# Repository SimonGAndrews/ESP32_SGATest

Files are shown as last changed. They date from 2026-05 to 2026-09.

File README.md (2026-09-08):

# ESP32 Espruino Hardware Test Harnesses

This repository designs, documents, builds, and exercises Espruino and ESP32-family hardware
test harnesses for Espruino port validation.

It is both a hardware-design repo and a test/debug evidence base. The harnesses
are intended to exercise Espruino's user-facing APIs on real Espruino and ESP32-family
targets, especially where those APIs drive the low-level target-port layer and
its `jshardware` implementation.

The test strategy is to break the harness family into reusable physical test
blocks, then use those blocks as controlled hardware contexts for functional
API validation. So the harness wiring is an enabling condition, while the main
goal is to show that the Espruino MCU port behaves correctly when GPIO, timers,
buses, serial ports, and timing-sensitive protocols are used through realistic
hardware feedback paths.

## Purpose

The practical goal is to build repeatable Espruino and ESP32-family Espruino hardware
harnesses, run target-port validation tests against them, and preserve enough
design/debug context that hardware faults, firmware regressions, and test-runner
behaviour are documented.

The design principles are:

- keep the logical test blocks common across all targets
- adapt those blocks to each board through target-specific pin allocation,
  selectors, and wiring fanout
- build shared functional tests around Espruino API behaviour, not just around
  per-target wiring checks
- record the physical mode and firmware/test evidence well enough that future
  runs are comparable

## Project Progression

The work in this repository has progressed through these stages:

1. Developed the first ESP32-C3-DevKitC-02 hardware harness around the common
   Espruino test blocks.
2. Brought up the C3 harness with IDF4-based Espruino builds and validated the
   initial GPIO, analog, bus, and OneWire test paths.
3. Compared C3 IDF4 and IDF5 behaviour and captured IDF5 regression evidence,
   especially around `digitalPulse`.
4. Investigated C3-specific failures using comparison hardware and reference
   targets, separating harness wiring questions from firmware timing issues.
5. Resolved the major ESP32 OneWire instability as a targeted firmware timing
   issue while preserving the evidence and rationale in `docs/investigations/`.
6. Started the classic ESP32 harness generation, using the Olimex
   ESP32-DevKit-LiPo Rev.D / ESP32-WROOM-32E-style pinout as the practical
   DevKitC-compatible target for `ESP32_V1`.
7. Designed the ESP32 DevKitC V4 / `ESP32_V1` harness and PCB construction
   guide, ready for wirewrap build and bring-up.
8. Completed wirewrap builds for both the ESP32-C3 and classic ESP32 harnesses
   and added board photos under `Hardware/`.
9. Completed scripted wiring checks for the current harness blocks, including
   GPIO, analog/PWM, SPI, I2C, OneWire, DS2413, UART crosslink, and external
   connector paths where fitted.
10. Defined the shared REPL functional-test design, with JavaScript-owned
    target presets, Python-owned runner/parsing, and structured machine-readable
    output.
11. Proved the first shared functional block (`gpio_block1`) end to end across
    both current family targets on IDF4 firmware, using the same logical test
    files unchanged.
12. Started the V2 prototype implementation in `KICAD/V2/`, created curated
    target libraries, and adopted removable target daughter boards as the
    target-specific adaptation boundary.

## Current Targets

### ESP32-C3-DevKitC-02

The ESP32-C3 harness is built and has already been used for bring-up, scripted
wiring checks, and firmware debugging.

Important C3-specific features include:

- native USB Serial/JTAG on `D18` / `D19`
- UART0 on `D20` / `D21` reserved by default for board USB-UART REPL/flashing
- selector-heavy GPIO allocation due to the smaller available pin budget
- UART0/UART1 crosslink provisions that use native USB Serial/JTAG as the
  runner path; the DevKitC-02 onboard CP2102N TX must be isolated before its
  `D20` UART0 RX path can be used as the second crosslink direction

KiCad project:

```text
KICAD/V1/ESP32_C3_v1/
```

### Classic ESP32 DevKitC V4 / ESP32_V1

The classic ESP32 DevKitC V4 harness is now built and has completed its first
scripted wiring-check phase. The practical target is the Olimex
ESP32-DevKit-LiPo Rev.D. Olimex describe this board as pin-to-pin comparable
with the Espressif ESP32-CoreBoard
(`ESP32-DevKitC`), while adding LiPo charging and battery-powered operation.
The selected Rev.D hardware uses the classic ESP32 / ESP32-WROOM-32E-class
module family.

The harness uses a KiCad PCB design as a placement/silkscreen construction
guide rather than as a routed copper PCB.

Important ESP32_V1-specific features include:

- UART0 on `D1` / `D3` reserved for board USB-UART REPL/flashing/control
- UART1/UART2 crosslink for serial testing
- mostly fixed wiring because the classic ESP32 has more available GPIO
- selected sharing for `D35`, `D33`, and `D26`
- DS2413 removable OneWire GPIO breakout support

KiCad project:

```text
KICAD/V1/ESP32_V1/
```

## Common Harness Blocks

The harness family reuses the same logical test blocks wherever possible:

- GPIO loopbacks for `digitalWrite`, `digitalRead`, `pinMode`, `setWatch`, and
  `digitalPulse`
- PWM-to-ADC feedback
- SPI validation through MCP3008, with optional shared-bus flash device
- I2C validation through MCP23008, with feedback and interrupt paths
- OneWire validation through two DS18B20 devices
- OneWire GPIO validation through a DS2413 breakout
- UART/Serial crosslink tests
- reset/boot/automation provisions

Tests and documentation use Espruino `Dxx` pin names, matching GPIO numbers.

## Functional REPL Tests

The authoritative shared functional tests live under `tests/repl/`.

These tests are designed to:

- stay directly usable in the Espruino REPL or Web IDE
- keep target-specific pin and mode maps visible inside the JavaScript file
- emit structured output that a Python runner can parse unchanged
- validate Espruino API behaviour within the physical harness block that makes
  that behaviour observable

The current reference design for this test model is:

- `docs/design/repl-test-suite-design.md`

The first proven shared block is `tests/repl/gpio_block1/`, which currently
covers:

- `pinMode`
- `digitalWrite`
- `digitalRead`
- `setWatch`
- `digitalPulse`
- `shiftOut`

## Repository Map

```text
AGENTS.md                  Codex/new-thread operating notes
docs/                      Wiring specs, handoffs, investigation notes
tools/                     Python/REPL test utilities and wiring-test runners
KICAD/                     V1 and V2 schematic/PCB projects and local libraries
Hardware/                  Hardware reference material
tests/repl/                Portable community-facing REPL test scripts
```

Key starting documents:

- `AGENTS.md`
- `docs/handoff/2026-09-04-idf5-classic-validation-status.md` for the
  post-IDF5-merge ESP32 master sanity run and its historical evidence
- `docs/handoff/2026-06-25-esp32-family-tests.md`
- `docs/design/common-harness-design-and-blocks.md`
- `docs/design/repl-test-suite-design.md`
- `docs/design/harness-modes.md`
- `docs/targets/esp32-c3-devkitc-02/wiring.md`
- `docs/targets/esp32-devkitc-v4/wiring.md`

Useful external references:

- Olimex ESP32-DevKit-LiPo open-source hardware page:
  <https://www.olimex.com/Products/IoT/ESP32/ESP32-DevKit-LiPo/open-source-hardware>

## Test And Debug Context

The repo preserves the history and reasoning from real Espruino ESP32 testing,
including:

- REPL bring-up process
- C3 harness block tests
- OneWire investigation and final timing-fix shape
- IDF4 vs IDF5 comparisons
- `digitalPulse` regression evidence
- watch/debounce investigation notes
- scripted REPL test tools

Important conclusions from prior work:

- ESP32 OneWire instability was narrowed to firmware-side timing behaviour, not
  simply bad harness wiring.
- The accepted OneWire fix shape is a localized ESP32 timing guard inside
  `src/jswrap_onewire.c`, not a broad/global interrupt semantic change.
- `digitalPulse` was a separate ESP32-C3 IDF5 regression signal after basic
  `digitalWrite`, `digitalRead`, and `setWatch` paths had been shown to work.
- Selector/jumper state is part of every test precondition and must be recorded
  with test evidence.

## Current Active Work

The current hardware state is that both harness boards are built and their
initial scripted wiring-check coverage is in place.

The shared functional suite now covers GPIO, watches and pulses, analogue and
PWM paths, I2C, SPI, OneWire, UART and paired Wi-Fi/BLE behaviour where the V1
harness and peer hardware support them. It has been used for repeatable classic
ESP32 master-versus-IDF5 comparisons and for targeted ESP32-C3 evidence. The
older IDF4 results remain useful comparators rather than the current endpoint.

The expedited ESP32 IDF5 validation supplied build and V1 regression evidence
that informed Gordon Williams' decision to merge the official `IDF5` branch
into Espruino `master` at `5d79af218`. The same-source post-merge sanity check
of `BOARD=ESP32` and `BOARD=ESP32_IDF5` is complete. Further defects have
returned to normal Espruino-master investigation; the first follow-up was UART
driver-lifecycle pull request `#2742`, merged as `e6a3fe089`. Its family-wide
revision has compile coverage across seven ESP32 board definitions and runtime
coverage on classic ESP32, ESP32-C3 and ESP32-S3 hardware. See
`docs/handoff/2026-09-04-idf5-classic-validation-status.md`.

This work continues block-by-block expansion of the shared functional suite,
with the aim of:

- exercising Espruino APIs more fully across the common harness blocks
- preserving the existing per-target wiring checks as hardware-regression
  references
- retaining useful legacy and IDF4 comparators for anomaly attribution
- applying the same shared functional coverage to both ESP32 board targets in
  current master
- keeping new tests portable to the future V2 target-map layer

V2 architecture and KiCad implementation remain active and can continue in
parallel with normal master regression work. The current V2 return point is
commit `c70e50c`, which established the Rev-A daughter-board foundations. See
`docs/design/V2Harness/README.md` for the V2 entry point.

Routine V1 hardware development and prototyping have stopped. The completed V1
harnesses remain the stable bench platforms for runner development, regression
testing and firmware evidence.

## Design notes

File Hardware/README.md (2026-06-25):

# Hardware Reference Outputs

This directory holds published hardware reference outputs that are useful
outside KiCad itself, such as exported schematic PDFs.

Live KiCad project files remain under `KICAD/`.

## ESP32-C3 Harness

```text
ESP32_C3/schematic-v1-0.pdf
ESP32_C3/schematic-v1-1.pdf
```

`schematic-v1-1.pdf` is the current ESP32-C3 harness schematic reference.

## ESP32_V1 / Classic ESP32 Harness

```text
ESP32_V1/schematic-v1-0.pdf
```

This is the current ESP32 DevKitC V4 / Olimex ESP32-DevKit-LiPo Rev.D harness
schematic reference.

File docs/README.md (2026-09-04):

# Documentation Map

Documentation is grouped by information type.

## `design/`

Generic ESP32-family harness design and operating principles:

- common hardware blocks
- harness modes
- connectivity permutations
- reference links

Historical design-decision notes that are no longer active guidance live under
`design/history/`.

## `targets/`

Target-specific wiring and bring-up notes. These documents describe how the
generic harness blocks are mapped onto a particular board.

Start with `targets/README.md` for the target index.

Current targets:

- `esp32-c3-devkitc-02/`
- `esp32-devkitc-v4/`
- `olimex-esp32-devkit-lipo/`

## `investigations/`

Issue analysis, debugging history, and resolution notes. These are evidence and
reasoning records, not primary wiring specs.

Current investigation areas:

- `IDF5_port_testing/`
- `ble/`
- `onewire/`
- `digitalpulse/`
- `i2c/`
- `wifi/`
- `uart/`
- `watch-debounce/`
- `jsinteractive/`

Investigation-specific raw evidence should live under the relevant
investigation, for example:

```text
investigations/onewire/artifacts/logic-traces/
```

## `handoff/`

Codex/thread continuity notes. These are intended to preserve working context
between sessions and should point to the current design and target docs.

Start with `handoff/README.md`. It distinguishes current workstream handovers
from historical continuity records.

## Current Workstream Entry Points

| Workstream | Entry point |
|---|---|
| ESP32 post-IDF5-merge sanity | `handoff/2026-09-04-idf5-classic-validation-status.md` |
| General V1 bench tests and functional runners | `handoff/2026-06-25-esp32-family-tests.md` |
| Firmware investigations | `handoff/2026-07-05-espruino-repo-structure.md`, `handoff/2026-07-20-esp32-firmware-lineage-and-test-interpretation.md` and the relevant `investigations/` area |
| V2 architecture and Target Interface | `design/V2Harness/README.md` and `handoff/2026-07-17-v2-services-and-routing.md` |
| V2 KiCad implementation | `design/V2Harness/README.md` and `../KICAD/V2/Exploration/Espruino_Harness_V2/TARGET_LIBRARY_PROVENANCE.md` |

Repository-relative paths are canonical because the repository is used on both
Windows and Ubuntu.

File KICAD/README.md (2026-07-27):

# KiCad Projects

All KiCad projects and component-development work live under this directory.
Libraries remain local to the project that uses them and use `${KIPRJMOD}` in
KiCad library tables.

## Directory map

```text
KICAD/
|-- V1/
|   |-- ESP32_C3_v1/       Completed ESP32-C3 V1 harness
|   `-- ESP32_V1/          Completed classic ESP32 V1 harness
`-- V2/
    |-- Exploration/
    |   `-- Espruino_Harness_V2/
    |-- ComponentDevelopment/
    |   `-- EspruinoPicoDirectMount/
    |-- RevA/
    `-- upstream/
```

`V2/Exploration/Espruino_Harness_V2/` preserves the earlier exploratory
schematic hierarchy, PCB placement work and curated target libraries. It is a
reference input to Rev A, not the Rev-A starting project.

`V2/ComponentDevelopment/EspruinoPicoDirectMount/` contains the useful
Espruino Pico direct-solder footprint and board-aperture development work. A
reviewed copy of the required footprint will be placed in the future Pico
daughter-board project's local library.

`V2/RevA/Espruino_Harness_RevA/` is the intended location for the fresh Rev-A
project. Create that project through KiCad rather than by copying the
exploratory schematic or PCB.

`V2/upstream/` contains local upstream source checkouts used for provenance and
comparison. It is ignored by Git and is not a production library.

KiCad local-state files, automatic backups, caches and lock files are ignored
by the repository-level `.gitignore`.

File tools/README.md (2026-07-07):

# Tooling Map

This directory contains automation and diagnostic utilities used to run
Espruino REPL tests, capture evidence, and support investigations.

The long-term direction is to keep reusable test logic separate from
target-specific pin/mode configuration.

## `common/`

Reusable tools that are not tied to one harness target.

Current examples:

- OneWire search/debug diagnostics
- generic OneWire soak testing
- DS18B20 read soak testing
- `archive_firmware.py` for extracting flashable build bundles into
  `firmware/` for repeatable reflashing

## `repl/`

Shared functional REPL runners for tests under `tests/repl/`.

Current direction:

- Python owns metadata capture, parsing, and overall result handling
- transport may be direct serial or an optional EspruinoTools CLI backend
- shared tests remain authoritative in JavaScript under `tests/repl/`

## `wiring_tests/`

Target-specific wiring-test runners. These encode a particular harness pin
allocation, selector state, or bring-up sequence.

Current targets:

- `esp32_c3/` - scripts originally developed for the ESP32-C3-DevKitC-02
  harness
- `esp32_v1/` - first-pass scripts for the classic ESP32 DevKitC V4 harness

Future ESP32-family work should prefer a shared runner plus target maps, rather
than copying whole scripts for each board.

## `experiments/`

One-off or comparison tools used during investigations. These are useful
evidence generators, but they are not necessarily part of the accepted harness
test suite.

Current experiment areas:

- `pico/` - Pico comparison scripts used during watch/debounce and pulse
  investigation work

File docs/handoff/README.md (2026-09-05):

# Handover Index

Handover documents preserve continuity between focused Codex threads. They do
not replace current design specifications, target wiring documents or recorded
test evidence.

## Thread Declaration

Begin substantial work by declaring the thread's workstream and immediate
objective:

```text
Workstream: <one of the four workstreams in AGENTS.md>
Current objective: <concrete outcome for this thread>
```

Examples:

```text
Workstream: V1 bench testing and functional runners
Current objective: add shared SPI functional coverage on both V1 targets

Workstream: Firmware investigations
Current objective: reproduce the ESP32-C3 IDF5 digitalPulse regression

Workstream: V2 architecture and Target Interface contract
Current objective: define the logical resource inventory and safety invariants

Workstream: V2 KiCad implementation
Current objective: implement an accepted Target Interface bank assignment
```

Keep one primary workstream per thread where practical. When work crosses a
boundary, state what is being consumed from or handed to the parallel
workstream. Record accepted cross-workstream decisions in repository
specifications rather than relying on conversation history.

## Current Workstream Handovers

| Workstream | Current handover | Use |
|---|---|---|
| ESP32 post-IDF5-merge sanity | `2026-09-04-idf5-classic-validation-status.md` | Completed same-source legacy/IDF5 sanity comparison and return point for outstanding defects as normal master investigations |
| General V1 bench testing and functional runners | `2026-06-25-esp32-family-tests.md` | Generic family-test model and preserved target constraints; its July 12 overlay points to the root README and `tests/repl/` for newer progress |
| Firmware repository selection | `2026-07-05-espruino-repo-structure.md` | Select the correct local Espruino checkout and workflow |
| ESP32 firmware lineage and evidence interpretation | `2026-07-20-esp32-firmware-lineage-and-test-interpretation.md` | Cross-build confidence, comparison matrix and anomaly-attribution rules for bench and firmware threads |
| V2 architecture and Rev-A implementation | `2026-07-17-v2-services-and-routing.md` | Accepted architecture and Target Interface, first-pass Rev-A hierarchy, verified power baseline and next RC01/RC02 reviews |

V2 KiCad implementation currently uses the V2 entry point and Rev-A design
baseline under `../design/V2Harness/`, together with the relevant architecture
specification for the circuit under review. It does not need a separate
handover while current progress, evidence and open PCB actions are captured in
those documents and Git history. Read
`../../KICAD/V2/Exploration/Espruino_Harness_V2/TARGET_LIBRARY_PROVENANCE.md`
only when modifying target symbols or footprints.

## Focused Historical Handovers

- `2026-06-16-onewire-idf4-idf5.md` is required for OneWire and closely
  related ESP32 timing investigations, not for every thread.
- `2026-06-10.md` is an earlier broad continuity record.
- `2026-07-01-espruino-repo-structure.md` is the detailed predecessor to the
  simplified July 5 repository guide.
- `2026-07-01-esp32-harness-progress-discussion-draft.md` is a discussion
  draft, not current authority.
- `2026-07-12-v2-target-interface-contract.md` records the starting context for
  the V2 architecture thread and is superseded by the July 17 V2 handover.

## Authority and Maintenance

When documents differ:

1. Current specifications and target wiring documents are authoritative.
2. Accepted architecture and interface contracts govern V2.
3. Current handovers describe workstream continuity and open work.
4. Older handovers and investigations preserve historical evidence.

Create a new handover when a focused thread cannot be restarted reliably from
the current specifications and existing workstream handover. A good handover
states scope, settled decisions, open questions, authoritative inputs,
parallel-workstream boundaries and the recommended next task.

Use repository-relative links and paths. This repository is used on both
Windows and Ubuntu.

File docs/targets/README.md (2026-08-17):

# Target Documentation

Target documentation describes how the common ESP32-family harness blocks are
mapped onto specific boards.

The generic design rules live in `../design/`; target directories should focus
on pin allocation, selector state, bring-up notes, and target-specific
constraints.

## Current Targets

The C3 and classic ESP32 directories describe completed V1 harness targets and
their wiring. The Olimex directory is retained as earlier target-specific
reference history.

### `esp32-c3-devkitc-02/`

ESP32-C3-DevKitC-02 harness documentation.

Status:

- first built harness
- used for IDF4/IDF5 bring-up and regression investigation
- selector-heavy design because of the C3 pin budget

Key files:

- `wiring.md`
- `bringup.md`
- `../../Hardware/ESP32_C3/schematic-v1-1.pdf`

### `esp32-devkitc-v4/`

Classic ESP32 DevKitC V4 / `ESP32_V1` harness documentation.

Status:

- completed wirewrap harness; now used as a stable bench platform
- practical target board is the Olimex ESP32-DevKit-LiPo Rev.D, described by
  Olimex as pin-to-pin comparable with Espressif ESP32-CoreBoard /
  `ESP32-DevKitC`
- KiCad project lives in `../../KICAD/V1/ESP32_V1/`

Key files:

- `wiring.md`
- `../../Hardware/ESP32_V1/schematic-v1-0.pdf`

### `olimex-esp32-devkit-lipo/`

Earlier target-specific notes for the Olimex ESP32-DevKit-LiPo Rev.D.

Status:

- retained as target reference/design history
- current classic ESP32 harness work is consolidated under
  `esp32-devkitc-v4/`

Key files:

- `wiring.md`

### `olimex-esp32-s3-devkit-lipo/`

Olimex ESP32-S3-DevKit-LiPo target documentation.

Status:

- owned V2 target is the `-EA` external-antenna ordering variant, hardware
  revision B and N8R8 configuration
- allocated to `DB-ESP32-FAMILY`
- authoritative target CAD exists; the GPIO-to-Target-Interface mapping is
  accepted in `../design/V2Harness/arch/TargetRoutingEnvelope_V2.md`
- retained manufacturer files currently remain in the older mixed Olimex
  resource directory pending the planned target-asset rationalisation

Key file:

- `README.md`

## V2 Target-Library Reference Sets

- `ESP32-S3-DevKitC-1_V1.1/`
- `Raspberry-Pi-Pico-Family/`
- `espruino_pico/`
- `MDBT42Q_breakout/`
- `olimex-esp32-s3-devkit-lipo/`

These directories provide manufacturer drawings, pinouts and, where present,
target-library notes used to validate the curated symbols and footprints in
`../../KICAD/V2/Exploration/Espruino_Harness_V2/V2_Targets.*`.

Target-specific daughter-board mappings will be added after the V2 Target
Interface contract is stable. Curated KiCad assets and upstream revisions are
described in
`../../KICAD/V2/Exploration/Espruino_Harness_V2/TARGET_LIBRARY_PROVENANCE.md`.

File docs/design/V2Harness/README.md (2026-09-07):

# Espruino Test Harness V2

**Status:** Active architecture and prototype implementation

## Purpose

V2 develops a reusable hardware architecture for Espruino target validation.
It builds on the completed ESP32-family V1 harnesses while separating reusable
test circuitry from target-specific physical adaptation.

V1 remains the stable bench platform for shared functional-test and runner
development. V2 architecture and KiCad implementation proceed in parallel and
consume lessons proved on V1.

## Current Direction

The agreed prototype direction is:

- a reusable manufactured harness PCB containing standard test blocks,
  routing, control and fixed Target Interface pin banks
- removable target daughter boards containing the target socket and
  target-specific mapping to that interface
- a common daughter-board USB data path and manual VBUS selector, plus a reusable-harness
  Standalone regulator, so full harness capability never depends on target
  3.3 V output capacity
- two coordinated two-position power selectors, changed only while unpowered;
  no host-VBUS or selector-control conductor crosses the Target Interface
- wirewrapped prototype daughter boards first, with manufactured passive
  adapter PCBs possible after mappings are stable

```text
Target module
     │ target-specific socket and wirewrap
     ▼
Target daughter board
     │ fixed Target Interface contract
     ▼
Reusable V2 harness PCB
     ├── Standard Test Blocks
     ├── Standard Control Services
     └── direct and routed connections
```

The conceptual model, Standard Test Blocks, Target Routing Envelope and
Standard Control Services are accepted. The accepted combined capability
connection matrix turns those requirements into a concrete path inventory,
simultaneous-use model and provisional Target Interface contact count. The
controlled-routing specification is also accepted against that matrix. The
accepted Target Interface uses two 24-pin connectors, each with two rows of
12 pins. Its complete 48-pin Connector A and Connector B pinout is fixed,
including the corrected B01 `TI_TARGET_VBUS` return and low-current-only A01
`TI_TARGET_3V3` reference.
Exact connector parts, plating and KiCad footprints still need to be selected
and mechanically checked before the Rev-A harness is released. The current
KiCad project is a prototype implementation and must not be mistaken for a
frozen production design.

The ESP32-C3-DevKitC-02 now has a specific Block 7 qualification. V1 bench
evidence proves that the daughter-board-style D18/D19 native USB connection
can provide an independent `/dev/ttyACM` runner, but it also proves that this
does not release D20 from the onboard CP2102N TX output. The unmodified target
therefore uses Block 7's endpoint-A external-peer form; the full two-UART
crosslink is enabled only for an explicitly isolated or separately proved
target mapping. Rev-A action `PCB-DB-C3-01` carries this into the
`DB-ESP32-FAMILY` implementation.

## Active V2 Workstreams

### Architecture and Target Interface

Defines:

- logical resource inventory
- direct, routed, optional and reserved signals
- connector-bank semantics and electrical safety
- daughter-board responsibilities
- cross-target compatibility rules
- Standard Test Blocks and Control Services
- combined direct, routed, simultaneous-use and recovery requirements

Start with:

- `arch/TestHarnessArchitecture_V2.md`
- `arch/HarnessConceptualModel_V2.md`
- `arch/HybridHarnessArchitecture_V2.md`
- `arch/DaughterBoardMatrix_V2.md`
- `arch/StandardTestBlocks_V2.md`
- `arch/StandardControlServices_V2.md`
- `arch/TargetRoutingEnvelope_V2.md`
- `arch/CombinedCapabilityConnectionMatrix_V2.md`
- `arch/TargetInterfaceContract_V2.md`
- `arch/ReusableHarnessPrototypeStrategy_V2.md`
- `../../handoff/2026-07-17-v2-services-and-routing.md`

### KiCad implementation

The accepted architecture will be implemented in a fresh Rev-A project under:

- `../../../KICAD/V2/RevA/Espruino_Harness_RevA/`

The earlier exploratory project is preserved under
`../../../KICAD/V2/Exploration/Espruino_Harness_V2/`. It contains:

- an exploratory hierarchical schematic
- project-local `V2_Harness` component libraries
- project-local `V2_Targets` symbol and footprint libraries
- reviewed target assets for the main ESP32, ESP32-S3, Pico and Espruino
  target set

Read `../../../KICAD/V2/Exploration/Espruino_Harness_V2/TARGET_LIBRARY_PROVENANCE.md`
before modifying target assets. Several footprints contain authoritative
interactive edits.

### Rev-A implementation baseline

The draft manufacturing baseline, circuit-block review records and visual
review images live under:

- `implementation/ReusableHarnessRevA_DesignBaseline.md`
- `implementation/ReusableHarnessRevA_ConnectivityChecker.md`
- `implementation/ReusableHarnessRevA_PCBImplementationAndVerification.md`
- `implementation/review-images/`

The design baseline requires the deterministic connectivity check and decides
whether its evidence is accepted for Rev-A release. The connectivity-checker
specification defines the tool that performs that check.

`PC01` Operating mode and 3.3 V rails, `PC02` Target 5 V switch and two-range
monitor, `RC01` Routing Fabric, `RC02` routing controllers and fixed I2C
isolation, and `TB01` digital GPIO loopback are verified at schematic-baseline
level. Their PCB, physical-test and AISLER actions remain in the implementation
register. The next planned baseline-review area is `TB02` analogue/PWM
feedback on `standard_test_blocks.kicad_sch`.

PCB-layout work starts with the **PCB implementation action register** in
Section 6 of the design baseline. It is the single handover list for physical
layout, mechanical, DFM and release actions accumulated by the block reviews.

Generated KiCad evidence and the machine-readable connectivity contract live
under `../../../KICAD/V2/RevA/Espruino_Harness_RevA/verification/`.

## Document Roles

- `arch/TestHarnessArchitecture_V2.md` defines the overall architecture and
  should change only for genuine architectural decisions.
- `arch/HarnessConceptualModel_V2.md` owns the shared capability vocabulary and
  relationships.
- `arch/StandardTestBlocks_V2.md` owns reusable Test Block behaviour and
  electrical requirements.
- `arch/TargetRoutingEnvelope_V2.md` owns the accepted seven-entry Test Block
  routing minimum, legal common route functions, direct-path alternatives and
  cross-target routing constraints.
- `arch/StandardControlServices_V2.md` owns reusable power, target-control,
  routing, reset and boot, Supervisor, event-handshake and rack-service
  behaviour.
- `arch/WiFi_V1SupervisorPeerEvidence.md` assesses the completed V1 Wi-Fi
  Supervisor Peer evidence and open gaps; it is an evidence input, not a
  second Control Service specification.
- `arch/CombinedCapabilityConnectionMatrix_V2.md` is the accepted integration
  of Test Block and Control Service requirements for routing and Target
  Interface design without duplicating their behavioural specifications.
- `arch/I2CControlledRouting_V2.md` is the accepted controlled-routing
  specification.
- `arch/TargetInterfaceContract_V2.md` owns the physical Target Interface
  electrical and connector contract. Its complete two-connector 48-pin pinout
  is accepted; exact connector parts, plating, footprints and mechanical
  verification remain in progress.
- `arch/HybridHarnessArchitecture_V2.md` defines the prototype boundary and
  records the removable daughter-board decision in Appendix A.
- `arch/DaughterBoardMatrix_V2.md` owns the three-board target allocation,
  exact-variant matrix, mounting and shared-footprint compatibility decisions,
  and the complex-board-first implementation gates.
- `arch/ReusableHarnessPrototypeStrategy_V2.md` defines the Rev-A manufactured
  harness, wire-wrap daughter-board and pre-manufacture validation approach.
- `implementation/ReusableHarnessRevA_DesignBaseline.md` records the selected
  Rev-A implementation and the evidence required before manufacturing release.
- `implementation/ReusableHarnessRevA_ConnectivityChecker.md` specifies the
  deterministic checker used by that baseline to verify the complete root
  KiCad netlist against the independently reviewed connectivity contracts.
- `implementation/ReusableHarnessRevA_PCBImplementationAndVerification.md`
  will guide and record board placement, routing and PCB verification without
  duplicating the authoritative KiCad PCB database or the baseline action
  register.
- `targets/esp32-c3-devkitc-02/gpio-allocation-and-routing-design.md` is a
  provisional target study, not an implemented wiring specification.
- `../../handoff/2026-07-17-v2-services-and-routing.md` transfers the accepted
  architecture and Control Services into the routing-design thread.

## Relationship to V1

Routine V1 hardware construction and prototyping have stopped. The completed
ESP32-C3 and classic ESP32 harnesses are used for:

- shared REPL functional-test development
- runner and result-format development
- regression testing and firmware comparison
- bench evidence for assumptions that may inform V2

V2 does not replace this active bench role. It generalises the proven ideas
into a reusable future harness.

## Guiding Principles

- Evolution rather than replacement.
- Simplicity before unnecessary automation.
- Stable logical interfaces and explicit physical boundaries.
- Separation of reusable harness functions from target-specific adaptation.
- Hardware proof before firmware conclusions.
- Prototype and measure before committing to manufactured adapters.
- Preserve replaceability, inspectability and independent fault diagnosis.

## Repository Layout

```text
docs/design/V2Harness/
├── README.md
├── arch/             Current architecture specifications
└── targets/          Provisional target allocation studies

KICAD/
├── V1/               Completed V1 harness projects
└── V2/
    ├── Exploration/  Preserved exploratory V2 work
    ├── ComponentDevelopment/
    │   └── EspruinoPicoDirectMount/
    ├── RevA/         Fresh Rev-A implementation
    └── upstream/     Ignored upstream reference checkouts
```

Repository-relative paths are canonical on both Windows and Ubuntu.

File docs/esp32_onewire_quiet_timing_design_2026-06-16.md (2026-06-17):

# ESP32 OneWire Quiet Timing Design Note

Date: 2026-06-16

This note records the design reasoning behind the ESP32-family OneWire timing
fix used during the ESP32-C3 harness investigation.

The immediate practical problem was:

- `OneWire.search()` on ESP32-C3 was intermittent
- the same DS18B20 daughterboard and sensors were stable on an Espruino Pico
- the failure pattern suggested timing corruption during the ROM-search
  transaction

The selected fix was to add a short-duration ESP32-specific critical section
for OneWire timing windows, rather than globally changing Espruino interrupt
semantics on ESP32.

Update 2026-06-17:

- the first working proof used ESP32 target helpers
  `jshQuietTimingEnter()` / `jshQuietTimingExit()`
- after review, that was refactored into a smaller final form that keeps the
  ESP32 override local to `src/jswrap_onewire.c`
- the final implementation uses a local `portMUX_TYPE` and
  `portENTER_CRITICAL()` / `portEXIT_CRITICAL()`
- that refactored form now builds in both the IDF4 and IDF5 Espruino trees
- on the bench ESP32-C3, the IDF4 build passed:
  - `OneWire.searchDebug()` soak `20/20`
  - `OneWire.searchDebug()` soak `50/50`
  - DS18B20 conversion/read soak `20/20`
- on the bench ESP32-C3, the IDF5 build passed:
  - `OneWire.searchDebug()` soak `20/20`
  - `OneWire.searchDebug()` soak `50/50`
  - DS18B20 conversion/read soak `20/20`
- the original harness-mounted OneWire path was then restored and also passed
  on IDF5 using `SEL_D0 -> ONEWIRE_DQ`
- the latest rerun on that original harness path again found both harness ROMs
  on every pass:
  - `2808c68700aa7672`
  - `28b3e08700b65ea9`

## Problem Summary

On the ESP32 target, existing `OneWire` code relied on:

- `jshInterruptOff()`
- `jshInterruptOn()`

to protect timing-sensitive windows such as:

- reset / presence detect
- read slots
- write slots

However, on ESP32 those functions were effectively stubbed, so the code still
looked like it was protecting timing but in practice was not.

That mismatch matters because OneWire bit-banging is sensitive to short timing
disturbances and to delayed sampling.

## Why Not Re-enable Global Interrupt Off/On?

We explicitly did not choose to "just implement" `jshInterruptOff()` /
`jshInterruptOn()` globally for ESP32.

Reasons:

1. Historical evidence in Espruino indicated that raw interrupt off/on on
   ESP32 had previously caused crashes.
2. `jshInterruptOff()` / `jshInterruptOn()` have multiple call sites outside
   OneWire, so changing them globally would widen the risk far beyond this
   specific timing problem.
3. On ESP32-family targets, especially SMP-capable ones such as ESP32 and
   ESP32-S3, a naïve single-core mental model of interrupt disabling is not a
   good match for the platform's concurrency model.

So the design target was:

- preserve existing stubbed global behavior
- introduce a new narrowly-scoped primitive for short timing-critical sections
- use it only where OneWire genuinely needs it

## Chosen Approach

The final implemented approach is:

1. In `src/jswrap_onewire.c`, under `#ifdef ESP32`, define a local
   `portMUX_TYPE` spinlock.
2. In that same file, locally override:
   - `jshInterruptOff()` to `portENTER_CRITICAL(&JSQuietTimingMux)`
   - `jshInterruptOn()` to `portEXIT_CRITICAL(&JSQuietTimingMux)`
3. Apply those timing guards around:
   - `OneWireReset()`
   - OneWire read slots
   - OneWire write slots
4. Leave all non-ESP32 targets unchanged.
5. Keep the ESP32-specific behavior local to the OneWire implementation rather
   than introducing new cross-target `jshardware` API surface.

This keeps the blast radius small while aligning with the upstream preference
to avoid adding new target hooks unless they are broadly justified.

## Why This Matches ESP-IDF Guidance

ESP-IDF's own FreeRTOS documentation describes ESP critical sections in terms
of:

- a `portMUX_TYPE` spinlock
- `taskENTER_CRITICAL(&spinlock)`
- `taskEXIT_CRITICAL(&spinlock)`

Reference:

- https://docs.espressif.com/projects/esp-idf/en/stable/esp32/api-reference/system/freertos_idf.html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

Important points from the ESP-IDF guidance:

- the core disables interrupts or interrupt nesting up to the syscall priority
- the core then acquires the spinlock atomically
- the protected region then runs under that critical section

That model is a better fit for ESP32-family targets than pretending a generic
global interrupt-off primitive is sufficient everywhere.

In plain terms:

- ESP-IDF expects short protected regions to be expressed as critical sections
  using a mux/spinlock
- the final local `jswrap_onewire.c` override follows that pattern directly

The first proof version used `taskENTER_CRITICAL()` / `taskEXIT_CRITICAL()`.
The final refactor uses `portENTER_CRITICAL()` / `portEXIT_CRITICAL()` instead,
because that compiled cleanly across both the IDF4 and IDF5 trees used here.

## Why This Matches MicroPython's ESP32 Approach

MicroPython's ESP32 port uses its own target-specific atomic section mechanism
instead of relying on a generic platform-agnostic global interrupt-disable
assumption.

Relevant references:

- https://github.com/micropython/micropython/blob/master/ports/esp32/mphalport.h
- https://github.com/micropython/micropython/blob/master/ports/esp32/mphalport.c

Key observations from the MicroPython ESP32 port:

- it defines a `portMUX_TYPE` atomic mux
- `mp_begin_atomic_section()` uses `portENTER_CRITICAL(&mp_atomic_mux)`
- `mp_end_atomic_section()` uses `portEXIT_CRITICAL(&mp_atomic_mux)`
- the comments note this protects against concurrent access on SMP systems as
  well as disabling interrupts on the calling CPU
- MicroPython also maps its quiet-timing/atomic helpers onto that mechanism

This is not identical code to Espruino, but it is architecturally the same
kind of solution:

- an ESP32-specific short critical section
- not a blind restoration of raw global interrupt-off behavior

## Why Only OneWire Was Changed

This design note is intentionally narrow.

It does not claim:

- every ESP32 timing-sensitive subsystem in Espruino should immediately use the
  same primitive
- every call site of `jshInterruptOff()` must be rewritten now

It only claims:

- OneWire needed protection for specific very short timing windows
- a narrow ESP32-specific critical-section override is a defensible and
  low-risk way to provide it on ESP32

That narrower scope made it easier to:

- prove the fix with bench evidence
- avoid broad regressions
- preserve future freedom to redesign wider ESP32 interrupt/timing policy if
  needed

## Residual Risk And Expected Side Effects

The fix is intentionally narrow, but it is not free.

What changes on ESP32 is not the whole system interrupt model. What changes is
that `OneWire` now introduces short critical sections during its timing
windows in `src/jswrap_onewire.c`.

Important boundaries:

- the override is file-local to `src/jswrap_onewire.c`
- it does not change other `jshInterruptOff()` / `jshInterruptOn()` call sites
- it does not globally alter ESP32 interrupt handling when `OneWire` is idle

The real residual risk is therefore not "everything on ESP32 now runs with
interrupts changed". The real residual risk is:

- interrupt latency increases in short bursts while `OneWire` activity is in
  progress
- repeated `OneWire.search()` or DS18B20 conversions/reads can create many
  such bursts in succession
- other interrupt-driven subsystems may therefore see added jitter or delayed
  service during active `OneWire` traffic

The most likely areas to watch are:

- Wi-Fi background work during repeated `OneWire` transactions
- Bluetooth/BLE controller or host timing during repeated `OneWire`
  transactions
- UART RX at higher baud rates while `OneWire` traffic is active
- software timing features such as `setWatch`, timers, or pulse generation
- any application that relies on tight interrupt response while `OneWire` is
  running

The key engineering judgement is that this residual risk is much smaller than
the risk of globally re-enabling `jshInterruptOff()` / `jshInterruptOn()` on
ESP32.

## Coexistence Tests Still Required

Acceptance of the fix should include coexistence testing, not just isolated
OneWire success.

The future ESP32-family test plan should include cases where `OneWire` runs in
parallel with other interrupt-driven features so that the critical-section
tradeoff is exercised directly.

Recommended minimum coexistence cases:

1. OneWire plus Wi-Fi activity
   - keep Wi-Fi associated
   - generate steady network traffic while repeated `OneWire.search()` and
     DS18B20 reads are running
   - watch for disconnects, stalls, missed reads, or console instability
2. OneWire plus Bluetooth/BLE activity
   - keep BLE advertising, scanning, or a simple active connection running
   - in parallel, run repeated `OneWire.search()` and DS18B20 reads
   - watch for dropped BLE activity, timing instability, or OneWire failures
3. OneWire plus UART RX stress
   - stream data into the board over the active UART path while repeated
     `OneWire` reads/searches run
   - check for framing loss, dropped characters, or REPL corruption
4. OneWire plus GPIO/watch/timer activity
   - keep a watch-based edge counter or timer-based activity running while
     repeated `OneWire` operations execute
   - watch for lost edges, stretched timing, or unexpected callback latency
5. OneWire plus other bus activity
   - run SPI or I2C polling in parallel with repeated `OneWire` operations
   - watch for transaction failures or clear timing degradation

These should be treated as suite-level coexistence/regression tests for:

- ESP32-C3
- original ESP32
- later, ESP32-S3 if it becomes an active target

For the original ESP32 specifically, this matters even more because Wi-Fi and
Bluetooth are both in scope on that family target.

## Evidence That The Design Worked

Using the clean external daughterboard with:

- two DS18B20 sensors
- one `4.7k` pull-up

the observed progression on the ESP32-C3 was:

1. Before the fix:
   - mixed two-device, one-device, and zero-device search results
   - variable abort bit positions in `searchDebug()`
2. After protecting read/write slots:
   - a dramatic improvement
   - one remaining rare `resetOk=false` failure in a 50-run soak
3. After also protecting the reset/presence window:
   - `50/50` successful runs
   - both sensors found every time

So the design is supported by bench evidence, not just by architectural taste.

That evidence now exists in both of the firmware trees used in this project,
not only in the original IDF4 proof tree.

It also now exists on both physical OneWire setups used during the
investigation:

- the clean external daughterboard used to isolate firmware behavior
- the original harness-mounted OneWire path used in the earlier unreliable
  tests

## Intended Portability Across ESP32 Family

The design is intended to scale across ESP32-family targets, including:

- original ESP32
- ESP32-C3
- ESP32-S3

Why this should port cleanly:

- the implementation is small and ESP32-guarded
- the primitive is based on ESP-IDF / FreeRTOS critical sections rather than
  C3-specific register tricks
- the same final shape now builds and passes bench soaks in both the IDF4 and
  IDF5 Espruino trees used here

That does not prove every ESP32-family target will behave identically, but it
does mean the chosen mechanism is family-appropriate rather than board-specific.

## Files Associated With This Design

The final refactored design is embodied in:

- `src/jswrap_onewire.c`
- `src/jswrap_onewire.h`

plus the local board console adjustments needed on the bench target:

- `boards/ESP32C3_IDF4.py`
- `boards/ESP32C3_IDF5.py`

The initial proof version also touched `src/jshardware.h` and
`targets/esp32/jshardware.c`, but those changes were later removed during the
refactor to the final local OneWire override.

## Practical Guidance For Future Review

If this change is later reviewed or upstreamed, the strongest technical framing
is:

- this is not a generic "re-enable interrupts off/on on ESP32" patch
- this is a targeted ESP32 critical-section override for a timing-critical
  bit-banged protocol
- the implementation follows ESP-IDF's critical-section model
- the approach is consistent with the kind of ESP32 atomic-section handling
  used by MicroPython
- the fix is justified by measured before/after bench evidence

## Related Notes

- [codex_handoff_2026-06-16_onewire_idf4_idf5.md](./codex_handoff_2026-06-16_onewire_idf4_idf5.md)
- [onewire_cross_target_comparison_2026-06-15.md](./onewire_cross_target_comparison_2026-06-15.md)
- [onewire_logic_trace_comparison_2026-06-15.md](./onewire_logic_trace_comparison_2026-06-15.md)

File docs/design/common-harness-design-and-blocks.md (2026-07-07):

# Common Harness Design And Blocks

This document defines the common reusable wiring blocks and design rules for the
ESP32 hardware test harness family.

Board-specific documents map target `Dxx` pins onto these named harness nodes.
The physical harness boards should keep these blocks in the same relative
layout where practical, even when the DUT socket and fanout differ.

These are logical harness nodes. A board-specific schematic may use more
specific net names, for example `I2C_A_SDA` for the primary `I2C_SDA` block, or
selector-side nets for loopback nodes.

Target harnesses may also include additional devices or target-specific wiring
extensions beyond these baseline common blocks. Those additional items should be
documented in the relevant target wiring notes, not here.

## Design Intent

The harness family should prove the same Espruino hardware interfaces wherever
practical, even when different target boards need different GPIO choices and
different fanout wiring.

In other words:

- keep the logical test blocks consistent across targets
- keep the test tasks consistent across targets
- let each target harness translate its own GPIOs onto the common harness nodes
- avoid redesigning the tests every time the DUT changes

The board-specific work is choosing safe GPIOs and documenting the selector or
link state for that target. The family-level work is keeping the logical block
names, block purpose, and overall harness structure consistent.

## Blocks, Modes, And Tests

This repo uses three related but distinct concepts:

- a `block` is a logical hardware capability grouping such as GPIO, analog,
  I2C, SPI, OneWire, or UART
- a `mode` is a harness configuration or operator precondition that enables one
  or more blocks on a specific target
- a `test` is a functional validation task that may exercise one block or
  multiple blocks, depending on what behaviour it is trying to prove

These concepts should not be treated as interchangeable.

A mode does not need to map one-to-one onto a block. For example, a
target-specific combined bus mode may deliberately enable both an I2C block and
a SPI block at the same time.

A test also does not need to map one-to-one onto a block. Many tests should
prefer the smallest useful block set for clear fault isolation, but some valid
tests will deliberately exercise multiple blocks together, especially when
checking coexistence, shared-node behaviour, or multi-peripheral bus activity.

## Pin Naming

Tests should use Espruino `Dxx` names matching raw GPIO numbers.

Examples:

- `GPIO21` is addressed as `D21`
- `GPIO0` is addressed as `D0`

Board aliases such as `LED1` may exist, but harness wiring and target mapping
should be specified in raw GPIO / `Dxx` terms.

## Pin Selection Rules

Prefer pins that are:

- exposed on the development board headers
- normal bidirectional GPIO
- available at boot without changing strapping state
- not connected to module SPI flash or PSRAM
- not required by the normal REPL/flashing path
- ADC-capable where an ADC test input is needed
- usable with Espruino's target pin naming and peripheral mapping

Avoid or treat as conditional:

- flash/PSRAM pins
- boot strapping pins that may change startup mode
- UART0 pins when UART0 is the REPL/flashing console
- native USB pins when native USB is the REPL/flashing path
- input-only pins for output, loopback-drive, SPI, I2C, or PWM roles
- board-specific pins tied to LEDs, buttons, battery sensing, or power sensing
  unless the test explicitly covers that board feature

## Electrical Baseline

| Item | Requirement |
|---|---|
| Logic voltage | 3.3 V |
| Ground | common ground across DUT, harness ICs, USB/serial peers, and test devices |
| IC mounting | socketed ICs for MCP3008 and MCP23008 |
| Construction | wirewrap on fixed-grid plated-through proto board |
| Labels | label harness nodes by function, not only by target GPIO |

Use one common 3.3 V rail for the target-facing peripherals unless a later
test explicitly requires separate supply control.

## Harness Node Names

| Harness node | Description |
|---|---|
| `GPIO_LOOP_A_OUT` | GPIO output for loopback pair A |
| `GPIO_LOOP_A_IN` | GPIO input/watch input for loopback pair A |
| `GPIO_LOOP_B_OUT` | GPIO output for loopback pair B |
| `GPIO_LOOP_B_IN` | GPIO input/watch input for loopback pair B |
| `PWM_OUT` | PWM or digital level source for analog feedback |
| `ANALOG_FB` | filtered feedback node driven by `PWM_OUT` |
| `ADC_IN` | target ADC input selected to `ANALOG_FB` |
| `I2C_SDA` | MCP23008 SDA |
| `I2C_SCL` | MCP23008 SCL |
| `I2C_INT` | MCP23008 interrupt output to target |
| `I2C_FB` | MCP23008 GPIO output feedback to target |
| `SPI_MISO` | SPI data from peripherals to target |
| `SPI_MOSI` | SPI data from target to peripherals |
| `SPI_SCK` | SPI clock |
| `SPI_CS_ADC` | MCP3008 chip select |
| `SPI_CS_FLASH` | optional W25xxx chip select |
| `ONEWIRE_DQ` | shared DS18B20 OneWire data bus |
| `UART_TX` | target TX for non-console serial validation |
| `UART_RX` | target RX for non-console serial validation |

## Shared Layout Intent

Keep the same logical block order and relative placement across harnesses where
practical, even when the DUT socket and selector details differ.

Suggested physical regions:

| Region | Suggested content |
|---|---|
| DUT socket edge | target board headers/socket and labelled fanout rows |
| Digital loopback block | two resistor-protected removable loopbacks |
| Analog block | `PWM_OUT -> resistor -> ANALOG_FB`, filter capacitor, ADC feed |
| I2C block | MCP23008 socket, pull-ups, INT and feedback links |
| SPI block | MCP3008 socket, optional W25xxx socket, chip-select links |
| OneWire block | two DS18B20 devices on one bus and one pull-up |
| Serial block | loopback or peer jumper area |
| Expansion strip | spare labelled pads for later tests or target-specific additions |

Use named harness nodes on the board silkscreen or labels rather than only raw
GPIO numbers. Raw GPIO numbers differ by target; the harness functions should
not.

## Digital Loopback Block (`gpio_block`)

Provide two resistor-protected loopback pairs.

| Connection | Series resistor | Notes |
|---|---:|---|
| `GPIO_LOOP_A_OUT` -> `GPIO_LOOP_A_IN` | 470R | removable link or mode jumper preferred |
| `GPIO_LOOP_B_OUT` -> `GPIO_LOOP_B_IN` | 470R | removable link or mode jumper preferred |

Test coverage:

- `pinMode`
- `digitalWrite`
- `digitalRead`
- `digitalPulse`
- `shiftOut`
- `setWatch`

## Analog Feedback Block (`analog_block`)

Create one filtered node named `ANALOG_FB`.

| Connection | Value | Notes |
|---|---:|---|
| `PWM_OUT` -> `ANALOG_FB` | 10k | series resistor |
| `ANALOG_FB` -> GND | 0.1uF | filter capacitor |
| `ANALOG_FB` -> `ADC_IN` | direct, short-protected, or selector-routed path | target ADC input |
| `ANALOG_FB` -> MCP3008 CH0 | direct | external SPI ADC cross-check |

On pin-limited targets, `ADC_IN` may be selected away from `ANALOG_FB` for
another mode. In that case the selector must isolate the RC filter capacitor
and MCP3008 CH0 from the alternate bus.

Test coverage:

- digital low/high read through `analogRead`
- PWM / `analogWrite` feedback through `analogRead`
- MCP3008 CH0 comparison against target ADC

## I2C MCP23008 Block (`i2c_block`)

Use one MCP23008 as the standard I2C test device.

### MCP23008 Power And Address

| MCP23008 pin/function | Connection |
|---|---|
| VDD | 3.3 V |
| VSS | GND |
| RESET | 3.3 V |
| A0 | GND |
| A1 | GND |
| A2 | GND |
| Address | `0x20` |

### MCP23008 Bus

| MCP23008 signal | Harness node |
|---|---|
| SDA | `I2C_SDA` |
| SCL | `I2C_SCL` |

If a harness uses a bare MCP23008 without module-side pull-ups, add removable
or DNP 4.7k pull-ups:

| Signal | Pull-up |
|---|---:|
| SDA -> 3.3 V | 4.7k |
| SCL -> 3.3 V | 4.7k |

### MCP23008 Feedback And Interrupt

| MCP23008 signal | Connection | Notes |
|---|---|---|
| INT | `I2C_INT` | interrupt output to target |
| GP0 | 470R -> `I2C_FB` | target feedback input |
| GP1 | 470R -> GP2 | expander internal feedback/interrupt stimulus |

Test coverage:

- I2C setup
- register read/write
- MCP23008 output feedback into target GPIO
- MCP23008 interrupt polling
- target `setWatch` on expander interrupt or feedback input

## SPI MCP3008 Block (`spi_block`)

Use one MCP3008 as the standard SPI ADC.

| MCP3008 pin/function | Harness node / connection |
|---|---|
| VDD | 3.3 V |
| VREF | 3.3 V |
| AGND | GND |
| DGND | GND |
| CLK | `SPI_SCK` |
| DOUT | `SPI_MISO` |
| DIN | `SPI_MOSI` |
| CS/SHDN | `SPI_CS_ADC` |
| CH0 | `ANALOG_FB` |
| CH1-CH7 | unconnected for first revision, or optional analog test header |

MCP3008 PDIP pin detail:

| Pin | Function | Harness node / connection |
|---:|---|---|
| 1 | CH0 | `ANALOG_FB` |
| 2-8 | CH1-CH7 | unconnected for first revision, or optional analog test header |
| 9 | DGND | GND |
| 10 | CS/SHDN | `SPI_CS_ADC` |
| 11 | DIN | `SPI_MOSI` |
| 12 | DOUT | `SPI_MISO` |
| 13 | CLK | `SPI_SCK` |
| 14 | AGND | GND |
| 15 | VREF | 3.3 V |
| 16 | VDD | 3.3 V |

Test coverage:

- SPI setup
- SPI transfer
- chip-select behavior
- analog feedback comparison through external ADC

## Optional SPI Flash Block (`spi_block`)

Reserve footprint/socket/header space for a W25xxx-compatible SPI flash device
or module.

| W25xxx signal | Harness node / connection |
|---|---|
| VCC | 3.3 V |
| GND | GND |
| CLK | `SPI_SCK` |
| DO | `SPI_MISO` |
| DI | `SPI_MOSI` |
| CS | `SPI_CS_FLASH` |
| WP | 3.3 V, if using a bare flash IC |
| HOLD | 3.3 V, if using a bare flash IC |

Test coverage:

- JEDEC ID
- status-register read
- shared-bus operation with MCP3008

This block is optional for first bring-up but should be planned into the layout.
If the harness uses a small SPI flash module rather than a bare IC, `WP` and
`HOLD` may already be handled on the module and need not appear on the harness
connector.

## OneWire DS18B20 Block (`onewire_block`)

Use two DS18B20 devices on the same OneWire bus.

| DS18B20 signal | Connection |
|---|---|
| DQ, device A | `ONEWIRE_DQ` |
| DQ, device B | `ONEWIRE_DQ` |
| VDD, both devices | 3.3 V |
| GND, both devices | GND |
| `ONEWIRE_DQ` pull-up | 4.7k to 3.3 V |

Use powered mode, not parasite power.

Test coverage:

- bus presence
- device search returns two ROMs
- family-code validation for both devices
- addressed temperature conversion/readback
- scratchpad read for each selected ROM

## Serial Peer Block (`uart_block`)

Provide a serial-peer area for non-console UART tests.

| Harness node | External peer connection |
|---|---|
| `UART_TX` | peer RX |
| `UART_RX` | peer TX |
| GND | peer GND |

Provide either:

- a local resistor-protected TX/RX loopback, or
- a header for an external USB-UART adapter

Where GPIO budget and board space allow:

- include both options and select with jumpers
- use 470R series protection on local loopback links

Test coverage:

- `Serial.setup`
- `Serial.read`
- `Serial.on("data")`
- `Serial.unsetup` / re-setup
- optional parity/error behavior where supported

## Reset And Boot Automation Header

Provide a small header for repeatable reset and boot/download control.

Minimum first-harness header:

| Header signal | Purpose |
|---|---|
| GND | common reference |
| RESET / EN | target reset control |
| BOOT | target boot/download selection |

5 V power switching is not required for the first harness design.

The runner will initially prompt for manual harness mode confirmation. This
header is intended to make later reset/boot automation straightforward without
changing the test block wiring.

## Mode Labelling

Every removable link or jumper group should have:

- a short mode label
- default position
- conflict warning if it shares pins with another block
- corresponding wiring document reference

Default state should always be:

- safe to boot
- safe to flash
- safe for connectivity tests
- no unsafe fixed pull on strapping pins

## Appendix: Block Numbering Reference

This appendix summarises the current block model and how it is
expressed in the repo.

| Block | Block name | Purpose | Repo expression |
|---:|---|---|---|
| 1 | `gpio_block` | GPIO loopback tasks such as `digitalWrite`, `digitalRead`, `setWatch`, `digitalPulse`, and `shiftOut` | shared tests in `gpio_block1`; target wiring scripts such as `gpio_block1.py` |
| 2 | `analog_block` | PWM/digital feedback into target ADC and analog validation tasks | shared tests in `analog_block2`; target wiring scripts such as `analog_block2.py` |
| 3 | `i2c_block` | MCP23008 bus access, read/write, feedback, and interrupt tasks | shared tests in `i2c_block3`; combined target cross-checks may still appear in `i2c_spi_block34.py` |
| 4 | `spi_block` | MCP3008 SPI transfer/read tasks and SPI-specific cross-checks | shared tests in `spi_block4`; SPI extension checks also remain within block 4, including `spi_extension_block4.py` |
| 5 | `onewire_block` | DS18B20 OneWire discovery and temperature-read tasks | shared tests in `onewire_block5`; target wiring scripts such as `onewire_block5.py` |
| 6 | `onewire_gpio_block` | DS2413 OneWire GPIO output/feedback tasks | shared tests reserved under `onewire_gpio_block6`; target wiring scripts such as `onewire_gpio_block6.py` |
| 7 | `uart_block` | non-console UART crosslink or peer serial tests | shared tests in `uart_block7`; target wiring scripts such as `uart_block7.py` |
| 8 | `grove_i2c_block` | external Grove I2C extension and secondary-device tasks | shared tests in `grove_i2c_block8`; target wiring scripts such as `grove_i2c_block8.py` |

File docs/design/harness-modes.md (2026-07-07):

# ESP32 Harness Modes

This document defines the family-level harness mode model.

It does not define exact selector positions, jumper states, or per-pin routing
for a specific target harness. Those details belong in the target wiring notes.

Related documents:

- [docs/design/target-reference-links.md](target-reference-links.md)
- [docs/design/connectivity-permutations.md](connectivity-permutations.md)
- [docs/design/common-harness-design-and-blocks.md](common-harness-design-and-blocks.md)
- [docs/targets/esp32-c3-devkitc-02/wiring.md](../targets/esp32-c3-devkitc-02/wiring.md)
- [docs/targets/esp32-devkitc-v4/wiring.md](../targets/esp32-devkitc-v4/wiring.md)

## Purpose

A harness mode is a named test precondition.

It tells the operator and the runner:

- which console or control path is in use
- which harness blocks are expected to be active
- which shared pins or links are deliberately borrowed for that test phase
- which conflicting blocks must be left disconnected

The exact physical implementation is target-specific. The mode meaning should
remain stable across targets even when the selector names or pin choices differ.

## Relationship To Blocks And Tests

Modes are not the same thing as blocks or tests.

- a block is a logical hardware capability grouping
- a mode is a harness configuration that enables one or more blocks
- a test is a validation task that may use one block or multiple blocks

This means a mode does not need a one-to-one relationship with a block.

For example, a target may have:

- a mode that enables only an I2C block
- a mode that enables only a OneWire block
- a combined mode that enables both SPI and I2C blocks concurrently

The same principle applies to tests. Many tests should prefer the smallest
useful block set for better fault isolation, but a valid test may still use
multiple blocks where that is the right context for the behaviour under test.

## Mode Rules

- mode state is manual and operator-confirmed unless a later harness revision
  adds reliable sensing
- the runner should prompt for the required mode and selector or link checklist
  before the test starts
- the mode used must be recorded in test evidence
- the default harness state should always be safe to boot, safe to flash, and
  safe to reach the normal REPL path
- connectivity pins stay reserved unless a deliberate mode says otherwise
- reset and boot automation is a harness capability used by other modes, not a
  separate peripheral block

## Mode Categories

The ESP32-family harnesses use a small set of recurring mode types.

### Connectivity Modes

These prove the console, flashing, and reconnect path itself.

Typical coverage:

- REPL attach
- reset and reconnect
- flashing with the harness attached
- alternate control path behaviour where supported

Examples:

- `ESP32_CONNECTIVITY`
- `C3_CONNECTIVITY_UART0`
- `C3_CONNECTIVITY_USB_SERIAL_JTAG`

### Baseline Hardware Modes

These prove the normal hardware test blocks without intentionally borrowing
connectivity resources.

Typical coverage:

- GPIO loopbacks
- `digitalPulse`
- `setWatch`
- analog/PWM feedback
- I2C
- SPI
- OneWire
- storage or external flash where fitted

Examples:

- `ESP32_BASELINE_HARDWARE`
- `C3_BASELINE_GPIO`
- `C3_BUS_SPI_I2C`

`C3_BUS_SPI_I2C` is a useful example of why modes and blocks must stay
distinct. It is a single mode name, but it can enable both the I2C and SPI
blocks together on the ESP32-C3 harness.

### Alternate Shared-Pin Modes

These exist where one target must reuse the same GPIO for more than one logical
block. They prove a deliberate alternate configuration, not the default state.
In practice these modes are selected using target-specific selector headers or
links with shunts to choose the required role. Those selector definitions belong
in the target wiring notes.

The ESP32-C3 is the main current example because its limited comfortable GPIO
budget requires significant selector use.

Typical coverage:

- analog vs OneWire selection
- I2C interrupt vs flash chip-select selection
- optional shared-bus extensions

Examples:

- `C3_ANALOG_PWM`
- `C3_I2C`
- `C3_ONEWIRE`
- `C3_SPI_FLASH_EXTENDED`

### Serial Modes

These prove non-console serial behaviour either with an external peer or with a
deliberate local crosslink.

Typical coverage:

- `Serial.setup`
- TX/RX transfer
- `Serial.read`
- `Serial.on("data")`
- reconfiguration

Examples:

- `ESP32_SERIAL_PEER`
- `ESP32_SERIAL_UART1_UART2_CROSSLINK`
- `C3_SERIAL_UART0_UART1_CROSSLINK`

### Reset And Power Modes

These prove behaviour across destructive or state-changing events that are not
part of ordinary peripheral testing.

Typical coverage:

- reset reconnect
- bootloader entry
- watchdog reset
- controlled power-cycle recovery where available

Examples:

- `ESP32_POWER_RESET`
- `C3_POWER_RESET`

## Family Position By Target Class

### Classic ESP32 Harnesses

Classic ESP32 targets usually have enough spare GPIO that most baseline test
blocks can remain wired at the same time.

So the normal pattern is:

- one connectivity mode for UART0 REPL/flashing
- one baseline hardware mode
- one serial mode for non-console UART behaviour
- one reset or power mode

The current classic harness implementation is documented in
[docs/targets/esp32-devkitc-v4/wiring.md](../targets/esp32-devkitc-v4/wiring.md).

### ESP32-C3 Harnesses

The ESP32-C3 requires more explicit modes because native USB, UART0, boot
constraints, and a smaller comfortable GPIO budget force more sharing.

So the normal pattern is:

- separate UART0 and native USB connectivity modes
- a baseline GPIO mode
- deliberate alternate modes for analog, OneWire, and combined bus testing
- a deliberate serial crosslink mode
- a reset or power mode

The current C3 implementation is documented in
[docs/targets/esp32-c3-devkitc-02/wiring.md](../targets/esp32-c3-devkitc-02/wiring.md).

## Target-Wiring Ownership

The target wiring documents own:

- exact selector names
- exact jumper or shunt positions
- default fitted and default-open states
- target-specific conflicts
- exact pin routing
- mode-specific link tables

This document owns only the family-level meaning of each mode.

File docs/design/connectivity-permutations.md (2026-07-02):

# ESP32 Connectivity And REPL Test Permutations

This note exists only to capture the small amount of design intent that is
specific to connectivity testing.

Detailed harness modes now live in
[docs/design/harness-modes.md](harness-modes.md).
REPL and Python/Codex test structure now lives in
[docs/design/repl-test-suite-design.md](repl-test-suite-design.md).

## Purpose

Connectivity testing is separate from normal GPIO and peripheral testing.

The point is to prove the console and control path itself, not just the
peripheral blocks attached to the harness.

That includes:

- REPL attach and command execution
- reset and reconnect behaviour
- flashing with the harness attached
- any alternate console path supported by the target

## Why This Matters On ESP32 Targets

On these harnesses, the active console path affects which DUT pins are reserved
and which other tests can run at the same time.

Examples:

- classic ESP32 uses UART0 on `D1` / `D3` for normal REPL and flashing
- ESP32-C3 normally uses board USB-UART on `D20` / `D21`
- ESP32-C3 native USB Serial/JTAG uses `D18` / `D19` and is a separate feature
  to prove

So connectivity is not just host plumbing. It is part of the target behaviour
under test and part of the harness mode definition.

## Current Working Position

- harness connectivity modes and reserved-pin rules are defined in
  [docs/design/harness-modes.md](harness-modes.md)
- target-specific wiring and selector details are defined in the target wiring
  notes
- REPL-shareable test content and Python runner behaviour are defined in
  [docs/design/repl-test-suite-design.md](repl-test-suite-design.md)
- manual selector and link changes are expected between some test phases and
  should be treated as explicit test preconditions

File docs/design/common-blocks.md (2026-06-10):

# Common Harness Wiring Blocks

This document defines the common reusable wiring blocks for the ESP32 hardware
test harness family.

Board-specific documents map target `Dxx` pins onto these named harness nodes.
The physical harness boards should keep these blocks in the same relative
layout where practical, even when the DUT socket and fanout differ.

These are logical harness nodes. A board-specific schematic may use more
specific net names, for example `I2C_A_SDA` for the primary `I2C_SDA` block, or
selector-side nets for loopback nodes.

## Electrical Baseline

| Item | Requirement |
|---|---|
| Logic voltage | 3.3 V |
| Ground | common ground across DUT, harness ICs, USB/serial peers, and test devices |
| IC mounting | socketed ICs for MCP3008 and MCP23008 |
| Construction | wirewrap on fixed-grid plated-through proto board |
| Labels | label harness nodes by function, not only by target GPIO |

Use one common 3.3 V rail for the target-facing peripherals unless a later
test explicitly requires separate supply control.

## Harness Node Names

| Harness node | Description |
|---|---|
| `GPIO_LOOP_A_OUT` | GPIO output for loopback pair A |
| `GPIO_LOOP_A_IN` | GPIO input/watch input for loopback pair A |
| `GPIO_LOOP_B_OUT` | GPIO output for loopback pair B |
| `GPIO_LOOP_B_IN` | GPIO input/watch input for loopback pair B |
| `PWM_OUT` | PWM or digital level source for analog feedback |
| `ANALOG_FB` | filtered feedback node driven by `PWM_OUT` |
| `ADC_IN` | target ADC input selected to `ANALOG_FB` |
| `I2C_SDA` | MCP23008 SDA |
| `I2C_SCL` | MCP23008 SCL |
| `I2C_INT` | MCP23008 interrupt output to target |
| `I2C_FB` | MCP23008 GPIO output feedback to target |
| `SPI_MISO` | SPI data from peripherals to target |
| `SPI_MOSI` | SPI data from target to peripherals |
| `SPI_SCK` | SPI clock |
| `SPI_CS_ADC` | MCP3008 chip select |
| `SPI_CS_FLASH` | optional W25xxx chip select |
| `ONEWIRE_DQ` | shared DS18B20 OneWire data bus |
| `UART_TX` | target TX for non-console serial validation |
| `UART_RX` | target RX for non-console serial validation |

## Digital Loopback Block

Provide two resistor-protected loopback pairs.

| Connection | Series resistor | Notes |
|---|---:|---|
| `GPIO_LOOP_A_OUT` -> `GPIO_LOOP_A_IN` | 470R | removable link or mode jumper preferred |
| `GPIO_LOOP_B_OUT` -> `GPIO_LOOP_B_IN` | 470R | removable link or mode jumper preferred |

Test coverage:

- `pinMode`
- `digitalWrite`
- `digitalRead`
- `digitalPulse`
- `shiftOut`
- `setWatch`

## Analog Feedback Block

Create one filtered node named `ANALOG_FB`.

| Connection | Value | Notes |
|---|---:|---|
| `PWM_OUT` -> `ANALOG_FB` | 10k | series resistor |
| `ANALOG_FB` -> GND | 0.1uF | filter capacitor |
| `ANALOG_FB` -> `ADC_IN` | direct, short-protected, or selector-routed path | target ADC input |
| `ANALOG_FB` -> MCP3008 CH0 | direct | external SPI ADC cross-check |

On pin-limited targets, `ADC_IN` may be selected away from `ANALOG_FB` for
another mode. In that case the selector must isolate the RC filter capacitor
and MCP3008 CH0 from the alternate bus.

Test coverage:

- digital low/high read through `analogRead`
- PWM / `analogWrite` feedback through `analogRead`
- MCP3008 CH0 comparison against target ADC

## I2C MCP23008 Block

Use one MCP23008 as the standard I2C test device.

### MCP23008 Power And Address

| MCP23008 pin/function | Connection |
|---|---|
| VDD | 3.3 V |
| VSS | GND |
| RESET | 3.3 V |
| A0 | GND |
| A1 | GND |
| A2 | GND |
| Address | `0x20` |

### MCP23008 Bus

| MCP23008 signal | Harness node |
|---|---|
| SDA | `I2C_SDA` |
| SCL | `I2C_SCL` |

For the first ESP32-C3 harness schematic revision, assume the attached I2C
module side provides SDA/SCL pull-ups. If a future build uses a bare MCP23008
without module pull-ups, add removable or DNP 4.7k pull-ups:

| Signal | Pull-up |
|---|---:|
| SDA -> 3.3 V | 4.7k |
| SCL -> 3.3 V | 4.7k |

### MCP23008 Feedback And Interrupt

| MCP23008 signal | Connection | Notes |
|---|---|---|
| INT | `I2C_INT` | interrupt output to target |
| GP0 | 470R -> `I2C_FB` | target feedback input |
| GP1 | 470R -> GP2 | expander internal feedback/interrupt stimulus |

Test coverage:

- I2C setup
- register read/write
- MCP23008 output feedback into target GPIO
- MCP23008 interrupt polling
- target `setWatch` on expander interrupt or feedback input

## SPI MCP3008 Block

Use one MCP3008 as the standard SPI ADC.

| MCP3008 pin/function | Harness node / connection |
|---|---|
| VDD | 3.3 V |
| VREF | 3.3 V |
| AGND | GND |
| DGND | GND |
| CLK | `SPI_SCK` |
| DOUT | `SPI_MISO` |
| DIN | `SPI_MOSI` |
| CS/SHDN | `SPI_CS_ADC` |
| CH0 | `ANALOG_FB` |
| CH1-CH7 | unconnected for first revision, or optional analog test header |

MCP3008 PDIP pin detail:

| Pin | Function | Harness node / connection |
|---:|---|---|
| 1 | CH0 | `ANALOG_FB` |
| 2-8 | CH1-CH7 | unconnected for first revision, or optional analog test header |
| 9 | DGND | GND |
| 10 | CS/SHDN | `SPI_CS_ADC` |
| 11 | DIN | `SPI_MOSI` |
| 12 | DOUT | `SPI_MISO` |
| 13 | CLK | `SPI_SCK` |
| 14 | AGND | GND |
| 15 | VREF | 3.3 V |
| 16 | VDD | 3.3 V |

Test coverage:

- SPI setup
- SPI transfer
- chip-select behavior
- analog feedback comparison through external ADC

## Optional SPI Flash Block

Reserve footprint/socket/header space for a W25xxx-compatible SPI flash device
or module.

| W25xxx signal | Harness node / connection |
|---|---|
| VCC | 3.3 V |
| GND | GND |
| CLK | `SPI_SCK` |
| DO | `SPI_MISO` |
| DI | `SPI_MOSI` |
| CS | `SPI_CS_FLASH` |
| WP | 3.3 V, if using a bare flash IC |
| HOLD | 3.3 V, if using a bare flash IC |

Test coverage:

- JEDEC ID
- status-register read
- shared-bus operation with MCP3008

This block is optional for first bring-up but should be planned into the layout.
If the harness uses a small SPI flash module rather than a bare IC, `WP` and
`HOLD` may already be handled on the module and need not appear on the harness
connector.

## OneWire DS18B20 Block

Use two DS18B20 devices on the same OneWire bus.

| DS18B20 signal | Connection |
|---|---|
| DQ, device A | `ONEWIRE_DQ` |
| DQ, device B | `ONEWIRE_DQ` |
| VDD, both devices | 3.3 V |
| GND, both devices | GND |
| `ONEWIRE_DQ` pull-up | 4.7k to 3.3 V |

Use powered mode, not parasite power.

Test coverage:

- bus presence
- device search returns two ROMs
- family-code validation for both devices
- addressed temperature conversion/readback
- scratchpad read for each selected ROM

## Serial Peer Block

Provide a serial-peer area for non-console UART tests.

| Harness node | External peer connection |
|---|---|
| `UART_TX` | peer RX |
| `UART_RX` | peer TX |
| GND | peer GND |

Provide either:

- a local resistor-protected TX/RX loopback, or
- a header for an external USB-UART adapter

Where GPIO budget and board space allow:

- include both options and select with jumpers
- use 470R series protection on local loopback links

ESP32-C3 v1.1 uses a board-specific variant of this block. Instead of a simple
external peer terminal, it provides `J10` / `SEL_UART0_UART1` as a 2x3 UART
connector/selector. Two columns allow UART1 on `D3` / `D4` to be crossed to
UART0 on `D20` / `D21` while native USB Serial/JTAG provides the runner/control
connection. The third column carries GND so the same connector can also support
external UART access with the signal shunts left open. The crossed links are
resistor-protected and default open.

Test coverage:

- `Serial.setup`
- `Serial.read`
- `Serial.on("data")`
- `Serial.unsetup` / re-setup
- optional parity/error behavior where supported

## Reset And Boot Automation Header

Provide a small header for repeatable reset and boot/download control.

Minimum first-harness header:

| Header signal | Purpose |
|---|---|
| GND | common reference |
| RESET / EN | target reset control |
| BOOT | target boot/download selection |

5 V power switching is not required for the first harness design.

The runner will initially prompt for manual harness mode confirmation. This
header is intended to make later reset/boot automation straightforward without
changing the test block wiring.

## Mode Labelling

Every removable link or jumper group should have:

- a short mode label
- default position
- conflict warning if it shares pins with another block
- corresponding wiring document reference

Default state should always be:

- safe to boot
- safe to flash
- safe for connectivity tests
- no unsafe fixed pull on strapping pins

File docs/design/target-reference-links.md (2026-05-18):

# ESP32 Target Reference Links

This document collects primary reference links for the initial ESP32 Espruino
hardware test targets.

Checked: 2026-05-18

## Initial Targets

| Test target | Board | Module | Manufacturer | Notes |
|---|---|---|---|---|
| `ESP32_C3` | ESP32-C3-DevKitC-02 | ESP32-C3-WROOM-02 | Espressif | RISC-V ESP32-C3 target with Wi-Fi and Bluetooth LE. |
| `ESP32` / original tESP32 baseline | ESP32-DevKit-LiPo Rev.D | ESP32-WROOM-32E, marking `MGN4` | Olimex | Classic dual-core Xtensa ESP32 board with LiPo power support. |

## ESP32-C3-DevKitC-02

Primary board references:

- Espressif product page: https://www.espressif.com/en/dev-board/esp32-c3-devkitc-02-en
- Espressif user guide: https://docs.espressif.com/projects/esp-dev-kits/en/latest/esp32c3/esp32-c3-devkitc-02/user_guide.html
- Board schematic: https://dl.espressif.com/dl/schematics/SCH_ESP32-C3-DEVKITC-02_V1_1_20210126A.pdf

Module and SoC references:

- ESP32-C3-WROOM-02 / WROOM-02U datasheet: https://www.espressif.com/sites/default/files/documentation/esp32-c3-wroom-02_datasheet_en.pdf
- ESP32-C3-WROOM-02 module page: https://www.espressif.com/en/module/esp32-c3-wroom-02-en
- ESP32-C3 technical reference manual: https://www.espressif.com/sites/default/files/documentation/esp32-c3_technical_reference_manual_en.pdf
- ESP32-C3 datasheet: https://www.espressif.com/sites/default/files/documentation/esp32-c3_datasheet_en.pdf
- ESP-IDF USB Serial/JTAG console guide for ESP32-C3: https://docs.espressif.com/projects/esp-idf/en/latest/esp32c3/api-guides/usb-serial-jtag-console.html

Testing relevance:

- Header pins expose GPIO, ADC, UART0, native USB D-/D+, and the board RGB LED.
- Some GPIOs are boot strapping or shared with board features, so harness pin
  allocation must be checked against the board schematic and module boot rules.
- Native USB Serial/JTAG on the C3 may affect how REPL, flashing, and reset
  automation differ from classic ESP32 USB-UART boards.
- On the ESP32-C3-DevKitC-02 board, the normal Micro-USB connector is the
  USB-to-UART bridge path; native USB Serial/JTAG is exposed through the
  chip's USB D-/D+ pins on `GPIO18` / `GPIO19`.

## Olimex ESP32-DevKit-LiPo Rev.D

Primary board references:

- Olimex product/open-source hardware page: https://www.olimex.com/Products/IoT/ESP32/ESP32-DevKit-LiPo/open-source-hardware
- Olimex hardware repository: https://github.com/OLIMEX/ESP32-DevKit-LiPo
- Olimex Rev.D hardware files: https://github.com/OLIMEX/ESP32-DevKit-LiPo/tree/master/HARDWARE/ESP32-DevKit-LiPo-Rev.D
- Olimex ESP32 product family page: https://www.olimex.com/Products/IoT/ESP32/

Module and SoC references:

- ESP32-WROOM-32E / ESP32-WROOM-32UE datasheet: https://documentation.espressif.com/esp32-wroom-32e_esp32-wroom-32ue_datasheet_en.html
- ESP32 technical reference manual: https://www.espressif.com/sites/default/files/documentation/esp32_technical_reference_manual_en.pdf
- ESP32 datasheet: https://www.espressif.com/sites/default/files/documentation/esp32_datasheet_en.pdf
- ESP32 hardware design guidelines: https://www.espressif.com/sites/default/files/documentation/esp32_hardware_design_guidelines_en.pdf
- ESP-IDF serial connection guide for ESP32: https://docs.espressif.com/projects/esp-idf/en/latest/esp32/get-started/establish-serial-connection.html

Testing relevance:

- The Rev.D board is intended to be pin-compatible with Espressif ESP32-DevKitC while
  adding LiPo charging, battery operation, battery measurement, and external
  power sense circuitry.
- The module family on this board is classic ESP32, so tests should distinguish
  classic ESP32 behavior from ESP32-C3 behavior where UART, ADC, Bluetooth,
  USB/serial, strapping pins, and low-power behavior differ.
- The board under test has an ESP32-WROOM-32E module marked `MGN4`.
- Battery and external-power sense pins may be useful later, but should be
  treated as board-specific rather than part of the core `jshardware` contract.

## Cross-Target References

- Espressif documentation portal: https://docs.espressif.com/
- ESP-IDF programming guide: https://docs.espressif.com/projects/esp-idf/en/latest/esp32/
- Espruino repository: https://github.com/espruino/Espruino
- Espruino ESP32 board files: https://github.com/espruino/Espruino/tree/master/boards
- Espruino ESP32 target implementation: https://github.com/espruino/Espruino/tree/master/targets/esp32

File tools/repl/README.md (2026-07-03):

# Shared REPL Runner

This directory contains Python runners for the shared functional REPL tests in
`tests/repl/`.

Current scope:

- single-test execution
- Python-owned metadata capture and result parsing
- direct serial transport
- optional EspruinoTools CLI transport

Primary entry point:

- `run_test.py`

Typical direct-serial usage:

```bash
python tools/repl/run_test.py tests/repl/gpio_block1/gpio_readwrite_basic.js \
  --port /dev/ttyUSB0
```

Typical EspruinoTools transport usage:

```bash
python tools/repl/run_test.py tests/repl/gpio_block1/gpio_readwrite_basic.js \
  --port /dev/ttyUSB0 \
  --transport cli \
  --cli-path /path/to/EspruinoTools/bin/espruino-cli.js
```

Notes:

- Python remains the runner architecture. Transport is an implementation detail.
- The CLI path must be explicit, either with `--cli-path` or
  `ESPRUINO_CLI_PATH`.
- The runner filters output down to the agreed structured lines plus runner
  metadata.

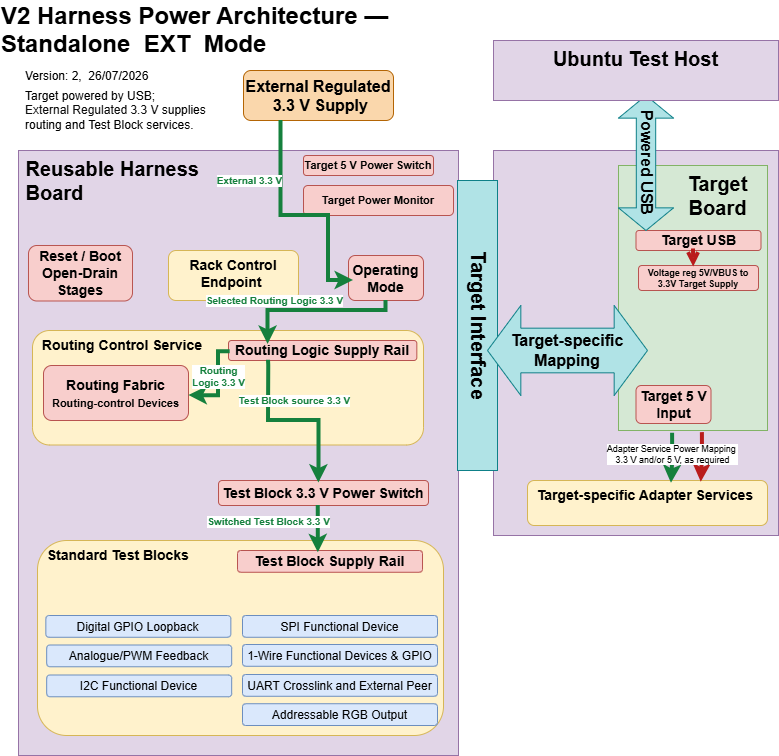
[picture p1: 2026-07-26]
docs/design/V2Harness/arch/diagrams/Rack-Architecture-Power-Standalone-EXT_V2.png

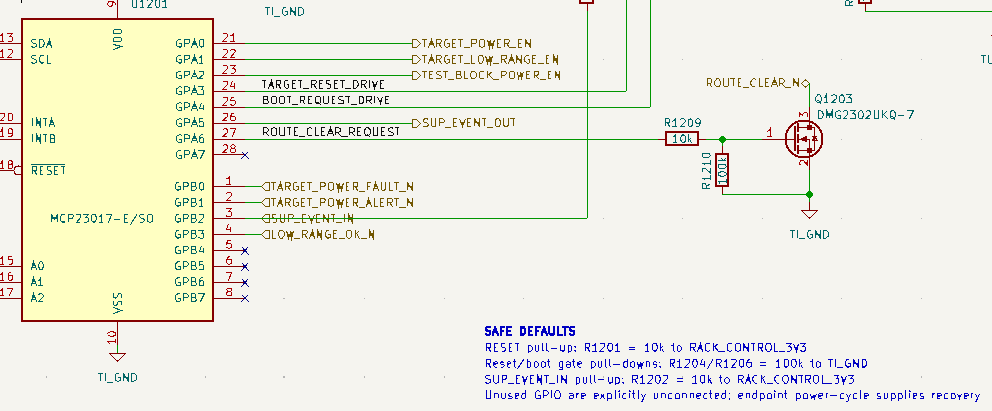
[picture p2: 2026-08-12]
docs/design/V2Harness/implementation/review-images/RC02-hardware-clear-request.png

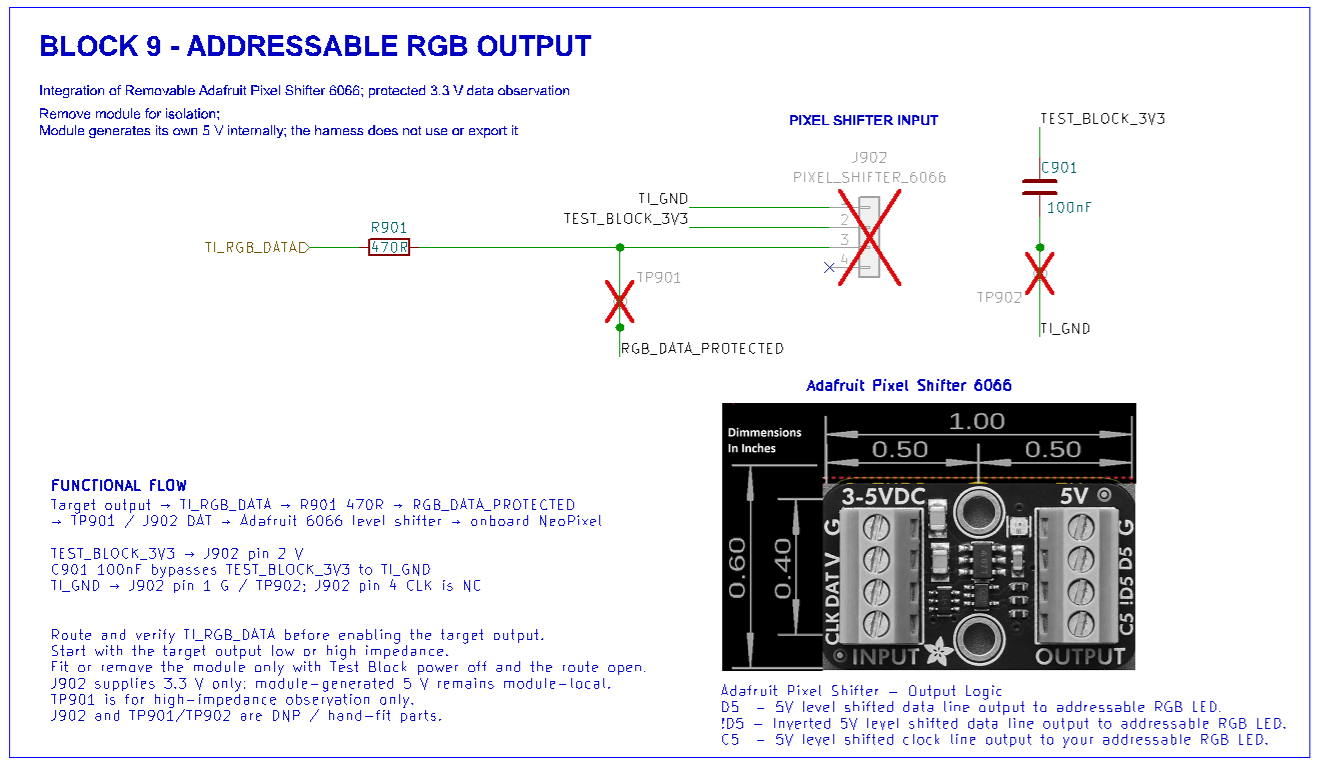
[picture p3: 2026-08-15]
docs/design/V2Harness/implementation/review-images/TB09-addressable-rgb-output.png

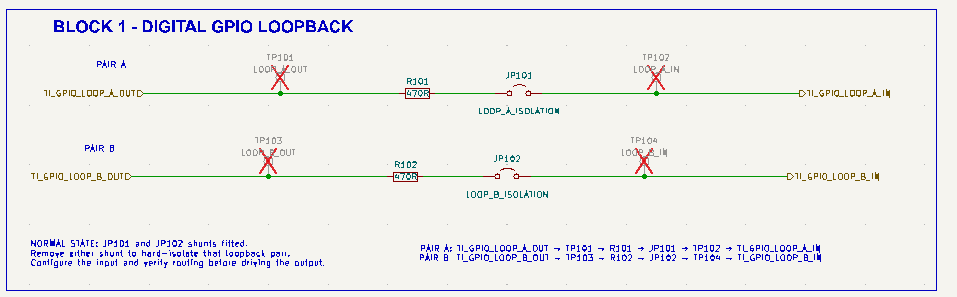
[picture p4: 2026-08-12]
docs/design/V2Harness/implementation/review-images/TB01-digital-gpio-loopback.png

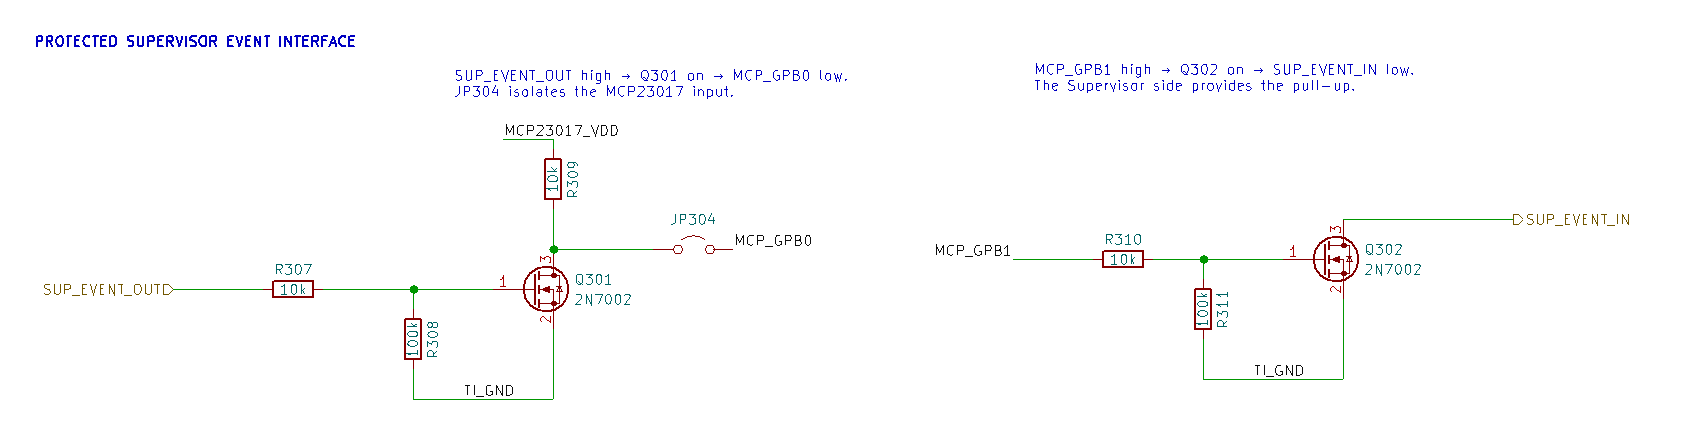
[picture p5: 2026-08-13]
docs/design/V2Harness/implementation/review-images/TB03-supervisor-event-handshake.png

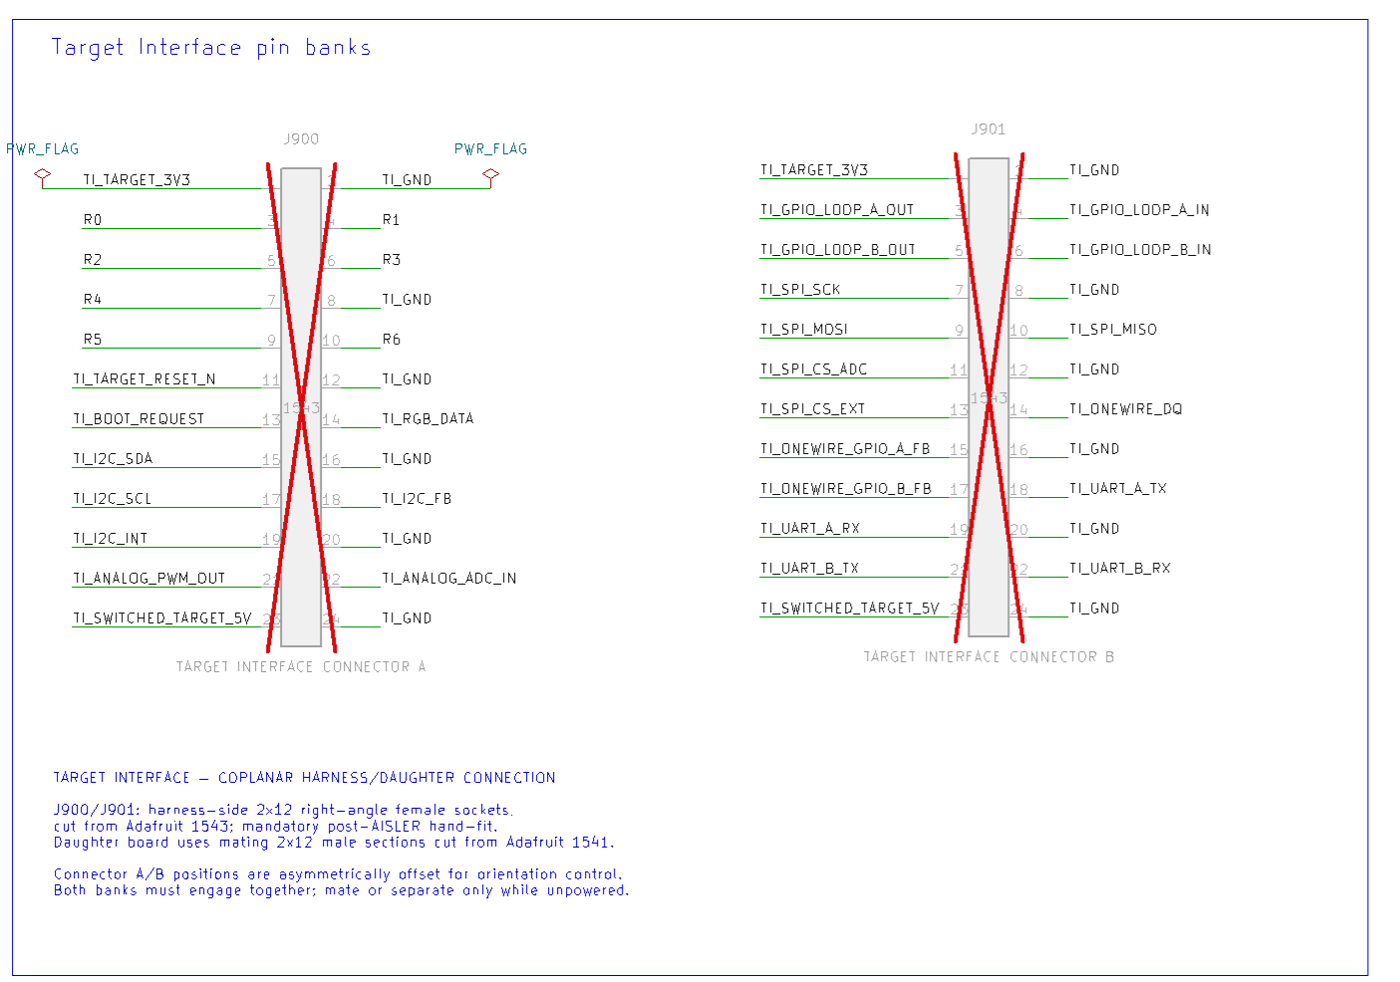
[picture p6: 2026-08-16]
docs/design/V2Harness/implementation/review-images/TI01-target-interface-connector-banks.png

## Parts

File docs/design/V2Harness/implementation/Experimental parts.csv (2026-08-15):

Experiment Group | Part Description | Full MPN | Qty | Package | Mouser | DigiKey | Farnell UK | RS UK | Notes | Reference
Combined Passives | 1 ohm 1% 3 W current-sense shunt | CHP2512-FX-1R00ELF | 1 | 2512 SMD | 1
Combined Passives | 50 milliohm 1% 2 W current-sense shunt | PE2512FKF7W0R05L | 1 | 2512 SMD | 1 | 1
Combined Passives | 100 nF ceramic capacitor |  | 11 | Through-hole ceramic
Combined Passives | 4.7 nF C0G/NP0 ceramic capacitor |  | 2 | Through-hole ceramic
Combined Passives | 1 uF multilayer ceramic capacitor |  | 5 | Through-hole ceramic
Combined Passives | 2.2 nF C0G/NP0 ceramic capacitor |  | 1 | Through-hole ceramic
Combined Passives | Switchable 22–50 uF test-load capacitor arrangement |  | 1 | Through-hole assembly
Combined Passives | 470 ohm 1% resistor |  | 4 | Through-hole axial
Combined Passives | 4.7 kohm 1% resistor |  | 6 | Through-hole axial
Combined Passives | 10 kohm 1% resistor |  | 7 | Through-hole axial
Combined Passives | 100 kohm 1% resistor |  | 13 | Through-hole axial
Combined Passives | Local fuse for Experiment C |  | 1 | Fuse and holder; rating TBD
Experiment A | N-channel MOSFET | DMG2302UKQ-7 | 1 | SOT-23-3 | 1 | 2 | 1
Experiment A | I2C GPIO expander | MCP23017-E/SP | 1 | SPDIP-28 (SP) | 1 | 1
Experiment A | Four-channel analogue switch | TMUX1511PWR | 2 | TSSOP-14 (PW) | 1 | 1
Experiment A | 3.0 V supervisor with programmable delay | TPS3808G30DBVR | 2 | SOT-23-6 (DBV) | 1 | 1
Experiment A | TSSOP-14 to 2.54 mm adapter |  | 2 | TSSOP-14 adapter
Experiment A | SOT-23-6 to 2.54 mm adapter |  | 2 | SOT-23-6 adapter
Experiment A | SOT-23-3 to 2.54 mm adapter |  | 1 | SOT-23-3 adapter
Experiment B | Dual common-cathode Schottky diode | BAT54C-E3-08 | 5 | SOT-23-3 | 1 | 1
Experiment B | N-channel MOSFET | DMN2024UQ-7 | 1 | SOT-23-3 | 1 | 1
Experiment B | Power multiplexer | TPS2116DRLR | 1 | SOT-5X3-8 (DRL) | 1 | 1
Experiment B | Load switch experiment carrier option | TPS22917DBVT | 1 | SOT-23-6 (DBV) | 1 | 2 | 3 |  | Production remains TPS22917DBVR | https://www.mouser.co.uk/en/c/?q=TPS22917DBVT
Experiment B | Operating-mode header |  | 1 | 2x4 2.54 mm through-hole header
Experiment B | Operating-mode shunts |  | 4 | 2.54 mm jumper shunt
Experiment B | SOT-5X3-8 to 2.54 mm adapter |  | 1 | SOT-5X3-8 / DRL adapter
Experiment B | SOT-23-6 to 2.54 mm adapter |  | 1 | SOT-23-6 adapter
Experiment B | SOT-23-3 adapters or combined carrier |  | 6 | SOT-23-3 adapter
Experiment C | P-channel MOSFET | AO3401A | 1 | SOT-23-3 |  | 2 | 3
Experiment C | Current and power monitor | INA226AIDGSR | 1 | VSSOP-10 (DGS) | 2 | 1 | 1
Experiment C | INA228 current and power monitor carrier module | ADA5832 | 1 | Adafruit assembled breakout module |  |  |  |  | Retain original 15 milliohm shunt; adapt exact Rev-A 1 ohm shunt | https://thepihut.com/products/adafruit-ina228-i2c-85v-20-bit-high-or-low-side-power-monitor-stemma-qt-qwiic
Experiment C | Dual two-input AND gate | SN74LVC2G08DCUR | 1 | VSSOP-8 (DCU) | 1 | 1
Availability Watch | NOT IN CURRENT EXPERIMENT - adjustable current-limited power switch | TPS2559QWDRCRQ1 | 0 | VSON-10 3x3 mm exposed pad (DRC) | 2 | 1 |  |  | Deferred; exact live stock and carrier not confirmed
Experiment C | Single-bit voltage-level translator experiment package | TXU0101DCKR | 1 | SC70-6 (DCK) | 1 | 2 | 0 |  | Production remains TXU0101DBVR
Availability Watch | NOT IN CURRENT EXPERIMENT - exposed-pad carrier for TPS2559 |  | 0 | VSON-10 3x3 mm DRC carrier |  |  |  |  | Deferred with TPS2559
Experiment C | VSSOP-10 to 2.54 mm adapter |  | 1 | VSSOP-10 adapter
Experiment C | VSSOP-8 to 2.54 mm adapter |  | 1 | VSSOP-8 adapter
Experiment C | SC70-6 to 2.54 mm adapter |  | 1 | SC70-6 adapter
Experiment C | SOT-23-3 to 2.54 mm adapter |  | 1 | SOT-23-3 adapter
Experiment C | Shunt carriers with separate force and Kelvin connections |  | 2 | 2512 adapter/carrier

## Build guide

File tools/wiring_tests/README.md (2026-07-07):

# Wiring Tests

This directory contains harness wiring-test runners.

The purpose of these tests is to prove that a specific hardware test block is
wired correctly on a specific harness target before wider firmware conclusions
are made.

These tests are target-orientated in directory structure:

- `esp32_c3/`
- `esp32_v1/`

Each target directory contains runners for the wiring and signal paths that are
actually present on that harness.

Typical examples are:

- `gpio_block1.py`
  proves the basic GPIO loopback wiring used for `digitalWrite`,
  `digitalRead`, watches, and pulse observation
- `uart_block7.py`
  proves the non-console UART crosslink wiring on the classic ESP32 harness
- `i2c_spi_block34.py`
  proves a deliberate combined I2C plus SPI wiring cross-check where one
  target wiring script still exercises blocks 3 and 4 together
- `grove_i2c_block8.py`
  proves that the external Grove I2C connector can reach an external device on
  the same bus as the onboard harness I2C block

These runners are intentionally wiring-focused.

They are not intended to be the final portable REPL test suite. Their role is
to support harness bring-up, bench validation, and investigation work with
clear target-specific pin maps and selector expectations.

Underlying schematics and hardware reference material can be found under
[Hardware](/home/simon/MaBecker/ESP32_SGATest/Hardware).

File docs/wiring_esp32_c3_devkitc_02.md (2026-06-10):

# ESP32-C3-DevKitC-02 Harness Wiring Spec

This document maps the common harness blocks onto the Espressif
ESP32-C3-DevKitC-02.

Related documents:

- [wiring_common_blocks.md](wiring_common_blocks.md)
- [harness_modes.md](harness_modes.md)
- [gpio_rationalisation.md](gpio_rationalisation.md)
- [connectivity_permutations.md](connectivity_permutations.md)

## Board Under Test

| Item | Value |
|---|---|
| Board | ESP32-C3-DevKitC-02 |
| Module | ESP32-C3-WROOM-02 |
| Pin naming in tests | `Dxx`, matching GPIO number |
| Normal board USB | USB-UART bridge to UART0 |
| Native USB Serial/JTAG | `D18` / `D19`, via harness USB D-/D+ connection |

## Reserved Connectivity Pins

These pins are not general harness GPIO in the default design.

| Pin | Function | Harness rule |
|---:|---|---|
| `D18` | native USB D- | connect to native USB D- block |
| `D19` | native USB D+ | connect to native USB D+ block |
| `D20` | UART0 RX | reserve for board USB-UART REPL/flashing; selector-used only in UART0/UART1 crosslink mode |
| `D21` | UART0 TX | reserve for board USB-UART REPL/flashing; selector-used only in UART0/UART1 crosslink mode |
| `D9` | boot/download button path | reserve for boot/download control only |
| `D8` | onboard RGB LED / strapping | used only as `PWM_OUT` through 10k series resistance; no fixed pull |

## Default Connectivity Wiring

The ESP32-C3-DevKitC-02 already has a USB connector on the board. That board
USB path goes through the onboard USB-UART bridge to UART0, and it is expected
to be the normal REPL/flashing/control connection for most automated tests.

The harness additionally provides a separate native USB Serial/JTAG connector.
This is not the normal board USB-UART path. It wires directly to the ESP32-C3
native USB pins so phase-one testing can prove the direct USB Serial/JTAG
function independently.

| Board pin / signal | Harness connection | Notes |
|---|---|---|
| Board Micro-USB | host USB | UART0 REPL/flashing path |
| `D18` | fixed wire to native USB/JTAG connector D- | native USB Serial/JTAG |
| `D19` | fixed wire to native USB/JTAG connector D+ | native USB Serial/JTAG |
| GND | native USB/JTAG connector GND and harness GND | common ground |
| VBUS | native USB/JTAG connector VBUS through inline shunt | optional host 5 V feed; default shunt state to be marked |
| EN / reset | automation header `RESET` | also keep manual reset accessible |
| Boot/download path | automation header `BOOT` | expected to control board boot/download path |

In this harness revision, `D18` and `D19` are used only by the additional
harness native USB Serial/JTAG connector. They are not part of the board
USB-UART path, and they are not shared with peripheral test blocks:
`D18` / GPIO18 is fixed-wired to the harness connector USB D-, and
`D19` / GPIO19 is fixed-wired to the harness connector USB D+.

Use a four-position screw connector for the harness USB Serial/JTAG cable:

| Connector pin | Signal | Harness connection |
|---|---|---|
| 1 | USB GND | harness GND |
| 2 | USB VBUS | inline shunt to harness/board 5 V rail |
| 3 | USB D- | fixed wire to `D18` |
| 4 | USB D+ | fixed wire to `D19` |

The VBUS connection must be shunt-selectable so the harness can be tested with
the native USB/JTAG connector providing signalling only, or with VBUS connected
when that is explicitly desired. This is not a switched 5 V power subsystem;
it is an inline VBUS link for the native USB/JTAG connector.

## Selector-Based GPIO Allocation

The ESP32-C3 has limited spare GPIO once UART0, native USB Serial/JTAG, boot
control, and strapping safety are respected. This harness therefore does not
wire every test function to a dedicated pin. Instead, several C3 GPIOs are
routed through labelled selector blocks.

A selector block lets one GPIO serve one of several test roles. Only one shunt
should be fitted per selector at a time. The mode tables later in this document
state which selector positions are required for each test mode.

## Schematic Selector Bank

The schematic is the master wiring definition for the C3 harness. Multi-use
GPIOs use dual-row selector headers with the MCU GPIO repeated on row A and
the selectable function nets on row B. Fit one vertical shunt only per selector.

| Selector | Header | Row A common | Row B options | Notes |
|---|---:|---|---|---|
| `SEL_D0` | 2x02 | `GPIO0` on `a1`, `a2` | `b1` = `ONEWIRE_DQ`; `b2` = `ADC_IN` via `ANALOG_FB` | `ADC_IN` is the user-facing role; it connects D0 to the `ANALOG_FB` net |
| `SEL_D1` | 2x02 | `GPIO1` on `a1`, `a2` | `b1` = `I2C_A_SDA`; `b2` = loop A output via `R5` | `b2` loops to `SEL_D2 b2` through 470R |
| `SEL_D2` | 2x02 | `GPIO2` on `a1`, `a2` | `b1` = `I2C_A_FB`; `b2` = loop A input via `R5` | `I2C_A_FB` is MCP23008 GP0 feedback through `R2` |
| `SEL_D3` | 2x03 | `GPIO3` on `a1`, `a2`, `a3` | `b1` = `SPI_MISO`; `b2` = loop B output via `R7`; `b3` = `D3_UART1_TX` | UART1 TX route for crosslink mode |
| `SEL_D4` | 2x03 | `GPIO4` on `a1`, `a2`, `a3` | `b1` = `I2C_A_SCL`; `b2` = loop B input via `R7`; `b3` = `D4_UART1_RX` | UART1 RX route for crosslink mode |
| `SEL_D10` | 2x02 | `GPIO10` on `a1`, `a2` | `b1` = `I2C_INT`; `b2` = `SPI_CS_FLASH` | selects MCP23008 interrupt or optional flash CS |
| `J10` / `SEL_UART0_UART1` | 2x03 | `a1` = `D20_UART0_RX` via `R6`; `a2` = `D21_UART0_TX` via `R8`; `a3` = GND | `b1` = `D3_UART1_TX`; `b2` = `D4_UART1_RX`; `b3` = GND | fit both signal shunts only for UART0/UART1 crosslink testing; GND pins support external UART access |
| `SEL_D08` | 1x02 | `GPIO8` / `PWM_OUT` | `R3` 10k to `ANALOG_FB` | single safety jumper; default open for safest boot |

Schematic net names use the `I2C_A_` prefix for the primary I2C block. In test
descriptions, `I2C_SDA`, `I2C_SCL`, and `I2C_FB` refer to `I2C_A_SDA`,
`I2C_A_SCL`, and `I2C_A_FB` respectively.

## C3 GPIO Test Role Allocation

The table below lists the approved C3 test roles for each GPIO. For
selector-controlled pins, the roles are alternatives selected by the named
selector; they are not
simultaneously connected.

| C3 pin | Harness roles | Selector / wiring | Notes |
|---:|---|---|---|
| `D0` / GPIO0 | `ADC_IN`, `ONEWIRE_DQ` | `SEL_D0` | ADC position connects to `ANALOG_FB`; OneWire position isolates `ANALOG_FB` from the OneWire bus |
| `D1` / GPIO1 | `I2C_SDA`, `GPIO_LOOP_A_OUT` | `SEL_D1` | `I2C_A_SDA` or loop A output through `R5` |
| `D2` / GPIO2 | `I2C_FB`, `GPIO_LOOP_A_IN` | `SEL_D2` | strapping pin; no fixed pull; loop/I2C feedback through resistors |
| `D3` / GPIO3 | `SPI_MISO`, `GPIO_LOOP_B_OUT`, `UART1_TX` | `SEL_D3` | SPI MISO, loop B output through `R7`, or UART1 TX for crosslink mode |
| `D4` / GPIO4 | `I2C_SCL`, `GPIO_LOOP_B_IN`, `UART1_RX` | `SEL_D4` | I2C clock, loop B input through `R7`, or UART1 RX for crosslink mode |
| `D5` / GPIO5 | `SPI_MOSI` | fixed wire | fixed SPI bus wiring |
| `D6` / GPIO6 | `SPI_SCK` | fixed wire | fixed SPI bus wiring |
| `D7` / GPIO7 | `SPI_CS_ADC` | fixed wire | MCP3008 chip select |
| `D8` / GPIO8 | `PWM_OUT` | `SEL_D08` safety jumper | strapping/RGB LED pin; only through 10k to `ANALOG_FB`; default open |
| `D9` / GPIO9 | BOOT automation | fixed automation header wiring | boot/download control only |
| `D10` / GPIO10 | `I2C_INT`, `SPI_CS_FLASH` | `SEL_D10` | MCP23008 interrupt or optional flash chip select |
| `D18` / GPIO18 | native USB D- | fixed wire to `J1` | reserved for native USB Serial/JTAG |
| `D19` / GPIO19 | native USB D+ | fixed wire to `J1` | reserved for native USB Serial/JTAG |
| `D20` / GPIO20 | UART0 RX | `J10` / `SEL_UART0_UART1` via `R6` only | reserved by default; used only for UART0/UART1 crosslink or deliberate external UART access |
| `D21` / GPIO21 | UART0 TX | `J10` / `SEL_UART0_UART1` via `R8` only | reserved by default; used only for UART0/UART1 crosslink or deliberate external UART access |

## Permanent Wiring

These connections are either permanent or built as the fixed/default selector
paths because they do not create unmanaged mode conflicts.

| Connection | Notes |
|---|---|
| `D18` -> native USB D- | default phase-one requirement |
| `D19` -> native USB D+ | default phase-one requirement |
| `D20` / `D21` reserved by default | selector-connected only through `J10` / `SEL_UART0_UART1` for deliberate UART0/UART1 crosslink or external UART access |
| `D5` -> `SPI_MOSI` | fixed SPI bus wiring |
| `D6` -> `SPI_SCK` | fixed SPI bus wiring |
| `D7` -> `SPI_CS_ADC` | fixed MCP3008 chip-select wiring |
| `D8` -> `SEL_D08` -> 10k -> `ANALOG_FB` | single safety jumper; no fixed pull on strapping pin |
| 3.3 V and GND rails | common harness rails |
| reset and boot lines to automation header | manual/automation access |

`D8` is a strapping pin and also drives the onboard RGB LED. The harness must
not add a fixed pull-up or pull-down. The only normal external load is the 10k
series path into `ANALOG_FB`, which may be opened with a jumper if bring-up
shows any boot sensitivity.

`D0` is the common row of `SEL_D0`. One shunt position selects `ADC_IN` by
connecting `D0` to `ANALOG_FB` for ADC/PWM/SPI analog tests. The other shunt
position connects `D0` to `ONEWIRE_DQ` for DS18B20 tests. Do not fit both shunts:
`ANALOG_FB` has the RC smoothing capacitor and MCP3008 CH0 load, which should
be isolated from the OneWire bus.

## Harness Test Modes

The following sections define the manual harness modes used by the test
runner. Each mode lists the required selector positions and any conflicting
selector positions that must not be fitted.

### Baseline GPIO Mode

Mode name:

- `C3_BASELINE_GPIO`

Required selector positions / wiring:

| Selector or wiring | Position |
|---|---|
| `SEL_D1` | shunt `GPIO1` to loop A output, `a2-b2` |
| `SEL_D2` | shunt `GPIO2` to loop A input, `a2-b2` |
| loop A resistor | `SEL_D1 b2` -> `R5` 470R -> `SEL_D2 b2` |
| `SEL_D3` | shunt `GPIO3` to loop B output, `a2-b2` |
| `SEL_D4` | shunt `GPIO4` to loop B input, `a2-b2` |
| loop B resistor | `SEL_D3 b2` -> `R7` 470R -> `SEL_D4 b2` |

Open/conflicting selector positions:

| Selector group | Required state |
|---|---|
| `SEL_D1` / `SEL_D2` I2C positions | not fitted |
| `SEL_D3` SPI or UART position | not fitted |
| `SEL_D4` I2C or UART position | not fitted |
| `SEL_D08` analog/PWM path | open unless analog/PWM testing is active |
| `SEL_D0` OneWire position | not fitted |

Notes:

- `D2` is accepted as a strapping pin only because it has no fixed pull and is
  used through resistor-protected/manual-mode wiring.
- Physical loopback wiring should be `D1 -> 470R -> D2` and
  `D3 -> 470R -> D4`.

### Analog/PWM Mode

Mode name:

- `C3_ANALOG_PWM`

Required selector positions / wiring:

| Selector or wiring | Position |
|---|---|
| `SEL_D08` | closed after safe boot if PWM feedback is being run |
| `PWM_OUT` -> 10k -> `ANALOG_FB` | permanent |
| `ANALOG_FB` -> 0.1uF -> GND | permanent |
| `SEL_D0` | select `ADC_IN`: shunt `GPIO0` to `ANALOG_FB`, `a2-b2` |
| `ANALOG_FB` -> MCP3008 CH0 | closed/permanent if MCP3008 fitted |

Boot-safety requirement:

- no direct `D8` pull-up or pull-down
- no low-value LED/test load from `D8` to either rail
- if fitted, a `D8` -> `PWM_OUT` jumper should default open until the board has
  booted cleanly with the harness attached

Test note:

- `D0` analog feedback behavior must be confirmed during bring-up.
- PWM-generated `ANALOG_FB` can be read by both target ADC on `D0` and MCP3008
  CH0 over SPI in `C3_BUS_SPI_I2C`.
- OneWire tests require the `D0` selector to move away from `ANALOG_FB`.

### I2C Mode

Mode name:

- `C3_I2C`

Required selector positions / wiring:

| Selector or wiring | Position |
|---|---|
| `SEL_D1` | shunt `GPIO1` to `I2C_A_SDA`, `a1-b1` |
| `SEL_D4` | shunt `GPIO4` to `I2C_A_SCL`, `a1-b1` |
| `SEL_D10` | shunt `GPIO10` to `I2C_INT`, `a1-b1` |
| `SEL_D2` | shunt `GPIO2` to `I2C_A_FB`, `a1-b1`, if feedback tests are run |
| I2C SDA/SCL pull-ups | provided by attached I2C module(s) for this revision |

Open/conflicting selector positions:

| Selector group | Required state |
|---|---|
| `SEL_D1` / `SEL_D2` loopback positions | not fitted |
| `SEL_D3` / `SEL_D4` UART crosslink positions | not fitted |
| `SEL_D4` loopback position | not fitted |

Enabled coverage:

- MCP23008 register read/write
- GP0 feedback through `D2`
- INT through `D10`
- `setWatch` on expander feedback/interrupt where supported

### Combined SPI/I2C Bus Mode

Mode name:

- `C3_BUS_SPI_I2C`

Purpose:

- verify Espruino SPI pin mapping and transfer behavior using the MCP3008
- verify Espruino I2C pin mapping and MCP23008 operation in the same physical harness mode
- exercise both bus APIs without moving jumpers between SPI and I2C tests

Required selector positions / wiring:

| Selector or wiring | Position |
|---|---|
| `SEL_D1` | shunt `GPIO1` to `I2C_A_SDA`, `a1-b1` |
| `SEL_D4` | shunt `GPIO4` to `I2C_A_SCL`, `a1-b1` |
| `SEL_D10` | shunt `GPIO10` to `I2C_INT`, `a1-b1` |
| `SEL_D2` | shunt `GPIO2` to `I2C_A_FB`, `a1-b1`, if feedback tests are run |
| `SEL_D08` | closed after boot if PWM-to-ADC/SPI comparison is being run |
| `SEL_D0` | select `ADC_IN`: shunt `GPIO0` to `ANALOG_FB`, `a2-b2`, if target ADC comparison is run |
| `SEL_D3` | shunt `GPIO3` to `SPI_MISO`, `a1-b1` |
| `D5` -> `SPI_MOSI` | closed |
| `D6` -> `SPI_SCK` | closed |
| `D7` -> `SPI_CS_ADC` | closed |
| MCP3008 CH0 -> `ANALOG_FB` | closed |
| I2C SDA/SCL pull-ups | provided by attached I2C module(s) for this revision |

ESP32-C3 harness wiring:

| ESP32-C3 pin | Harness node | Peripheral connection |
|---|---|---|
| `D1` / GPIO1 | `I2C_SDA` | MCP23008 `SDA`; Grove `SDA` |
| `D4` / GPIO4 | `I2C_SCL` | MCP23008 `SCL`; Grove `SCL` |
| `D10` / GPIO10 | `I2C_INT` | MCP23008 `INT` |
| `D2` / GPIO2 | `I2C_FB` | MCP23008 `GP0` via 470R |
| `D8` / GPIO8 | `PWM_OUT` | 10k to `ANALOG_FB`; no fixed pull |
| `D0` / GPIO0 | `ADC_IN` selector common | select to `ANALOG_FB` for target ADC comparison |
| `D3` / GPIO3 | `SPI_MISO` | MCP3008 `DOUT`; optional W25xxx `DO` |
| `D5` / GPIO5 | `SPI_MOSI` | MCP3008 `DIN`; optional W25xxx `DI` |
| `D6` / GPIO6 | `SPI_SCK` | MCP3008 `CLK`; optional W25xxx `CLK` |
| `D7` / GPIO7 | `SPI_CS_ADC` | MCP3008 `CS/SHDN` |

MCP3008 wiring detail:

| MCP3008 PDIP pin | Function | Connection |
|---:|---|---|
| 16 | `VDD` | `3V3` |
| 15 | `VREF` | `3V3` |
| 14 | `AGND` | GND |
| 9 | `DGND` | GND |
| 13 | `CLK` | `SPI_SCK` |
| 12 | `DOUT` | `SPI_MISO` |
| 11 | `DIN` | `SPI_MOSI` |
| 10 | `CS/SHDN` | `SPI_CS_ADC` |
| 1 | `CH0` | `ANALOG_FB` |
| 2-8 | `CH1`-`CH7` | no connection for first revision, or optional analog test header |

Open/conflicting selector positions:

| Selector group | Required state |
|---|---|
| loopback selector positions on `SEL_D1`, `SEL_D2`, `SEL_D3`, `SEL_D4` | not fitted |
| `SEL_D08` analog/PWM drive | close only after confirming boot safety |
| `SEL_D0` OneWire position | not fitted |
| UART crosslink positions on `SEL_D3` / `SEL_D4` | not fitted |
| `SEL_D10` flash-CS position | not fitted while `GPIO10` is used for `I2C_INT` |

Enabled coverage:

- MCP3008 transfer/read
- MCP23008 register read/write
- MCP23008 feedback and interrupt behavior
- SPI and I2C operation in one manual harness mode

### SPI Flash Extended Mode

Mode name:

- `C3_SPI_FLASH_EXTENDED`

This optional mode reuses the SPI bus above but moves `D10` from `I2C_INT` to
`SPI_CS_FLASH`. It is not part of the first combined SPI/I2C bus mode.

Required selector change from `C3_BUS_SPI_I2C`:

| Selector or wiring | Position |
|---|---|
| `SEL_D10` | move shunt from `I2C_INT` `a1-b1` to `SPI_CS_FLASH` `a2-b2` |

Enabled coverage:

- optional W25xxx JEDEC/status
- shared-bus chip-select behavior with MCP3008

### OneWire Mode

Mode name:

- `C3_ONEWIRE`

Required selector positions / wiring:

| Selector or wiring | Position |
|---|---|
| `SEL_D0` | shunt `GPIO0` to `ONEWIRE_DQ`, `a1-b1` |
| `ONEWIRE_DQ` -> 4.7k -> 3.3 V | fitted |
| DS18B20 A DQ -> `ONEWIRE_DQ` | closed/permanent within OneWire block |
| DS18B20 B DQ -> `ONEWIRE_DQ` | closed/permanent within OneWire block |

Open/conflicting selector positions:

| Selector group | Required state |
|---|---|
| `SEL_D0` analog feedback position | not fitted |
| analog filtered node / MCP3008 CH0 load | isolated from `D0` by selector |

Compatible selector positions:

| Selector group | Allowed state |
|---|---|
| I2C links on `D1`, `D4`, `D10`, and `D2` | may remain closed for combined I2C + OneWire tests |

Enabled coverage:

- two-device search
- addressed DS18B20 selection
- scratchpad read
- temperature conversion
- optional I2C display/logging of temperature readings while OneWire is active

### UART0/UART1 Crosslink Mode

Mode name:

- `C3_SERIAL_UART0_UART1_CROSSLINK`

Purpose:

- prove non-console `Serial` API behavior on a second UART mapping
- deliberately exercise UART0 ownership while the runner controls/monitors the
  DUT through native USB Serial/JTAG
- avoid needing an external USB-UART peer for the C3 serial test

Required selector positions / wiring:

| Selector or wiring | Position |
|---|---|
| Runner/control path | native USB Serial/JTAG on `D18` / `D19` |
| `SEL_D3` | shunt `GPIO3` to `D3_UART1_TX`, `a3-b3` |
| `SEL_D4` | shunt `GPIO4` to `D4_UART1_RX`, `a3-b3` |
| `J10` / `SEL_UART0_UART1` column 1 | fit shunt: `D3_UART1_TX` -> `D20_UART0_RX` through `R6` |
| `J10` / `SEL_UART0_UART1` column 2 | fit shunt: `D21_UART0_TX` -> `D4_UART1_RX` through `R8` |
| `J10` / `SEL_UART0_UART1` column 3 | GND/GND; available as common ground for external UART access |

Open/conflicting selector positions:

| Selector group | Required state |
|---|---|
| loopback positions on `SEL_D3` / `SEL_D4` | not fitted |
| `SEL_D3` SPI MISO position | not fitted |
| `SEL_D4` I2C SCL position | not fitted |
| `SEL_D0` OneWire position | not fitted unless combining intentionally |
| board USB-UART control path | do not use as the runner/control path while UART0 is under test |

External UART access:

- with the two signal shunts open, `J10` can also be used as an external UART
  access connector for either side of the UART test block.
- the two GND pins on column 3 provide a local common reference for an external
  USB-UART adapter or test instrument.

Enabled coverage:

- `Serial.setup` on UART0 and UART1-capable mappings
- TX/RX transfer across the crossed UART pair
- `Serial.read`
- `Serial.on("data")`
- `Serial.unsetup` / re-setup
- detection of console/ownership conflicts between UART0 and the selected REPL
  path

### Native USB Serial/JTAG Mode

Mode name:

- `C3_CONNECTIVITY_USB_SERIAL_JTAG`

Required selector positions / wiring:

| Selector or wiring | Position |
|---|---|
| `D18` -> native USB/JTAG connector D- | fixed wire |
| `D19` -> native USB/JTAG connector D+ | fixed wire |
| native USB/JTAG connector GND -> harness GND | fixed wire |
| native USB/JTAG connector VBUS -> 5 V rail | inline shunt, fit only when VBUS feed is wanted |

Open/conflicting selector positions:

| Selector group | Required state |
|---|---|
| any peripheral use of `D18` / `D19` | not allowed in phase-one default design |

Enabled coverage:

- native USB Serial/JTAG enumeration
- native USB serial REPL if firmware exposes it
- reset/reconnect behavior
- flashing/debug path if supported by selected tooling

## Automation Header

The automation header is a provision for later repeatable reset and
boot/download control. It does not automate the harness by itself: a future
runner controller or external interface will be required to pull these lines to
the required states under software control.

Minimum C3 automation header:

| Header pin | C3/board signal | Purpose |
|---|---|---|
| GND | GND | common reference |
| RESET | EN / reset | reset control |
| BOOT | boot/download path | download-mode selection |

5 V power switching is not required for this first harness. Native USB/JTAG
VBUS is provided through a simple inline shunt, not through a power switch.

## Default Jumper State

Default state means the safe starting configuration after assembly, before a
specific test mode has been selected. It should allow the DUT to boot normally,
preserve the board USB-UART path for the usual REPL/flashing connection, keep the
harness USB Serial/JTAG connector wired but not force it to power the board, and
support the baseline GPIO loopback tests.

Permanent wiring, no shunt required:

| Wiring | Default state |
|---|---|
| Board USB-UART path | left untouched; use the ESP32-C3-DevKitC-02 USB connector for normal REPL/flashing |
| Harness USB Serial/JTAG data | `D18` / GPIO18 wired to harness USB `D-`; `D19` / GPIO19 wired to harness USB `D+` |
| SPI fixed lines | `D5` / GPIO5 to `SPI_MOSI`, `D6` / GPIO6 to `SPI_SCK`, `D7` / GPIO7 to `SPI_CS_ADC` |
| Automation header | available, but inactive unless an external runner/controller is connected |

Default fitted shunts:

| Selector | Default position | Purpose |
|---|---|---|
| `SEL_D1` | `a2-b2` | `D1` / GPIO1 to loopback A output |
| `SEL_D2` | `a2-b2` | `D2` / GPIO2 to loopback A input |
| `SEL_D3` | `a2-b2` | `D3` / GPIO3 to loopback B output |
| `SEL_D4` | `a2-b2` | `D4` / GPIO4 to loopback B input |

Default open / not fitted:

| Selector or shunt | Default state | Reason |
|---|---|---|
| `SEL_D0` | no shunt fitted | choose `ONEWIRE_DQ` or `ADC_IN` only for the relevant test mode |
| `SEL_D08` | open | keeps the `D8` / GPIO8 PWM drive path disconnected until analog feedback tests |
| `SEL_D10` | no shunt fitted | choose `I2C_INT` or `SPI_FLASH_CS` only for the relevant test mode |
| `SEL_D3` / `SEL_D4` UART positions | not fitted | UART crosslink testing is a deliberate mode, not the baseline |
| `J10` / `SEL_UART0_UART1` | no signal shunts fitted | keeps UART0 pins reserved for board USB-UART unless crosslink or external UART access is active |
| `JP1` harness USB VBUS shunt | open unless intentionally using harness USB VBUS | avoids an unintended 5 V feed into the board/harness rail |
| `JP12` external 5 V shunt | open unless intentionally using external 5 V input | avoids an unintended 5 V feed into the board/harness rail |

Do not fit `JP1` and `JP12` together unless the power-source arrangement has
been deliberately reviewed. Test-runner prompts should name the required selector
positions before each non-default mode is run.

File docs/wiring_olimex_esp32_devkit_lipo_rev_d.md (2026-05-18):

# Olimex ESP32-DevKit-LiPo Rev.D Harness Wiring Spec

This document maps the common harness blocks onto the Olimex
ESP32-DevKit-LiPo Rev.D.

Related documents:

- [wiring_common_blocks.md](wiring_common_blocks.md)
- [harness_modes.md](harness_modes.md)
- [gpio_rationalisation.md](gpio_rationalisation.md)
- [outstanding_items_review.md](outstanding_items_review.md)

## Board Under Test

| Item | Value |
|---|---|
| Board | Olimex ESP32-DevKit-LiPo Rev.D |
| Module | ESP32-WROOM-32E, marking `MGN4` |
| Pin naming in tests | `Dxx`, matching GPIO number |
| Normal board USB | USB-UART bridge to UART0 |

## Reserved Connectivity Pins

| Pin | Function | Harness rule |
|---:|---|---|
| `D1` | UART0 TX | reserve for board USB-UART REPL/flashing |
| `D3` | UART0 RX | reserve for board USB-UART REPL/flashing |
| `D0` | boot strapping/download | reserve for boot/download control only |
| `D2` | strapping-related | no fixed harness load |
| `D5` | strapping-related on many ESP32 designs | avoid fixed harness use |
| `D12` | strapping-related | avoid fixed harness use |
| `D15` | strapping-related | avoid fixed harness use |
| `D6`-`D11` | module flash pins | do not use |

## Olimex Board-Specific Notes

Keep these solder jumpers open for the core harness:

| Jumper | Board function | Reason |
|---|---|---|
| `BAT_SENS_E1` | battery sense to `GPI35` | keeps `D35` available for `I2C_INT` |
| `PWR_SENS_E1` | external power sense to `GPI39` | keeps `D39` available for `I2C_FB` |

Board-specific battery/power sensing can be tested later as an Olimex-specific
extension, but it is outside the core `jshardware` harness wiring.

## Approved Fixed Harness Allocation

The classic ESP32 harness is intended to be mostly fixed wiring.

| Harness node | ESP32 pin | Notes |
|---|---:|---|
| `GPIO_LOOP_A_OUT` | `D32` | safe bidirectional GPIO |
| `GPIO_LOOP_A_IN` | `D33` | safe bidirectional GPIO |
| `GPIO_LOOP_B_OUT` | `D25` | safe bidirectional GPIO |
| `GPIO_LOOP_B_IN` | `D26` | safe bidirectional GPIO |
| `PWM_OUT` | `D27` | PWM-capable output |
| `ADC_IN` | `D34` | input-only ADC feedback input |
| `I2C_SDA` | `D21` | conventional ESP32 I2C SDA |
| `I2C_SCL` | `D22` | conventional ESP32 I2C SCL |
| `I2C_INT` | `D35` | input-only interrupt input |
| `I2C_FB` | `D39` | input-only feedback input |
| `SPI_MISO` | `D19` | conventional VSPI MISO |
| `SPI_MOSI` | `D23` | conventional VSPI MOSI |
| `SPI_SCK` | `D18` | conventional VSPI SCK |
| `SPI_CS_ADC` | `D16` | avoids strapping pins |
| `SPI_CS_FLASH` | `D17` | second safe chip select |
| `ONEWIRE_DQ` | `D13` | two-device DS18B20 bus |
| `UART_TX` | `D14` | non-console UART TX |
| `UART_RX` | `D36` | input-only UART RX |

## Digital Loopback Wiring

| Connection | Series resistor | Link |
|---|---:|---|
| `D32` / `GPIO_LOOP_A_OUT` -> `GPIO_LOOP_A_IN` / `D33` | 470R | fixed or removable |
| `D25` / `GPIO_LOOP_B_OUT` -> `GPIO_LOOP_B_IN` / `D26` | 470R | fixed or removable |

Removable links are still useful for fault isolation, but no mode conflict is
expected in the normal fixed harness.

## Analog/PWM Wiring

| Connection | Value / notes |
|---|---|
| `D27` -> `PWM_OUT` | fixed |
| `PWM_OUT` -> `ANALOG_FB` | 10k series resistor |
| `ANALOG_FB` -> GND | 0.1uF capacitor |
| `ANALOG_FB` -> `D34` / `ADC_IN` | fixed |
| `ANALOG_FB` -> MCP3008 CH0 | fixed |

## I2C MCP23008 Wiring

| Harness node | ESP32 pin |
|---|---:|
| `I2C_SDA` | `D21` |
| `I2C_SCL` | `D22` |
| `I2C_INT` | `D35` |
| `I2C_FB` | `D39` |

MCP23008 wiring:

| MCP23008 signal | Connection |
|---|---|
| SDA | `D21` |
| SCL | `D22` |
| INT | `D35` |
| GP0 | 470R -> `D39` |
| GP1 | 470R -> GP2 |
| A0/A1/A2 | GND |
| RESET | 3.3 V |
| VDD/VSS | 3.3 V / GND |

Fit 4.7k pull-ups on SDA/SCL if not provided elsewhere.

## SPI Wiring

| Harness node | ESP32 pin |
|---|---:|
| `SPI_MISO` | `D19` |
| `SPI_MOSI` | `D23` |
| `SPI_SCK` | `D18` |
| `SPI_CS_ADC` | `D16` |
| `SPI_CS_FLASH` | `D17` |

MCP3008 wiring:

| MCP3008 signal | Connection |
|---|---|
| DOUT | `D19` |
| DIN | `D23` |
| CLK | `D18` |
| CS/SHDN | `D16` |
| CH0 | `ANALOG_FB` |
| VDD/VREF | 3.3 V |
| AGND/DGND | GND |

Optional W25xxx wiring:

| W25xxx signal | Connection |
|---|---|
| DO | `D19` |
| DI | `D23` |
| CLK | `D18` |
| CS | `D17` |
| VCC/GND | 3.3 V / GND |

## OneWire Wiring

| Connection | Notes |
|---|---|
| `D13` -> `ONEWIRE_DQ` | fixed |
| `ONEWIRE_DQ` -> 4.7k -> 3.3 V | one bus pull-up |
| DS18B20 A DQ -> `ONEWIRE_DQ` | powered mode |
| DS18B20 B DQ -> `ONEWIRE_DQ` | powered mode |
| DS18B20 A/B VDD | 3.3 V |
| DS18B20 A/B GND | GND |

## Serial Peer Wiring

| Harness node | ESP32 pin | External peer |
|---|---:|---|
| `UART_TX` | `D14` | peer RX |
| `UART_RX` | `D36` | peer TX |
| GND | GND | peer GND |

Optional local loopback:

| Connection | Series resistor |
|---|---:|
| `D14` / `UART_TX` -> `UART_RX` / `D36` | 470R |

Use a removable jumper to select local loopback vs external peer.

## Reset And Boot Automation Header

Minimum automation header:

| Header pin | Board signal | Purpose |
|---|---|---|
| GND | GND | common reference |
| RESET | EN / reset | reset control |
| BOOT | `D0` boot/download path | download-mode selection |

5 V power switching is not required for this first harness.

## Expected Default State

Default state should allow:

- normal board USB-UART REPL/flashing
- all fixed hardware test blocks connected
- reset and boot/download access
- no battery/power-sense solder jumper connected to `D35` / `D39`
- no fixed load on reserved strapping pins

Default open:

- local serial loopback if using external peer
- any board-specific battery/power sensing jumpers

Default closed:

- GPIO loopback links
- analog feedback path
- I2C block
- SPI MCP3008 block
- OneWire two-device bus
- reset/boot automation header access

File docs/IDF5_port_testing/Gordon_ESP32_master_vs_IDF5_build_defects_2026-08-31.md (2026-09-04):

# Classic ESP32: Current Master versus Corrected IDF5

- Date: 31 August 2026
For: Gordon Williams

> **Subsequent status, 4 September 2026:** This report records the pre-merge
> comparison supplied to Gordon as input to the IDF5 merge decision. The
> official IDF5 branch, including submitted corrections #2733 through #2738,
> was merged into Espruino master at `5d79af218`. The held OneWire proposal was
> not submitted. A same-source post-merge sanity run remains outstanding; the
> results below have not been rewritten.

## Objective

Compare the user-visible Espruino peripheral behaviour of the current classic
ESP32 master build with the corrected ESP-IDF 5 build, and identify defects
that would affect confidence in moving the classic ESP32 port to IDF5.

## What We Compared

Both firmware builds were compiled as the classic ESP32 port and exercised on
the same ESP32 DevKitC V4 board. The board was plugged into a fixed test fixture
which connects selected pins to each other and to known I2C, SPI and OneWire
devices. This lets an Espruino script drive one API and independently observe
the result through another API or external device.

| | Current ESP32 master | Corrected IDF5 |
|---|---|---|
| Espruino board | `ESP32` | `ESP32_IDF5` |
| Reported version | `2v29.277` | `2v29.75` |
| Source commit | `c5ff787b199148c31ef2776fb6f70673cba01a25` | `354fa95fb` |
| IDF line | legacy ESP-IDF 3.3.6 | ESP-IDF 5.5.3 |
| Build command | `make BOARD=ESP32 RELEASE=1` | `make BOARD=ESP32_IDF5 RELEASE=1` |

The corrected IDF5 source is based on the official `IDF5` branch at
`25f81a8e1`. That base already contains the merged Wi-Fi debug-build and I2C
configuration fixes. The validation branch adds the separately reviewable ADC,
PWM/DAC, GPIO routing, DAC release, OneWire timing and pin-cleanup corrections.

The same corrected source was also built and tested with `BOARD=ESP32`. This
compatibility build passed the main GPIO, ADC, PWM, DAC, I2C, SPI and flash
checks. It therefore provides evidence that the IDF5 source corrections do not
break the existing classic build configuration. Two legacy-source concerns
remain: OneWire retains the current master-style instability, and repeated UART
setup reached an old FreeRTOS queue assertion on iteration 9 of 10.

## Issues on the Current Master Build

1. **OneWire discovery and addressed reads are unreliable.** In 100 calls to
   `OneWire.search()`, all three fitted devices were returned only 50 times;
   29 searches returned no device. Repeated addressed DS18B20 reads also
   produced CRC failures. DS2413 commands worked once its address had been
   obtained, so the device and command path are usable but discovery is not
   dependable.

2. **`analogWrite(D25, 1)` does not produce DAC full scale.** The conversion to
   an 8-bit DAC value multiplies by 256, so the inclusive Espruino value `1`
   wraps to zero. The zero endpoint passed and the full-scale endpoint failed.

3. **The `digitalPulse()` output is correct, but completion can be reported
   late.** The connected input observed the requested `[1,0,1,0]` edge sequence
   and the output ended low. A later JavaScript result callback sometimes did
   not run within the original test window. This is a scheduler/event-delivery
   observation, not evidence that the physical pulse was wrong.

4. **A 200-byte UART receive is not completely delivered to JavaScript within
   the original short observation window.** The first 120 bytes were visible
   at 350 ms. Longer observation showed further data callbacks, so this should
   not be described as proven permanent loss of 80 bytes.

5. **UART cleanup reports an internal pin-state diagnostic.** Calling
   `Serial.unsetup()` prints `jshPinSetState: Unexpected state: 0`, although the
   completed data checks are not corrupted.

6. **Several Wi-Fi API anomalies predate IDF5.** `Wifi.setAPIP()` applies the
   requested AP address but reports `"Failure"`; `Wifi.setIP()` reports success
   but leaves the DHCP address unchanged; and a C3 station cannot ping the
   classic ESP32 AP even though bidirectional UDP succeeds.

7. **The plain BLE advertising/service-data test is not clean.** When master
   scans the C3 advertisement it finds the named peer but reports the service
   data under the wrong UUID/payload. In the reverse role the C3 does not find
   the plain master advertisement. Complete GATT transactions nevertheless
   pass in both directions.

## Issues on the Corrected IDF5 Build

1. **Addressed DS18B20 reads still suffer intermittent CRC corruption.** On the
   final `2v29.75` image, `OneWire.search()` reliably found both DS18B20s and the
   DS2413, and all DS2413 commands passed. However, the focused mixed-device run
   failed one of two DS18B20 CRC checks. In a 20-cycle read soak, 13 of 19
   captured cycles contained at least one bad scratchpad CRC; one additional
   cycle was missed by the host capture. The proposed OneWire critical-section
   change improves discovery but does not fully correct addressed reads on the
   classic ESP32, so that change is not ready for submission as a complete fix.

2. **Wi-Fi station scanning and AP authentication are regressed.** IDF5
   `Wifi.scan()` returned zero networks in three controlled runs while the C3
   AP was active. Direct `Wifi.connect()` can associate when the scan is
   skipped, which narrows this to the scan path. In the reverse role, the C3
   found the IDF5 WPA2 AP at strong signal but every association attempt ended
   in `4WAY_HANDSHAKE_TIMEOUT`. Current master passed association and UDP in
   both roles on the same bench.

3. **`Wifi.setIP()` changes the displayed address but leaves it unusable.**
   IDF5 obtained DHCP, changed from `192.168.4.2` to the requested
   `192.168.4.77`, and reported `"Failure"` through the callback. Neither ping
   nor the run-bound UDP exchange then worked. Master has a different existing
   defect: it reports success but leaves the DHCP address in use, with traffic
   still functional.

4. **UART event delivery can still be delayed in source based on the official
   IDF5 branch.** That branch predates current-master commit `a3f085979`, which
   fixes loss when more than 64 bytes arrive in one packet. In the compatibility
   build, all 200 bytes eventually arrived as four callbacks, but short tests
   could see only the early callbacks. The official IDF5 branch should be
   brought forward or reconciled with that master change before final UART
   acceptance.

No IDF5-only failure was found in the tested `pinMode()`, digital I/O, watch,
`shiftOut()`, ADC, PWM, DAC, I2C, SPI, external flash, ordinary UART or BLE
GATT paths after applying the corrective changes.

## Issues with IDF5 Not Present in Master

The confirmed IDF5-only functional regressions are empty `Wifi.scan()` results
and WPA2 AP authentication failure. Current master passes the corresponding
station and AP exchanges. IDF5 also differs in `Wifi.setIP()` behaviour: the
requested address is displayed but cannot carry the test traffic.

The official IDF5 source also lags the newer master UART receive change. The
observed OneWire CRC fault is not IDF5-only: current master is also unreliable
and is worse at device discovery. The exact failure distribution differs, so
the IDF5 OneWire result is still an open defect rather than a pass. BLE GATT
passes equivalently on both lines, and the plain advertising failures reproduce
on both lines.

The corrected IDF5 build also contains tested improvements over current
master:

- `analogWrite(D25, 1)` reaches the DAC high endpoint;
- a DAC pin can be returned to ordinary `digitalWrite()`/`digitalPulse()` use;
- `Serial.unsetup()` no longer emits the undefined pin-state diagnostic;
- `OneWire.search()` found the complete three-device bus on every repeated
  search, compared with 50/100 complete searches on master;
- the original short-window 200-byte UART test completed on IDF5, although
  longer tests show the master result should be described as delayed delivery
  rather than confirmed truncation.

## Conclusion

The corrected IDF5 build is comparable with current master in the wired
classic-ESP32 API scope. It passes the digital, analogue, I2C, SPI, flash and
UART functional checks and fixes several defects seen on master. BLE GATT also
passes fully in both central/peripheral directions. Building the same corrected
source as `BOARD=ESP32` provides useful compatibility confidence.

The overall IDF5 build is not yet ready to replace current master. The release
blockers found by this work are intermittent CRC corruption during addressed
DS18B20 reads and the two fundamental Wi-Fi failures: empty station scans and
WPA2 AP authentication timeouts. The OneWire timing patch should remain on
hold, and the Wi-Fi regressions require source investigation. The official
IDF5 branch should also be reconciled with the newer master UART receive fix
before final acceptance.

## Appendix One — Summary of Tests Executed

### Digital APIs

| Espruino APIs | Behaviour checked | Master | Corrected IDF5 |
|---|---|---:|---:|
| `pinMode()`, `digitalWrite()`, `digitalRead()` | Drive and read two connected output/input pairs low and high | Pass 4/4 | Pass 4/4 |
| `digitalPulse()`, `setWatch()` | Generate timed pulses and verify the connected input edge sequence and final level | Physical pulse passes; completion callback can be late | Pass |
| `setWatch()`, `clearWatch()` | Rising, falling and both-edge callbacks, then removal | Pass 4/4 | Pass 4/4 |
| `shiftOut()` | Send `0xa5` and observe its eight data/clock transitions | Pass 3/3 | Pass 3/3 |

### Analogue APIs

| Espruino APIs | Behaviour checked | Master | Corrected IDF5 |
|---|---|---:|---:|
| `analogRead()` | Read known low and high levels on `D34` | Pass 4/4 | Pass 4/4 |
| `analogWrite()`, `analogRead()` | Request 0.25, 0.5 and 0.75 PWM and confirm ordered analogue feedback | Pass 5/5 | Pass 5/5 |
| `analogWrite(D25, value)` | Check the classic ESP32 DAC at zero and full scale | Fail 1/2 | Pass 2/2 |
| `digitalWrite()`, `digitalPulse()` after DAC use | Return the DAC pin to normal GPIO operation | Not isolated | Pass |

### I2C APIs

| Espruino APIs | Behaviour checked | Master | Corrected IDF5 |
|---|---|---:|---:|
| `I2C1.setup()`, `writeTo()`, `readFrom()` | Read and write MCP23008 registers | Pass 6/6 | Pass 6/6 |
| I2C access plus `setWatch()`/`digitalRead()` | Assert, identify and clear an MCP23008 interrupt | Pass 5/5 | Pass 5/5 |
| `writeTo()`/`readFrom()` with two addresses | Communicate independently with devices at `0x20` and `0x21` | Pass 8/8 | Pass 8/8 |

### SPI APIs

| Espruino APIs | Behaviour checked | Master | Corrected IDF5 |
|---|---|---:|---:|
| `SPI1.setup()`, `SPI1.send()` | Read an MCP3008 external ADC at low, midpoint and high inputs | Pass 11/11 | Pass 11/11 |
| `SPI1.send()` with a separate chip select | Read a W25xxx flash identity and status on the shared SPI bus | Pass 9/9 | Pass 9/9; JEDEC `EF 40 17` |

### OneWire APIs

| Espruino APIs | Behaviour checked | Master | Corrected IDF5 |
|---|---|---:|---:|
| `new OneWire(D13)`, `reset()`, `search()` | Repeatedly discover two DS18B20s and one DS2413 | Complete set 50/100 | Complete set 100/100; final image 6/6 in formal run |
| `skip()`, `select()`, `write()`, `read()` | Start conversion and read both DS18B20 scratchpads with CRC validation | Unstable; 12/20 soak cycles failed | Unstable; 13/19 captured cycles had a CRC failure |
| DS2413 `select()`, `write()`, `read()` | Command release and both-low states and verify returned status | Pass when addressed | Pass 6/6 |

### Serial APIs

| Espruino APIs | Behaviour checked | Master | Corrected IDF5 |
|---|---|---:|---:|
| `Serial2.setup()`, `Serial3.setup()`, `write()`, `on("data")`, `read()`, `available()` | Transfer 32, 64, 65, 96, 128 and 200-byte patterns in both directions | Pass through 128; 200-byte callbacks delayed | Pass through 200 in the formal window |
| `write()`, `print()`, `println()` | Strings, arrays, typed arrays, numbers and line endings | Pass | Pass |
| `flush()` and event-listener methods | Complete queued output; attach, remove and reattach listeners | Pass | Pass |
| `inject()`, `pipe()` | Inject synthetic receive data and pipe a physical serial stream | Pass | Pass |
| repeated `setup()`/`unsetup()` | Alternate speed, frame shape and direction | Pass in master run | Data-path pass; lineage/compatibility concern noted above |
| simultaneous send/receive | Exchange independent 96- and 128-byte patterns and verify hashes | Pass with longer observation | Pass with longer observation |
| `isConnected()` | Before setup, after setup and after `unsetup()` | Legacy result differs | Correctly `false`, `true`, `false` |

### Wi-Fi and BLE APIs

| Espruino APIs | Behaviour checked | Master | Corrected IDF5 |
|---|---|---:|---:|
| `Wifi.scan()`, `connect()`, `getIP()`, `ping()` | Discover and join a controlled WPA2 peer, obtain DHCP, ping and exchange UDP | Pass 12/12 | Fail; scan returned zero networks in repeated runs |
| `Wifi.startAP()`, AP details/IP and peer events | Host a WPA2 AP and exchange run-bound UDP with the C3 station | Association and UDP pass; known directional ping failure | Fail; AP visible but WPA2 four-way handshake times out |
| wrong password and unavailable SSID | Reject incorrect credentials and bound an absent-network attempt | Pass | Wrong-password precondition fails because scan is empty |
| `Wifi.setAPIP()` | Apply a custom AP subnet and report callback result separately | Address works; callback incorrectly reports `"Failure"` | Address is reported, but clients cannot authenticate |
| `Wifi.setIP()` | Apply `192.168.4.77` after DHCP and prove traffic independently | Reports success but retains DHCP `.2`; traffic works | Reports `"Failure"`, shows `.77`, but ping/UDP fail |
| `NRF.setAdvertising()`, `NRF.findDevices()` | Advertise and discover a generated name plus service data in both directions | Shared plain-advertising failures | Same failures; no IDF5 regression established |
| `NRF.setServices()`, `requestDevice()` and GATT APIs | Connect in both directions, discover service/characteristics, read once and write twice | Pass both roles, 9/9 each | Pass both roles, 9/9 each |
| Wi-Fi/BLE cleanup | Remove active address/AP, disconnect BLE and stop advertising | Pass | Pass |

### Build Checks

| Build | Result |
|---|---|
| Current source, `BOARD=ESP32 RELEASE=1` | Built and full master comparison executed |
| Corrected source, `BOARD=ESP32 RELEASE=1` | Built; main wired compatibility checks pass |
| Corrected source, `BOARD=ESP32_IDF5 RELEASE=1` | Built; 28% application partition free; final image tested |

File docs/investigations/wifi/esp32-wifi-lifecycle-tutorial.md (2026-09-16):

# Understanding ESP32 Wi-Fi Lifecycles In Espruino

Date: 2026-09-15

Validation updated: 2026-09-16

## Purpose And Main Point

Espruino provides a JavaScript `Wifi` API, while the ESP32 port translates
those calls into asynchronous ESP-IDF driver operations and events. The most
important point when reading or changing this code is that these are separate
states:

1. a Wi-Fi operating mode has been selected;
2. the ESP-IDF station or access-point interface has started;
3. a station has associated with an access point; and
4. the station has obtained an IP address and is ready for network traffic.

Selecting or starting station mode does not mean that a connection was
requested. `Wifi.scan()` needs a started station interface to listen for access
points, but it must not connect to one. Confusing those two operations caused
the `Wifi.scan()` empty-result defect investigated in September 2026.

This document explains the ESP32 implementation on upstream base `1c96229d0`
and the scan/connect correction at `dc274713a`, submitted as
[Espruino PR #2752](https://github.com/espruino/Espruino/pull/2752). It is a
tutorial and investigation aid, not a replacement for the public
[Espruino `Wifi` API reference](https://www.espruino.com/Reference#Wifi).

## The Two Software Layers

The public API declarations and documentation are in the Espruino source file:

```text
libs/network/jswrap_wifi.c
```

The ESP32 implementation is in:

```text
libs/network/esp32/jswrap_esp32_network.c
```

The implementation follows this general sequence:

```text
JavaScript Wifi call
        |
        v
ESP32 Espruino wrapper selects a mode and calls ESP-IDF
        |
        v
ESP-IDF performs the operation asynchronously
        |
        v
ESP-IDF posts Wi-Fi or IP events
        |
        v
Espruino's ESP32 event handler updates native state and queues
JavaScript callbacks or Wifi events for the interpreter
```

This means that returning from `Wifi.connect()`, `Wifi.scan()` or
`Wifi.startAP()` does not by itself prove that the requested operation has
finished. Completion is reported later through callbacks and events.

## The Four ESP32 Operating Modes

ESP-IDF exposes four operating modes. Espruino reports corresponding values
through `Wifi.getStatus().mode`, although exact strings and the amount of state
reported can vary between ports and versions.

| Native mode | Meaning | Typical Espruino operation |
|---|---|---|
| `WIFI_MODE_NULL` | Neither station nor access point is selected | Initial or fully inactive state |
| `WIFI_MODE_STA` | The ESP32 can act as a station | `Wifi.scan()` or `Wifi.connect()` |
| `WIFI_MODE_AP` | The ESP32 provides an access point | `Wifi.startAP()` |
| `WIFI_MODE_APSTA` | Access point and station roles coexist | Classic ESP32 AP followed by `Wifi.connect()` |

Mode is configuration, not proof of association or IP connectivity. A station
can be selected and started while scanning, while attempting a connection, or
while disconnected.

ESP-IDF supports simultaneous AP and station operation on ESP32-C3, but the
current Espruino wrapper deliberately replaces one role with the other during
ordinary `Wifi.connect()` and `Wifi.startAP()` transitions. This is a retained
IDF4-era Espruino workaround, not a documented ESP32-C3 capability limit. The
classic ESP32 path uses `WIFI_MODE_APSTA`. Removing the C3 workaround requires
separate lifecycle validation and is deliberately outside the local
scan/connect candidate.

## Native State Used By The ESP32 Wrapper

Here, **native state** means values stored internally by the ESP32 C code to
remember what has happened and what it should do next. They are not properties
that JavaScript applications read from the `Wifi` object. The local
scan/connect candidate adds two of these values, `g_isStaStarted` and
`g_connectAfterStaStart`; the other values already exist in the wrapper:

| State | Purpose | Added by candidate? |
|---|---|---|
| `g_isStaStarted` | Records receipt of station `START` and `STOP` events | Yes |
| `g_isStaConnected` | Records the wrapper's connected state; it is set on association and cleared after bounded retries are exhausted | No; already present |
| `g_connectAfterStaStart` | One-shot instruction saying an explicit `Wifi.connect()` request is waiting for station startup | Yes |
| `g_retryCounter` | Bounds retries following failed or lost station association | No; already present |
| `g_isAPStarted` | Records access-point `START` and `STOP` events | No; already present |
| `g_jsScanCallback` | Records that a scan is in progress and owns its completion callback | No; already present |
| `g_jsGotIpCallback` | Holds a connection callback until IP acquisition or terminal failure | No; already present |

The distinction between the first three station fields is essential:

- `g_isStaStarted` answers **can the driver accept a connect request now?**
- `g_isStaConnected` answers **is the wrapper treating the station as
  connected or still inside its retry sequence?**
- `g_connectAfterStaStart` answers **did JavaScript explicitly request a
  connection that is waiting for startup?**

The retry counter is not a suitable replacement for the one-shot request flag.
It describes retry policy, not why the station interface was started.

## Espruino Functions That Control The Lifecycle

### `require("Wifi")`

```javascript
var wifi = require("Wifi");
```

This obtains the Espruino Wi-Fi library object. The ESP32 networking subsystem
and event handlers are initialized by the port when Wi-Fi hardware support is
enabled; obtaining the object is not itself a request to associate or scan.

The ESP32-specific `ESP32.enableWifi(bool)` function controls whether Wi-Fi
hardware support is enabled persistently. Changing it updates ESP32 nonvolatile
state and reboots the board. It is a port-level enable/disable control, not a
replacement for the ordinary runtime `Wifi.connect()`, `Wifi.disconnect()`,
`Wifi.startAP()` and `Wifi.stopAP()` calls.

### `Wifi.scan(callback)`

```javascript
wifi.scan(function (accessPoints) {
  print(accessPoints);
});
```

Purpose: discover visible access points.

On the ESP32 the wrapper:

1. selects station mode, or AP+station mode if an AP is already active;
2. starts the Wi-Fi driver if necessary;
3. calls the non-blocking ESP-IDF scan function; and
4. receives a later scan-complete event, builds the JavaScript access-point
   array and queues the callback.

Scanning needs the station interface, but it does not request association.
After a station-only scan completes, the current ESP32 wrapper may stop the
idle driver while retaining the configured station mode. A later
`Wifi.connect()` must therefore work whether the driver remained started or
received a station-stop event.

Only one scan is allowed at a time. The public API says that scanning enables
station mode and recommends `Wifi.disconnect()` when the application wants it
disabled again.

The generic API documentation describes a `callback(err, accessPoints)`
signature. The current ESP32 implementation queues the access-point array as
the callback's only argument, which is why the focused ESP32 tests use the
single-argument form shown above. This port/API difference is separate from
the empty-array defect.

### `Wifi.connect(ssid, options, callback)`

```javascript
wifi.connect("network", { password:"secret" }, function (error) {
  if (error) print("Connection failed: " + error);
  else print("Network ready: " + JSON.stringify(wifi.getIP()));
});
```

Purpose: act as a station, associate with the named access point and become
ready for IP traffic.

The candidate implementation handles three starting conditions separately:

| Starting condition | Required action |
|---|---|
| Already associated | Disconnect so that the new configuration can be applied, then reconnect through the retry path |
| Station started but not associated | Call `esp_wifi_connect()` immediately |
| Station stopped | Set `g_connectAfterStaStart`, call `esp_wifi_start()`, then consume the flag when the station-start event arrives |

The successful DHCP sequence is:

```text
Wifi.connect()
  -> station starts if required
  -> explicit esp_wifi_connect()
  -> station-associated event
  -> IP-address-acquired event
  -> Wifi.connect() callback receives null
  -> Wifi "connected" event is queued
```

Association and network readiness are deliberately separate:

- `Wifi.on("associated", ...)` reports that the radio joined the AP;
- `Wifi.on("connected", ...)` reports that an IP address is available for
  traffic; and
- the `Wifi.connect()` callback normally completes at the IP-ready stage when
  DHCP is used.

Applications should provide their own timeout for connection attempts. The
public API notes that temporary conditions such as an unavailable AP can cause
retries instead of an immediate final callback.

### `Wifi.disconnect(callback)`

```javascript
wifi.disconnect(function () {
  print("Station disconnected");
});
```

Purpose: end station association and suppress further connection retries.

The candidate clears both the pending one-shot connection request and the
retry counter before asking ESP-IDF to disconnect. For a station-only idle
interface, the event handler subsequently stops the Wi-Fi driver. If AP mode
is also active, the AP must remain available; that combined transition deserves
its own regression coverage because the native mode is still AP+station.

The `Wifi.on("disconnected", ...)` event reports loss of station association.
It may be caused by an explicit disconnect, loss of the AP, authentication
failure or another ESP-IDF reason. It is not the same event as stopping the
station driver.

### `Wifi.startAP(ssid, options, callback)`

```javascript
wifi.startAP("device-network", {
  authMode:"wpa2",
  password:"password",
  channel:6
}, function (error) {
  print(error || wifi.getAPIP());
});
```

Purpose: make the ESP32 advertise an access point to which other stations can
associate.

On classic ESP32, starting an AP while station mode is present selects AP+
station mode. The callback is completed by the later AP-start event. While the
AP is active:

- `Wifi.on("sta_joined", ...)` reports another device associating;
- `Wifi.on("sta_left", ...)` reports it leaving;
- `Wifi.getAPDetails()` reports AP configuration; and
- `Wifi.getAPIP()` reports the AP-side address, normally `192.168.4.1` unless
  changed.

### `Wifi.stopAP(callback)`

```javascript
wifi.stopAP(function () {
  print("Access point stopped");
});
```

Purpose: stop the access-point role without unnecessarily stopping a station
connection.

The classic ESP32 mode transitions are:

| Before | After `Wifi.stopAP()` |
|---|---|
| AP | inactive/null mode |
| AP+station | station mode, preserving the station connection |
| station only | unchanged |

The AP+station lifecycle test confirmed that a classic ESP32 remained
associated, retained its DHCP address and exchanged UDP after its local AP was
stopped.

### `Wifi.save()` And `Wifi.restore()`

```javascript
wifi.connect("network", { password:"secret" }, function (error) {
  if (!error) wifi.save();
});

// Remove the saved Wi-Fi configuration:
wifi.save("clear");
```

Purpose: persist the current station/AP configuration so it can be reapplied
at boot. `Wifi.restore()` applies the saved configuration explicitly and is
normally invoked by ESP32 startup when saved Wi-Fi state is enabled.

The ESP32 restore path:

1. reads the saved `.wificfg` object from Espruino Storage;
2. restores the saved mode and station/AP configuration;
3. starts the Wi-Fi driver; and
4. explicitly calls `esp_wifi_connect()` when the saved mode includes a
   station.

Restore does not rely on the candidate `g_connectAfterStaStart` flag. It was
nevertheless regression-tested because changing the station-start handler
could otherwise introduce a duplicate connection or prevent automatic boot
reconnection. A real hardware-reboot test confirmed restored association,
DHCP and UDP traffic.

### Observation Functions

These functions observe different parts of the lifecycle:

| Function | What it tells the application |
|---|---|
| `Wifi.getStatus()` | Overall reported mode, station status and power-save state |
| `Wifi.getDetails()` | Station configuration and connection details |
| `Wifi.getIP()` | Station IP address, netmask, gateway and MAC address |
| `Wifi.getAPDetails()` | AP configuration and, where supported, associated stations |
| `Wifi.getAPIP()` | AP-side IP address, netmask, gateway and MAC address |

No single observation proves the complete lifecycle. In particular:

- a mode value does not prove association;
- association does not prove DHCP completed;
- an IP snapshot does not prove the peer is reachable; and
- a callback can itself contain a port defect.

The bench tests therefore combine callback results, local status/IP, events
observed by the other board and run-specific UDP traffic.

### `Wifi.setIP()` And `Wifi.setAPIP()`

These configure static addresses for the station and AP interfaces. They do
not start association themselves, but they alter address and DHCP state inside
an active lifecycle.

They are relevant because earlier tests found two shared-port problems:

- the callback result expression was inverted, so native success was reported
  as `"Failure"` and native failure as `null`; and
- the legacy/IDF4 station implementation used the AP DHCP-server stop function
  instead of stopping the station DHCP client, so a post-association static
  address was not applied.

The current IDF5 station path uses the newer ESP-NETIF DHCP-client operation,
but the callback result and complete target-family behavior must be evaluated
separately. Callback success must not be accepted without checking the actual
address and traffic source observed by the peer.

### Other Configuration And Network-Service Functions

`Wifi.setConfig()` changes settings such as Wi-Fi power saving. Functions such
as `Wifi.setHostname()`, `Wifi.getHostByName()` and `Wifi.setSNTP()` configure
or use services around an established station connection. They are relevant to
complete application testing, but they do not replace the station/AP lifecycle
operations described above.

### `Wifi.ping(host, callback)`

`Wifi.ping()` sends ICMP echo requests after network connectivity exists. It
does not control station/AP mode, but it has its own asynchronous native
session lifecycle and therefore depends on a working connection and sufficient
native heap.

The IDF5 merge guarded out the removed legacy `ping_init()` call without
initially providing the modern ESP-IDF ping-session implementation. That is a
separate defect from the scan/connect sequencing issue. The later candidate
uses the socket-based ping API and was evaluated alongside the proposed native
heap increase.

UDP or another application protocol should remain an independent reachability
check. A successful ping does not prove the application service, while a ping
failure accompanied by successful bidirectional UDP points toward an ICMP- or
ping-specific problem.

## Complete Lifecycle Summary

| Espruino request | Normal native lifecycle | Expected completion evidence |
|---|---|---|
| Scan while inactive | select STA; start; scan; scan-done; optionally stop idle driver | non-empty callback when known AP is visible; no peer association |
| Connect while stopped | select/configure STA; mark pending; start; connect from STA_START | associated event, IP-ready callback/event, `getIP()`, peer traffic |
| Connect after scan | station may be started or stopped; connect immediately or start then connect | same evidence as direct connection |
| Connect while AP active | classic: AP to APSTA, then station connect; C3 wrapper may replace AP mode | AP state plus station association/IP as supported by target |
| Connect while already associated | disconnect and reconnect with configured credentials | renewed association/IP and traffic |
| Explicit disconnect | cancel pending/retries; disassociate; stop station-only idle driver | disconnected state and peer departure |
| Stop AP while also a station | APSTA to STA | station IP and traffic preserved; AP no longer advertised |
| AP disappears | bounded native retries; eventually disconnected/idle | disconnected event; no stale traffic claim |
| AP restored after retries | application issues a new `Wifi.connect()` | new association/IP and peer-confirmed traffic |
| Saved station boot | restore configuration; start; explicit native connect | post-reboot association, IP and traffic |

## The Scan/Connect Defect And Its Correction

### Original behavior

The shared station-start event handler used to call `esp_wifi_connect()` every
time it received a station-start event:

```text
STA_START -> esp_wifi_connect()
```

That assumption was incorrect because `Wifi.scan()` also starts the station.
The resulting sequence was:

```text
Wifi.scan()
  -> station starts
  -> STA_START unconditionally starts a connection
  -> scan and connection overlap
  -> ESP-IDF aborts/conflicts with the scan
  -> Espruino reports an empty access-point array
```

The unconditional connection code predates the IDF5 merge. Historical legacy
builds did not show the same bench failure, so the IDF5 driver/timing behavior
exposed a latent sequencing error rather than introducing the unconditional
call itself.

### Why the first guard was insufficient

A first candidate guarded the station-start connection with state set by
`Wifi.connect()`. That prevented scanning from connecting. It still failed
when `Wifi.connect()` was called while the station had already been started by
AP+station operation: calling `esp_wifi_start()` again did not produce another
station-start event, so the pending request was never consumed.

### Final candidate behavior

The candidate now records station start/stop state and handles both cases:

```c
if (g_isStaConnected) {
  esp_wifi_disconnect();       // reconnect through the existing retry path
} else if (g_isStaStarted) {
  esp_wifi_connect();          // driver is ready; do not wait for STA_START
} else {
  g_connectAfterStaStart = true;
  esp_wifi_start();            // STA_START will consume the one-shot request
}
```

The station-start handler becomes conditional:

```c
g_isStaStarted = true;
if (g_connectAfterStaStart) {
  g_connectAfterStaStart = false;
  esp_wifi_connect();
}
```

The station-stop event clears `g_isStaStarted`. An explicit disconnect or
failed driver start clears the one-shot request so it cannot affect a later
scan or connection.

## Lifecycles Covered By The Candidate Validation

The minimum classic `ESP32_IDF5` validation covered:

| Lifecycle | Result |
|---|---|
| Direct connection from idle | Association, DHCP and UDP passed |
| Scan while connected | Known AP found; existing IP and UDP preserved |
| Reconnect while connected | Callback, renewed association and UDP passed |
| Explicit disconnect | IP removed and peer departure observed |
| Scan while disconnected | Known AP found without an unintended connection |
| Connect after scan | Association, DHCP and UDP passed |
| Start AP then connect as station | Classic AP+station mode and peer association passed |
| Stop AP while connected as station | Station IP and UDP preserved |
| Cancel then repeat | Final disconnected state followed by five successful connect/UDP/disconnect cycles |
| Save and hardware reboot | Saved station association, DHCP and UDP restored |
| Controlled AP loss and restoration | Loss observed; explicit reconnect and UDP passed after restoration |

These results establish the intended behavior on the tested classic IDF5
candidate. The final rebased correction then received the following
cross-family coverage:

| Target | Validation scope | Result |
|---|---|---|
| Classic `ESP32_IDF5` | Controlled clean-master versus rebased-candidate scan comparison, plus the complete lifecycle table above | Clean master returned 0 APs twice; the candidate returned 15 and 13 APs, found the controlled AP once in each run and did not connect during either scan |
| Classic legacy `ESP32` | Direct connection, connected scan, reconnect, disconnect and idle shutdown, disconnected scan, and connection after scan | 15 checks passed with four independently observed UDP exchanges |
| `ESP32C3_IDF4` | The same station-transition lifecycle | 15 checks passed with four independently observed UDP exchanges |
| `ESP32S3_IDF5` | Focused connect, completed disconnect/idle shutdown, then scan from the stopped station | Exact base returned 0 APs; the candidate returned 10 APs, found the expected AP once and did not connect during the scan |
| Classic/C3/S3 IDF4 and IDF5 plus classic legacy | Clean release compilation | All seven ESP32 board configurations built successfully |

The valid S3 comparison used the board's selected external antenna connection
with its antenna fitted. The broader S3 lifecycle is not counted as a complete
pass: reconnecting while already associated stalled on both exact clean base
and candidate firmware. That makes it a separate, pre-existing S3 lifecycle
observation rather than evidence against this correction. One candidate run
did complete the entire S3 lifecycle, but the inconsistent base-and-candidate
behavior requires its own investigation.

Runtime coverage therefore exercises the shared correction on classic legacy,
classic IDF5, C3 IDF4 and the focused S3 IDF5 failure path. Classic IDF4, C3
IDF5 and S3 IDF4 remain compile-qualified for this change. The deliberately
retained C3 AP/station role-replacement workaround also remains outside this
correction and should be evaluated separately across C3 IDF4 and IDF5.

## Other Identified Wi-Fi Issues And Their Lifecycle Position

| Issue | Lifecycle involved | Relationship to this correction |
|---|---|---|
| Empty IDF5 scan result | Station startup and scan | Directly addressed by separating start from connect request |
| Connect after scan or from an active AP | Already-started station | Directly addressed by `g_isStaStarted` and immediate connect |
| `setIP()` does not apply the requested address on tested legacy/IDF4 builds | DHCP-to-static address transition | Separate worker/API defect |
| `setIP()` / `setAPIP()` callback result inversion | Address-configuration completion | Separate callback defect |
| Directional C3-to-classic `Wifi.ping()` failure | ICMP after IP-ready state | Separate open endpoint-attribution issue; UDP still works |
| Missing IDF5 ping mechanism | ICMP session creation | Separate modernization defect and native-heap consideration |
| Classic resets after some post-`setIP()` sequences | Address change followed by ping/UDP | Open; minimal trigger not yet isolated |
| S3 reconnect can stall after a connected scan | Reconnect while already associated | Separate pre-existing S3 behavior; reproduced on exact clean base and candidate |
| C3 ordinary AP/station transitions replace the other role | AP and station mode transition | Retained target-specific workaround; deferred for separate IDF4/IDF5 validation |
| Scan-start/status errors are not fully surfaced | Native scan completion | Separate robustness question; immediate scan-start return and completion status need review |

The detailed evidence is retained in:

- [`esp32-idf5-scan-empty-2026-09-14.md`](esp32-idf5-scan-empty-2026-09-14.md)
- [`ip-configuration-api-2026-07-20.md`](ip-configuration-api-2026-07-20.md)
- [`directional-ping-asymmetry-2026-07-20.md`](directional-ping-asymmetry-2026-07-20.md)
- [`classic-post-setip-reset-2026-07-20.md`](classic-post-setip-reset-2026-07-20.md)

## Practical Rules For Espruino Applications And Tests

1. Treat `Wifi.connect()` as asynchronous and continue network work only after
   its successful callback or the `connected` event.
2. Do not treat station mode or a completed scan as proof of association.
3. Use `associated` for radio-link evidence and `connected`/`getIP()` for
   IP-readiness evidence.
4. Use peer-observed application traffic as the final end-to-end check.
5. After a connection attempt has exhausted its retries, issue a new
   `Wifi.connect()` when the AP becomes available again.
6. Use `Wifi.disconnect()` to cancel pending station activity and clear retry
   intent; use `Wifi.stopAP()` separately to end the AP role.
7. Verify both callback result and actual interface state when testing
   `setIP()` or `setAPIP()`.
8. Keep ping results separate from general reachability results.
9. Test AP+station behavior per target; do not infer classic ESP32 behavior for
   the ESP32-C3.
10. When changing the native event handler, test every operation capable of
    starting or stopping the station, not just the originally failing API.

## References

- [Espruino `Wifi` API reference](https://www.espruino.com/Reference#Wifi)
- [ESP-IDF 5.5.2 Wi-Fi driver API](https://docs.espressif.com/projects/esp-idf/en/v5.5.2/esp32/api-reference/network/esp_wifi.html)
- [ESP-IDF scan example](https://github.com/espressif/esp-idf/tree/v5.5.2/examples/wifi/scan)
- [MicroPython ESP32 WLAN implementation](https://github.com/micropython/micropython/blob/master/ports/esp32/network_wlan.c)

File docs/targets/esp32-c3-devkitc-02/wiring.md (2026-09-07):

# ESP32-C3-DevKitC-02 Harness Wiring Spec

This document maps the common harness blocks onto the Espressif
ESP32-C3-DevKitC-02.

The current schematic PDFs are in:

```text
Hardware/ESP32_C3/
```

Related documents:

- [docs/design/common-harness-design-and-blocks.md](../../design/common-harness-design-and-blocks.md)
- [docs/design/harness-modes.md](../../design/harness-modes.md)
- [docs/design/connectivity-permutations.md](../../design/connectivity-permutations.md)

## Block Mapping

This target wiring document follows the family distinction between:

- `block`: a logical hardware capability grouping
- `mode`: a target-specific harness configuration that enables one or more
  blocks
- `test`: a validation task that may use one block or multiple blocks

For the ESP32-C3 harness, the block mapping is:

| Block | Block name | Practical target meaning |
|---:|---|---|
| 1 | `gpio_block` | loopbacks on `D1/D2` and `D3/D4` in baseline GPIO mode |
| 2 | `analog_block` | `D8 -> ANALOG_FB -> D0` |
| 3 | `i2c_block` | MCP23008 on `D1/D4` with feedback on `D2` and interrupt on `D10` |
| 4 | `spi_block` | MCP3008 on `D3/D5/D6/D7` |
| 5 | `onewire_block` | DS18B20 bus on `D0` selected away from `ANALOG_FB` |
| 6 | `onewire_gpio_block` | not fitted on the current C3 harness revision |
| 7 | `uart_block` | UART0/UART1 crosslink using `D3/D4` and `D20/D21` through `J10` |
| 8 | `grove_i2c_block` | external Grove I2C device on the same `D1/D4` bus |

The important consequence is that modes do not need a one-to-one relationship
with blocks. For example, `C3_I2C` is a primarily I2C-focused mode, while
`C3_BUS_SPI_I2C` is a combined mode that enables blocks 3 and 4 at
the same time.

Block 6 remains part of the family numbering even though the current
ESP32-C3 harness does not implement a DS2413-style OneWire GPIO extension.

## Board Under Test

| Item | Value |
|---|---|
| Board | ESP32-C3-DevKitC-02 |
| Module | ESP32-C3-WROOM-02 |
| Pin naming in tests | `Dxx`, matching GPIO number |
| Normal board USB | USB-UART bridge to UART0 |
| Native USB Serial/JTAG | `D18` / `D19`, via harness USB D-/D+ connection |

## Reserved Connectivity Pins

These pins are not general harness GPIO in the default design.

| Pin | Function | Harness rule |
|---:|---|---|
| `D18` | native USB D- | connect to native USB D- block |
| `D19` | native USB D+ | connect to native USB D+ block |
| `D20` | UART0 RX | reserve for board USB-UART REPL/flashing; selector-used only in UART0/UART1 crosslink mode |
| `D21` | UART0 TX | reserve for board USB-UART REPL/flashing; selector-used only in UART0/UART1 crosslink mode |
| `D9` | boot/download button path | reserve for boot/download control only |
| `D8` | onboard RGB LED / strapping | used only as `PWM_OUT` through 10k series resistance; no fixed pull |

## Default Connectivity Wiring

The ESP32-C3-DevKitC-02 already has a USB connector on the board. That board
USB path goes through the onboard USB-UART bridge to UART0, and it is expected
to be the normal REPL/flashing/control connection for most automated tests.

The harness additionally provides a separate native USB Serial/JTAG connector.
This is not the normal board USB-UART path. It wires directly to the ESP32-C3
native USB pins so phase-one testing can prove the direct USB Serial/JTAG
function independently.

| Board pin / signal | Harness connection | Notes |
|---|---|---|
| Board Micro-USB | host USB | UART0 REPL/flashing path |
| `D18` | fixed wire to native USB/JTAG connector D- | native USB Serial/JTAG |
| `D19` | fixed wire to native USB/JTAG connector D+ | native USB Serial/JTAG |
| GND | native USB/JTAG connector GND and harness GND | common ground |
| VBUS | native USB/JTAG connector VBUS through inline shunt | optional host 5 V feed; default shunt state to be marked |
| EN / reset | automation header `RESET` | also keep manual reset accessible |
| Boot/download path | automation header `BOOT` | expected to control board boot/download path |

In this harness revision, `D18` and `D19` are used only by the additional
harness native USB Serial/JTAG connector. They are not part of the board
USB-UART path, and they are not shared with peripheral test blocks:
`D18` / GPIO18 is fixed-wired to the harness connector USB D-, and
`D19` / GPIO19 is fixed-wired to the harness connector USB D+.

Use a four-position screw connector for the harness USB Serial/JTAG cable:

| Connector pin | Signal | Harness connection |
|---|---|---|
| 1 | USB GND | harness GND |
| 2 | USB VBUS | inline shunt to harness/board 5 V rail |
| 3 | USB D- | fixed wire to `D18` |
| 4 | USB D+ | fixed wire to `D19` |

The VBUS connection must be shunt-selectable so the harness can be tested with
the native USB/JTAG connector providing signalling only, or with VBUS connected
when that is explicitly desired. This is not a switched 5 V power subsystem;
it is an inline VBUS link for the native USB/JTAG connector.

## Selector-Based GPIO Allocation

The ESP32-C3 has limited spare GPIO once UART0, native USB Serial/JTAG, boot
control, and strapping safety are respected. This harness therefore does not
wire every test function to a dedicated pin. Instead, several C3 GPIOs are
routed through labelled selector blocks.

A selector block lets one GPIO serve one of several test roles. Only one shunt
should be fitted per selector at a time. The mode tables later in this document
state which selector positions are required for each test mode.

## Schematic Selector Bank

The schematic is the master wiring definition for the C3 harness. Multi-use
GPIOs use dual-row selector headers with the MCU GPIO repeated on row A and
the selectable function nets on row B. Fit one vertical shunt only per selector.

| Selector | Header | Row A common | Row B options | Notes |
|---|---:|---|---|---|
| `SEL_D0` | 2x02 | `GPIO0` on `a1`, `a2` | `b1` = `ONEWIRE_DQ`; `b2` = `ADC_IN` via `ANALOG_FB` | `ADC_IN` is the user-facing role; it connects D0 to the `ANALOG_FB` net |
| `SEL_D1` | 2x02 | `GPIO1` on `a1`, `a2` | `b1` = `I2C_A_SDA`; `b2` = loop A output via `R5` | `b2` loops to `SEL_D2 b2` through 470R |
| `SEL_D2` | 2x02 | `GPIO2` on `a1`, `a2` | `b1` = `I2C_A_FB`; `b2` = loop A input via `R5` | `I2C_A_FB` is MCP23008 GP0 feedback through `R2` |
| `SEL_D3` | 2x03 | `GPIO3` on `a1`, `a2`, `a3` | `b1` = `SPI_MISO`; `b2` = loop B output via `R7`; `b3` = `D3_UART1_TX` | UART1 TX route for crosslink mode |
| `SEL_D4` | 2x03 | `GPIO4` on `a1`, `a2`, `a3` | `b1` = `I2C_A_SCL`; `b2` = loop B input via `R7`; `b3` = `D4_UART1_RX` | UART1 RX route for crosslink mode |
| `SEL_D10` | 2x02 | `GPIO10` on `a1`, `a2` | `b1` = `I2C_INT`; `b2` = `SPI_CS_FLASH` | selects MCP23008 interrupt or optional flash CS |
| `J10` / `SEL_UART0_UART1` | 2x03 | `a1` = `D20_UART0_RX` via `R6`; `a2` = `D21_UART0_TX` via `R8`; `a3` = GND | `b1` = `D3_UART1_TX`; `b2` = `D4_UART1_RX`; `b3` = GND | fit both signal shunts only for UART0/UART1 crosslink testing; GND pins support external UART access |
| `SEL_D08` | 1x02 | `GPIO8` / `PWM_OUT` | `R3` 10k to `ANALOG_FB` | single safety jumper; default open for safest boot |

Schematic net names use the `I2C_A_` prefix for the primary I2C block. In test
descriptions, `I2C_SDA`, `I2C_SCL`, and `I2C_FB` refer to `I2C_A_SDA`,
`I2C_A_SCL`, and `I2C_A_FB` respectively.

## C3 GPIO Test Role Allocation

The table below lists the approved C3 test roles for each GPIO. For
selector-controlled pins, the roles are alternatives selected by the named
selector; they are not
simultaneously connected.

| C3 pin | Harness roles | Selector / wiring | Notes |
|---:|---|---|---|
| `D0` / GPIO0 | `ADC_IN`, `ONEWIRE_DQ` | `SEL_D0` | ADC position connects to `ANALOG_FB`; OneWire position isolates `ANALOG_FB` from the OneWire bus |
| `D1` / GPIO1 | `I2C_SDA`, `GPIO_LOOP_A_OUT` | `SEL_D1` | `I2C_A_SDA` or loop A output through `R5` |
| `D2` / GPIO2 | `I2C_FB`, `GPIO_LOOP_A_IN` | `SEL_D2` | strapping pin; no fixed pull; loop/I2C feedback through resistors |
| `D3` / GPIO3 | `SPI_MISO`, `GPIO_LOOP_B_OUT`, `UART1_TX` | `SEL_D3` | SPI MISO, loop B output through `R7`, or UART1 TX for crosslink mode |
| `D4` / GPIO4 | `I2C_SCL`, `GPIO_LOOP_B_IN`, `UART1_RX` | `SEL_D4` | I2C clock, loop B input through `R7`, or UART1 RX for crosslink mode |
| `D5` / GPIO5 | `SPI_MOSI` | fixed wire | fixed SPI bus wiring |
| `D6` / GPIO6 | `SPI_SCK` | fixed wire | fixed SPI bus wiring |
| `D7` / GPIO7 | `SPI_CS_ADC` | fixed wire | MCP3008 chip select |
| `D8` / GPIO8 | `PWM_OUT` | `SEL_D08` safety jumper | strapping/RGB LED pin; only through 10k to `ANALOG_FB`; default open |
| `D9` / GPIO9 | BOOT automation | fixed automation header wiring | boot/download control only |
| `D10` / GPIO10 | `I2C_INT`, `SPI_CS_FLASH` | `SEL_D10` | MCP23008 interrupt or optional flash chip select |
| `D18` / GPIO18 | native USB D- | fixed wire to `J1` | reserved for native USB Serial/JTAG |
| `D19` / GPIO19 | native USB D+ | fixed wire to `J1` | reserved for native USB Serial/JTAG |
| `D20` / GPIO20 | UART0 RX | `J10` / `SEL_UART0_UART1` via `R6` only | reserved by default; used only for UART0/UART1 crosslink or deliberate external UART access |
| `D21` / GPIO21 | UART0 TX | `J10` / `SEL_UART0_UART1` via `R8` only | reserved by default; used only for UART0/UART1 crosslink or deliberate external UART access |

## Permanent Wiring

These connections are either permanent or built as the fixed/default selector
paths because they do not create unmanaged mode conflicts.

| Connection | Notes |
|---|---|
| `D18` -> native USB D- | default phase-one requirement |
| `D19` -> native USB D+ | default phase-one requirement |
| `D20` / `D21` reserved by default | selector-connected only through `J10` / `SEL_UART0_UART1` for deliberate UART0/UART1 crosslink or external UART access |
| `D5` -> `SPI_MOSI` | fixed SPI bus wiring |
| `D6` -> `SPI_SCK` | fixed SPI bus wiring |
| `D7` -> `SPI_CS_ADC` | fixed MCP3008 chip-select wiring |
| `D8` -> `SEL_D08` -> 10k -> `ANALOG_FB` | single safety jumper; no fixed pull on strapping pin |
| 3.3 V and GND rails | common harness rails |
| reset and boot lines to automation header | manual/automation access |

`D8` is a strapping pin and also drives the onboard RGB LED. The harness must
not add a fixed pull-up or pull-down. The only normal external load is the 10k
series path into `ANALOG_FB`, which may be opened with a jumper if bring-up
shows any boot sensitivity.

`D0` is the common row of `SEL_D0`. One shunt position selects `ADC_IN` by
connecting `D0` to `ANALOG_FB` for ADC/PWM/SPI analog tests. The other shunt
position connects `D0` to `ONEWIRE_DQ` for DS18B20 tests. Do not fit both shunts:
`ANALOG_FB` has the RC smoothing capacitor and MCP3008 CH0 load, which should
be isolated from the OneWire bus.

## Harness Test Modes

The following sections define the manual harness modes used by the test
runner. Each mode lists the required selector positions and any conflicting
selector positions that must not be fitted.

### Connectivity UART0 Mode

Mode name:

- `C3_CONNECTIVITY_UART0`

Purpose:

- prove the normal board USB-UART path through UART0
- provide the default flashing and control path for repeated test runs

Runner/control path:

- board USB-UART through the board Micro-USB connector on `D20` / `D21`

Required selector positions / wiring:

| Selector or wiring | Position |
|---|---|
| board USB-UART path | left untouched |
| `J10` / `SEL_UART0_UART1` | no signal shunts fitted |
| `SEL_D3` / `SEL_D4` UART positions | not fitted |
| BOOT and RESET access | available for flashing and reset tests |

Compatible selector positions:

| Selector group | Allowed state |
|---|---|
| baseline loopback positions on `SEL_D1`, `SEL_D2`, `SEL_D3`, and `SEL_D4` | may remain fitted |
| native USB Serial/JTAG wiring on `D18` / `D19` | may remain physically wired, but is not the runner/control path in this mode |

Enabled coverage:

- REPL attach over the normal board USB-UART path
- reset and reconnect
- flashing with the harness attached

### Baseline GPIO Mode

Mode name:

- `C3_BASELINE_GPIO`

Purpose:

- enable block 1 GPIO loopback testing
- preserve a safe default state for the shared analog, I2C, SPI, and UART
  selector paths

Required selector positions / wiring:

| Selector or wiring | Position |
|---|---|
| `SEL_D1` | shunt `GPIO1` to loop A output, `a2-b2` |
| `SEL_D2` | shunt `GPIO2` to loop A input, `a2-b2` |
| loop A resistor | `SEL_D1 b2` -> `R5` 470R -> `SEL_D2 b2` |
| `SEL_D3` | shunt `GPIO3` to loop B output, `a2-b2` |
| `SEL_D4` | shunt `GPIO4` to loop B input, `a2-b2` |
| loop B resistor | `SEL_D3 b2` -> `R7` 470R -> `SEL_D4 b2` |

Open/conflicting selector positions:

| Selector group | Required state |
|---|---|
| `SEL_D1` / `SEL_D2` I2C positions | not fitted |
| `SEL_D3` SPI or UART position | not fitted |
| `SEL_D4` I2C or UART position | not fitted |
| `SEL_D08` analog/PWM path | open unless analog/PWM testing is active |
| `SEL_D0` OneWire position | not fitted |

Notes:

- `D2` is accepted as a strapping pin only because it has no fixed pull and is
  used through resistor-protected/manual-mode wiring.
- Physical loopback wiring should be `D1 -> 470R -> D2` and
  `D3 -> 470R -> D4`.

Enabled coverage:

- block 1 GPIO loopback behavior
- `pinMode`, `digitalWrite`, `digitalRead`, `digitalPulse`, and `setWatch`
  coverage on the baseline loopback pairs

### Analog/PWM Mode

Mode name:

- `C3_ANALOG_PWM`

Purpose:

- enable block 2 analog and PWM feedback testing
- connect `D0` to the filtered `ANALOG_FB` node while keeping OneWire isolated

Required selector positions / wiring:

| Selector or wiring | Position |
|---|---|
| `SEL_D08` | closed after safe boot if PWM feedback is being run |
| `PWM_OUT` -> 10k -> `ANALOG_FB` | permanent |
| `ANALOG_FB` -> 0.1uF -> GND | permanent |
| `SEL_D0` | select `ADC_IN`: shunt `GPIO0` to `ANALOG_FB`, `a2-b2` |
| `ANALOG_FB` -> MCP3008 CH0 | closed/permanent if MCP3008 fitted |

Boot-safety requirement:

- no direct `D8` pull-up or pull-down
- no low-value LED/test load from `D8` to either rail
- if fitted, a `D8` -> `PWM_OUT` jumper should default open until the board has
  booted cleanly with the harness attached

Test note:

- `D0` analog feedback behavior must be confirmed during bring-up.
- PWM-generated `ANALOG_FB` can be read by both target ADC on `D0` and MCP3008
  CH0 over SPI in `C3_BUS_SPI_I2C`.
- OneWire tests require the `D0` selector to move away from `ANALOG_FB`.

Enabled coverage:

- block 2 `analogRead` low/high level checks
- block 2 PWM or `analogWrite` feedback into the target ADC
- target-side ADC preparation for optional MCP3008 comparison in combined
  block 3 plus block 4 mode

### I2C Mode

Mode name:

- `C3_I2C`

Purpose:

- enable block 3 I2C testing on the primary MCP23008 path
- optionally keep the Grove I2C extension available on the same bus

Required selector positions / wiring:

| Selector or wiring | Position |
|---|---|
| `SEL_D1` | shunt `GPIO1` to `I2C_A_SDA`, `a1-b1` |
| `SEL_D4` | shunt `GPIO4` to `I2C_A_SCL`, `a1-b1` |
| `SEL_D10` | shunt `GPIO10` to `I2C_INT`, `a1-b1` |
| `SEL_D2` | shunt `GPIO2` to `I2C_A_FB`, `a1-b1`, if feedback tests are run |
| I2C SDA/SCL pull-ups | provided by attached I2C module(s) for this revision |

Open/conflicting selector positions:

| Selector group | Required state |
|---|---|
| `SEL_D1` / `SEL_D2` loopback positions | not fitted |
| `SEL_D3` / `SEL_D4` UART crosslink positions | not fitted |
| `SEL_D4` loopback position | not fitted |

Enabled coverage:

- block 3 MCP23008 register read/write
- block 3 GP0 feedback through `D2`
- block 3 INT through `D10`
- block 8 external Grove I2C devices on the same bus where fitted
- `setWatch` on expander feedback/interrupt where supported

### Combined SPI/I2C Bus Mode

Mode name:

- `C3_BUS_SPI_I2C`

Purpose:

- provide one practical harness mode that enables block 3 I2C and
  block 4 SPI concurrently
- verify Espruino SPI pin mapping and transfer behavior using the MCP3008
- verify Espruino I2C pin mapping and MCP23008 operation in the same physical
  harness mode
- exercise both bus APIs without moving jumpers between separate I2C and SPI
  selector states

Required selector positions / wiring:

| Selector or wiring | Position |
|---|---|
| `SEL_D1` | shunt `GPIO1` to `I2C_A_SDA`, `a1-b1` |
| `SEL_D4` | shunt `GPIO4` to `I2C_A_SCL`, `a1-b1` |
| `SEL_D10` | shunt `GPIO10` to `I2C_INT`, `a1-b1` |
| `SEL_D2` | shunt `GPIO2` to `I2C_A_FB`, `a1-b1`, if feedback tests are run |
| `SEL_D08` | closed after boot if PWM-to-ADC/SPI comparison is being run |
| `SEL_D0` | select `ADC_IN`: shunt `GPIO0` to `ANALOG_FB`, `a2-b2`, if target ADC comparison is run |
| `SEL_D3` | shunt `GPIO3` to `SPI_MISO`, `a1-b1` |
| `D5` -> `SPI_MOSI` | closed |
| `D6` -> `SPI_SCK` | closed |
| `D7` -> `SPI_CS_ADC` | closed |
| MCP3008 CH0 -> `ANALOG_FB` | closed |
| I2C SDA/SCL pull-ups | provided by attached I2C module(s) for this revision |

ESP32-C3 harness wiring:

| ESP32-C3 pin | Harness node | Peripheral connection |
|---|---|---|
| `D1` / GPIO1 | `I2C_SDA` | MCP23008 `SDA`; Grove `SDA` |
| `D4` / GPIO4 | `I2C_SCL` | MCP23008 `SCL`; Grove `SCL` |
| `D10` / GPIO10 | `I2C_INT` | MCP23008 `INT` |
| `D2` / GPIO2 | `I2C_FB` | MCP23008 `GP0` via 470R |
| `D8` / GPIO8 | `PWM_OUT` | 10k to `ANALOG_FB`; no fixed pull |
| `D0` / GPIO0 | `ADC_IN` selector common | select to `ANALOG_FB` for target ADC comparison |
| `D3` / GPIO3 | `SPI_MISO` | MCP3008 `DOUT`; optional W25xxx `DO` |
| `D5` / GPIO5 | `SPI_MOSI` | MCP3008 `DIN`; optional W25xxx `DI` |
| `D6` / GPIO6 | `SPI_SCK` | MCP3008 `CLK`; optional W25xxx `CLK` |
| `D7` / GPIO7 | `SPI_CS_ADC` | MCP3008 `CS/SHDN` |

MCP3008 wiring detail:

| MCP3008 PDIP pin | Function | Connection |
|---:|---|---|
| 16 | `VDD` | `3V3` |
| 15 | `VREF` | `3V3` |
| 14 | `AGND` | GND |
| 9 | `DGND` | GND |
| 13 | `CLK` | `SPI_SCK` |
| 12 | `DOUT` | `SPI_MISO` |
| 11 | `DIN` | `SPI_MOSI` |
| 10 | `CS/SHDN` | `SPI_CS_ADC` |
| 1 | `CH0` | `ANALOG_FB` |
| 2-8 | `CH1`-`CH7` | no connection for first revision, or optional analog test header |

Open/conflicting selector positions:

| Selector group | Required state |
|---|---|
| loopback selector positions on `SEL_D1`, `SEL_D2`, `SEL_D3`, `SEL_D4` | not fitted |
| `SEL_D08` analog/PWM drive | close only after confirming boot safety |
| `SEL_D0` OneWire position | not fitted |
| UART crosslink positions on `SEL_D3` / `SEL_D4` | not fitted |
| `SEL_D10` flash-CS position | not fitted while `GPIO10` is used for `I2C_INT` |

Enabled coverage:

- block 4 MCP3008 transfer/read
- block 3 MCP23008 register read/write
- block 3 MCP23008 feedback and interrupt behavior
- block 8 external Grove I2C devices on the same bus where fitted
- concurrent SPI and I2C operation in one manual harness mode

### SPI Flash Extended Mode

Mode name:

- `C3_SPI_FLASH_EXTENDED`

This optional mode reuses the SPI bus above but moves `D10` from `I2C_INT` to
`SPI_CS_FLASH`. It is not part of the first combined SPI/I2C bus mode.

Required selector change from `C3_BUS_SPI_I2C`:

| Selector or wiring | Position |
|---|---|
| `SEL_D10` | move shunt from `I2C_INT` `a1-b1` to `SPI_CS_FLASH` `a2-b2` |

Enabled coverage:

- optional W25xxx JEDEC/status
- shared-bus chip-select behavior with MCP3008

### OneWire Mode

Mode name:

- `C3_ONEWIRE`

Purpose:

- enable block 5 OneWire testing on `D0`
- isolate `D0` from the analog feedback node while the OneWire bus is active

Required selector positions / wiring:

| Selector or wiring | Position |
|---|---|
| `SEL_D0` | shunt `GPIO0` to `ONEWIRE_DQ`, `a1-b1` |
| `ONEWIRE_DQ` -> 4.7k -> 3.3 V | fitted |
| DS18B20 A DQ -> `ONEWIRE_DQ` | closed/permanent within OneWire block |
| DS18B20 B DQ -> `ONEWIRE_DQ` | closed/permanent within OneWire block |

Open/conflicting selector positions:

| Selector group | Required state |
|---|---|
| `SEL_D0` analog feedback position | not fitted |
| analog filtered node / MCP3008 CH0 load | isolated from `D0` by selector |

Compatible selector positions:

| Selector group | Allowed state |
|---|---|
| I2C links on `D1`, `D4`, `D10`, and `D2` | may remain closed for combined I2C + OneWire tests |

Enabled coverage:

- two-device search
- addressed DS18B20 selection
- scratchpad read
- temperature conversion
- optional I2C display/logging of temperature readings while OneWire is active

These are block 5 behaviours. The current C3 harness does not add a
block 6 DS2413-style OneWire GPIO extension.

### UART0/UART1 Crosslink Mode

Mode name:

- `C3_SERIAL_UART0_UART1_CROSSLINK`

Purpose:

- prove non-console `Serial` API behavior on a second UART mapping
- deliberately exercise UART0 ownership while the runner controls/monitors the
  DUT through native USB Serial/JTAG
- avoid needing an external USB-UART peer for the C3 serial test

Required selector positions / wiring:

| Selector or wiring | Position |
|---|---|
| Runner/control path | native USB Serial/JTAG on `D18` / `D19` |
| `SEL_D3` | shunt `GPIO3` to `D3_UART1_TX`, `a3-b3` |
| `SEL_D4` | shunt `GPIO4` to `D4_UART1_RX`, `a3-b3` |
| `J10` / `SEL_UART0_UART1` column 1 | fit only after isolating the DevKitC-02 CP2102N TX path: `D3_UART1_TX` -> `D20_UART0_RX` through `R6` |
| `J10` / `SEL_UART0_UART1` column 2 | fit shunt: `D21_UART0_TX` -> `D4_UART1_RX` through `R8` |
| `J10` / `SEL_UART0_UART1` column 3 | GND/GND; available as common ground for external UART access |

Open/conflicting selector positions:

| Selector group | Required state |
|---|---|
| loopback positions on `SEL_D3` / `SEL_D4` | not fitted |
| `SEL_D3` SPI MISO position | not fitted |
| `SEL_D4` I2C SCL position | not fitted |
| `SEL_D0` OneWire position | not fitted unless combining intentionally |
| board USB-UART control path | do not use as the runner/control path while UART0 is under test |

External UART access:

- with the two signal shunts open, `J10` can also be used as an external UART
  access connector for either side of the UART test block.
- the two GND pins on column 3 provide a local common reference for an external
  USB-UART adapter or test instrument.

DevKitC-02 onboard USB-UART limitation:

- the fitted DevKitC-02 schematic powers its CP2102N from `VCC_3V3` and joins
  CP2102N TXD to `U0RXD` through zero-ohm resistor `R21`;
- neither disconnecting the board USB-UART cable while using external 5 V nor
  powering the board through its onboard USB connection releases `D20`;
  bench testing in both arrangements found `D20` held high even against the
  ESP32-C3 internal pull-down;
- do not fit `J10` column 1 and drive `D3_UART1_TX` against that active output;
  a full two-way UART0/UART1 crosslink requires deliberate isolation of the
  CP2102N TX path;
- for non-destructive native-USB validation of UART setup/unsetup, use the
  loop-B path instead: open both `J10` signal columns, set `SEL_D3=a2-b2` and
  `SEL_D4=a2-b2`, then configure one UART with TX `D3` and RX `D4`.

Enabled coverage:

- `Serial.setup` on UART0 and UART1-capable mappings
- TX/RX transfer across the crossed UART pair
- `Serial.read`
- `Serial.on("data")`
- `Serial.unsetup` / re-setup
- detection of console/ownership conflicts between UART0 and the selected REPL
  path

### Native USB Serial/JTAG Mode

Mode name:

- `C3_CONNECTIVITY_USB_SERIAL_JTAG`

Required selector positions / wiring:

| Selector or wiring | Position |
|---|---|
| `D18` -> native USB/JTAG connector D- | fixed wire |
| `D19` -> native USB/JTAG connector D+ | fixed wire |
| native USB/JTAG connector GND -> harness GND | fixed wire |
| native USB/JTAG connector VBUS -> 5 V rail | inline shunt, fit only when VBUS feed is wanted |

Open/conflicting selector positions:

| Selector group | Required state |
|---|---|
| any peripheral use of `D18` / `D19` | not allowed in phase-one default design |

Enabled coverage:

- native USB Serial/JTAG enumeration
- native USB serial REPL if firmware exposes it
- reset/reconnect behavior
- flashing/debug path if supported by selected tooling

### Power Reset Mode

Mode name:

- `C3_POWER_RESET`

Purpose:

- prove reset, bootloader entry, watchdog reset, and later controlled power
  behaviour using the harness control provisions

Runner/control path:

- board USB-UART on `D20` / `D21` or native USB Serial/JTAG on `D18` / `D19`,
  depending on which recovery path is under test

Required selector positions / wiring:

| Selector or wiring | Position |
|---|---|
| automation header | connected or manually accessible for RESET and BOOT control |
| board USB-UART path | available for normal reconnect and flashing checks |
| native USB Serial/JTAG wiring | available for native reconnect and flashing checks |
| `J10` / `SEL_UART0_UART1` | no signal shunts fitted unless a deliberate serial-crosslink combination is under test |

Open/conflicting selector positions:

| Selector group | Required state |
|---|---|
| UART0/UART1 crosslink wiring | leave open unless deliberately combining reset testing with the serial-crosslink mode |

Enabled coverage:

- reset reconnect on the normal UART0 path
- reset reconnect on the native USB Serial/JTAG path
- bootloader entry and flashing
- watchdog reset recovery

## Automation Header

The automation header is a provision for later repeatable reset and
boot/download control. It does not automate the harness by itself: a future
runner controller or external interface will be required to pull these lines to
the required states under software control.

Minimum C3 automation header:

| Header pin | C3/board signal | Purpose |
|---|---|---|
| GND | GND | common reference |
| RESET | EN / reset | reset control |
| BOOT | boot/download path | download-mode selection |

5 V power switching is not required for this first harness. Native USB/JTAG
VBUS is provided through a simple inline shunt, not through a power switch.

## Default Jumper State

Default state means the safe starting configuration after assembly, before a
specific test mode has been selected. It should allow the DUT to boot normally,
preserve the board USB-UART path for the usual REPL/flashing connection, keep the
harness USB Serial/JTAG connector wired but not force it to power the board, and
support the baseline GPIO loopback tests.

Permanent wiring, no shunt required:

| Wiring | Default state |
|---|---|
| Board USB-UART path | left untouched; use the ESP32-C3-DevKitC-02 USB connector for normal REPL/flashing |
| Harness USB Serial/JTAG data | `D18` / GPIO18 wired to harness USB `D-`; `D19` / GPIO19 wired to harness USB `D+` |
| SPI fixed lines | `D5` / GPIO5 to `SPI_MOSI`, `D6` / GPIO6 to `SPI_SCK`, `D7` / GPIO7 to `SPI_CS_ADC` |
| Automation header | available, but inactive unless an external runner/controller is connected |

Default fitted shunts:

| Selector | Default position | Purpose |
|---|---|---|
| `SEL_D1` | `a2-b2` | `D1` / GPIO1 to loopback A output |
| `SEL_D2` | `a2-b2` | `D2` / GPIO2 to loopback A input |
| `SEL_D3` | `a2-b2` | `D3` / GPIO3 to loopback B output |
| `SEL_D4` | `a2-b2` | `D4` / GPIO4 to loopback B input |

Default open / not fitted:

| Selector or shunt | Default state | Reason |
|---|---|---|
| `SEL_D0` | no shunt fitted | choose `ONEWIRE_DQ` or `ADC_IN` only for the relevant test mode |
| `SEL_D08` | open | keeps the `D8` / GPIO8 PWM drive path disconnected until analog feedback tests |
| `SEL_D10` | no shunt fitted | choose `I2C_INT` or `SPI_FLASH_CS` only for the relevant test mode |
| `SEL_D3` / `SEL_D4` UART positions | not fitted | UART crosslink testing is a deliberate mode, not the baseline |
| `J10` / `SEL_UART0_UART1` | no signal shunts fitted | keeps UART0 pins reserved for board USB-UART unless crosslink or external UART access is active |
| `JP1` harness USB VBUS shunt | open unless intentionally using harness USB VBUS | avoids an unintended 5 V feed into the board/harness rail |
| `JP12` external 5 V shunt | open unless intentionally using external 5 V input | avoids an unintended 5 V feed into the board/harness rail |

Do not fit `JP1` and `JP12` together unless the power-source arrangement has
been deliberately reviewed. Test-runner prompts should name the required selector
positions before each non-default mode is run.

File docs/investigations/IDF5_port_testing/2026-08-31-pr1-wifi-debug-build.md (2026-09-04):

# PR 1: Fix the ESP32 IDF5 Wi-Fi Debug Build

## Upstream Outcome

Merged as Espruino PR `#2733` by commit `6ad8b4c71` and included in master
merge `5d79af218`.

## Submission Details

- Upstream repository: `espruino/Espruino`
- Base branch: `IDF5`
- Fork: `SimonGAndrews/Espruino`
- Head branch: `fix/esp32-idf5-wifi-debug-build`
- Commit: `75210faca79c2a18e6cb93dee3f06fd43c8ee9dd`
- PR title: `ESP32 IDF5: fix WiFi debug build`

## Copy-ready PR Description

### Issue

The ESP32 IDF5 Wi-Fi event callback receives the event number in the
`event_id` argument. Its unhandled-event debug message instead referenced
`event->event_id`, which belongs to the callback used with older ESP-IDF
versions.

Normal release builds did not expose the problem because `jsDebug()` and its
arguments are removed when debug output is disabled. A debug-enabled
`ESP32_IDF5` build compiled the expression and failed because `event` is not
defined in the IDF5 callback.

### Fix

Select the event expression appropriate to the ESP-IDF callback:

- IDF5 and later use `event_id`;
- earlier IDF versions retain `event->event_id`.

This changes only the unhandled-event diagnostic. It does not change Wi-Fi
event handling in a normal release build.

### Validation

Using ESP-IDF 5.5.3 and `BOARD=ESP32_IDF5`:

- clean debug-enabled release build with `DEBUG=1 RELEASE=1`: pass;
- clean standard release build with `RELEASE=1`: pass;
- release firmware flashed to the classic ESP32 V1 bench: pass;
- boot and USB-UART REPL connection: pass;
- reported commit: `75210faca`;
- basic Espruino `digitalWrite()`/`digitalRead()` loopback test: 4/4 pass.

## Manual Submission

Run from a new terminal:

```bash
cd /home/simon/MaBecker/Espruino_IDF5_PR
git status --short --branch
git log --oneline official/IDF5..fix/esp32-idf5-wifi-debug-build
git diff --check official/IDF5...fix/esp32-idf5-wifi-debug-build
git remote add simon https://github.com/SimonGAndrews/Espruino.git
git push -u simon fix/esp32-idf5-wifi-debug-build
```

Then open GitHub and create the pull request with:

- base repository: `espruino/Espruino`;
- base branch: `IDF5`;
- head repository: `SimonGAndrews/Espruino`;
- compare branch: `fix/esp32-idf5-wifi-debug-build`.

Use the title and description above, review the **Files changed** tab to
confirm that only `libs/network/esp32/jswrap_esp32_network.c` is present, and
select **Create pull request**.

Do not select the combined `fix/esp32-idf5-wired-regressions` branch for this
PR; it also contains the five corrections still undergoing bench validation.

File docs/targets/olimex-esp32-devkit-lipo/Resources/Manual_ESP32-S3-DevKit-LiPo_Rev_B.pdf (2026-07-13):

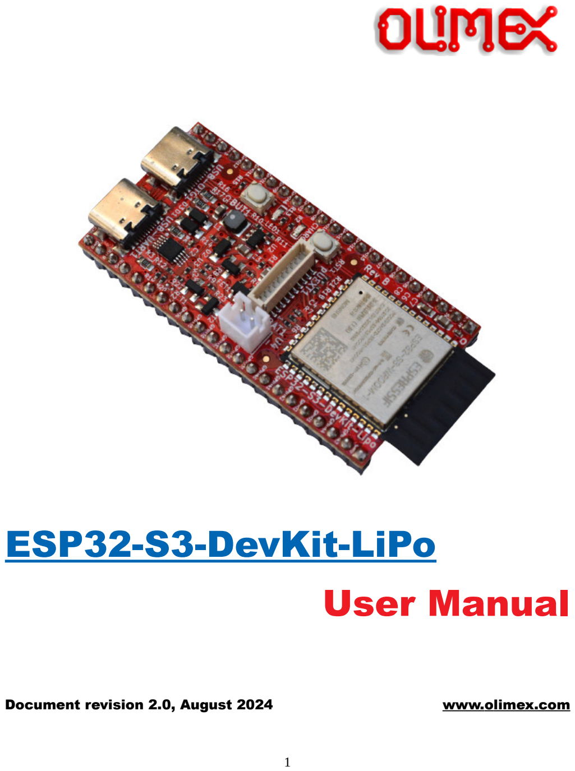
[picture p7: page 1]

# ESP32-S3-DevKit-LiPo User Manual

Document revision 2.0, August 2024 | www. (http://www.olimex.com/) o (http://www.olimex.com/) limex.com (http://www.olimex.com/)

## Table of Contents

## Introduction to ESP32-S3-DevKit-LiPo

ESP32-S3 is a dual-core XTensa LX7 MCU, capable of running at 240 MHz. Apart from its 512 KB of internal SRAM, it also comes with integrated 2.4 GHz, 802.11 b/g/n Wi-Fi and Bluetooth 5 (LE) connectivity that provides long-range support. It has 45 programmable GPIOs and supports a rich set of peripherals. ESP32-S3 supports larger, high-speed octal SPI flash, and PSRAM with configurable data and instruction cache.

The board has two variants: ESP32-S3-DevKit-Lipo comes with module with PCB antenna as seen in the picture on the first page, while ESP32-S3-DevKit-Lipo-EA comes with U.FL connector for external antenna.

ESP32-S3-DevKit-LiPo (https://www.olimex.com/Products/IoT/ESP32-S3/ESP32-S3-DevKit-Lipo/open-source-hardware) board is a development board with Espressif ESP32-S3 module and these features:

- ESP32-S3-WROOM-1-N8R8 8MB RAM 8MB flash
- Green status LED
- Yellow battery charge LED
- pUEXT 1.0 mm step connector
- USB-C for power supply and USB-serial programmer
- USB-C for OTG JTAG/serial connector
- LiPo battery charger
- LiPo battery connector
- External power sense
- Battery measurement
- Automatic power supply switch between USB and LiPo
- RESET button
- USER button
- Dimensions: (1.1×2.2)" ~ (27.94×55.88)mm

## Order codes for ESP32-S3-DevKit-Lipo and accessories:

ESP32-S3-DevKit-LiPo (https://www.olimex.com/Products/IoT/ESP32-S3/ESP32-S3-DevKit-Lipo/open-source-hardware) ESP32-S3 development board with USB JTAG/debugger and LiPo charger

USB-CABLE-A-TO-C-1M (https://www.olimex.com/Products/Components/Cables/CABLE-USB-A-C-1M/) USB-C power and programming cable
LiPo (https://www.olimex.com/Products/Power/Lipo-battery/) | A number of compatible batteries
UEXT (https://www.olimex.com/Products/Modules/) | Extension modules and sensors

## HARDWARE

## ESP32-S3-DevKit-LiPo layout:

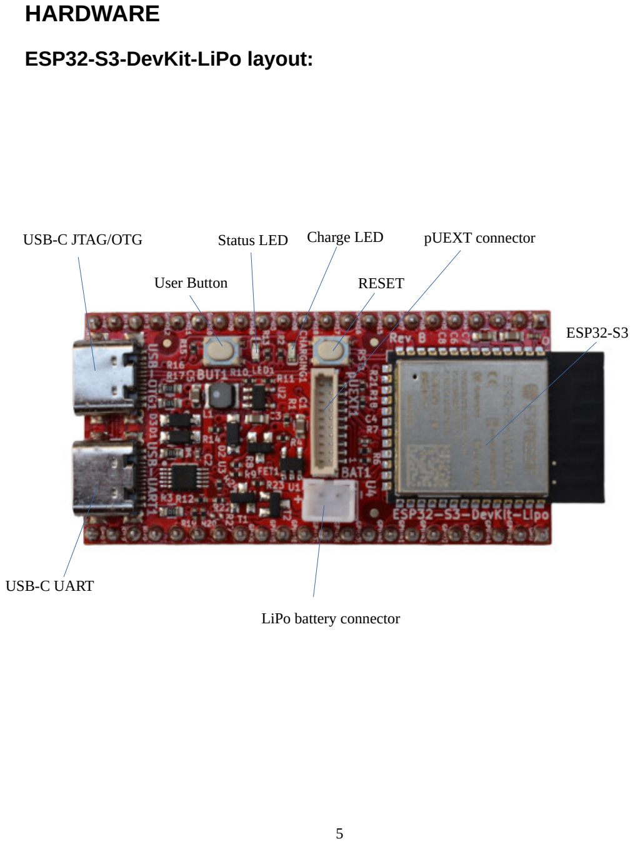
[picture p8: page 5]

USB-C JTAG/OTG

User Button

Status LED Charge LED

RESET

ESP32-S3

pUEXT connector

LiPo battery connector

USB-C UART

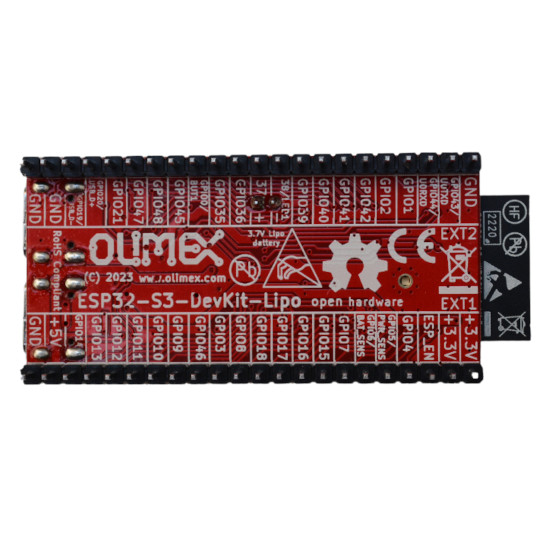
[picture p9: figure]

## ESP32-S3-DevKit-LiPo GPIOs:

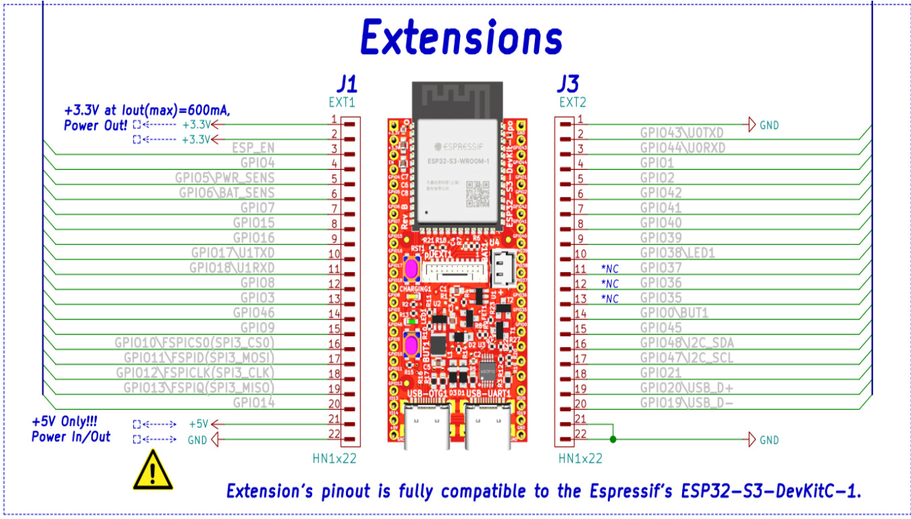
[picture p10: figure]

POWER SUPPLY:

This board can be powered by:

+5V | EXT1.pin 21 can be input or output
USB-UART | USB-C connector
USB-OTG1 | USB-C connector
LiPo battery

## ESP32-S3-DevKit-Lipo schematics:

ESP32-S3-DevKit-LiPo (https://www.olimex.com/Products/IoT/ESP32-S3/ESP32-S3-DevKit-Lipo/open-source-hardware) latest schematic is on GitHub (https://github.com/OLIMEX/RP2040-PICO30)

## UEXT connector:

UEXT connector stands for Universal EXTension connector and contain +3.3V, GND, I2C, SPI, UART signals.
UEXT connector can be in different shapes.
The original UEXT connector is 0.1” 2.54mm step boxed plastic connector. All signals are with 3.3V levels.

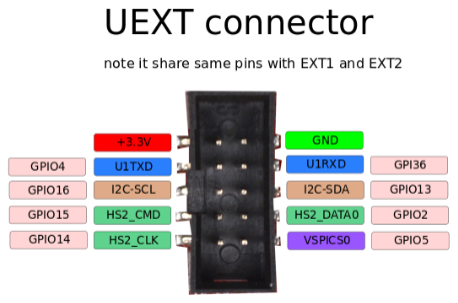
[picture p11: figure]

As the boards become smaller and smaller some smaller packages were introduced too beside the original UEXT connector
- mUEXT is 1.27 mm step boxed header connector which is with same layout as UEXT
- pUEXT is 1.0 mm single row connector (this is the connector used in RP2040-PICO30)
Olimex has developed number of MODULES (https://www.olimex.com/Products/Modules/) with this connector. There are temperature, humidity, pressure, magnetic field, light sensors. Modules with LCDs, LED matrix, Relays, Bluetooth, Zigbee, WiFi, GSM, GPS, RFID, RTC, EKG, sensors and etc.

## pUEXT signals:

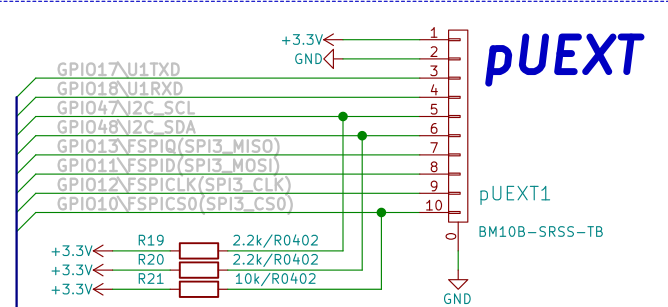
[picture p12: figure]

## SOFTWARE:

Olimex ESP32-S3-DevKit-LiPo has support in the ESP32 package for Arduino IDE. From the board selector there is entry “OLIMEX ESP32-S3-DevKit-Lipo”.

The module is also supported in ESP-IDF.

Additionally we’ve seen some customer project for booting Linux off the board:

- ESP32-S3-DevKit-Lipo Linux image (https://github.com/ESP32DE/Boot-Linux-ESP32S3-Playground/blob/main/bins/S3/olimexS3WROOM_N8qdR8ot.bin)
- ESP32-S3-DevKit-LiPo Linux build instructions (https://github.com/jcmvbkbc/linux-xtensa) from jcmvbkbc and here (https://gist.github.com/jcmvbkbc/316e6da728021c8ff670a24e674a35e6)
- ESP32-S3-DevKit-Lipo Linux build instructions (https://github.com/ESP32DE/Boot-Linux-ESP32S3-Playground) form ESP32DE

## Revision History

Revision 1.0 July 2023
Revision 2.0 August 2024

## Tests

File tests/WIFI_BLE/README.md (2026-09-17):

# Wi-Fi And BLE V1 Bench Development

This directory holds V1 bench tests, notes and configurations used to prove
the proposed V2 Wi-Fi and BLE test approach.

## Current Bench Boundary

Both harnesses operate in `STANDALONE` mode. Each target is powered through a
fully connected USB cable with VBUS present. There is no external target
power, USB No-VBUS cable, Harness Supervisor or controlled target-power
service.

The current experiment proves the host USB identity and configuration
principle from Section 5.5 of `StandardControlServices_V2.md`. It does not
claim to prove the V2 rack power or Supervisor sequence.

## Configuration Verification

Run from the repository root with no other REPL tool attached to either port:

```bash
python3 tools/repl/verify_bench_config.py \
  tests/WIFI_BLE/standalone_bench_config.json
```

The verifier:

1. resolves each configured `/dev/serial/by-path/` connection
2. rejects duplicate configured devices
3. opens each control connection sequentially
4. verifies the expected board, version and Git commit
5. verifies the required Wi-Fi and BLE APIs
6. reports `DONE=PASS` or `DONE=CONFIGURATION_FAILURE`

## Physical-Port Swap Test

1. Run the verifier in the recorded physical arrangement and require
   `DONE=PASS`.
2. Close any REPL, Web IDE or serial monitor using either target.
3. Swap the two target USB connectors between their current host or hub ports.
4. Wait for both `/dev/serial/by-path/` entries to reappear.
5. Run the verifier without changing the configuration. Both physical paths
   should report target identity mismatches and the command should exit with
   status 1 and `DONE=CONFIGURATION_FAILURE`.
6. Restore the connectors to their assigned physical ports and rerun the
   verifier. It should return to `DONE=PASS`.

The mismatched run is successful negative-test evidence. Do not edit the
configuration to make the swapped arrangement pass: the point is to prove
that the fixed physical USB position and expected target profile remain
coupled.

Results belong under `tests/Results/WIFI_BLE_Results/`.

## Current C3 Peer Status

The bench C3 is currently flashed from official Espruino `master` commit
`d8322cec9` as `ESP32C3_IDF4` `2v29.392`. It is qualified for the established
GATT-central role in the concurrent BLE-plus-HTTPS test, and for controlled
Wi-Fi AP/UDP use. It is not yet a fully interchangeable radio peer:

- repeated C3-peripheral `NRF.setServices()` runs exposed an intermittent
  asynchronous service-array lifetime fault;
- C3-station `Wifi.ping()` did not call back despite working DHCP, UDP and
  inbound ICMP echo replies;
- filtered `NRF.findDevices()` scans returned no devices during the same
  qualification, while connection-oriented `NRF.requestDevice()` worked.

Use the exact expected identity in
`esp32_idf5_ping_70k_bench_config.json`. See
`../Results/WIFI_BLE_Results/2026-09-10-esp32c3-current-master-peer-qualification.md`
before assigning the C3 a peripheral or filtered-scanner role.

## Concurrent BLE And HTTPS Test

The memory-coexistence test keeps a GATT connection open between the classic
ESP32 target and the C3 peer while the classic target joins an independently
routed 2.4 GHz Wi-Fi network and downloads an HTTPS response. The classic is
the GATT peripheral and HTTPS client; the C3 is the GATT central. The C3 reads
and writes the controlled GATT service before HTTPS, holds the connection, and
writes again only after the host has observed HTTPS completion. This proves
that BLE remained usable during the TLS transaction.

Copy `local_wifi_credentials.example.json` to
`local_wifi_credentials.json`, enter the local 2.4 GHz Wi-Fi credentials and
restrict the file to the current user. The local file is ignored by Git. Its
contents are injected with REPL echo disabled and are not printed in the
structured result:

```bash
cp tests/WIFI_BLE/local_wifi_credentials.example.json \
  tests/WIFI_BLE/local_wifi_credentials.json
chmod 600 tests/WIFI_BLE/local_wifi_credentials.json
```

Connect the bench PC to the isolated router and supply the PC's IPv4 address on
that LAN. Run the test with the C3 as the controlled GATT central and the
classic ESP32 as the GATT peripheral, Wi-Fi station and HTTPS client. The
runner creates a temporary self-signed certificate, starts a TLS-1.2 server
with a run-specific URL and response, and checks independently that the target
fetched it:

```bash
python3 tools/repl/run_ble_https_test.py \
  --local-server-address 192.168.50.2
```

The server binds to an automatically selected port by default. An externally
managed endpoint may instead be selected with `--https-url`; its expected
status and minimum response size are configurable with `--expected-status`
and `--minimum-bytes`.

The runner reboots both boards with one shared startup wait, reports elapsed
time at each major phase and streams its output line-by-line. The JavaScript
roles retain paced serial upload because eliminating that pacing risks REPL
input loss for only a small reduction in a successful run's duration.

Merely connecting the C3 peer to an upstream Wi-Fi network does not route the
classic target's access-point traffic. That topology would additionally need
IP forwarding and NAT on the C3. The coexistence test avoids that extra,
unproven component by connecting the classic target directly to the routed
network.

## Initial BLE Supervisor Peer Tests

The BLE tests use a generated name and run token so the host can correlate the
two serial transcripts with the peer observed over the air. No event-handshake
wiring or bench modification is required.

Run advertising and filtered discovery with the C3 as the Supervisor Peer:

```bash
python3 tools/repl/run_ble_peer_test.py
```

Reverse the radio roles:

```bash
python3 tools/repl/run_ble_peer_test.py --direction esp32-peer
```

The initial baseline evidence passed in both directions. The current-master C3
qualification returned an empty filtered-scan result in both directions, so a
new current-master pass must not be inferred from the historical result. The
scanner requires exactly one matching name, a real over-air device address,
numeric RSSI and the exact run payload under service UUID `0xFFF0`.

The GATT test adds connection, custom-service and characteristic discovery, a
run-bound read, two writes and disconnection:

```bash
python3 tools/repl/run_ble_gatt_test.py
python3 tools/repl/run_ble_gatt_test.py --direction esp32-peer
```

To validate service replacement rather than only initial service setup, the
same runner can replace the peripheral service repeatedly before advertising
the final run-specific value:

```bash
python3 tools/repl/run_ble_gatt_test.py \
  --service-replacements 50 \
  --service-replacement-delay-ms 500
```

The central must discover the final service, read its exact run challenge,
write both correlated responses and disconnect. A JavaScript loop completing
on the peripheral is therefore not sufficient for this result.

In `c3-peer`, the C3 is the GATT peripheral and the classic ESP32 is the
central. In `esp32-peer`, those radio roles reverse. The current-master C3
passes as the central; its peripheral role is intermittent and is not a
qualified pass. Each role first forces its existing
`Serial1` console with `E.setConsole(..., {force:true})`; otherwise the shared
ESP32 BLE connection handler automatically moves the REPL to Bluetooth while
the default BLE UART service is enabled. The role restores automatic console
selection after the test.

Scripts and runners:

- `ble/ble_capability_survey.js`
- `ble/ble_supervisor_advertiser.js`
- `ble/ble_target_filtered_scan.js`
- `ble/ble_supervisor_gatt_peer.js`
- `ble/ble_target_gatt_client.js`
- `tools/repl/run_ble_peer_test.py`
- `tools/repl/run_ble_gatt_test.py`

Results and interpretation are in
`tests/Results/WIFI_BLE_Results/2026-07-20-ble-supervisor-peer-initial.md`.
Firmware anomalies are registered under `docs/investigations/ble/`.

## Initial Wi-Fi Supervisor Peer Test

The first two-board Wi-Fi proof assigns the roles as follows:

- `esp32_c3_v1`: Supervisor Peer, WPA2 access point and UDP responder
- `esp32_v1`: target station under test
- host: orchestration, identity verification, timeouts and evidence collation

Run from the repository root with no other tool attached to either serial
port:

```bash
python3 tools/repl/run_wifi_peer_test.py
```

The runner performs a true ESP32 chip reboot at the beginning of the run so
the Wi-Fi driver starts from known volatile state. It does not flash firmware,
call `Wifi.save()` or alter persistent Wi-Fi configuration. It then:

1. verifies both configured board and firmware identities
2. starts a unique WPA2 AP and UDP responder on the Supervisor Peer
3. scans, associates and obtains an address on the target
4. checks the target gateway and pings the peer
5. exchanges a run-bound UDP challenge and acknowledgement
6. checks target-side Wi-Fi events and peer-side join/leave events
7. stops both roles and verifies that neither board retains an active IP or AP

The scripts are:

- `wifi/wifi_supervisor_peer.js`
- `wifi/wifi_station_peer_exchange.js`

The initial result is recorded in
`tests/Results/WIFI_BLE_Results/2026-07-20-wifi-supervisor-peer-initial.md`.

## ESP32 Wi-Fi Station Lifecycle Regression Tests

These tests exercise the station transitions affected by the ESP32 wrapper's
station-start handling. The candidate bench configuration identifies the
classic ESP32 IDF5 target and ESP32-C3 IDF4 controlled peer built from commit
`dc274713a`; it also fixes their physical USB positions. Verify or update those
facts before reusing it with different firmware or bench wiring.

Run the main lifecycle test to cover connection from an idle station, scanning
and reconnecting while connected, explicit disconnect, scanning while
disconnected, and connection after that scan:

```bash
python3 tools/repl/run_wifi_peer_test.py \
  --config tests/WIFI_BLE/esp32_wifi_lifecycle_dc274_bench_config.json \
  --target-script tests/WIFI_BLE/wifi/wifi_station_transition_lifecycle.js \
  --direction c3-peer \
  --target-timeout 90 \
  --overall-timeout-ms 60000
```

The additional lifecycle cases use the same controlled peer:

```bash
# Cancel an in-progress request, then complete five connect/disconnect cycles.
python3 tools/repl/run_wifi_peer_test.py \
  --config tests/WIFI_BLE/esp32_wifi_lifecycle_dc274_bench_config.json \
  --target-script tests/WIFI_BLE/wifi/wifi_connect_cancel_lifecycle.js \
  --direction c3-peer \
  --target-timeout 90 \
  --overall-timeout-ms 60000

# Remove and restore the peer AP, then reconnect explicitly.
python3 tools/repl/run_wifi_peer_test.py \
  --config tests/WIFI_BLE/esp32_wifi_lifecycle_dc274_bench_config.json \
  --peer-script tests/WIFI_BLE/wifi/wifi_recovery_peer.js \
  --target-script tests/WIFI_BLE/wifi/wifi_station_recovery_lifecycle.js \
  --direction c3-peer \
  --target-timeout 60 \
  --overall-timeout-ms 40000

# Exercise AP-only, AP+station and station-only transitions on classic ESP32.
python3 tools/repl/run_wifi_peer_test.py \
  --config tests/WIFI_BLE/esp32_wifi_lifecycle_dc274_bench_config.json \
  --target-script tests/WIFI_BLE/wifi/wifi_apsta_transition_lifecycle.js \
  --direction c3-peer \
  --target-timeout 60 \
  --overall-timeout-ms 45000
```

The AP+station case is intentionally limited to the classic ESP32. Espruino's
current C3 wrapper uses a single-role workaround and does not expose the same
simultaneous AP+station transition.

The saved-configuration test proves restoration after a hardware reboot:

```bash
python3 tools/repl/run_wifi_restore_test.py \
  --config tests/WIFI_BLE/esp32_wifi_lifecycle_dc274_bench_config.json
```

This test deliberately writes `.wificfg`, reboots the target, verifies the
restored connection and UDP traffic, then clears the saved configuration. Its
runner also attempts persistent and runtime cleanup if an intermediate phase
fails. A cleanup warning makes an otherwise successful run fail and requires
manual inspection before the target is reused.

The S3 was checked separately with the focused scan reproduction. Its broader
reconnect lifecycle is not qualified here because both the base and candidate
firmware showed the same pre-existing reconnect stall. The clean-master scan
configuration is retained as
`esp32_wifi_scan_master_26fff_bench_config.json`; it is evidence-specific and
is not a default for current lifecycle runs.

## Focused Ping Lifecycle Test

The focused test uses the C3 as a controlled WPA2 access point and ICMP/UDP
peer. It verifies invalid-address and overlapping-session rejection, successful
replies, an unreachable-address timeout, immediate session restart, repeated
ping sessions, BLE-advertising continuity, UDP operation after ping and native
heap stability. Run it against the qualified 70 KB classic image with:

```bash
python3 tools/repl/run_wifi_peer_test.py \
  --config tests/WIFI_BLE/esp32_idf5_ping_70k_bench_config.json \
  --target-script tests/WIFI_BLE/wifi/wifi_ping_lifecycle.js \
  --direction c3-peer \
  --skip-scan \
  --ping-rounds 25 \
  --target-timeout 180 \
  --overall-timeout-ms 170000
```

The 40 KB comparison configuration records the otherwise identical image used
for the controlled memory-allocation comparison; update and verify the expected
firmware identity whenever that comparison image is rebuilt.

## Negative Wi-Fi Station Cases

The negative scenario keeps the C3 Supervisor Peer AP active while the classic
ESP32 target runs two isolated subcases. The runner performs a true chip reboot
and cleanup between them:

1. a visible controlled WPA2 AP with deliberately incorrect credentials
2. a generated SSID first proved absent from scan results

Run:

```bash
python3 tools/repl/run_wifi_peer_test.py --scenario negative
```

The test requires both target-side negative state and independent peer-side
absence of a completed station join or application traffic. Connection
attempts for an unavailable AP are bounded by the test runner rather than
waiting indefinitely for a `Wifi.connect()` callback.

The target role is `wifi/wifi_station_negative_cases.js`. Results are recorded
in
`tests/Results/WIFI_BLE_Results/2026-07-20-wifi-supervisor-peer-negative-cases.md`.

The positive scenario remains the default and may also be selected explicitly:

```bash
python3 tools/repl/run_wifi_peer_test.py --scenario positive
```

## Reversed Supervisor Peer Roles

Logical roles can be reversed without changing the configured physical USB
positions:

```bash
python3 tools/repl/run_wifi_peer_test.py \
  --scenario positive \
  --direction esp32-peer
```

This assigns the classic ESP32 as the WPA2 AP/UDP Supervisor Peer and the C3
as the station target. The reversed test proved scan, association, DHCP,
bidirectional UDP, peer join/leave events and cleanup. It retained an overall
failure because C3 `Wifi.ping()` received no reply from the classic ESP32 AP,
even though the classic peer successfully pinged the C3 station. The evidence
is recorded in
`tests/Results/WIFI_BLE_Results/2026-07-20-wifi-supervisor-peer-reversed-roles.md`.

## Target-Hosted AP And Custom Subnet

This test reverses the service relationship: the selected target creates the
WPA2 AP and UDP service, while the other harness board acts as the Supervisor
station. It exercises a target-controlled AP address of `192.168.47.1/24`
rather than relying on the ESP32 port's default AP subnet.

Run the C3 as the target AP and classic ESP32 as the Supervisor station:

```bash
python3 tools/repl/run_wifi_target_ap_test.py
```

Run the classic ESP32 as the target AP and C3 as the Supervisor station:

```bash
python3 tools/repl/run_wifi_target_ap_test.py --target-board esp32
```

To isolate target-hosted WPA2 authentication from station scanning, ping and
custom IP configuration, use the focused authentication mode. It connects
directly by SSID/password on the reset-default AP subnet, obtains a DHCP
address and completes the UDP challenge. It requires the AP-side join event,
the station-side disconnect event and inactive cleanup, but does not make the
separate AP-side `sta_left` event part of the authentication verdict. The
station peer's BLE advertising is disabled for this focused run so that any
peer-side Bluetooth activity cannot contaminate the WPA2 result:

```bash
python3 tools/repl/run_wifi_target_ap_test.py \
  --config tests/WIFI_BLE/standalone_bench_config.json \
  --target-board esp32 \
  --focus-auth
```

For a bench configuration that names a different station peer, replace the
`--target-board` mapping with explicit configured position IDs:

```bash
python3 tools/repl/run_wifi_target_ap_test.py \
  --config path/to/bench_config.json \
  --target-position esp32_v1 \
  --station-position esp32_station_peer \
  --focus-auth
```

Both builds applied the custom address, served DHCP and completed the
run-bound UDP exchange. Both also returned the string `"Failure"` to the
documented `Wifi.setAPIP()` callback despite applying the requested address.
The runner deliberately reports this API-contract mismatch as a failure while
retaining the successful functional observations. With the classic target AP,
the previously recorded C3-to-classic-AP `Wifi.ping()` timeout also repeated;
UDP continued to pass.

The target role is `wifi/wifi_target_ap_service.js`; the station role reuses
`wifi/wifi_station_peer_exchange.js`. Full results and interpretation are in
`tests/Results/WIFI_BLE_Results/2026-07-20-wifi-target-ap-custom-ip.md`.

## Static Supervisor-Station Address

The focused static-address scenario starts the selected target AP on its reset
default `192.168.4.1/24` subnet. The other board associates by DHCP, calls
`Wifi.setIP()` requesting `192.168.4.77`, and then checks the callback and
actual address separately. The target AP independently records the source
address of the run-bound UDP challenge.

Run with the classic ESP32 as the Supervisor station:

```bash
python3 tools/repl/run_wifi_target_ap_test.py --station-address static
```

Reverse the roles so the C3 is the Supervisor station:

```bash
python3 tools/repl/run_wifi_target_ap_test.py \
  --target-board esp32 \
  --station-address static
```

On both builds, the callback returned documented success (`null`) but the
station retained its DHCP address `192.168.4.2`. The AP likewise observed UDP
from `.2`, not the requested `.77`. The C3 completed the remaining lifecycle
and cleanup checks; classic confirmation runs showed additional post-call
abort/watchdog resets that remain a separate firmware-investigation result.

The focused station role is `wifi/wifi_station_static_ip.js`. Full results are
in
`tests/Results/WIFI_BLE_Results/2026-07-20-wifi-station-static-ip.md`.

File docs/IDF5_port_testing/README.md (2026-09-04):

# ESP32 IDF5 Port Testing

This directory contains the concise reports from the completed expedited IDF5
validation. The V1 regression evidence was supplied to Gordon Williams and
informed the decision to merge the official IDF5 branch into Espruino master
at `5d79af218`.

The reports remain dated pre-merge evidence. The current closure and required
same-source sanity run are defined in
`docs/handoff/2026-09-04-idf5-classic-validation-status.md`. Detailed source
investigations live under `docs/investigations/IDF5_port_testing/`; functional
results live under `tests/Results/`.

Merge-decision report:

- `Gordon_ESP32_master_vs_IDF5_build_defects_2026-08-31.md`

Historical context:

- `Initial_source_audit.md`
- `Investigation_tracker.md`
- `Gordon_IDF5_regression_status_2026-08-19.md`

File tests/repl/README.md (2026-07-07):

# Portable REPL Tests

This directory is reserved for community-shareable Espruino JavaScript tests.

The intended split is:

- `tests/repl/`: plain Espruino JS that can be pasted into a REPL or uploaded
  with the Espruino Web IDE
- block-specific subdirectories under `tests/repl/` group tests by physical
  harness block
- `tools/`: Python automation and diagnostics that send those tests to a board,
  run them unchanged through the REPL, and parse `PASS` / `FAIL` output

Target-specific pin choices should live in target maps or a small `CFG` block,
not deep inside the test logic. That keeps the same logical tests usable on the
ESP32-C3 harness, the classic ESP32 DevKitC V4 harness, and future ESP32-family
targets.

Recommended structure:

- block 1: `gpio_block`
- block 2: `analog_block`
- block 3: `i2c_block`
- block 4: `spi_block`
- block 5: `onewire_block`
- block 6: `onewire_gpio_block`
- block 7: `uart_block`
- block 8: `grove_i2c_block`

Current shared repo directories:

- `tests/repl/gpio_block1/`
- `tests/repl/analog_block2/`
- `tests/repl/i2c_block3/`
- `tests/repl/spi_block4/`
- `tests/repl/onewire_block5/`
- `tests/repl/onewire_gpio_block6/`
- `tests/repl/grove_i2c_block8/`
- `tests/repl/uart_block7/`

Within each block directory, use one file per logical API-scope task. For
example:

- `tests/repl/gpio_block1/gpio_readwrite_basic.js`
- `tests/repl/gpio_block1/gpio_watch_edges.js`
- `tests/repl/gpio_block1/gpio_pulse.js`
- `tests/repl/i2c_block3/i2c_mcp23008_registers.js`
- `tests/repl/i2c_block3/i2c_mcp23008_interrupt.js`
- `tests/repl/spi_block4/spi_mcp3008_basic.js`
- `tests/repl/grove_i2c_block8/i2c_grove_mcp23008_secondary.js`
- `tests/repl/uart_block7/uart_rx_burst_s2_to_s3.js`

So the directory name identifies the physical harness block, while the filename
identifies the specific Espruino API behaviour under test.

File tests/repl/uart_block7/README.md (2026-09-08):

# `uart_block7` Functional Tests

This directory groups shared functional REPL tests that use the non-console
UART crosslink hardware context of harness block 7.

The current UART RX burst pack targets the `ESP32_V1` harness, using the
existing UART1/UART2 crosslink while UART0 remains the runner/control path.
Four scripts also contain an `ESP32_C3_V1` UART0/UART1 map. That map requires
native USB Serial/JTAG for control and deliberate isolation of the
ESP32-C3-DevKitC-02 onboard CP2102N TX connection to `D20`. The bridge holds
`D20` high both when the board is externally powered with its USB-UART cable
disconnected and when the board is powered through that onboard USB
connection. Without CP2102N TX isolation, use the `D3` to `D4` loop-B path for
a single-UART C3 lifecycle check rather than interpreting the blocked `D3` to
`D20` direction as a firmware failure.

The pack is split by direction and burst-size scope so each file stays focused
and bench failures remain easy to interpret:

- `uart_read_available_polling.js`
- `uart_write_print_shapes.js`
- `uart_reconfigure_options.js`
- `uart_full_duplex_crosslink.js`
- `uart_flush_tx_completion.js`
- `uart_is_connected.js`
- `uart_listener_lifecycle.js`
- `uart_listener_variants.js`
- `uart_inject_buffering.js`
- `uart_pipe_to_sink.js`
- `uart_mismatch_negative.js`
- `uart_repeated_setup_soak.js`
- `uart_rx_burst_s2_to_s3.js`
- `uart_rx_burst_s3_to_s2.js`
- `uart_rx_burst_128_s2_to_s3.js`
- `uart_rx_burst_128_s3_to_s2.js`
- `uart_rx_burst_200_s2_to_s3.js`
- `uart_rx_burst_200_s3_to_s2.js`

Focused firmware-investigation tests outside the V1 harness pack are under
`docs/investigations/uart/repros/`:

- `esp32_uart_driver_lifecycle_family.js` repeats the no-wiring driver
  setup/unsetup reproduction with safe pins selected for classic ESP32, C3
  and S3 board definitions;
- `esp32s3_uart_crosslink_lifecycle.js` exercises both S3 hardware UARTs over
  temporary `D4 -> D16` and `D15 -> D7` crosslinks on the expansion headers.
  These pins avoid the Olimex ESP32-S3-DevKit-LiPo battery/power sensing,
  native USB, USB-UART, user button and status LED connections.

Current intent:

- polling coverage for `Serial.available()` and partial `Serial.read(n)`
- write-shape coverage for `Serial.write`, `Serial.print`, and
  `Serial.println`
- setup/reconfiguration coverage for baud rate, frame options and unsupported
  ESP32 `errors:true`
- simultaneous bidirectional traffic over the UART1/UART2 crosslink
- short-payload `Serial.flush()` transmit completion in both directions
- `Serial.isConnected()` behaviour around setup/unsetup on hardware serial
- data listener attach, remove and reattach lifecycle
- listener alias and ordering coverage for `addListener`, `prependListener`,
  `removeListener` and late buffered delivery
- synthetic RX coverage for `Serial.inject()`
- open-stream `Serial.pipe()` coverage from physical UART RX into a JS sink
- mismatched baud negative case plus same-session recovery
- repeated setup/write/read/unsetup lifecycle soak across both directions
- boundary coverage around the original `64`-byte failure point in the
  direction-pair files
- clean-start single-case coverage for `128` and `200` byte bursts
- structured output that works in direct REPL use and through the shared
  runner

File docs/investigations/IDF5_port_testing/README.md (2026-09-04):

# ESP32 IDF5 Port Investigations

This directory contains the detailed source, build and firmware-attribution
records supporting the concise reports in `docs/IDF5_port_testing/`.

The expedited investigation is closed except for the official-master
post-merge sanity run defined in
`docs/handoff/2026-09-04-idf5-classic-validation-status.md`. Subsequent defects
should be recorded in the normal API-specific investigation area.

The dated Markdown files record the initial functional comparisons, the
candidate corrections and their pull-request preparation. The build-log
subdirectories retain raw terminal evidence from the corresponding build
investigations:

- `ESP32_build/` — classic `BOARD=ESP32` build output;
- `IDF4_build/` — ESP32 IDF4 and ESP32-C3 IDF4 build failures;
- `IDF5_build/` — classic `BOARD=ESP32_IDF5` build failure.

The raw logs include checkout-specific paths because those paths are part of
the recorded build environment. They are evidence, not portable commands.

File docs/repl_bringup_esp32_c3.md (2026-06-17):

# ESP32-C3 REPL Bring-Up Checks

This document is a manual, REPL-driven bring-up sequence for the
ESP32-C3-DevKitC-02 harness.

It assumes:

- board under test is the ESP32-C3-DevKitC-02
- Espruino firmware on the board is known-good
- initial control path is the board USB-UART REPL
- tests use Espruino `Dxx` names

Run one hardware block at a time. Change selectors only for the active mode.

## Block 1: Baseline GPIO Loopbacks

Mode:

- `C3_BASELINE_GPIO`

Required selector state:

| Selector or wiring | Position |
|---|---|
| `SEL_D1` | `a2-b2` |
| `SEL_D2` | `a2-b2` |
| `SEL_D3` | `a2-b2` |
| `SEL_D4` | `a2-b2` |

Required wiring:

- loop A: `D1 -> R5 470R -> D2`
- loop B: `D3 -> R7 470R -> D4`

Must be open / not selected:

- `SEL_D0`
- `SEL_D08`
- `SEL_D10`
- `SEL_D3` UART and SPI positions
- `SEL_D4` UART and I2C positions
- `J10` signal shunts

### REPL Sanity Check

Enter:

```js
process.env.BOARD
process.version
```

Expected:

- board identifies as the expected ESP32-C3 Espruino target
- version reports the flashed build, for example `2v29`

### Helper Functions

Paste once:

```js
function report(name, ok, extra) {
  console.log((ok ? "PASS " : "FAIL ") + name + (extra ? " " + extra : ""));
}

function expectEq(name, actual, expected) {
  report(name, actual === expected, "got=" + actual + " expected=" + expected);
}

function clearWatchSafe(id) {
  if (id !== undefined) clearWatch(id);
}
```

### Loop A Static Readback

Paste:

```js
pinMode(D1, "output");
pinMode(D2, "input");

digitalWrite(D1, 0);
expectEq("LoopA low", digitalRead(D2), 0);

digitalWrite(D1, 1);
expectEq("LoopA high", digitalRead(D2), 1);
```

Expected:

- both checks pass

If `LoopA low` fails, suspect wrong selector position, missing loop A wire, bad
`R5` path, or D2 not actually on the loop input position.

If `LoopA high` fails, suspect open circuit, swapped selector, or D1 not
driving the intended node.

### Loop B Static Readback

Paste:

```js
pinMode(D3, "output");
pinMode(D4, "input");

digitalWrite(D3, 0);
expectEq("LoopB low", digitalRead(D4), 0);

digitalWrite(D3, 1);
expectEq("LoopB high", digitalRead(D4), 1);
```

Expected:

- both checks pass

### Loop A Edge Detection

Paste:

```js
var wa;
var edgesA = [];
pinMode(D1, "output");
pinMode(D2, "input");
digitalWrite(D1, 0);

wa = setWatch(function(e) {
  edgesA.push({state:digitalRead(D2), time:e.time, last:e.lastTime});
}, D2, {repeat:true, edge:"both", debounce:1});

digitalWrite(D1, 1);
digitalWrite(D1, 0);
digitalWrite(D1, 1);

setTimeout(function() {
  clearWatchSafe(wa);
  console.log(edgesA);
  report("LoopA edge count", edgesA.length >= 2, "count=" + edgesA.length);
}, 50);
```

Expected:

- edge array prints transitions
- edge count passes

The exact count can vary slightly if the REPL re-runs code or previous state
was left high, but you should clearly see both high and low transitions.

### Loop B Pulse Test

Paste:

```js
var wb;
var seenB = 0;
pinMode(D3, "output");
pinMode(D4, "input");
digitalWrite(D3, 0);

wb = setWatch(function() {
  seenB++;
}, D4, {repeat:true, edge:"rising", debounce:1});

digitalPulse(D3, 1, [20, 20, 20]);

setTimeout(function() {
  clearWatchSafe(wb);
  report("LoopB pulse/watch", seenB >= 2, "count=" + seenB);
}, 150);
```

Expected:

- at least two rising edges seen

## Pass Criteria For Block 1

Treat the baseline digital loopback block as good if:

- REPL is stable on board USB-UART
- `D1 -> D2` reads back low and high correctly
- `D3 -> D4` reads back low and high correctly
- watches on `D2` and `D4` see real transitions from local drive
- no unexpected reset or boot instability appears while using these pins after boot

## Suggested Next Block

After this block passes, move to:

- `C3_ANALOG_PWM`

That validates:

- `D8` PWM path through the 10k link
- `ANALOG_FB`
- `D0` ADC input selection

## Block 2: Analog Feedback

Mode:

- `C3_ANALOG_PWM`

Required selector state:

| Selector or wiring | Position |
|---|---|
| `SEL_D0` | `ADC_IN` |
| `SEL_D08` | fitted / closed |

Allowed to remain in place:

- `SEL_D1`, `SEL_D2`, `SEL_D3`, `SEL_D4` in default baseline positions

Must be open / not selected:

- `SEL_D0` must not be on `ONEWIRE_DQ`
- `J10` signal shunts

Purpose:

- prove `PWM_OUT` on `D8` reaches `ANALOG_FB`
- prove `ADC_IN` on `D0` sees that analog node
- prove PWM duty changes produce monotonic ADC changes

Host-side script:

```bash
python3 tools/esp32_c3_analog_block2.py --port /dev/ttyUSB0
```

Pass criteria:

- forcing `D8` low gives a low `analogRead(D0)` result
- forcing `D8` high gives a high `analogRead(D0)` result
- PWM sweep values rise monotonically from low duty to high duty
- no reset or REPL instability occurs during the block

## Block 3: Combined SPI And I2C

Mode:

- `C3_BUS_SPI_I2C`

Required selector state:

| Selector or wiring | Position |
|---|---|
| `SEL_D0` | `ADC_IN` |
| `SEL_D1` | `I2C_A_SDA` |
| `SEL_D2` | `I2C_A_FB` |
| `SEL_D3` | `SPI_MISO` |
| `SEL_D4` | `I2C_A_SCL` |
| `SEL_D08` | fitted / closed |
| `SEL_D10` | `I2C_INT` |

Must be open / not selected:

- `SEL_D0` must not be on `ONEWIRE_DQ`
- `SEL_D10` must not be on `SPI_CS_FLASH`
- `J10` signal shunts

Purpose:

- prove Espruino I2C access to the MCP23008 at `0x20`
- prove MCP23008 output feedback from `GP0` into `I2C_A_FB`
- prove MCP23008 interrupt assertion and clear on `I2C_INT`
- prove Espruino SPI access to MCP3008 `CH0`
- compare MCP3008 `CH0` against target `ADC_IN` on the shared `ANALOG_FB` node

Host-side script:

```bash
python3 tools/esp32_c3_bus_spi_i2c_block3.py --port /dev/ttyUSB0
```

Pass criteria:

- MCP23008 register write/read succeeds at `0x20`
- driving expander `GP0` low/high drives `I2C_A_FB` low/high
- interrupt line on `I2C_INT` asserts low when expected and returns high after clear
- MCP3008 `CH0` reads the analog feedback node correctly
- target `ADC_IN` and MCP3008 `CH0` track the same low/mid/high analog levels

## Block 4: OneWire

Mode:

- `C3_ONEWIRE`

Required selector state:

| Selector or wiring | Position |
|---|---|
| `SEL_D0` | `ONEWIRE_DQ` |
| `SEL_D08` | open |

Allowed to remain in place:

- `SEL_D1`, `SEL_D2`, `SEL_D3`, `SEL_D4`, and `SEL_D10`

Must be open / not selected:

- `SEL_D0` must not be on `ADC_IN`
- `J10` signal shunts

Purpose:

- prove OneWire bus presence on `D0`
- prove two-device DS18B20 discovery on the shared `ONEWIRE_DQ` bus
- prove addressed scratchpad reads for both sensors
- prove both devices return distinct ROMs and plausible temperatures

Host-side script:

```bash
python3 tools/esp32_c3_onewire_block4.py --port /dev/ttyUSB0
```

Pass criteria:

- `OneWire.reset()` succeeds
- search returns exactly two ROMs
- both ROMs start with family code `28`
- both scratchpads read valid non-`FF` data with valid CRC
- both decoded temperatures are plausible and the two ROMs are distinct

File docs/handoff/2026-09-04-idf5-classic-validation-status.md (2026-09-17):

# ESP32 IDF5 Validation Closure and Post-Merge Sanity

Date: 2026-09-04

## Conclusion

The expedited ESP32 IDF5 validation has completed its purpose. V1
harness regression evidence was supplied to Gordon Williams and informed the
decision to merge the official `IDF5` branch into Espruino `master`. The merge
is commit `5d79af2185f33020a02e315c6318dab81e27dfde`, with previous master
`c5ff787b199148c31ef2776fb6f70673cba01a25` and IDF5 tip
`955305fd29e1c3e38380ff72b23106cf4b3c441b` as its parents.

The same-source sanity comparison is now complete. `BOARD=ESP32` and
`BOARD=ESP32_IDF5` were built from official-master commit `e5341719a` and run
through the established classic ESP32 V1 suite. Both builds pass the wired
GPIO, ADC, PWM, DAC, I2C, SPI and external-flash coverage, including Gordon's
metadata-based DAC pin selection. IDF5 is materially better in the UART and
addressed-OneWire samples, but retains Wi-Fi regressions as an AP and in
station scan/ping behaviour. Continuing Wi-Fi, OneWire, UART or BLE defects
are now ordinary Espruino-master investigations rather than continuation of
the expedited port-validation project.

The authoritative post-merge result is:

- `tests/Results/2026-09-05-esp32-post-idf5-merge-same-source-sanity.md`

Follow-up on 17 September established that the historical IDF5 WPA2
access-point timeout is not present on current official master or on the
closeout integration branch containing PRs `#2749` and `#2752`. Current master
and the integration image each completed three focused authentication, DHCP
and UDP cycles with the C3 station. A retained 40 KB image and the 70 KB
integration image then each completed three cycles with a stable classic
station, including AP join/leave events. The 70 KB reserve is therefore not a
requirement for this small AP workload, and the exact historical cause remains
unproven. See:

- `tests/Results/WIFI_BLE_Results/2026-09-17-esp32-idf5-wpa2-ap-follow-up.md`

A subsequent focused UART investigation produced pull request `#2742`, merged
into Espruino `master` as `e6a3fe089`. Revision `363ba92c9` coordinates driver
reconfiguration across the ESP32 family and deliberately excludes the separate
setup-time byte caused by enabling a receiver before its TX source has reached
the idle-high state. It compiles for all seven current ESP32-family board
definitions and completed runtime lifecycle validation on classic ESP32,
ESP32-C3 and ESP32-S3 hardware. See:

- `tests/Results/2026-09-08-esp32-uart-family-driver-lifecycle-validation.md`

## Contribution to Upstream

The following submitted corrections are now present in master through the IDF5
merge:

| Upstream PR | Correction | IDF5 integration |
|---|---|---|
| `#2733` | Wi-Fi debug-build correction | merge `6ad8b4c71` |
| `#2734` | complete I2C configuration initialisation | merge `25f81a8e1` |
| `#2735` | ADC restoration | merge `149ccda22` |
| `#2736` | GPIO-matrix restoration | merge `4ba8157c9` |
| `#2737` | PWM/DAC restoration and DAC pin release | patch-equivalent commits `919ac70f1`, `176614e08`, `b0fa32b4b` |
| `#2738` | undefined pin-state cleanup | merge `c1c95ae69` |

Gordon followed PR `#2737` with commit `43fb9e08d`, replacing hard-coded DAC
GPIO numbers with `pinInfo` function metadata and explicit DAC pin-state
tracking. The post-merge sanity run validated this portability improvement on
the merged source: both D25 and D26 passed low/full-scale DAC feedback and
subsequent ordinary GPIO use.

The proposed OneWire timing change was deliberately held, was not submitted,
and is not included in the upstream merge. It improved device discovery but
did not resolve frequent addressed DS18B20 CRC failures.

## Pre-Merge Evidence

The completed comparison used:

| Role | Board | Version | Source commit |
|---|---|---|---|
| classic comparator | `ESP32` | `2v29.277` | `c5ff787b199148c31ef2776fb6f70673cba01a25` |
| corrected local IDF5 candidate | `ESP32_IDF5` | `2v29.75` | `354fa95fb` |
| radio peer | `ESP32C3_IDF4` | `2v29.274` | `b905c8099` |

That evidence established wired API comparability, several IDF5 improvements,
remaining addressed OneWire CRC failures, IDF5-only Wi-Fi failures and BLE
GATT parity. It was valid input to the merge decision, but it is not a test of
the final merge tree or Gordon's subsequent DAC metadata change.

Authoritative records:

- `docs/IDF5_port_testing/Gordon_ESP32_master_vs_IDF5_build_defects_2026-08-31.md`
- `tests/Results/2026-08-31-esp32-master-vs-idf5-regression.md`
- `tests/Results/WIFI_BLE_Results/2026-09-01-esp32-master-vs-idf5-peer-regression.md`
- `tests/Results/2026-08-31-esp32-idf5-corrective-candidate.md`
- `docs/investigations/IDF5_port_testing/2026-08-31-remaining-classic-esp32-idf5-priorities.md`

## Completed Post-Merge Sanity Run

The clean Espruino checkout used validation branch
`validation/post-idf5-merge-sanity` at `e5341719a`. Both board configurations
were built sequentially with board-specific provisioning. The completed suite
covered:

1. DAC low/full-scale output and ordinary GPIO use after DAC release;
2. ADC, PWM and GPIO-matrix behaviour;
3. I2C, SPI and external flash;
4. UART, including transfers beyond the former 120-byte limit;
5. OneWire search and addressed DS18B20 CRC soak;
6. Wi-Fi station scan, WPA2 access-point authentication and static IP;
7. BLE GATT in both roles and advertising/service-data behaviour.

Both D25 and D26 were exercised as DAC outputs, with low/full-scale analogue
feedback and later GPIO use. The dated result preserves build-specific,
shared and test-runner findings without rewriting the pre-merge evidence.

## Workstream Return Point

Firmware changes belong in focused branches of the Espruino repository.
Shared runners, bench configurations and evidence belong here. Once the
post-merge sanity record is complete, use the general V1 functional-runner
handover and the relevant normal investigation area for further work. V2
architecture and implementation can continue independently.

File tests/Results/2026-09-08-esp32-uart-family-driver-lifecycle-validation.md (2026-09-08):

# ESP32-Family UART Driver Lifecycle Validation

Date: 8 September 2026

## Conclusion

The revised UART driver-lifecycle change was accepted upstream and merged into
Espruino `master` through pull request `#2742`. It prevents the ESP32 UART
polling task from using a driver while `Serial.setup()` or `Serial.unsetup()`
deletes or reinstalls that driver. The change compiles for all seven current
ESP32-family board definitions and completed repeated runtime lifecycle tests
on classic ESP32, ESP32-C3 and ESP32-S3 hardware without an assertion, abort
or reboot.

The merged change addresses only the driver deletion/reconfiguration race. It
longer contains the classic-target guard or an RX flush, and it makes no claim
to correct unsolicited bytes seen during UART setup on the legacy classic
build.

## Upstream Outcome

Gordon Williams merged the two PR commits on 8 September 2026 as:

```text
e6a3fe0892e0e7d48811c53fa4f1e2fbda500e1d
Merge pull request #2742 from SimonGAndrews/fix/esp32-uart-driver-reconfiguration
```

Issue `#2741` was closed by the merge. Gordon also confirmed that configuring
the transmitter before the receiver, or otherwise holding a potentially
floating UART RX line high, is the expected hardware treatment for the
setup-time byte. No RX flush was required.
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

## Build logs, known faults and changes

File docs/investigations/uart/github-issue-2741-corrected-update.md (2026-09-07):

# Corrected investigation update

Further testing has shown that some of the failures originally reported in
this issue were caused by timing assumptions in our test scripts, rather than
by faults in the ESP32 UART implementation.

Please disregard the earlier claims concerning:

- incomplete transfers at 64-byte or 120-byte boundaries;
- incomplete 128-byte and 200-byte transfers;
- incomplete simultaneous full-duplex transfers;
- a need to restore the former transmit path, 256-byte receive buffer or
  polling interval;
- a need to reduce UART transmit chunks to 32 bytes.

The affected tests were calculating data hashes inside JavaScript `data`
callbacks and then judging completion against a short fixed deadline. After
changing the tests to collect the data first, finish when the expected length
has arrived and calculate the hash afterwards, current master transfers the
complete payload in both directions.

However, two separate UART driver-lifecycle defects remain reproducible on the
classic ESP32 target. Arguably these are edge cases found during stress
testing.

## 1. UART driver lifecycle assertion

Repeatedly using the normal `Serial.setup()` and `Serial.unsetup()` APIs can
delete an ESP-IDF UART driver while Espruino's UART polling task is inside
`uart_read_bytes()`.

This minimal reproduction requires no external UART wiring. UART0 remains the
REPL connection.

This test repeatedly starts and stops Serial2 using the normal Espruino Serial.setup() and Serial.unsetup() APIs.
It checks whether rapid reconfiguration can cause the background UART handling to fail, assert or reboot the ESP32.

```js
echo(false);
print("TEST=esp32_uart_driver_lifecycle");

var iteration = 0;
var finished = false;
var deadline = setTimeout(function() {
  if (finished) return;
  finished = true;
  Serial2.unsetup();
  print("FAIL timeout iteration=" + iteration);
  print("DONE=esp32_uart_driver_lifecycle");
}, 30000);

function next() {
  if (finished) return;
  if (iteration >= 100) {
    finished = true;
    clearTimeout(deadline);
    Serial2.unsetup();
    print("PASS iterations=" + iteration);
    print("DONE=esp32_uart_driver_lifecycle");
    return;
  }
  Serial2.setup(115200, {tx:D4, rx:D35});
  setTimeout(function() {
    Serial2.unsetup();
    iteration++;
    if (!(iteration % 10)) print("INFO iteration=" + iteration);
    setTimeout(next, 5);
  }, 5);
}

next();
```

On untouched current master `ed46a3a0b`, built as `BOARD=ESP32`, this
repeatedly produced:

```text
uart: uart_read_bytes(1227): uart driver error
xQueueGenericReceive ... assert failed
```

The decoded call chain was:

```text
xQueueGenericReceive
  -> uart_read_bytes
  -> pollSerialDevices
  -> uartTask
```

The board then rebooted.

## 2. Unsolicited NUL after UART reconfiguration

Rapidly recreating both non-console UARTs while alternating baud rate,
direction and traffic can place an unsolicited NUL before an otherwise
complete payload.

For this reproduction, cross-connect `D4` to `D36` and `D14` to `D35`. UART0
remains the REPL connection.

This test sends short messages between Serial2 and Serial3 while changing the baud rate and transfer direction.
It checks whether UART reconfiguration inserts an unexpected NUL (\u0000) byte before an otherwise correct message.

```js
echo(false);
print("TEST=esp32_uart_stale_nul");

var cases = [
  {baud:115200, reverse:false, text:"UART_0"},
  {baud: 57600, reverse:true,  text:"UART_1"},
  {baud:115200, reverse:false, text:"UART_2"}
];

var index = 0;

function finish(result) {
  echo(true);
  print(result);
  print("DONE=esp32_uart_stale_nul");
}

function runCase() {
  if (index >= cases.length) {
    finish("NOT REPRODUCED");
    return;
  }

  if (index) {
    Serial2.unsetup();
    Serial3.unsetup();
  }

  setTimeout(function() {
    var c = cases[index];
    var sender = c.reverse ? Serial3 : Serial2;
    var receiver = c.reverse ? Serial2 : Serial3;

    Serial2.setup(c.baud, {tx:D4, rx:D35});
    Serial3.setup(c.baud, {tx:D14, rx:D36});

    receiver.read();
    sender.write(c.text);

    setTimeout(function() {
      var got = receiver.read() || "";
      print("CASE=" + index +
            " BAUD=" + c.baud +
            " RECEIVED=" + JSON.stringify(got));

      if (got.indexOf("\0") >= 0) {
        finish("REPRODUCED unsolicited NUL");
        return;
      }

      index++;
      setTimeout(runCase, 80);
    }, 180);
  }, 80);
}

runCase();
```

On untouched current master, built as `BOARD=ESP32`, this produced:

```text
TEST=esp32_uart_stale_nul
CASE=0 BAUD=115200 RECEIVED="UART_0"
CASE=1 BAUD=57600 RECEIVED="UART_1"
CASE=2 BAUD=115200 RECEIVED="\u0000UART_2"
REPRODUCED unsolicited NUL
DONE=esp32_uart_stale_nul
```

A setup-only test with no UART traffic did not reproduce the NUL. The current
evidence therefore points to stale or transitional receive state during rapid
UART traffic and driver reconfiguration, rather than `Serial.setup()` alone.

## Source attribution

The unsafe driver-replacement pattern predates the IDF5 merge: the classic
ESP32 implementation already deleted and reinstalled a UART driver during
`Serial.setup()` without coordinating with the polling task.

In our pre-IDF5 BOARD=ESP32 comparison, an  earlier ten-cycle UART reconfiguration test completed without an assertion or unsolicited NUL. A focused 100-cycle lifecycle and stale-NUL reproductions were developed only after the merge, so the earlier result does not prove that the defects were absent.

The IDF5 UART lifecycle work made `Serial.unsetup()` delete the installed
driver as well, increasing the number of normal API paths that can expose the
existing race. The most accurate description is therefore a long-standing
latent driver-replacement race that was widened or exposed by the IDF5 UART
lifecycle changes, not a wholly new UART failure created by IDF5.

## Proposed correction

The proposed correction is deliberately narrow and changes only
`targets/esp32/jshardwareUart.c` for the classic ESP32 target:

1. Pause the UART polling task cooperatively before deleting or reinstalling a
   UART driver, and wait until the task acknowledges the pause.
2. Resume the polling task after driver configuration is complete.
3. Flush the newly installed `Serial2` or `Serial3` receive path before it is
   exposed to JavaScript.

It does not alter UART transmission, receive-buffer size, polling frequency,
receive timeout or UART0 behaviour. The code is guarded by
`CONFIG_IDF_TARGET_ESP32`, rather than by a USB-related feature definition.

## Validation

Source base: current master `ed46a3a0b`.

Using the ESP32 test harness and the Codex generated test suite:

| Build | Validation result |
|---|---|
| `BOARD=ESP32` | All 18 UART functional scripts completed with no failed checks. The two focused defect reproductions also passed. |
| `BOARD=ESP32_IDF5` | All 18 UART functional scripts completed with no failed checks. The two focused defect reproductions also passed. |
| `BOARD=ESP32C3_IDF5` | Firmware compiled successfully and all 102 checks in the focused C3 UART runtime test completed without failure. |

The two classic target builds each completed 100 repeated
`Serial2.setup()`/`Serial2.unsetup()` cycles without an assertion or reboot.
They also completed the alternating UART reconfiguration test without an
extra byte or malformed payload.

The C3 build completed polling and event-driven UART reception checks plus 100
alternating 115200/57600-baud setup, write, read and unsetup cycles. No
unexpected bytes, failed checks, assertions or resets were observed.

Runtime coverage included:

- setup, reconfiguration and unsetup;
- listener lifecycle and buffered reads;
- write, print, println and flush;
- mismatched-baud recovery;
- simultaneous full-duplex traffic;
- repeated setup/write/read/unsetup cycles;
- 32, 64, 65, 96, 128 and 200-byte transfers in both directions.

The C3 runtime test used firmware version `2v29.384` built from the exact
candidate commit `cc6dd86d2`. Together with the build guard check, this
confirms both that the classic-only correction is excluded from the C3 binary
and that ordinary C3 hardware UART operation remains functional.

The narrowly scoped source change has now been submitted as a proposed PR and
is awaiting upstream review.

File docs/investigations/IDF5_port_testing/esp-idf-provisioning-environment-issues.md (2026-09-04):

# ESP-IDF Provisioning Environment Issues

## Conclusion

The current Espruino `scripts/provision.sh` flow is adequate for creating a
new ESP-IDF checkout, but it does not establish that an existing shared
Espressif tool environment is complete, compatible or uncontaminated.

This caused two repeatable failures during the August 2026 ESP32-family
validation:

1. the shared IDF4 Python environment imported an incompatible IDF5 Kconfig
   package, so IDF4 configuration generation failed;
2. the shared IDF5.5 Python environment retained a prerelease `esptool` that
   no longer satisfied the refreshed IDF5.5 constraints, so provisioning
   could not activate the environment.

The immediate operating rule is:

> Open a new VS Code terminal before provisioning, and use that terminal for
> one Espruino checkout and one ESP-IDF family only. Continue the build in the
> same terminal after provisioning.

Longer term, `scripts/provision.sh` should validate and, when explicitly
requested, repair an existing ESP-IDF installation rather than treating the
presence of an `esp-idf-*` directory as proof that the environment is healthy.

## Scope

This note covers the shared Espressif tools and Python environments used by
Espruino provisioning on Ubuntu. It records the failures, their causes, the
safe short-term procedure and proposed provisioning-script improvements.

A separate build-state issue was also found: changing board targets in one
checkout without running `make clean` allowed stale C3 generated headers to be
used in a classic ESP32 build. That issue is summarised here because it affects
the working procedure, but it is not caused by ESP-IDF provisioning.

## How Espressif State Is Shared

The ESP-IDF source checkout is stored inside each Espruino repository, for
example:

```text
Espruino_master/esp-idf-4/esp-idf
Espruino_IDF5_Gordon_validation/esp-idf-5/esp-idf
```

Compiler tools and Python environments are stored separately under the user
profile and are shared by all compatible checkouts:

```text
All IDF 4.4 checkouts
    -> ~/.espressif/python_env/idf4.4_py3.12_env

All IDF 5.5 checkouts
    -> ~/.espressif/python_env/idf5.5_py3.12_env

Compiler and debugger versions
    -> ~/.espressif/tools/
```

Consequences:

- deleting one repository's `esp-idf-4` or `esp-idf-5` directory does not
  delete or reconstruct its shared Python environment;
- provisioning or package changes made from one checkout can affect other
  checkouts using the same IDF version;
- changing Espruino branch does not isolate the ESP-IDF Python environment;
- an optional Espressif tool cleanup performed for IDF5 can remove versions
  still required for later IDF4 builds.

## Current Provisioning Logic

For IDF4 and IDF5, the relevant current logic is effectively:

```text
Select the requested board family.

If the corresponding esp-idf directory does not exist:
    create its parent directory;
    clone the selected Espressif IDF tag recursively;
    run esp-idf/install.sh.

Source esp-idf/export.sh into the current shell.
```

The significant condition is that `install.sh` is only called when the local
IDF source directory is first created. If the directory already exists, the
script proceeds directly to `export.sh`.

The script therefore does not currently establish that:

- every required compiler tool is still installed;
- Python requirements still satisfy the current constraint file;
- the shared Python environment contains no conflicting packages;
- the active shell was previously provisioned for a different IDF family;
- the selected compiler, Python environment and IDF commit are the intended
  ones.

## Observed Issue 1: IDF4 Kconfig Namespace Collision

### Symptom

An `ESP32C3_IDF4` build failed while generating the IDF configuration:

```text
AttributeError: module 'kconfiglib' has no attribute 'BOOL'
```

The same failure occurred on current and earlier Espruino branches.

### Verified cause

The shared environment contained both:

```text
kconfiglib==13.7.1
esp-idf-kconfig==2.5.4
```

IDF 4.4.8 requires the standalone module:

```text
site-packages/kconfiglib.py
```

The later Espressif package installed a directory with the same import name:

```text
site-packages/kconfiglib/__init__.py
```

Python selected the package directory first. That implementation did not
provide the IDF4 API constants `BOOL` and `TRISTATE` expected by
`confgen.py`.

The unwanted `esp-idf-kconfig` package version matched the IDF5.5 environment.
The exact command that installed it into the IDF4 environment was not retained,
but the evidence is consistent with an IDF5 package operation being performed
while the IDF4 environment was active. This is an inference, not a proven shell
history.

### Why reprovisioning did not fix it

The IDF4 source directory was deleted and cloned again, but the shared
environment remained at:

```text
~/.espressif/python_env/idf4.4_py3.12_env
```

Running the installer adds or updates required packages; it does not generally
remove unexpected packages. The conflicting package therefore remained.

### Applied repair

Only the incompatible package was removed from the IDF4 environment:

```bash
/home/simon/.espressif/python_env/idf4.4_py3.12_env/bin/python \
  -m pip uninstall esp-idf-kconfig
```

Verification then showed:

```text
module=.../site-packages/kconfiglib.py
BOOL=3
TRISTATE=48
```

The C3 IDF4 build subsequently progressed past configuration generation.

## Observed Issue 2: Stale IDF5 `esptool`

### Symptom

IDF5 provisioning failed during environment activation:

```text
Requirement 'esptool~=4.12' was not met. Installed version: 4.12.dev3
```

### Verified cause

The shared IDF5.5 environment contained:

```text
esptool==4.12.dev3
```

That package had been installed on 5 July 2026. The global IDF5.5 constraint
file was refreshed on 18 August 2026 and required:

```text
esptool~=4.12
```

The prerelease `4.12.dev3` does not satisfy the stable-version requirement.
Stable `4.12.0` was available, but provisioning reused the existing Python
environment rather than updating it before activation.

### Applied repair

The exact stable version was installed into the IDF5.5 environment:

```bash
/home/simon/.espressif/python_env/idf5.5_py3.12_env/bin/python \
  -m pip install --upgrade "esptool==4.12.0"
```

After this change, provisioning reported:

```text
Checking python dependencies ... OK
Establishing a new ESP-IDF environment ... OK
```

## Related Issue: Optional Tool Cleanup Removed IDF4 Tools

After successful IDF5 activation, Espressif printed an informational message
offering to remove tool versions not used by the active IDF5.5 installation.
Running:

```bash
python path/to/idf_tools.py uninstall --remove-archives
```

removed older compiler, debugger and support-tool versions. The command then
failed while processing archives with:

```text
UnboundLocalError: cannot access local variable 'archive_version'
```

Post-command checks established:

- the active IDF5.5 tool set was complete;
- the IDF4.4 tool check failed because its older compiler versions had been
  removed;
- repositories and already-flashed boards were unaffected.

The IDF4 tools can be restored later with:

```bash
cd /home/simon/MaBecker/Espruino_master
./esp-idf-4/esp-idf/install.sh
```

This cleanup command should not be used during mixed IDF4/IDF5 validation.
"Not used by the active IDF version" does not mean "not used by any local
workstream."

## Immediate Best-Practice Procedure

### One terminal, one checkout, one IDF family

Open a new VS Code terminal before every provisioning session. In that
terminal:

1. change to the intended Espruino checkout;
2. select the intended Git branch;
3. source the provisioning script for one board family;
4. build only that IDF family in that terminal;
5. close the terminal before provisioning another IDF family or repository.

Example:

```bash
cd /home/simon/MaBecker/Espruino_IDF5_Gordon_validation
git switch candidate/gordon-2026-08-18-25dc06c1
source ./scripts/provision.sh ESP32_IDF5

echo "$ESP_IDF_VERSION"
echo "$IDF_PYTHON_ENV_PATH"
which python

make BOARD=ESP32_IDF5 clean
make BOARD=ESP32_IDF5 RELEASE=1
```

Do not open a new terminal between `source provision.sh` and `make`; the
exported environment belongs to the current shell and would be lost.

### Avoid ambiguous Python package commands

After provisioning, an unqualified command such as:

```bash
pip install ...
```

may operate on whichever Python environment is first in `PATH`. For diagnosis
or repair, use the complete expected interpreter path:

```bash
~/.espressif/python_env/idf5.5_py3.12_env/bin/python -m pip ...
```

Do not modify the Ubuntu system `pip` or system `esptool` to repair an
ESP-IDF virtual environment.

### Do not perform optional Espressif cleanup during mixed-version work

Older tools are expected when both IDF4 and IDF5 builds are in scope. Leave
them installed until the workstream no longer requires either family.

### Clean whenever the board target changes

This is separate from provisioning but is required for reliable builds:

```bash
make BOARD=<new-board> clean
make BOARD=<new-board> RELEASE=1
```

Before flashing, verify the generated board identity:

```bash
rg 'for board|PC_BOARD_ID|JSH_PIN_COUNT' \
  gen/platform_config.h gen/jspininfo.h
```

For classic `ESP32_IDF5`, the generated inputs must identify `ESP32_IDF5` and
must report `JSH_PIN_COUNT 40`.

## Proposed Long-Term Provisioning Changes

### 1. Detect a conflicting active environment

Before installing or exporting, inspect at least:

```text
IDF_PATH
IDF_PYTHON_ENV_PATH
ESP_IDF_VERSION
PATH
```

If another IDF family is active, stop with a concise message telling the user
to open a fresh terminal. Re-running provisioning for the same expected
environment may remain allowed.

### 2. Separate checkout creation from environment validation

The existence of `esp-idf-4` or `esp-idf-5` should only answer whether a clone
is needed. It must not skip environment validation.

Suggested structure:

```text
ensure_idf_checkout
ensure_required_tools
ensure_python_environment
activate_environment
verify_environment
report_provenance
```

### 3. Install missing tools even when the IDF checkout exists

Run the appropriate Espressif installer unconditionally, or first run
`idf_tools.py check` and invoke `install.sh` when required tools are missing.
Espressif installers are intended to reuse valid downloads and install missing
versions.

This would have restored the tools removed by the IDF5 cleanup without forcing
the IDF source checkout to be deleted and cloned again.

### 4. Validate Python dependencies on every provision

Activation should fail early if current constraints are not satisfied. The
script should report:

- expected environment path;
- Python executable actually used;
- unmet requirement and installed version;
- a safe repair command scoped to that environment.

This would have identified and repaired stale `esptool` before a build was
attempted.

### 5. Add IDF-family compatibility smoke checks

Generic version checks are insufficient when two packages use the same import
name. For IDF4, add a small compatibility test such as:

```python
import kconfiglib
assert hasattr(kconfiglib, "BOOL")
assert hasattr(kconfiglib, "TRISTATE")
```

If it fails, report the imported module path and installed distributions. Do
not silently uninstall packages from a shared environment.

### 6. Add an explicit repair mode

Normal provisioning should validate and stop safely. A separately requested
repair mode could reconstruct only the selected Python environment using the
Espressif-supported command:

```text
idf_tools.py install-python-env --reinstall
```

Both the locally selected IDF 4.4 and IDF 5.5 tools support `--reinstall`.
Because this discards and recreates a shared virtual environment, the script
should state the exact target and require explicit intent, for example:

```bash
source scripts/provision.sh ESP32_IDF5 --repair-python-env
```

It must not remove compiler versions for other IDF families.

### 7. Print a concise provenance summary

Successful provisioning should end with machine-readable or consistently
formatted values for:

```text
BOARD
Espruino checkout and HEAD
IDF_PATH
IDF tag and commit
ESP_IDF_VERSION
IDF_PYTHON_ENV_PATH
Python executable and version
compiler executable and version
```

This would make build records and later diagnosis substantially clearer.

### 8. Return non-zero without leaving a partially selected environment

If validation fails, the script should return a failure code and explain what
was and was not changed. It should avoid leaving a shell that appears
provisioned but points partly at another IDF environment.

## Suggested Validation Cases for a Script Change

Any provisioning change should be tested against:

1. no IDF checkout and no Python environment;
2. existing healthy checkout and environment;
3. existing checkout with a required compiler removed;
4. existing IDF5 environment with an outdated constrained package;
5. existing IDF4 environment with the conflicting `esp-idf-kconfig` package;
6. an IDF4 shell attempting to provision IDF5;
7. an IDF5 shell attempting to provision IDF4;
8. repeated provisioning of the same board in the same shell;
9. two repositories using the same IDF version;
10. network unavailable with a previously complete local installation.

## Recommended Return Point

Finish the current IDF5 firmware validation before changing provisioning.
Then create a dedicated Espruino branch for the script work, implement the
validation-first flow, and test it against both the current IDF4 and IDF5
checkouts. Firmware-source changes belong in the selected Espruino repository;
this harness repository should retain the investigation, proposed behaviour
and validation evidence.

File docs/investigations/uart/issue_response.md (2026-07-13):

# Historical Draft Issue Response

Status: historical draft, superseded by upstream fix application and local
close-out evidence.

The investigation close-out is now recorded in:

- `docs/investigations/uart/esp32-legacy-rx-burst-regression-2026-07-05.md`

Parked follow-up items are recorded in:

- `docs/investigations/uart/esp32-v1-block7-followups-2026-07-14.md`

Hi Gordon,

We were able to reproduce the UART RX burst problem on the `ESP32_V1` harness
using the UART1/UART2 crosslink, with UART0 left as the REPL/control path.

We built a small shared REPL test pack in my
[`ESP32_SGATest`](https://github.com/SimonGAndrews/ESP32_SGATest) repo under
`tests/repl/uart_block7/` and used it to check:

- boundary cases around the original failure point: `32`, `64`, `65`, `96`
- clean-start larger bursts: `128` and `200`
- both directions:
  - `Serial2 -> Serial3`
  - `Serial3 -> Serial2`

Pre-fix conclusion from the investigation:

- legacy `ESP32` and `ESP32_IDF4` both failed at the `65`-byte transition with
  the same `jsvStringIteratorAppend` assertion/reboot
- `ESP32_IDF5` did not assert, but practically truncated at `64` bytes in the
  same test scenario
- so the issue looked like one underlying serial-event assembly problem in
  Espruino Core, with different symptoms across the three ESP32 lines

Why this fix:

- the failure sits in `jsiHandleIOEventForSerial()`
- the first RX event chunk was being created with `jsvNewStringOfLength(...)`
- later RX chunks were appended with `jsvAppendStringBuf(...)`
- that means the first chunk could be created one way, while later chunks were
  appended through a different path
- the failure is consistent with that mismatch showing up at the first
  multi-chunk boundary
- the candidate fix is to build the serial event string incrementally from
  `jsvNewFromEmptyString()` and append the first chunk explicitly, so later
  chunks stay on the same append path
- the whole received UART payload is then built through one consistent
  appendable string path from the start
- in short: it removes the "first chunk created one way, later chunks appended
  a different incompatible way" mismatch

Bench result with that change:

- legacy `ESP32`: passes the split burst pack through `200` bytes
- `ESP32_IDF4`: passes the same pack through `200` bytes
- `ESP32_IDF5`: passes the same pack through `200` bytes

Candidate fix scope:

- one narrow change in `src/jsinteractive.c`
- no target-specific UART-driver change was needed

Screenshot to attach:

- `src/jsinteractive.c` diff for `jsiHandleIOEventForSerial()`
- suggested caption:
  "Narrow candidate fix: build serial RX event data from an empty string and append chunks incrementally"
- screenshot saved as:
  [canidate_fix_01.png](/home/simon/MaBecker/ESP32_SGATest/docs/investigations/uart/canidate_fix_01.png)

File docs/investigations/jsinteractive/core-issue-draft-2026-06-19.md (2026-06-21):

# Draft: Espruino Core Issue For `jsinteractive.c`

## Suggested Title

`setWatch(..., {debounce:...}) can merge pending edges if a debounce timeout is already overdue`

## Draft Body

While debugging an ESP32 IDF5 `digitalPulse` regression, I ended up with one
remaining issue that appears to sit in Espruino Core rather than in the ESP32
target.

This looks to be in the debounced watch handling in `src/jsinteractive.c`, not
in the IDF5 timer code itself.

The simplest way I can describe it is:

- one pin drives another through a resistor
- `setWatch(..., {repeat:true, edge:"both", debounce:20})` watches the input
- `digitalPulse(..., [20,20,20])` creates a short four-edge pulse train
- in a normal run, JavaScript sees all four transitions: `[1,0,1,0]`
- in a stressed run, using the same pulse train but forcing JavaScript to stay
  busy during part of it, JavaScript only sees: `[1,0]`

I now have a direct REPL/Web IDE version of this Pico repro, so it does not
need to be understood through the Python helper first.

I reproduced this on an Espruino Pico using:

- `B3` as output
- `B4` as watched input
- `B3 -> 470R -> B4`

The logic-analyser captures for the control and stressed runs both show the
physical pulse train on the watched input pin, so the interesting difference is
not that the input stopped changing. The difference is that JavaScript only
reports part of the edge sequence in the stressed case.

The direct Pico REPL results are:

- control: `SEEN=[1,0,1,0]`
- stressed: `SEEN=[1,0]`

The behaviour appears to be:

- a watch has `debounce` enabled
- one edge has already created a pending debounce timeout
- that timeout becomes overdue before Espruino Core processes it
- a second edge then arrives
- instead of first flushing the overdue edge and then handling the new one, the
  pending state can be updated in place

This seems to happen in `src/jsinteractive.c` in the debounced watch handling
inside `jsiIdle()`, where an existing `timeout` is updated when a new edge
arrives.

This only seems to show up in a fairly specific timing window, which may
explain why it has not been obvious before. It was exposed during the IDF5
`digitalPulse` work because once the target-side timer path was repaired, the
resulting edges were arriving in a way that exercised this path.

I have a candidate fix locally in `src/jsinteractive.c` which changes the
debounce flow so that if a pending timeout is already overdue, that edge is
flushed first, and the current edge is then re-added as a fresh timeout if
needed.

Before turning that into a separate Core PR, I wanted to sanity-check the
diagnosis and approach.

Related background only:

- the user-visible regression that led to this was ESP32 IDF5 `digitalPulse`
- this does not seem to be the same issue as discussion #5114, which was about
  very short pulse generation limits
- discussion #4004 looks adjacent in that it also touches watch timing /
  delayed edge observation, but not this exact overdue-timeout case

If useful, I can follow up with a minimal repro and the candidate patch.

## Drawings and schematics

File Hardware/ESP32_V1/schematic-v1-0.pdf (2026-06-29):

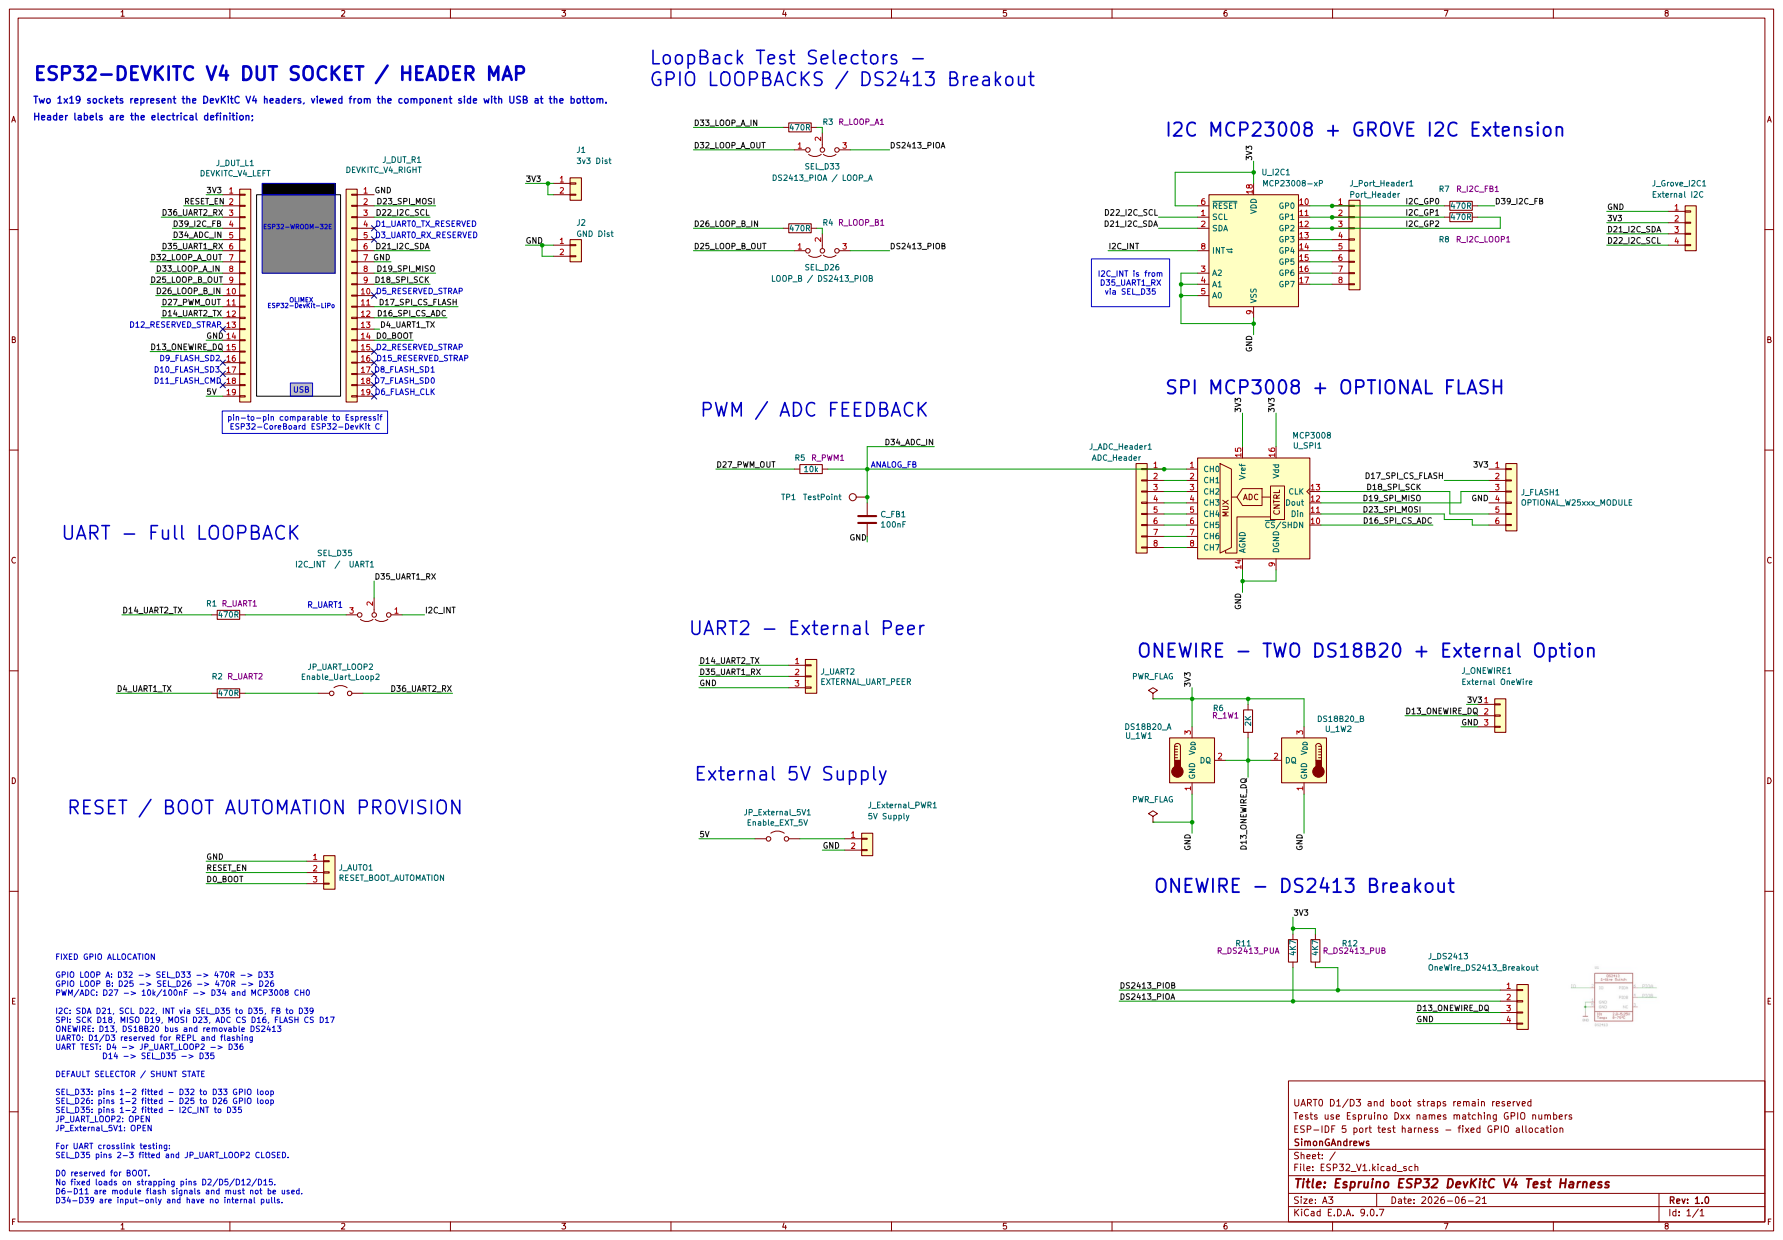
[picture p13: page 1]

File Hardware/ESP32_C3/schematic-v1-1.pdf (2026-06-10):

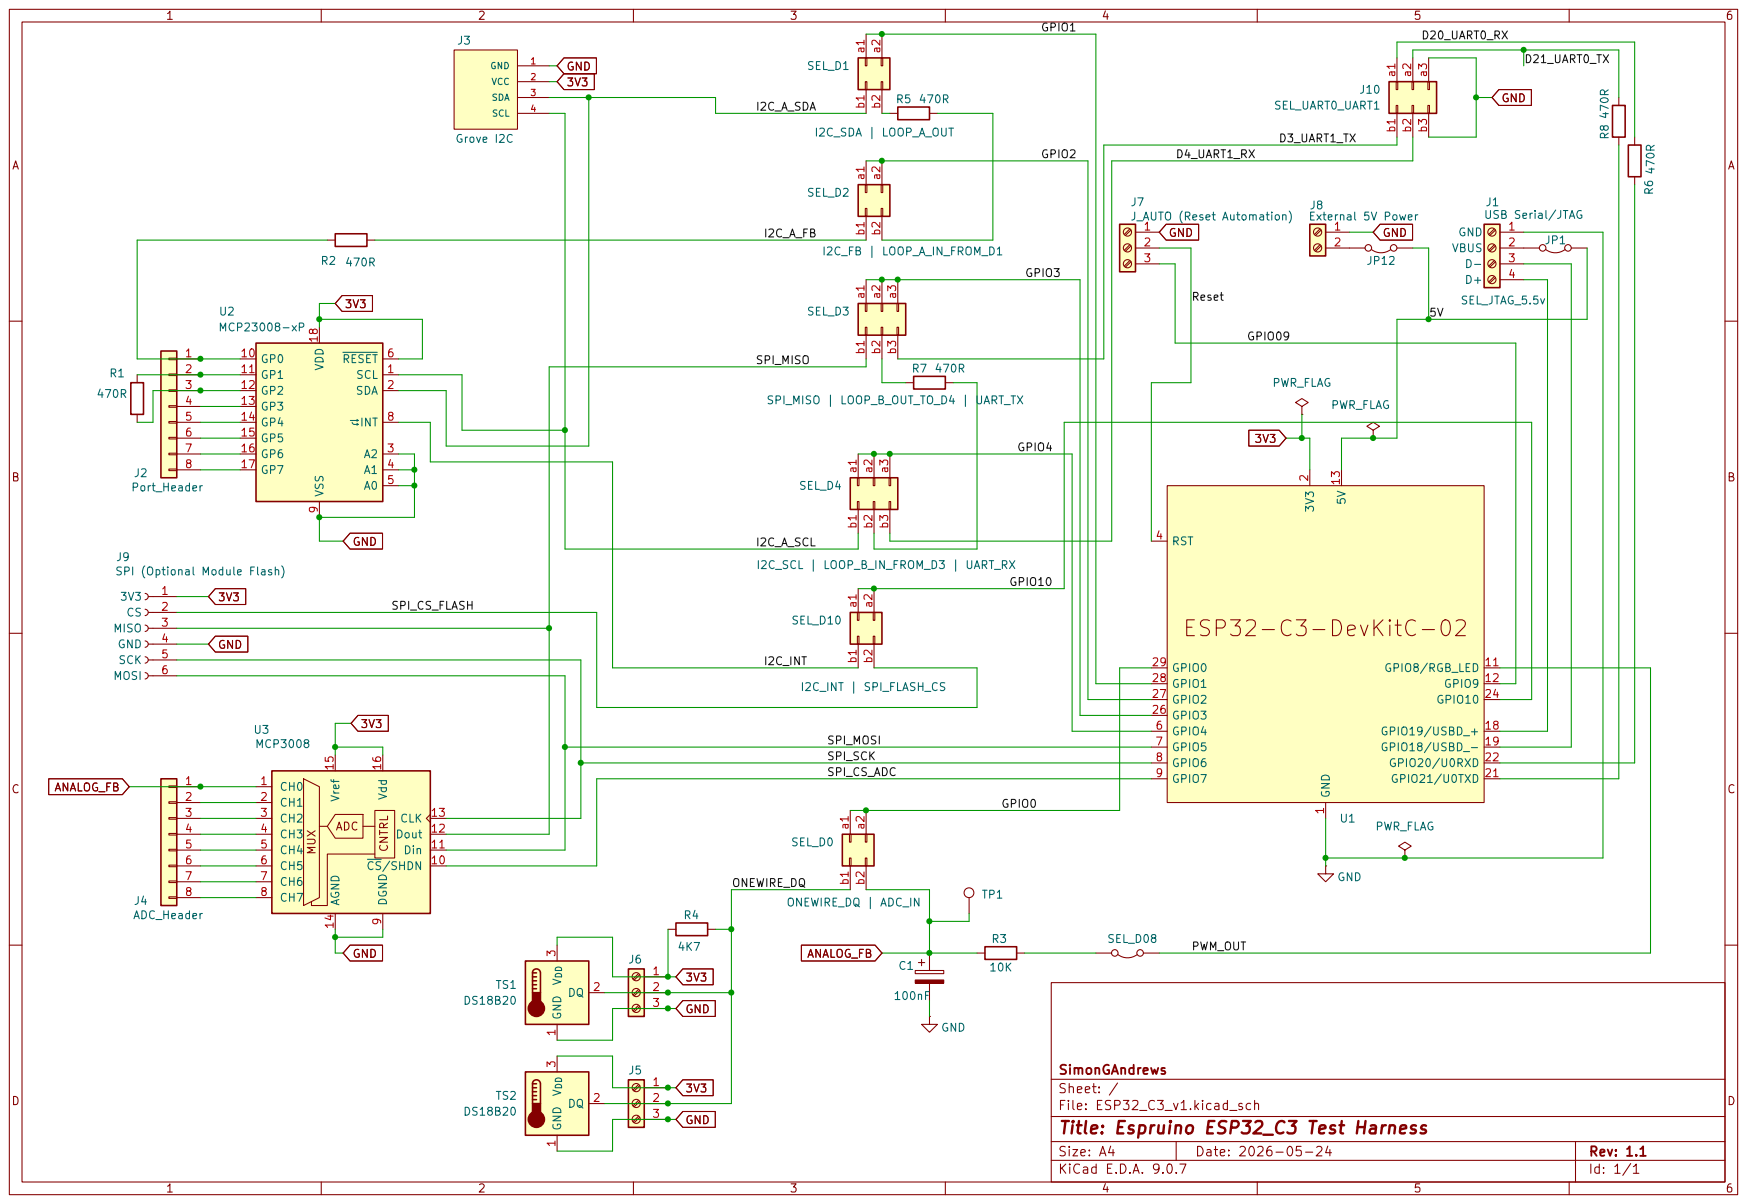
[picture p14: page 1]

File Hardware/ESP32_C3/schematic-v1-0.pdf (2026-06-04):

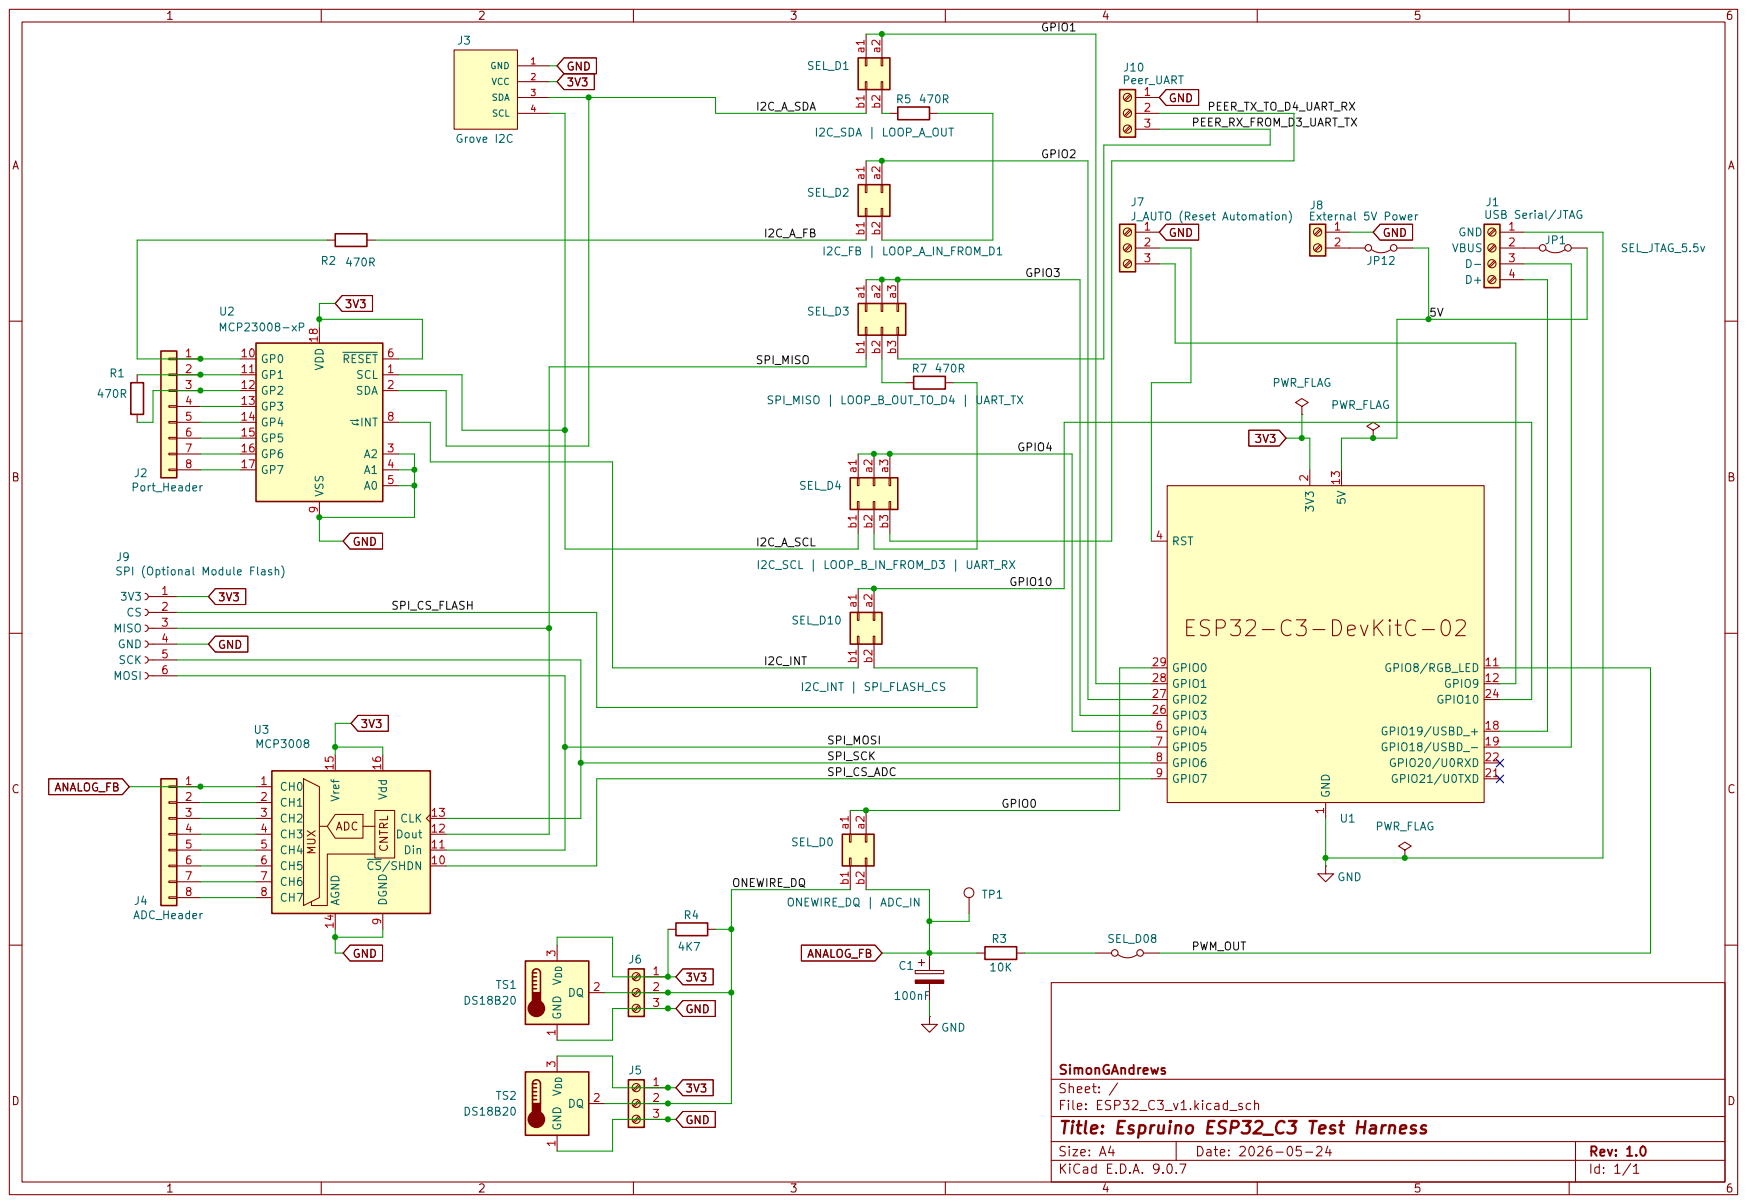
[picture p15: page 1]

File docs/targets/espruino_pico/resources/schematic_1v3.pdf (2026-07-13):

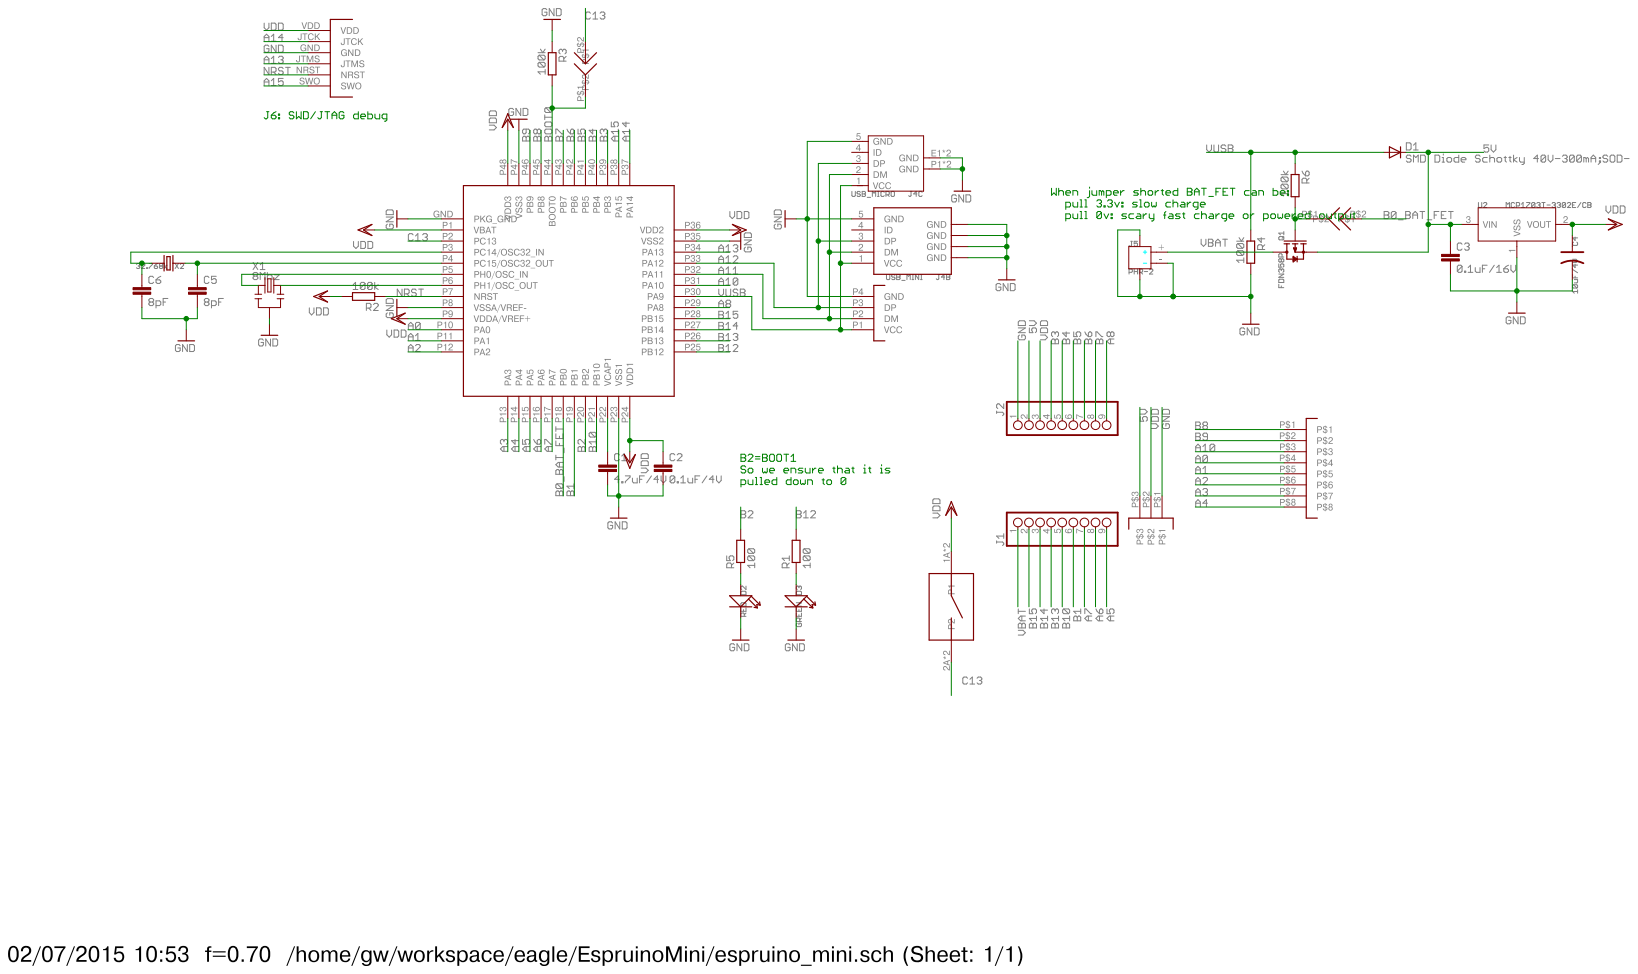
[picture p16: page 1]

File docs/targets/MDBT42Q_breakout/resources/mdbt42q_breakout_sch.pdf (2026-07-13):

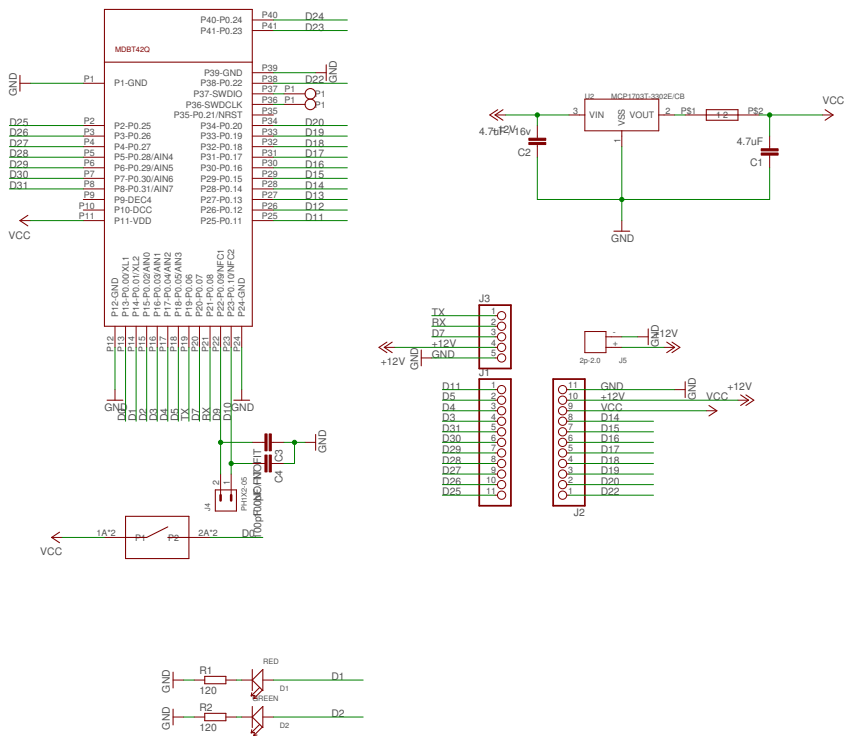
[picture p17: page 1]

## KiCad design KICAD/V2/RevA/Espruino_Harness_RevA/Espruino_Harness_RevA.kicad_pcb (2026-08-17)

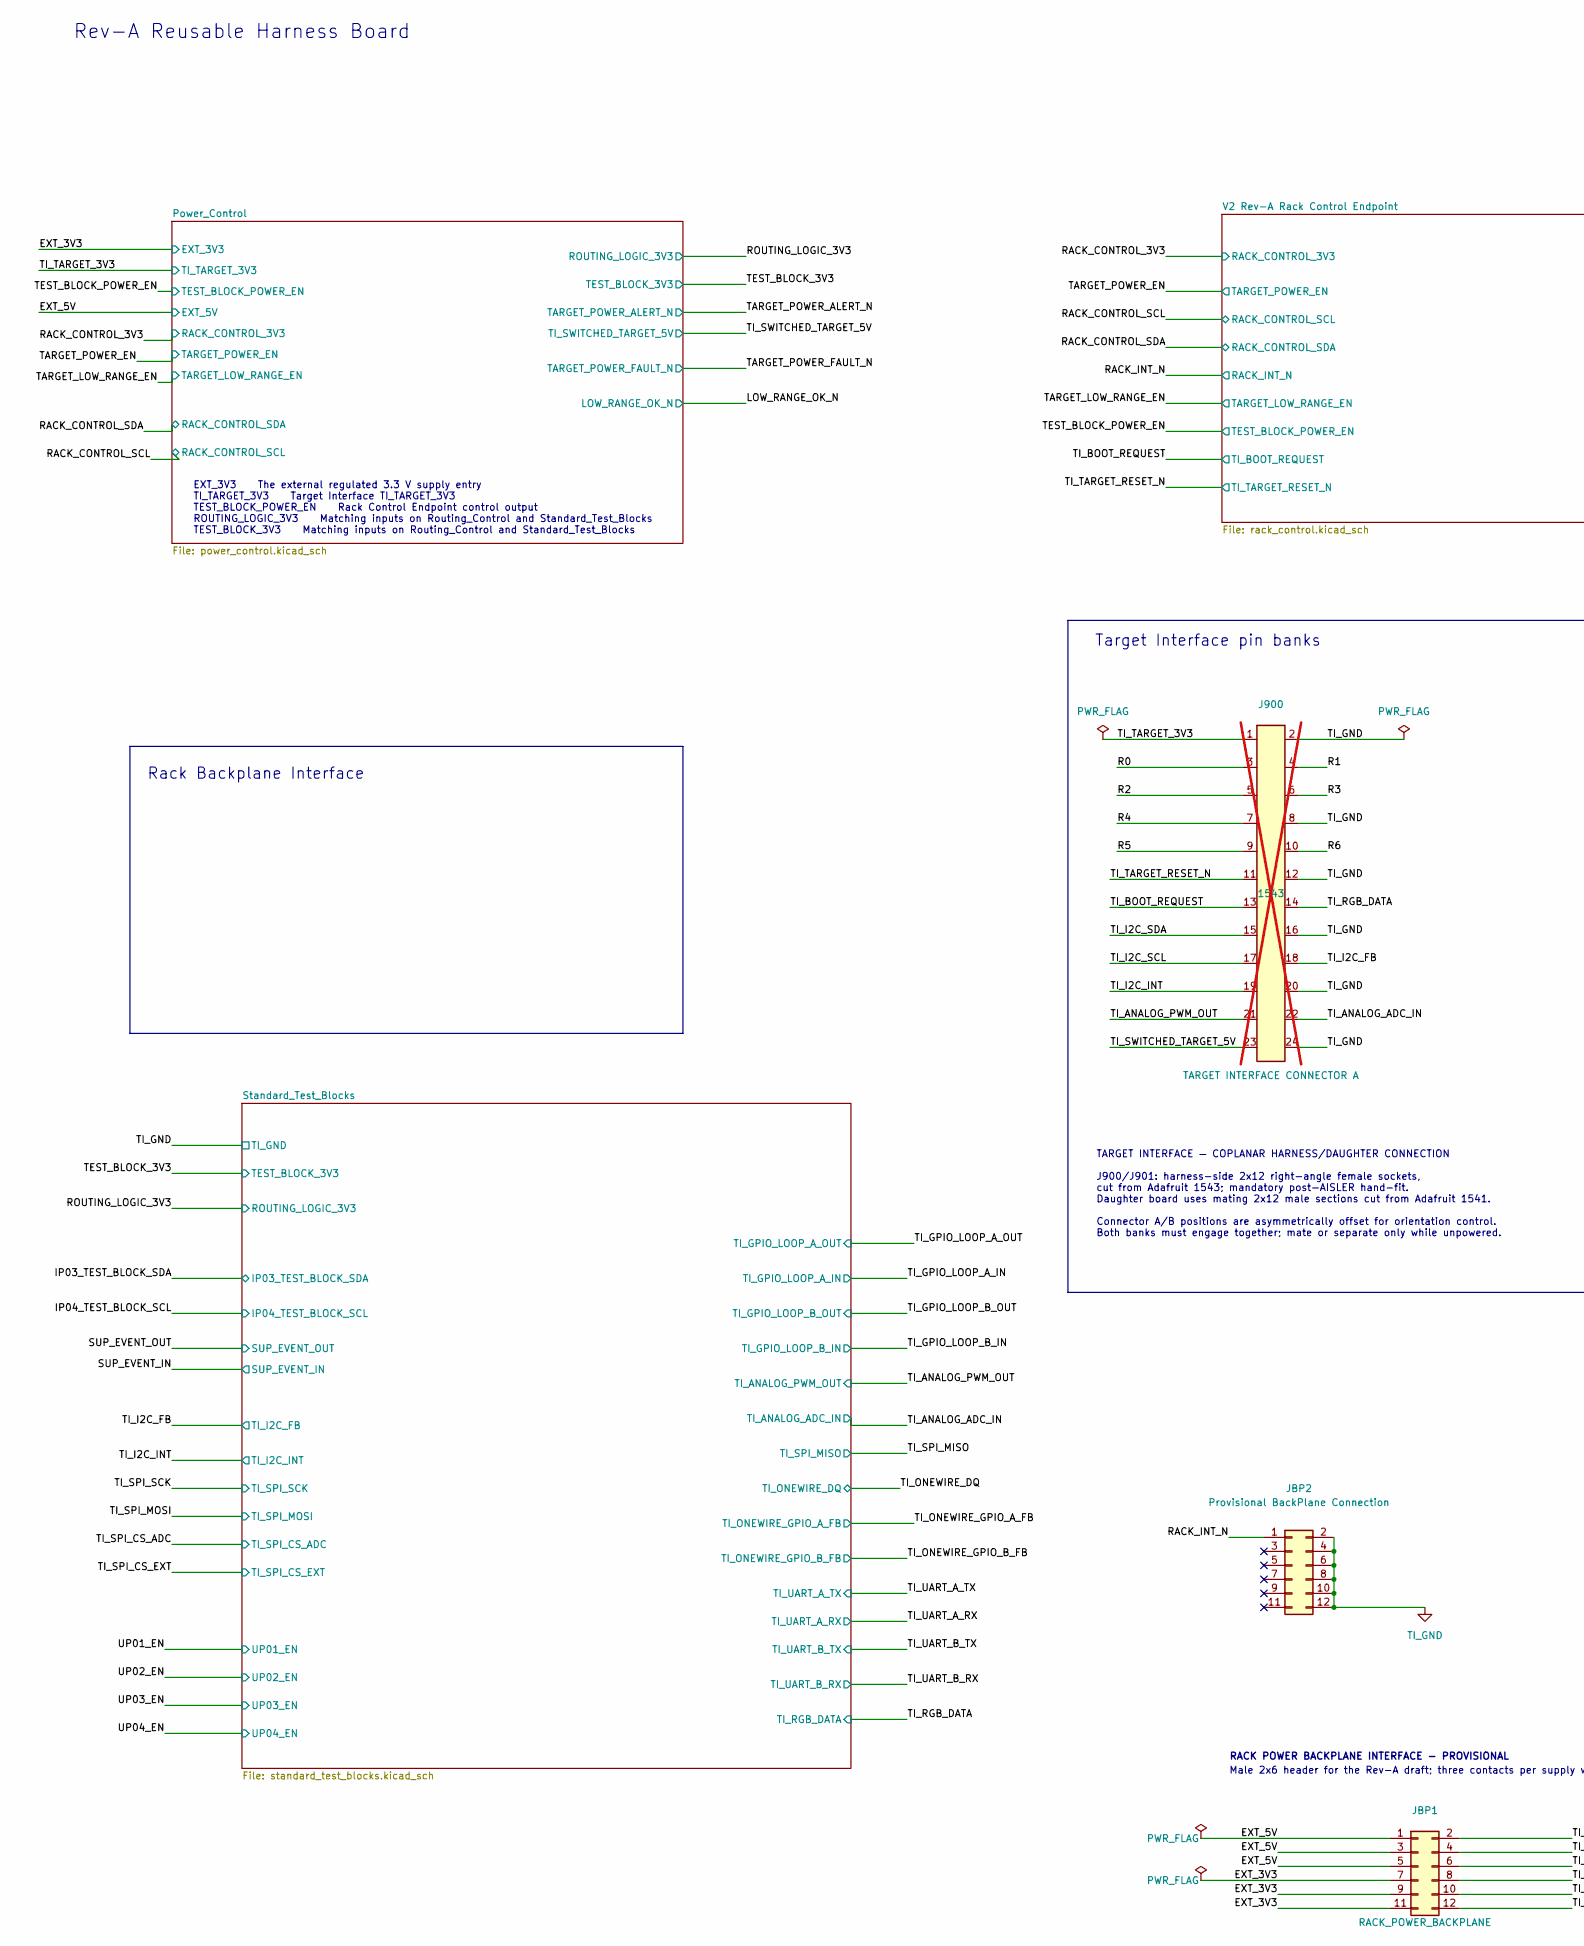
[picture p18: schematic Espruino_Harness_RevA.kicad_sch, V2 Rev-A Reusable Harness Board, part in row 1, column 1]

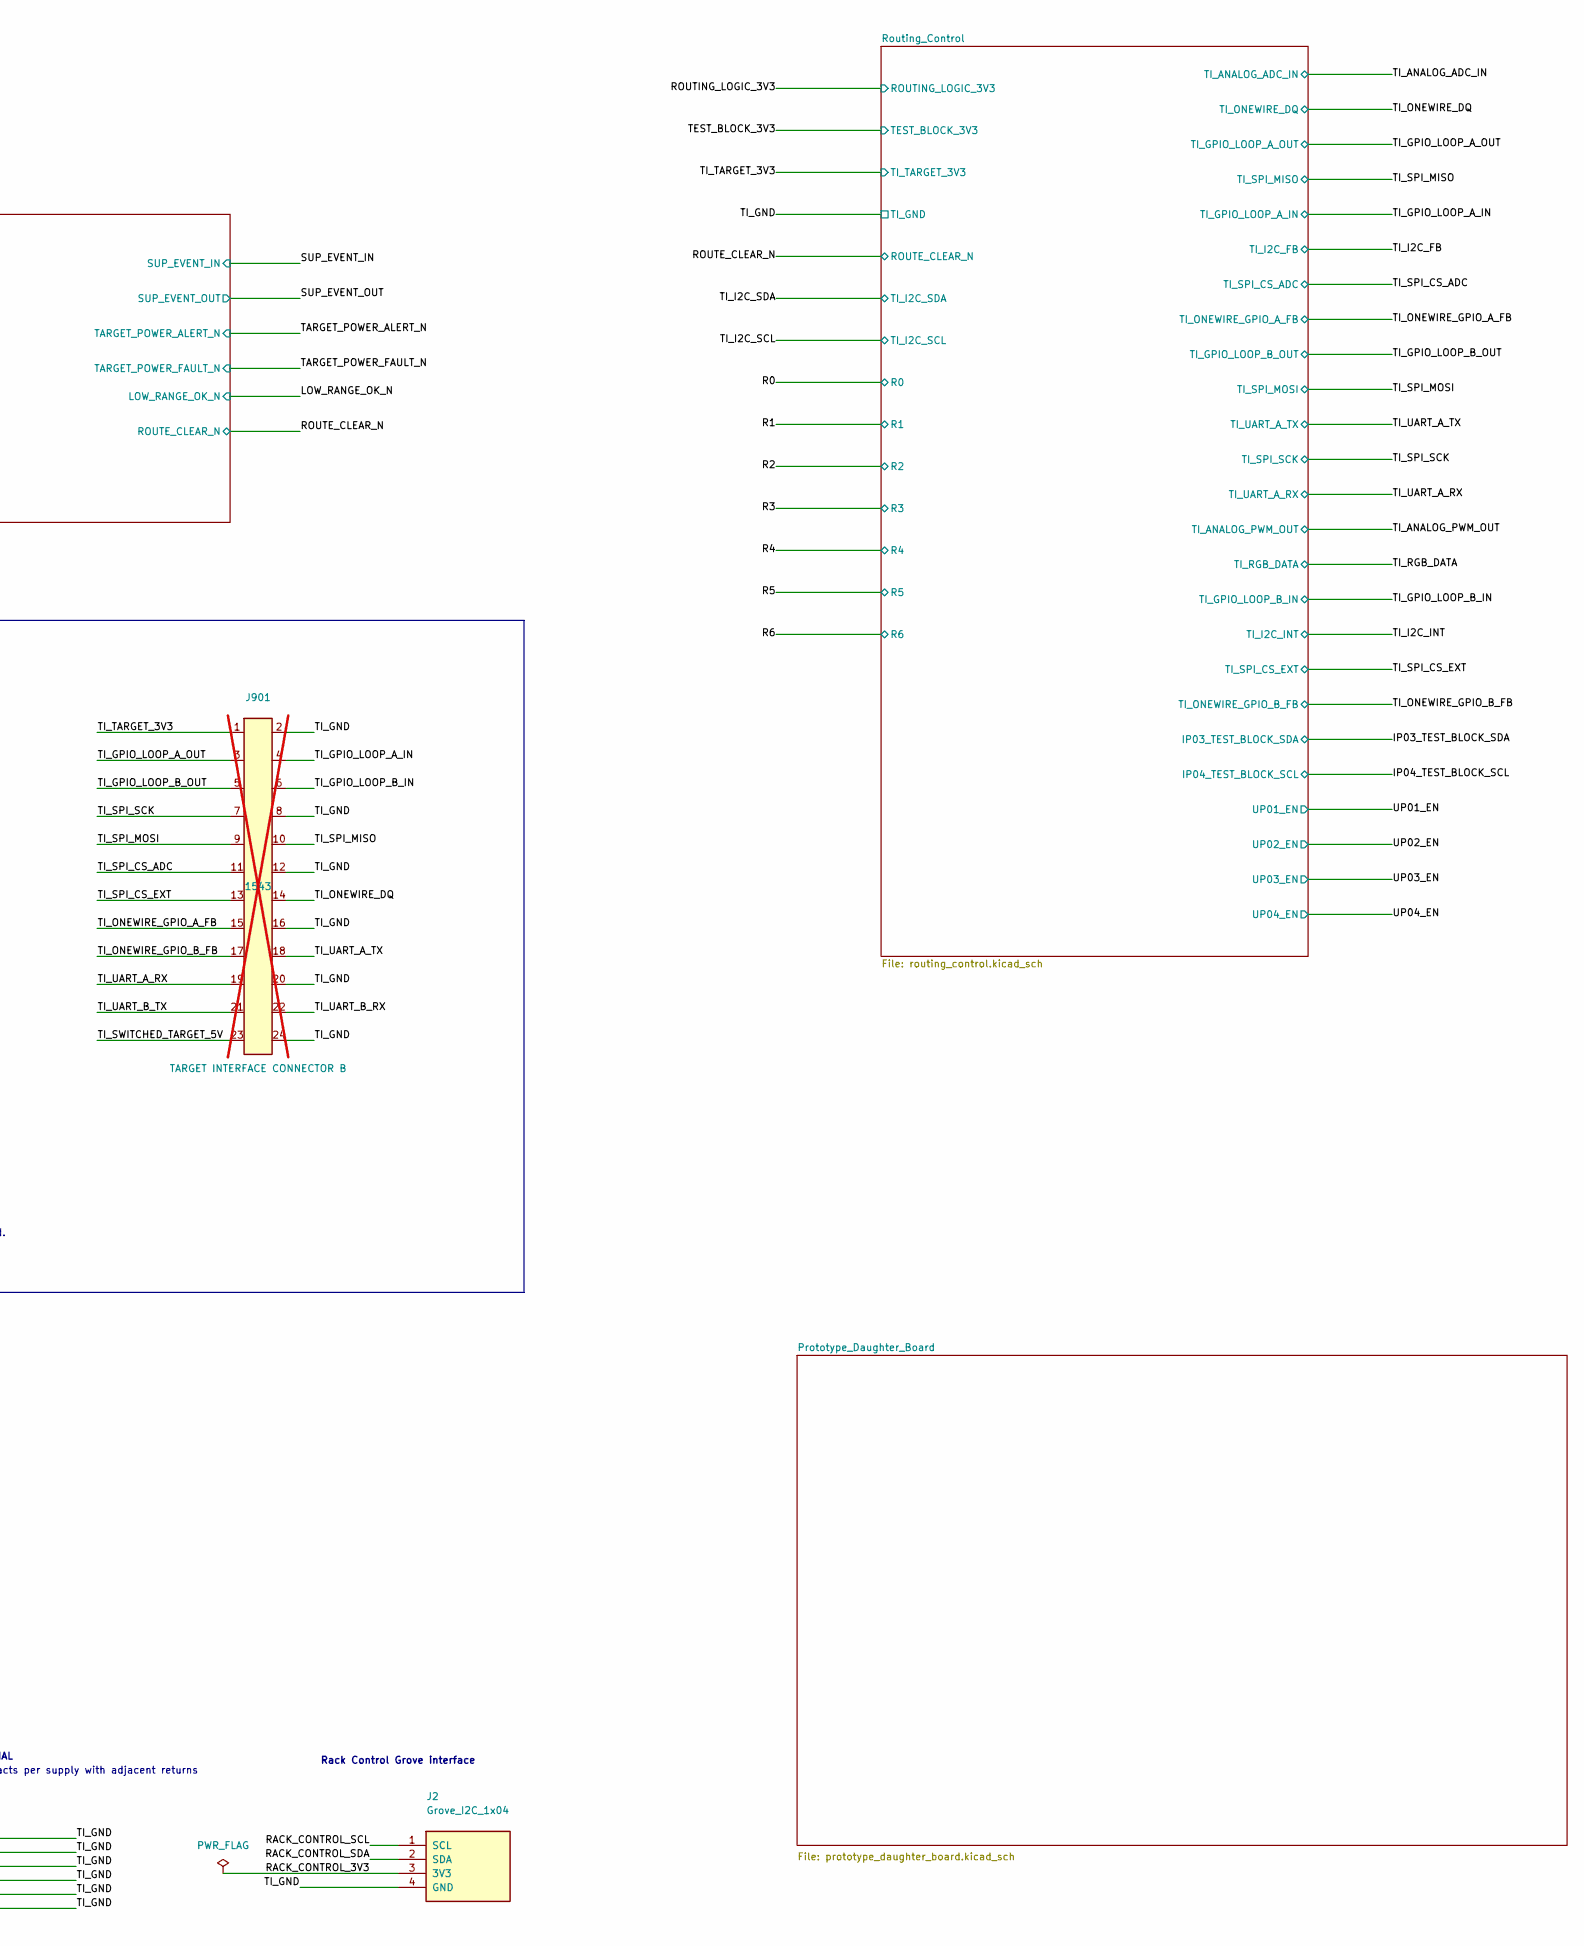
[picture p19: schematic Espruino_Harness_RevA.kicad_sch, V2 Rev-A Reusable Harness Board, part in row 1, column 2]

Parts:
J2: Grove_I2C_1x04
J900: TARGET INTERFACE CONNECTOR A; TargetInterface_2x12_P2.54mm_RA_Female_Adafruit1543_Harness; MPN 1543; not fitted
J901: TARGET INTERFACE CONNECTOR B; TargetInterface_2x12_P2.54mm_RA_Female_Adafruit1543_Harness; MPN 1543; not fitted
JBP1: RACK_POWER_BACKPLANE; PinHeader_2x06_P2.54mm_Vertical
JBP2: Provisional BackPlane Connection

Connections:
/EXT_3V3: JBP1.7, JBP1.9, JBP1.11; also elsewhere on the board
/EXT_5V: JBP1.1, JBP1.3, JBP1.5; also elsewhere on the board
/R0: J900.3 (Contact_03); also elsewhere on the board
/R1: J900.4 (Contact_04); also elsewhere on the board
/R2: J900.5 (Contact_05); also elsewhere on the board
/R3: J900.6 (Contact_06); also elsewhere on the board
/R4: J900.7 (Contact_07); also elsewhere on the board
/R5: J900.9 (Contact_09); also elsewhere on the board
/R6: J900.10 (Contact_10); also elsewhere on the board
/TI_ANALOG_ADC_IN: J900.22 (Contact_22); also elsewhere on the board
/TI_ANALOG_PWM_OUT: J900.21 (Contact_21); also elsewhere on the board
/TI_BOOT_REQUEST: J900.13 (Contact_13); also elsewhere on the board
/TI_GPIO_LOOP_A_IN: J901.4 (Contact_04); also elsewhere on the board
/TI_GPIO_LOOP_A_OUT: J901.3 (Contact_03); also elsewhere on the board
/TI_GPIO_LOOP_B_IN: J901.6 (Contact_06); also elsewhere on the board
/TI_GPIO_LOOP_B_OUT: J901.5 (Contact_05); also elsewhere on the board
/TI_I2C_FB: J900.18 (Contact_18); also elsewhere on the board
/TI_I2C_INT: J900.19 (Contact_19); also elsewhere on the board
/TI_I2C_SCL: J900.17 (Contact_17); also elsewhere on the board
/TI_I2C_SDA: J900.15 (Contact_15); also elsewhere on the board
/TI_ONEWIRE_DQ: J901.14 (Contact_14); also elsewhere on the board
/TI_ONEWIRE_GPIO_A_FB: J901.15 (Contact_15); also elsewhere on the board
/TI_ONEWIRE_GPIO_B_FB: J901.17 (Contact_17); also elsewhere on the board
/TI_RGB_DATA: J900.14 (Contact_14); also elsewhere on the board
/TI_SPI_CS_ADC: J901.11 (Contact_11); also elsewhere on the board
/TI_SPI_CS_EXT: J901.13 (Contact_13); also elsewhere on the board
/TI_SPI_MISO: J901.10 (Contact_10); also elsewhere on the board
/TI_SPI_MOSI: J901.9 (Contact_09); also elsewhere on the board
/TI_SPI_SCK: J901.7 (Contact_07); also elsewhere on the board
/TI_SWITCHED_TARGET_5V: J900.23 (Contact_23), J901.23 (Contact_23); also elsewhere on the board
/TI_TARGET_3V3: J900.1 (Contact_01), J901.1 (Contact_01); also elsewhere on the board
/TI_TARGET_RESET_N: J900.11 (Contact_11); also elsewhere on the board
/TI_UART_A_RX: J901.19 (Contact_19); also elsewhere on the board
/TI_UART_A_TX: J901.18 (Contact_18); also elsewhere on the board
/TI_UART_B_RX: J901.22 (Contact_22); also elsewhere on the board
/TI_UART_B_TX: J901.21 (Contact_21); also elsewhere on the board
unnamed: JBP2.2, JBP2.4, JBP2.6, JBP2.8, JBP2.10, JBP2.12
TI_GND: J2.4 (GND), J900.2 (Contact_02), J900.8 (Contact_08), J900.12 (Contact_12), J900.16 (Contact_16), J900.20 (Contact_20), J900.24 (Contact_24), J901.2 (Contact_02), J901.8 (Contact_08), J901.12 (Contact_12), J901.16 (Contact_16), J901.20 (Contact_20), J901.24 (Contact_24), JBP1.2, JBP1.4, JBP1.6, JBP1.8, JBP1.10, JBP1.12; also elsewhere on the board

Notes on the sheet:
Male 2x6 header for the Rev-A draft; three contacts per supply with adjacent returns
Rack Control Grove interface
TARGET INTERFACE — COPLANAR HARNESS/DAUGHTER CONNECTION J900/J901: harness-side 2x12 right-angle female sockets, cut from Adafruit 1543; mandatory post-AISLER hand-fit. Daughter board uses mating 2x12 male sections cut from Adafruit 1541. Connector A/B positions are asymmetrically offset for orient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
RACK POWER BACKPLANE INTERFACE - PROVISIONAL
Target Interface pin banks
Rev-A Reusable Harness Board
EXT_3V3 The external regulated 3.3 V supply entry TI_TARGET_3V3 Target Interface TI_TARGET_3V3 TEST_BLOCK_POWER_EN Rack Control Endpoint control output ROUTING_LOGIC_3V3 Matching inputs on Routing_Control and Standard_Test_Blocks TEST_BLOCK_3V3 Matching inputs on Routing_Control and Standard_Test_B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
Rack Backplane Interface

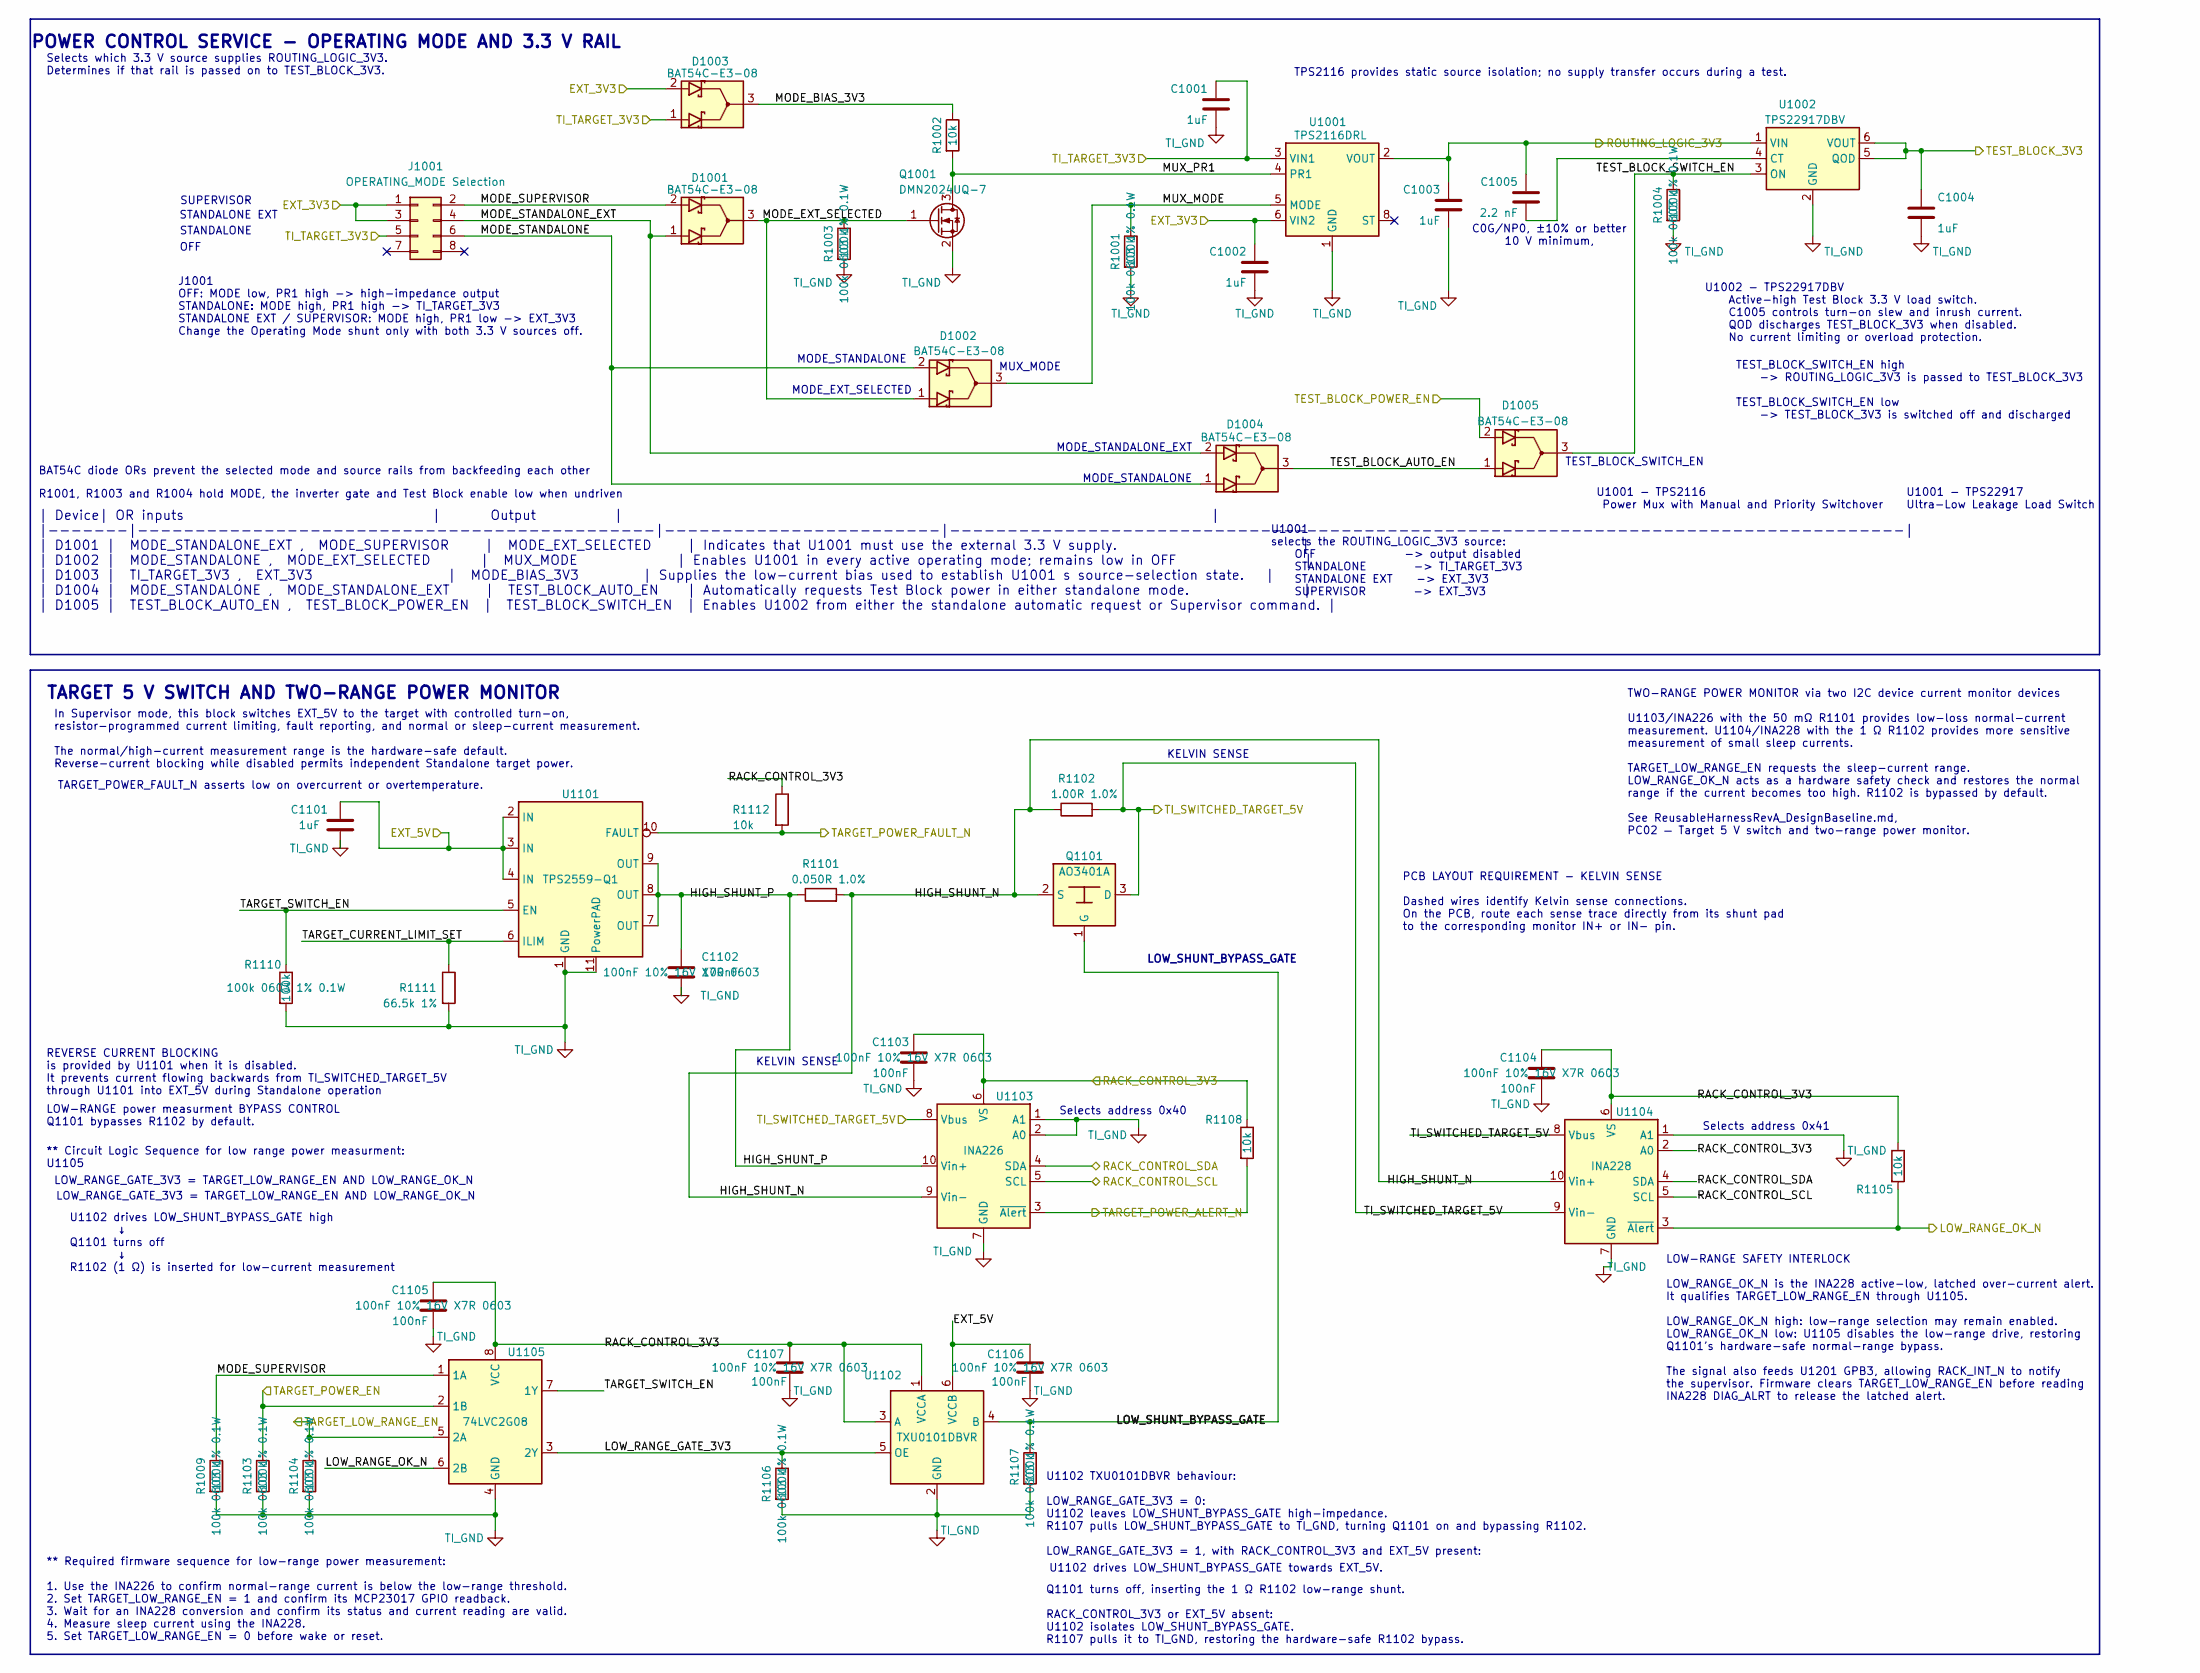
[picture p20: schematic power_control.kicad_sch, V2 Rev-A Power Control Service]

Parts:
C1001, C1002, C1003, C1004, C1101: 1uF; C_0603_1608Metric
C1005: 2.2 nF; C_0603_1608Metric
C1102, C1103, C1104, C1105, C1106, C1107: 100nF; C_0603_1608Metric
D1001, D1002, D1003, D1004, D1005: BAT54C-E3-08; SOT-23
J1001: OPERATING_MODE Selection; PinHeader_2x04_P2.54mm_Vertical
Q1001: DMN2024UQ-7; SOT-23
Q1101: AO3401A; SOT-23
R1001, R1003, R1004, R1009, R1103, R1104, R1106, R1107, R1110: 100k; R_0603_1608Metric
R1002, R1105, R1108, R1112: 10k; R_0603_1608Metric
R1101: 0.050R 1.0%; R_0603_1608Metric
R1102: 1.00R 1.0%; R_0603_1608Metric
R1111: 66.5k 1%; R_0603_1608Metric
U1001: TPS2116DRL; SOT-583-8
U1002: TPS22917DBV; SOT-23-6
U1101: TPS2559-Q1; TPS2559Q1_DRC0010K_VSON10_EP
U1102: TXU0101DBVR; SOT-23-6
U1103: INA226; VSSOP-10_3x3mm_P0.5mm
U1104: INA228; VSSOP-10_3x3mm_P0.5mm
U1105: 74LVC2G08; VSSOP-8_2.3x2mm_P0.5mm

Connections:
/EXT_3V3: C1002.2, D1003.2 (A2), J1001.1, J1001.3, U1001.6 (VIN2); also elsewhere on the board
/EXT_5V: C1101.1, C1106.1, U1101.2 (IN), U1101.3 (IN), U1101.4 (IN), U1102.6 (VCCB); also elsewhere on the board
/LOW_RANGE_OK_N: R1105.2, U1104.3 (~Alert), U1105.6 (2B); also elsewhere on the board
/Power_Control/HIGH_SHUNT_N: Q1101.2 (S), R1101.2, R1102.1, U1103.9 (Vin-), U1104.10 (Vin+)
/Power_Control/HIGH_SHUNT_P: C1102.1, R1101.1, U1101.7 (OUT), U1101.8 (OUT), U1101.9 (OUT), U1103.10 (Vin+)
/Power_Control/LOW_RANGE_GATE_3V3: R1106.1, U1102.5 (OE), U1105.3 (2Y)
/Power_Control/LOW_SHUNT_BYPASS_GATE: Q1101.1 (G), R1107.1, U1102.4 (B)
/Power_Control/MODE_BIAS_3V3: D1003.3 (K), R1002.1
/Power_Control/MODE_EXT_SELECTED: D1001.3 (K), D1002.1 (A1), Q1001.1 (G), R1003.1
/Power_Control/MODE_STANDALONE: D1002.2 (A2), D1004.1 (A1), J1001.6
/Power_Control/MODE_STANDALONE_EXT: D1001.1 (A1), D1004.2 (A2), J1001.4
/Power_Control/MODE_SUPERVISOR: D1001.2 (A2), J1001.2, R1009.1, U1105.1 (1A)
/Power_Control/MUX_MODE: D1002.3 (K), R1001.1, U1001.5 (MODE)
/Power_Control/MUX_PR1: Q1001.3 (D), R1002.2, U1001.4 (PR1)
/Power_Control/TARGET_CURRENT_LIMIT_SET: R1111.1, U1101.6 (ILIM)
/Power_Control/TARGET_SWITCH_EN: R1110.1, U1101.5 (EN), U1105.7 (1Y)
/Power_Control/TEST_BLOCK_AUTO_EN: D1004.3 (K), D1005.1 (A1)
/Power_Control/TEST_BLOCK_SWITCH_EN: D1005.3 (K), R1004.1, U1002.3 (ON)
/RACK_CONTROL_3V3: C1103.1, C1104.1, C1105.1, C1107.1, R1105.1, R1108.1, R1112.1, U1102.1 (VCCA), U1102.3 (A), U1103.6 (VS), U1104.2 (A0), U1104.6 (VS), U1105.8 (VCC); also elsewhere on the board
/RACK_CONTROL_SCL: U1103.5 (SCL), U1104.5 (SCL); also elsewhere on the board
/RACK_CONTROL_SDA: U1103.4 (SDA), U1104.4 (SDA); also elsewhere on the board
/ROUTING_LOGIC_3V3: C1003.2, C1005.2, U1001.2 (VOUT), U1001.7 (VOUT), U1002.1 (VIN); also elsewhere on the board
/TARGET_LOW_RANGE_EN: R1104.1, U1105.5 (2A); also elsewhere on the board
/TARGET_POWER_ALERT_N: R1108.2, U1103.3 (~Alert); also elsewhere on the board
/TARGET_POWER_EN: R1103.1, U1105.2 (1B); also elsewhere on the board
/TARGET_POWER_FAULT_N: R1112.2, U1101.10 (FAULT); also elsewhere on the board
/TEST_BLOCK_3V3: C1004.1, U1002.5 (QOD), U1002.6 (VOUT); also elsewhere on the board
/TEST_BLOCK_POWER_EN: D1005.2 (A2); also elsewhere on the board
/TI_SWITCHED_TARGET_5V: Q1101.3 (D), R1102.2, U1103.8 (Vbus), U1104.8 (Vbus), U1104.9 (Vin-); also elsewhere on the board
/TI_TARGET_3V3: C1001.2, D1003.1 (A1), J1001.5, U1001.3 (VIN1); also elsewhere on the board
unnamed: C1005.1, U1002.4 (CT)
TI_GND: C1001.1, C1002.1, C1003.1, C1004.2, C1101.2, C1102.2, C1103.2, C1104.2, C1105.2, C1106.2, C1107.2, Q1001.2 (S), R1001.2, R1003.2, R1004.2, R1009.2, R1103.2, R1104.2, R1106.2, R1107.2, R1110.2, R1111.2, U1001.1 (GND), U1002.2 (GND), U1101.1 (GND), U1101.11 (PowerPAD), U1102.2 (GND), U1103.1 (A1), U1103.2 (A0), U1103.7 (GND), U1104.1 (A1), U1104.7 (GND), U1105.4 (GND); also elsewhere on the board

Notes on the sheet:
U1102 TXU0101DBVR behaviour: LOW_RANGE_GATE_3V3 = 0: U1102 leaves LOW_SHUNT_BYPASS_GATE high-impedance. R1107 pulls LOW_SHUNT_BYPASS_GATE to TI_GND, turning Q1101 on and bypassing R1102. LOW_RANGE_GATE_3V3 = 1, with RACK_CONTROL_3V3 and EXT_5V present:
STANDALONE EXT
U1001 - TPS2116 Power Mux with Manual and Priority Switchover
KELVIN SENSE
STANDALONE
Selects address 0x41
LOW-RANGE power measurment BYPASS CONTROL Q1101 bypasses R1102 by default.
MUX_MODE
LOW_RANGE_GATE_3V3 = TARGET_LOW_RANGE_EN AND LOW_RANGE_OK_N
POWER CONTROL SERVICE - OPERATING MODE AND 3.3 V RAIL
** Circuit Logic Sequence for low range power measurment: U1105
MODE_STANDALONE_EXT
Selects which 3.3 V source supplies ROUTING_LOGIC_3V3. Determines if that rail is passed on to TEST_BLOCK_3V3.
TWO-RANGE POWER MONITOR via two I2C device current monitor devices U1103/INA226 with the 50 mΩ R1101 provides low-loss normal-current measurement. U1104/INA228 with the 1 Ω R1102 provides more sensitive measurement of small sleep currents. TARGET_LOW_RANGE_EN requests the sleep-current range. LOW_R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
U1102 drives LOW_SHUNT_BYPASS_GATE towards EXT_5V.
BAT54C diode ORs prevent the selected mode and source rails from backfeeding each other
TARGET_POWER_FAULT_N asserts low on overcurrent or overtemperature.
MODE_STANDALONE
U1002 - TPS22917DBV Active-high Test Block 3.3 V load switch. C1005 controls turn-on slew and inrush current. QOD discharges TEST_BLOCK_3V3 when disabled. No current limiting or overload protection.
OFF
Q1101 turns off, inserting the 1 Ω R1102 low-range shunt. RACK_CONTROL_3V3 or EXT_5V absent: U1102 isolates LOW_SHUNT_BYPASS_GATE. R1107 pulls it to TI_GND, restoring the hardware-safe R1102 bypass.
LOW_RANGE_GATE_3V3 = TARGET_LOW_RANGE_EN AND LOW_RANGE_OK_N
REVERSE CURRENT BLOCKING is provided by U1101 when it is disabled. It prevents current flowing backwards from TI_SWITCHED_TARGET_5V through U1101 into EXT_5V during Standalone operation
PCB LAYOUT REQUIREMENT - KELVIN SENSE Dashed wires identify Kelvin sense connections. On the PCB, route each sense trace directly from its shunt pad to the corresponding monitor IN+ or IN− pin.
TPS2116 provides static source isolation; no supply transfer occurs during a test.
J1001 OFF: MODE low, PR1 high -> high-impedance output STANDALONE: MODE high, PR1 high -> TI_TARGET_3V3 STANDALONE EXT / SUPERVISOR: MODE high, PR1 low -> EXT_3V3 Change the Operating Mode shunt only with both 3.3 V sources off.
SUPERVISOR
TARGET 5 V SWITCH AND TWO-RANGE POWER MONITOR
LOW_SHUNT_BYPASS_GATE
LOW-RANGE SAFETY INTERLOCK LOW_RANGE_OK_N is the INA228 active-low, latched over-current alert. It qualifies TARGET_LOW_RANGE_EN through U1105. LOW_RANGE_OK_N high: low-range selection may remain enabled. LOW_RANGE_OK_N low: U1105 disables the low-range drive, restoring Q1101’s hardware-safe normal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
TEST_BLOCK_SWITCH_EN high -> ROUTING_LOGIC_3V3 is passed to TEST_BLOCK_3V3 TEST_BLOCK_SWITCH_EN low -> TEST_BLOCK_3V3 is switched off and discharged
U1001 - TPS22917 Ultra-Low Leakage Load Switch
C0G/NP0, ±10% or better 10 V minimum,
TEST_BLOCK_SWITCH_EN
R1001, R1003 and R1004 hold MODE, the inverter gate and Test Block enable low when undriven
Selects address 0x40
MODE_EXT_SELECTED
| Device| OR inputs | Output | | |-------|---------------------------------------------|------------------------|-----------------------------------------------------------------------------------| | D1001 | MODE_STANDALONE_EXT , MODE_SUPERVISOR | MODE_EXT_SELECTED | Indicates that U1001 must use t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
** Required firmware sequence for low-range power measurement: 1. Use the INA226 to confirm normal-range current is below the low-range threshold. 2. Set TARGET_LOW_RANGE_EN = 1 and confirm its MCP23017 GPIO readback. 3. Wait for an INA228 conversion and confirm its status and current reading are v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
In Supervisor mode, this block switches EXT_5V to the target with controlled turn-on, resistor-programmed current limiting, fault reporting, and normal or sleep-current measurement. The normal/high-current measurement range is the hardware-safe default. Reverse-current blocking while disabled permi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

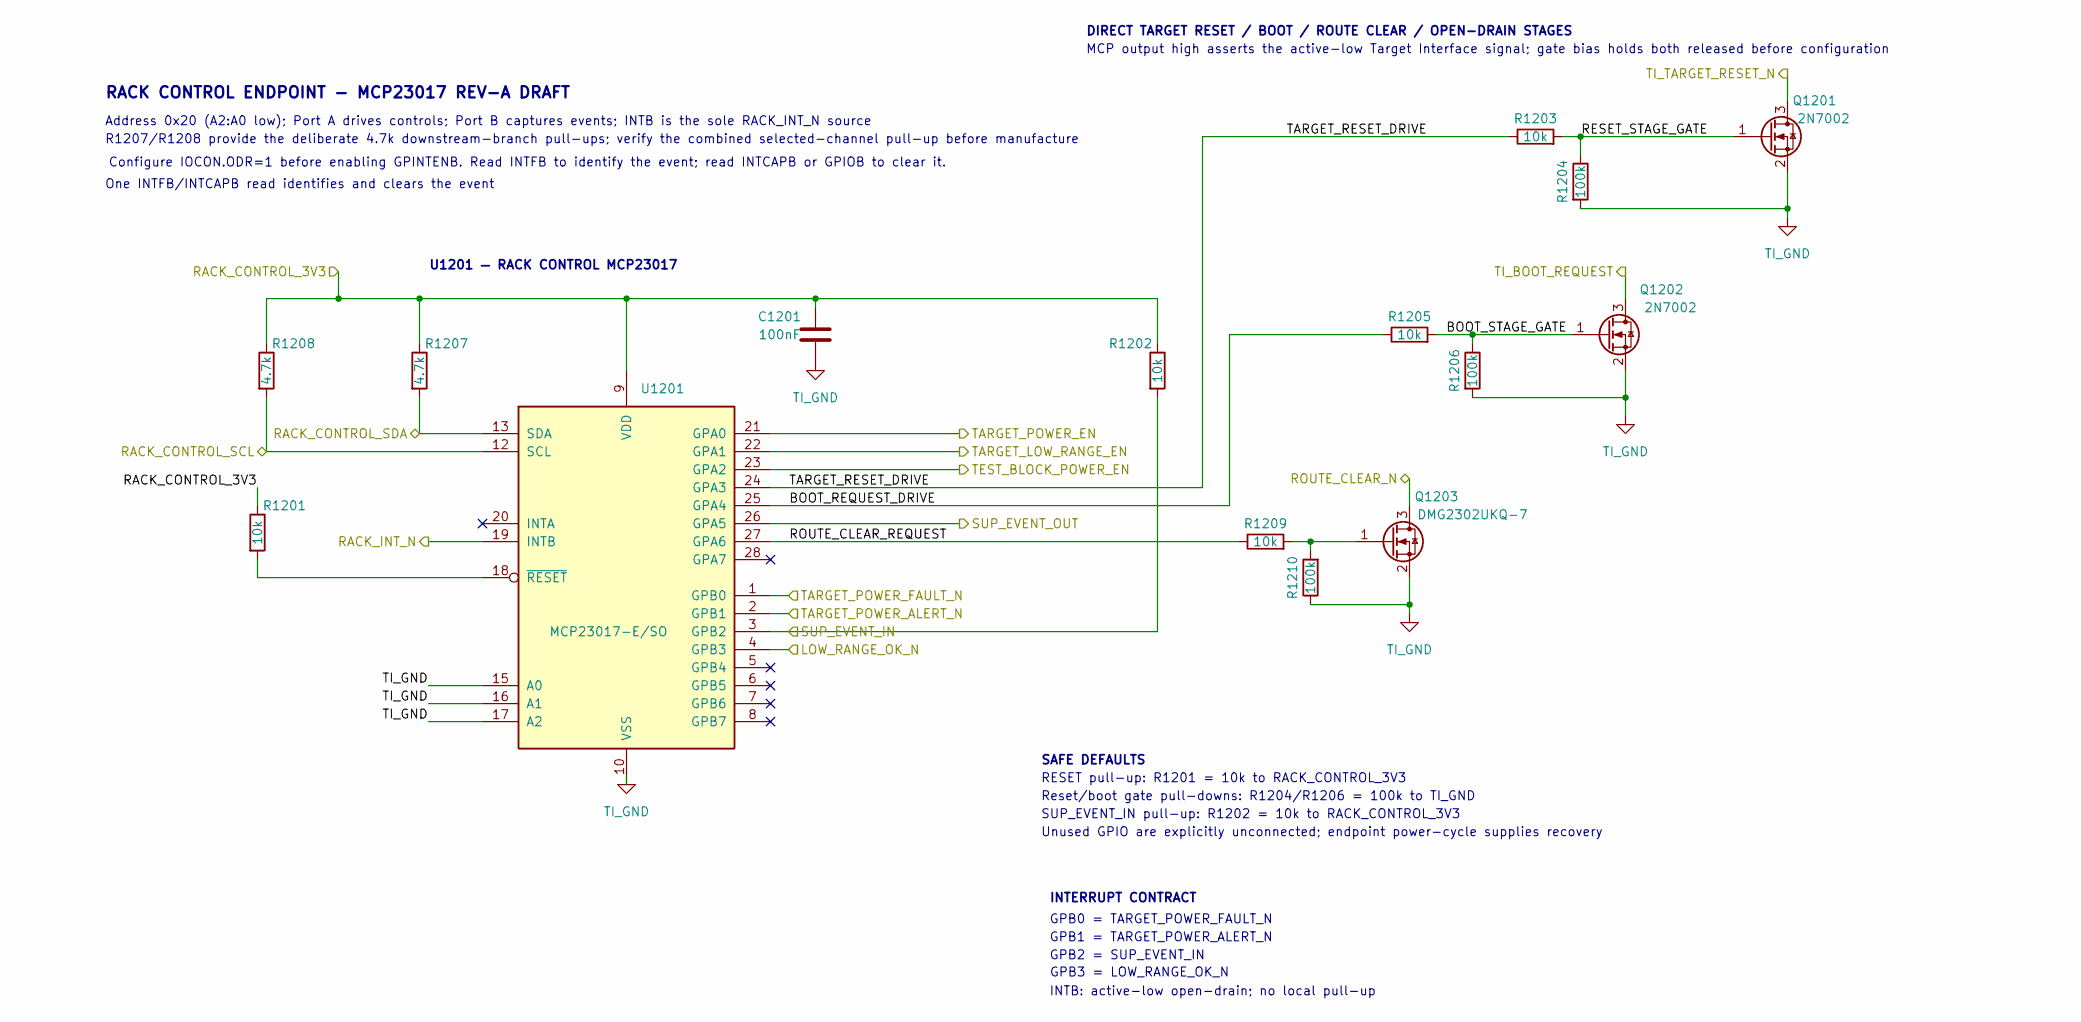
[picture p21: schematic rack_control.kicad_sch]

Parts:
C1201: 100nF; C_0603_1608Metric
Q1201, Q1202: 2N7002; SOT-23
Q1203: DMG2302UKQ-7; SOT-23; MPN DMG2302UKQ-7
R1201, R1202, R1203, R1205, R1209: 10k; R_0603_1608Metric
R1204, R1206, R1210: 100k; R_0603_1608Metric
R1207, R1208: 4.7k; R_0603_1608Metric
U1201: MCP23017-E/SO; SOIC-28W_7.5x17.9mm_P1.27mm

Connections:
/LOW_RANGE_OK_N: U1201.4 (GPB3); also elsewhere on the board
/RACK_CONTROL_3V3: C1201.1, R1201.1, R1202.1, R1207.1, R1208.1, U1201.9 (VDD); also elsewhere on the board
/RACK_CONTROL_SCL: R1208.2, U1201.12 (SCL); also elsewhere on the board
/RACK_CONTROL_SDA: R1207.2, U1201.13 (SDA); also elsewhere on the board
/RACK_INT_N: U1201.19 (INTB)
/ROUTE_CLEAR_N: Q1203.3 (D); also elsewhere on the board
/SUP_EVENT_IN: R1202.2, U1201.3 (GPB2); also elsewhere on the board
/SUP_EVENT_OUT: U1201.26 (GPA5); also elsewhere on the board
/TARGET_LOW_RANGE_EN: U1201.22 (GPA1); also elsewhere on the board
/TARGET_POWER_ALERT_N: U1201.2 (GPB1); also elsewhere on the board
/TARGET_POWER_EN: U1201.21 (GPA0); also elsewhere on the board
/TARGET_POWER_FAULT_N: U1201.1 (GPB0); also elsewhere on the board
/TEST_BLOCK_POWER_EN: U1201.23 (GPA2); also elsewhere on the board
/TI_BOOT_REQUEST: Q1202.3 (D); also elsewhere on the board
/TI_TARGET_RESET_N: Q1201.3 (D); also elsewhere on the board
/V2 Rev-A Rack Control Endpoint/BOOT_REQUEST_DRIVE: R1205.1, U1201.25 (GPA4)
/V2 Rev-A Rack Control Endpoint/BOOT_STAGE_GATE: Q1202.1 (G), R1205.2, R1206.1
/V2 Rev-A Rack Control Endpoint/RESET_STAGE_GATE: Q1201.1 (G), R1203.2, R1204.1
/V2 Rev-A Rack Control Endpoint/ROUTE_CLEAR_REQUEST: R1209.1, U1201.27 (GPA6)
/V2 Rev-A Rack Control Endpoint/TARGET_RESET_DRIVE: R1203.1, U1201.24 (GPA3)
unnamed: Q1203.1 (G), R1209.2, R1210.2
unnamed: R1201.2, U1201.18 (~RESET)
TI_GND: C1201.2, Q1201.2 (S), Q1202.2 (S), Q1203.2 (S), R1204.2, R1206.2, R1210.1, U1201.10 (VSS), U1201.15 (A0), U1201.16 (A1), U1201.17 (A2); also elsewhere on the board

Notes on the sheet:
GPB1 = TARGET_POWER_ALERT_N
MCP output high asserts the active-low Target Interface signal; gate bias holds both released before configuration
GPB2 = SUP_EVENT_IN
RACK CONTROL ENDPOINT - MCP23017 REV-A DRAFT
DIRECT TARGET RESET / BOOT / ROUTE CLEAR / OPEN-DRAIN STAGES
One INTFB/INTCAPB read identifies and clears the event
SAFE DEFAULTS
SUP_EVENT_IN pull-up: R1202 = 10k to RACK_CONTROL_3V3
Reset/boot gate pull-downs: R1204/R1206 = 100k to TI_GND
RESET pull-up: R1201 = 10k to RACK_CONTROL_3V3
GPB3 = LOW_RANGE_OK_N
INTB: active-low open-drain; no local pull-up
Unused GPIO are explicitly unconnected; endpoint power-cycle supplies recovery
GPB0 = TARGET_POWER_FAULT_N
Address 0x20 (A2:A0 low); Port A drives controls; Port B captures events; INTB is the sole RACK_INT_N source
R1207/R1208 provide the deliberate 4.7k downstream-branch pull-ups; verify the combined selected-channel pull-up before manufacture
U1201 — RACK CONTROL MCP23017
Configure IOCON.ODR=1 before enabling GPINTENB. Read INTFB to identify the event; read INTCAPB or GPIOB to clear it.
INTERRUPT CONTRACT

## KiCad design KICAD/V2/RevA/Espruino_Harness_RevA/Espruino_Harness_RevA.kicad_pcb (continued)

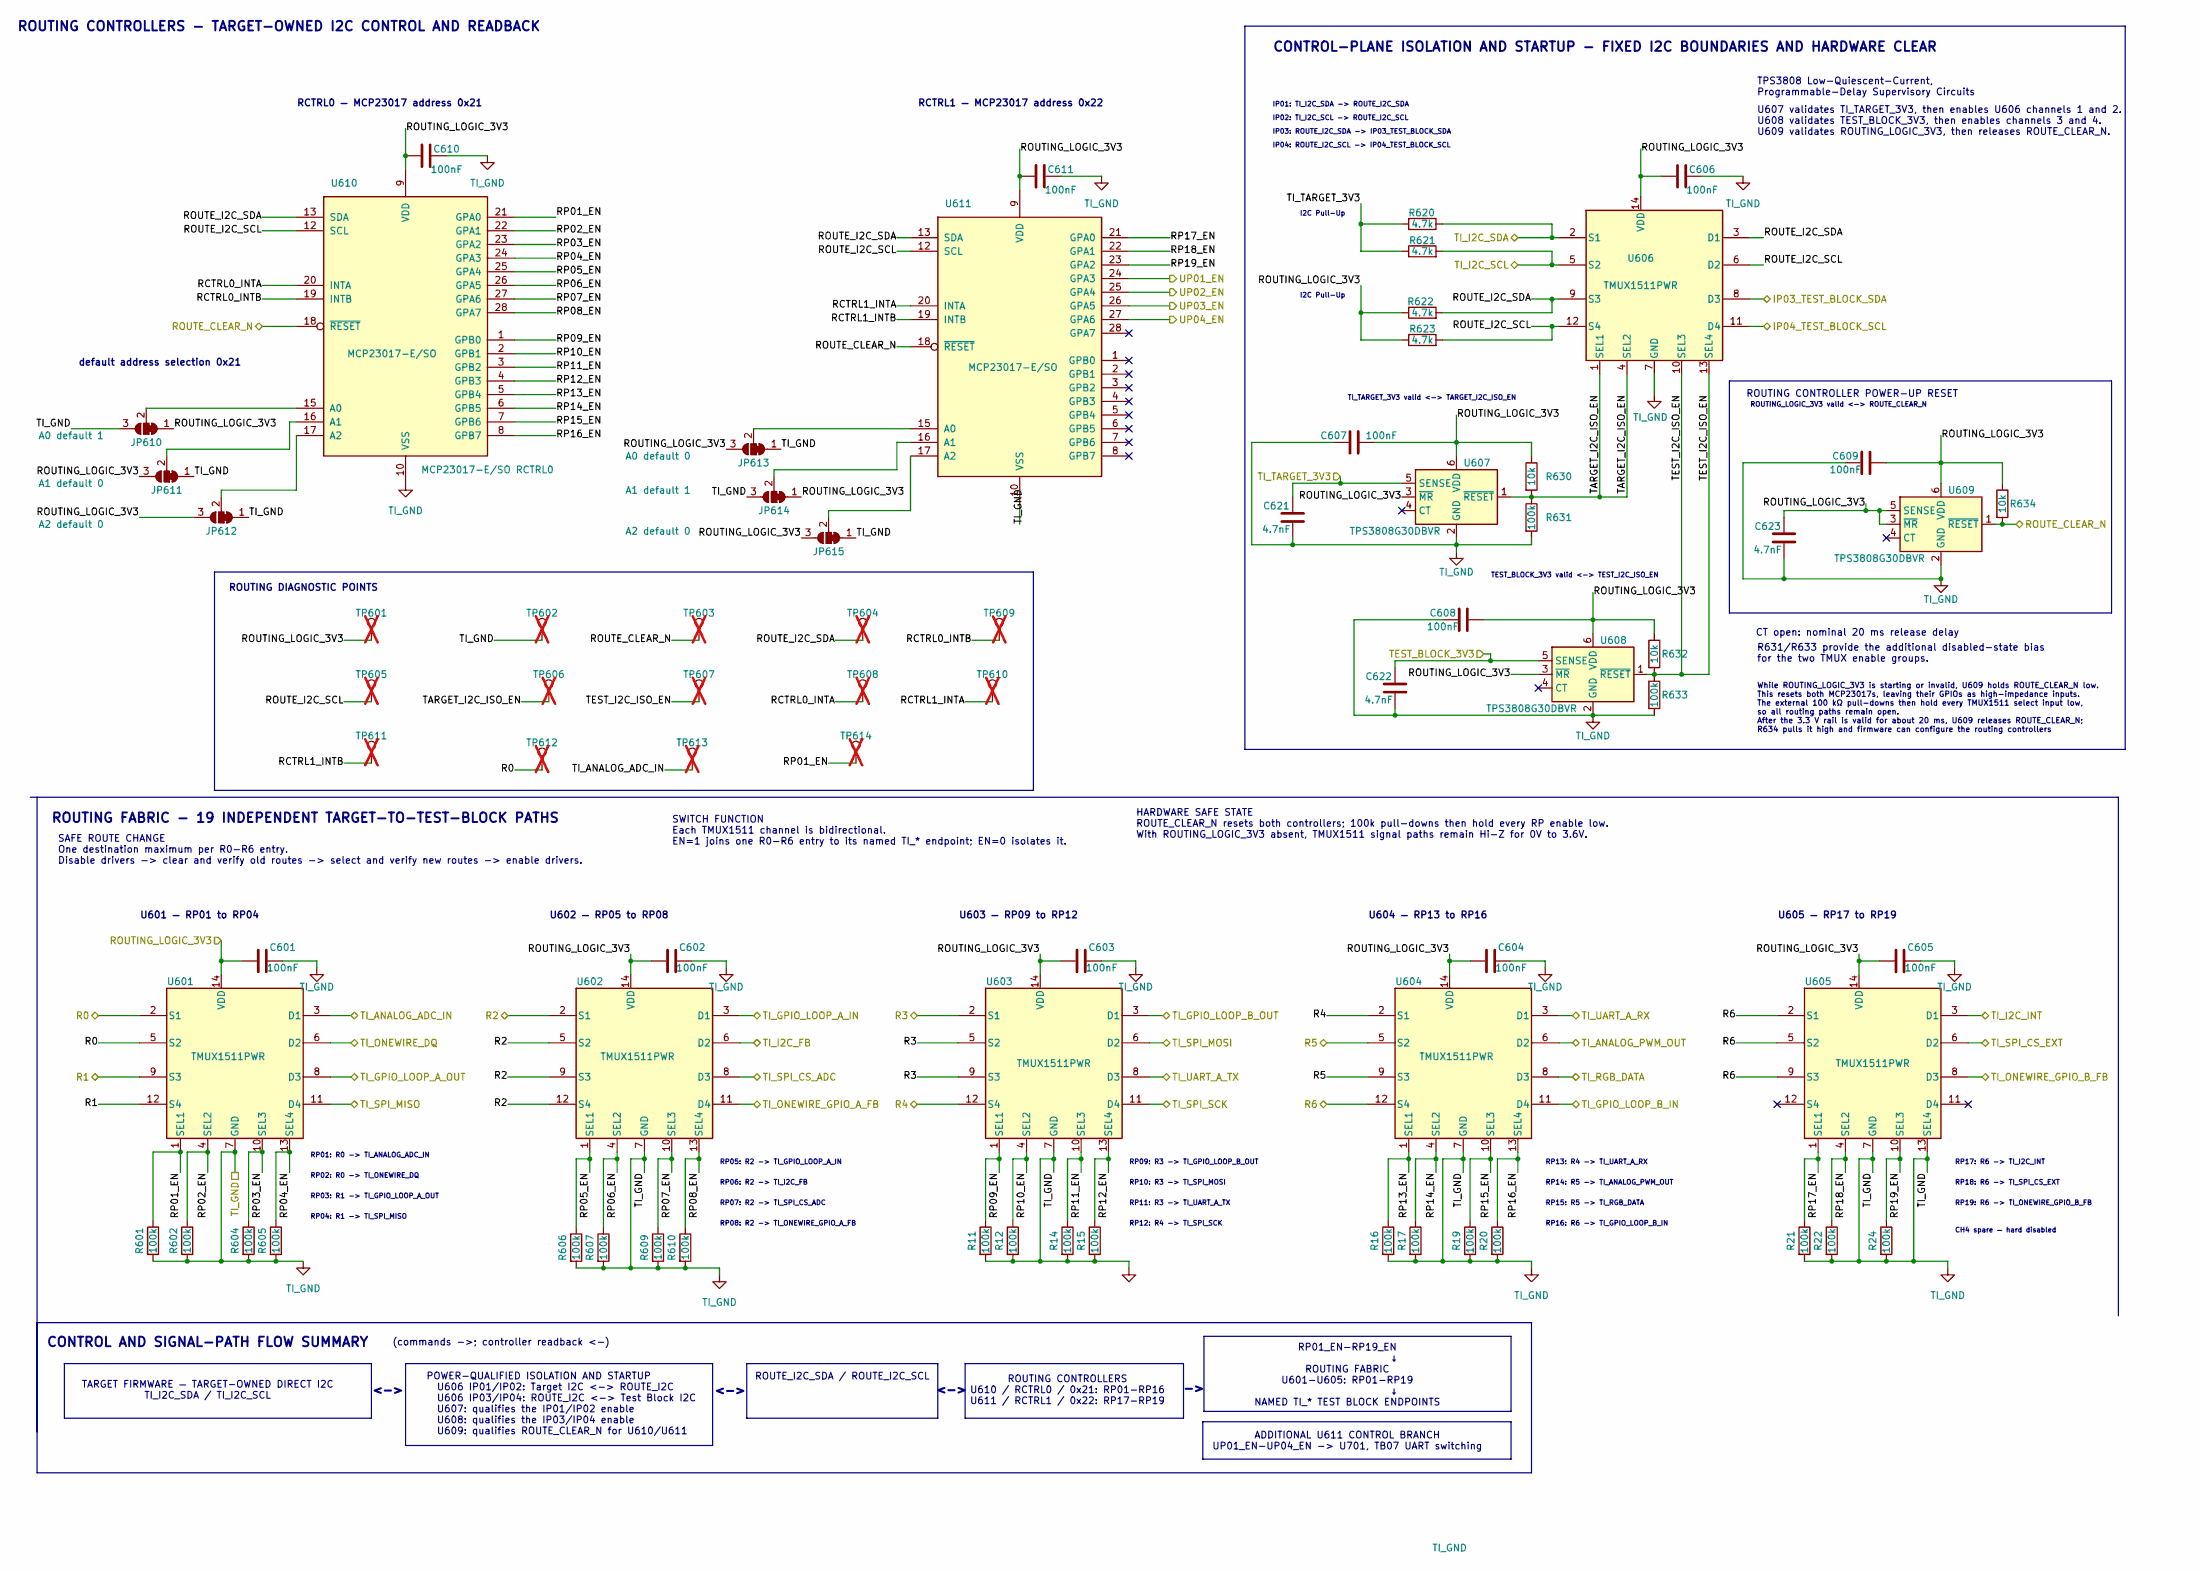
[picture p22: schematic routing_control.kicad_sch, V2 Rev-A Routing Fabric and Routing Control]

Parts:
C601, C602, C603, C604, C605, C606, C607, C608, C609, C610, C611: 100nF; C_0603_1608Metric
C621, C622, C623: 4.7nF; C_0603_1608Metric
JP610: A0 default 1; SolderJumper-3_P1.3mm_Bridged12_RoundedPad1.0x1.5mm_NumberL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
JP611: A1 default 0; SolderJumper-3_P1.3mm_Bridged12_RoundedPad1.0x1.5mm_NumberL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
JP612, JP615: A2 default 0; SolderJumper-3_P1.3mm_Bridged12_RoundedPad1.0x1.5mm_NumberL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
JP613: A0 default 0; SolderJumper-3_P1.3mm_Bridged12_RoundedPad1.0x1.5mm_NumberL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
JP614: A1 default 1; SolderJumper-3_P1.3mm_Bridged12_RoundedPad1.0x1.5mm_NumberL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
R11, R12, R14, R15, R16, R17, R19, R20, R21, R22, R24, R601, R602, R604, R605, R606, R607, R609, R610, R631, R633: 100k; R_0603_1608Metric
R620, R621, R622, R623: 4.7k; R_0603_1608Metric
R630, R632, R634: 10k; R_0603_1608Metric
TP601: ROUTING_LOGIC_3V3; PinHeader_1x01_P2.54mm_Vertical; MPN 61300111121; not fitted
TP602: TI_GND; PinHeader_1x01_P2.54mm_Vertical; MPN 61300111121; not fitted
TP603: ROUTE_CLEAR_N; PinHeader_1x01_P2.54mm_Vertical; MPN 61300111121; not fitted
TP604: ROUTE_I2C_SDA; PinHeader_1x01_P2.54mm_Vertical; MPN 61300111121; not fitted
TP605: ROUTE_I2C_SCL; PinHeader_1x01_P2.54mm_Vertical; MPN 61300111121; not fitted
TP606: TARGET_I2C_ISO_EN; PinHeader_1x01_P2.54mm_Vertical; MPN 61300111121; not fitted
TP607: TEST_I2C_ISO_EN; PinHeader_1x01_P2.54mm_Vertical; MPN 61300111121; not fitted
TP608: RCTRL0_INTA; PinHeader_1x01_P2.54mm_Vertical; MPN 61300111121; not fitted
TP609: RCTRL0_INTB; PinHeader_1x01_P2.54mm_Vertical; MPN 61300111121; not fitted
TP610: RCTRL1_INTA; PinHeader_1x01_P2.54mm_Vertical; MPN 61300111121; not fitted
TP611: RCTRL1_INTB; PinHeader_1x01_P2.54mm_Vertical; MPN 61300111121; not fitted
TP612: R0; PinHeader_1x01_P2.54mm_Vertical; MPN 61300111121; not fitted
TP613: TI_ANALOG_ADC_IN; PinHeader_1x01_P2.54mm_Vertical; MPN 61300111121; not fitted
TP614: RP01_EN; PinHeader_1x01_P2.54mm_Vertical; MPN 61300111121; not fitted
U601, U602, U603, U604, U605, U606: TMUX1511; TSSOP-14_4.4x5mm_P0.65mm; MPN TMUX1511PWR
U607, U608, U609: TPS3808G30DBVR; SOT-23-6; MPN TPS3808G30DBVR
U610: MCP23017-E/SO RCTRL0; SOIC-28W_7.5x17.9mm_P1.27mm; MPN MCP23017-E/SO
U611: MCP23017-E/SO RCTRL1; SOIC-28W_7.5x17.9mm_P1.27mm; MPN MCP23017-E/SO

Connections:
/IP03_TEST_BLOCK_SDA: U606.8 (D3); also elsewhere on the board
/IP04_TEST_BLOCK_SCL: U606.11 (D4); also elsewhere on the board
/R0: TP612.1, U601.2 (S1), U601.5 (S2); also elsewhere on the board
/R1: U601.9 (S3), U601.12 (S4); also elsewhere on the board
/R2: U602.2 (S1), U602.5 (S2), U602.9 (S3), U602.12 (S4); also elsewhere on the board
/R3: U603.2 (S1), U603.5 (S2), U603.9 (S3); also elsewhere on the board
/R4: U603.12 (S4), U604.2 (S1); also elsewhere on the board
/R5: U604.5 (S2), U604.9 (S3); also elsewhere on the board
/R6: U604.12 (S4), U605.2 (S1), U605.5 (S2), U605.9 (S3); also elsewhere on the board
/ROUTE_CLEAR_N: R634.2, TP603.1, U609.1 (~RESET), U610.18 (~RESET), U611.18 (~RESET); also elsewhere on the board
/ROUTING_LOGIC_3V3: C601.1, C602.1, C603.1, C604.1, C605.1, C606.1, C607.1, C608.1, C609.1, C610.1, C611.1, C623.1, JP610.1 (A), JP611.3 (B), JP612.3 (B), JP613.3 (B), JP614.1 (A), JP615.3 (B), R622.1, R623.1, R630.1, R632.1, R634.1, TP601.1, U601.14 (VDD), U602.14 (VDD), U603.14 (VDD), U604.14 (VDD), U605.14 (VDD), U606.14 (VDD), U607.3 (~MR), U607.6 (VDD), U608.3 (~MR), U608.6 (VDD), U609.3 (~MR), U609.5 (SENSE), U609.6 (VDD), U610.9 (VDD), U611.9 (VDD); also elsewhere on the board
/Routing_Control/RCTRL0_INTA: TP608.1, U610.20 (INTA)
/Routing_Control/RCTRL0_INTB: TP609.1, U610.19 (INTB)
/Routing_Control/RCTRL1_INTA: TP610.1, U611.20 (INTA)
/Routing_Control/RCTRL1_INTB: TP611.1, U611.19 (INTB)
/Routing_Control/ROUTE_I2C_SCL: R623.2, TP605.1, U606.6 (D2), U606.12 (S4), U610.12 (SCL), U611.12 (SCL)
/Routing_Control/ROUTE_I2C_SDA: R622.2, TP604.1, U606.3 (D1), U606.9 (S3), U610.13 (SDA), U611.13 (SDA)
/Routing_Control/RP01_EN: R601.1, TP614.1, U601.1 (SEL1), U610.21 (GPA0)
/Routing_Control/RP02_EN: R602.1, U601.4 (SEL2), U610.22 (GPA1)
/Routing_Control/RP03_EN: R604.1, U601.10 (SEL3), U610.23 (GPA2)
/Routing_Control/RP04_EN: R605.1, U601.13 (SEL4), U610.24 (GPA3)
/Routing_Control/RP05_EN: R606.1, U602.1 (SEL1), U610.25 (GPA4)
/Routing_Control/RP06_EN: R607.1, U602.4 (SEL2), U610.26 (GPA5)
/Routing_Control/RP07_EN: R609.1, U602.10 (SEL3), U610.27 (GPA6)
/Routing_Control/RP08_EN: R610.1, U602.13 (SEL4), U610.28 (GPA7)
/Routing_Control/RP09_EN: R11.1, U603.1 (SEL1), U610.1 (GPB0)
/Routing_Control/RP10_EN: R12.1, U603.4 (SEL2), U610.2 (GPB1)
/Routing_Control/RP11_EN: R14.1, U603.10 (SEL3), U610.3 (GPB2)
/Routing_Control/RP12_EN: R15.1, U603.13 (SEL4), U610.4 (GPB3)
/Routing_Control/RP13_EN: R16.1, U604.1 (SEL1), U610.5 (GPB4)
/Routing_Control/RP14_EN: R17.1, U604.4 (SEL2), U610.6 (GPB5)
/Routing_Control/RP15_EN: R19.1, U604.10 (SEL3), U610.7 (GPB6)
/Routing_Control/RP16_EN: R20.1, U604.13 (SEL4), U610.8 (GPB7)
/Routing_Control/RP17_EN: R21.1, U605.1 (SEL1), U611.21 (GPA0)
/Routing_Control/RP18_EN: R22.1, U605.4 (SEL2), U611.22 (GPA1)
/Routing_Control/RP19_EN: R24.1, U605.10 (SEL3), U611.23 (GPA2)
/Routing_Control/TARGET_I2C_ISO_EN: R630.2, R631.1, TP606.1, U606.1 (SEL1), U606.4 (SEL2), U607.1 (~RESET)
/Routing_Control/TEST_I2C_ISO_EN: R632.2, R633.1, TP607.1, U606.10 (SEL3), U606.13 (SEL4), U608.1 (~RESET)
/TEST_BLOCK_3V3: C622.1, U608.5 (SENSE); also elsewhere on the board
/TI_ANALOG_ADC_IN: TP613.1, U601.3 (D1); also elsewhere on the board
/TI_ANALOG_PWM_OUT: U604.6 (D2); also elsewhere on the board
/TI_GPIO_LOOP_A_IN: U602.3 (D1); also elsewhere on the board
/TI_GPIO_LOOP_A_OUT: U601.8 (D3); also elsewhere on the board
/TI_GPIO_LOOP_B_IN: U604.11 (D4); also elsewhere on the board
/TI_GPIO_LOOP_B_OUT: U603.3 (D1); also elsewhere on the board
/TI_I2C_FB: U602.6 (D2); also elsewhere on the board
/TI_I2C_INT: U605.3 (D1); also elsewhere on the board
/TI_I2C_SCL: R621.2, U606.5 (S2); also elsewhere on the board
/TI_I2C_SDA: R620.1, U606.2 (S1); also elsewhere on the board
/TI_ONEWIRE_DQ: U601.6 (D2); also elsewhere on the board
/TI_ONEWIRE_GPIO_A_FB: U602.11 (D4); also elsewhere on the board
/TI_ONEWIRE_GPIO_B_FB: U605.8 (D3); also elsewhere on the board
/TI_RGB_DATA: U604.8 (D3); also elsewhere on the board
/TI_SPI_CS_ADC: U602.8 (D3); also elsewhere on the board
/TI_SPI_CS_EXT: U605.6 (D2); also elsewhere on the board
/TI_SPI_MISO: U601.11 (D4); also elsewhere on the board
/TI_SPI_MOSI: U603.6 (D2); also elsewhere on the board
/TI_SPI_SCK: U603.11 (D4); also elsewhere on the board
/TI_TARGET_3V3: C621.1, R620.2, R621.1, U607.5 (SENSE); also elsewhere on the board
/TI_UART_A_RX: U604.3 (D1); also elsewhere on the board
/TI_UART_A_TX: U603.8 (D3); also elsewhere on the board
/UP01_EN: U611.24 (GPA3); also elsewhere on the board
/UP02_EN: U611.25 (GPA4); also elsewhere on the board
/UP03_EN: U611.26 (GPA5); also elsewhere on the board
/UP04_EN: U611.27 (GPA6); also elsewhere on the board
unnamed: JP610.2 (C), U610.15 (A0)
unnamed: JP611.2 (C), U610.16 (A1)
unnamed: JP612.2 (C), U610.17 (A2)
unnamed: JP613.2 (C), U611.15 (A0)
unnamed: JP614.2 (C), U611.16 (A1)
unnamed: JP615.2 (C), U611.17 (A2)
TI_GND: C601.2, C602.2, C603.2, C604.2, C605.2, C606.2, C607.2, C608.2, C609.2, C610.2, C611.2, C621.2, C622.2, C623.2, JP610.3 (B), JP611.1 (A), JP612.1 (A), JP613.1 (A), JP614.3 (B), JP615.1 (A), R11.2, R12.2, R14.2, R15.2, R16.2, R17.2, R19.2, R20.2, R21.2, R22.2, R24.2, R601.2, R602.2, R604.2, R605.2, R606.2, R607.2, R609.2, R610.2, R631.2, R633.2, TP602.1, U601.7 (GND), U602.7 (GND), U603.7 (GND), U604.7 (GND), U605.7 (GND), U605.13 (SEL4), U606.7 (GND), U607.2 (GND), U608.2 (GND), U609.2 (GND), U610.10 (VSS), U611.10 (VSS); also elsewhere on the board

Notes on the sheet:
<->
U607 validates TI_TARGET_3V3, then enables U606 channels 1 and 2. U608 validates TEST_BLOCK_3V3, then enables channels 3 and 4. U609 validates ROUTING_LOGIC_3V3, then releases ROUTE_CLEAR_N.
RP08: R2 -> TI_ONEWIRE_GPIO_A_FB
RP01_EN-RP19_EN ↓ ROUTING FABRIC U601-U605: RP01-RP19 ↓ NAMED TI_* TEST BLOCK ENDPOINTS ADDITIONAL U611 CONTROL BRANCH UP01_EN-UP04_EN -> U701, TB07 UART switching
ROUTING DIAGNOSTIC POINTS
CONTROL AND SIGNAL-PATH FLOW SUMMARY
IP04: ROUTE_I2C_SCL -> IP04_TEST_BLOCK_SCL
default address selection 0x21
RCTRL0 — MCP23017 address 0x21
RP10: R3 -> TI_SPI_MOSI
ROUTING_LOGIC_3V3 valid <-> ROUTE_CLEAR_N
RP09: R3 -> TI_GPIO_LOOP_B_OUT
RCTRL1 — MCP23017 address 0x22
RP01: R0 -> TI_ANALOG_ADC_IN
U603 — RP09 to RP12
RP06: R2 -> TI_I2C_FB
RP16: R6 -> TI_GPIO_LOOP_B_IN
(commands ->; controller readback <-)
TPS3808 Low-Quiescent-Current, Programmable-Delay Supervisory Circuits
CT open: nominal 20 ms release delay
IP01: TI_I2C_SDA -> ROUTE_I2C_SDA
U602 — RP05 to RP08
IP03: ROUTE_I2C_SDA -> IP03_TEST_BLOCK_SDA
POWER-QUALIFIED ISOLATION AND STARTUP U606 IP01/IP02: Target I2C <-> ROUTE_I2C U606 IP03/IP04: ROUTE_I2C <-> Test Block I2C U607: qualifies the IP01/IP02 enable U608: qualifies the IP03/IP04 enable U609: qualifies ROUTE_CLEAR_N for U610/U611
RP19: R6 -> TI_ONEWIRE_GPIO_B_FB
RP02: R0 -> TI_ONEWIRE_DQ
ROUTE_I2C_SDA / ROUTE_I2C_SCL
I2C Pull-Up
RP15: R5 -> TI_RGB_DATA
RP04: R1 -> TI_SPI_MISO
RP03: R1 -> TI_GPIO_LOOP_A_OUT
HARDWARE SAFE STATE ROUTE_CLEAR_N resets both controllers; 100k pull-downs then hold every RP enable low. With ROUTING_LOGIC_3V3 absent, TMUX1511 signal paths remain Hi-Z for 0V to 3.6V.
RP12: R4 -> TI_SPI_SCK
TEST_BLOCK_3V3 valid <-> TEST_I2C_ISO_EN
U605 — RP17 to RP19
RP11: R3 -> TI_UART_A_TX
RP07: R2 -> TI_SPI_CS_ADC
RP05: R2 -> TI_GPIO_LOOP_A_IN
CONTROL-PLANE ISOLATION AND STARTUP - FIXED I2C BOUNDARIES AND HARDWARE CLEAR
RP17: R6 -> TI_I2C_INT

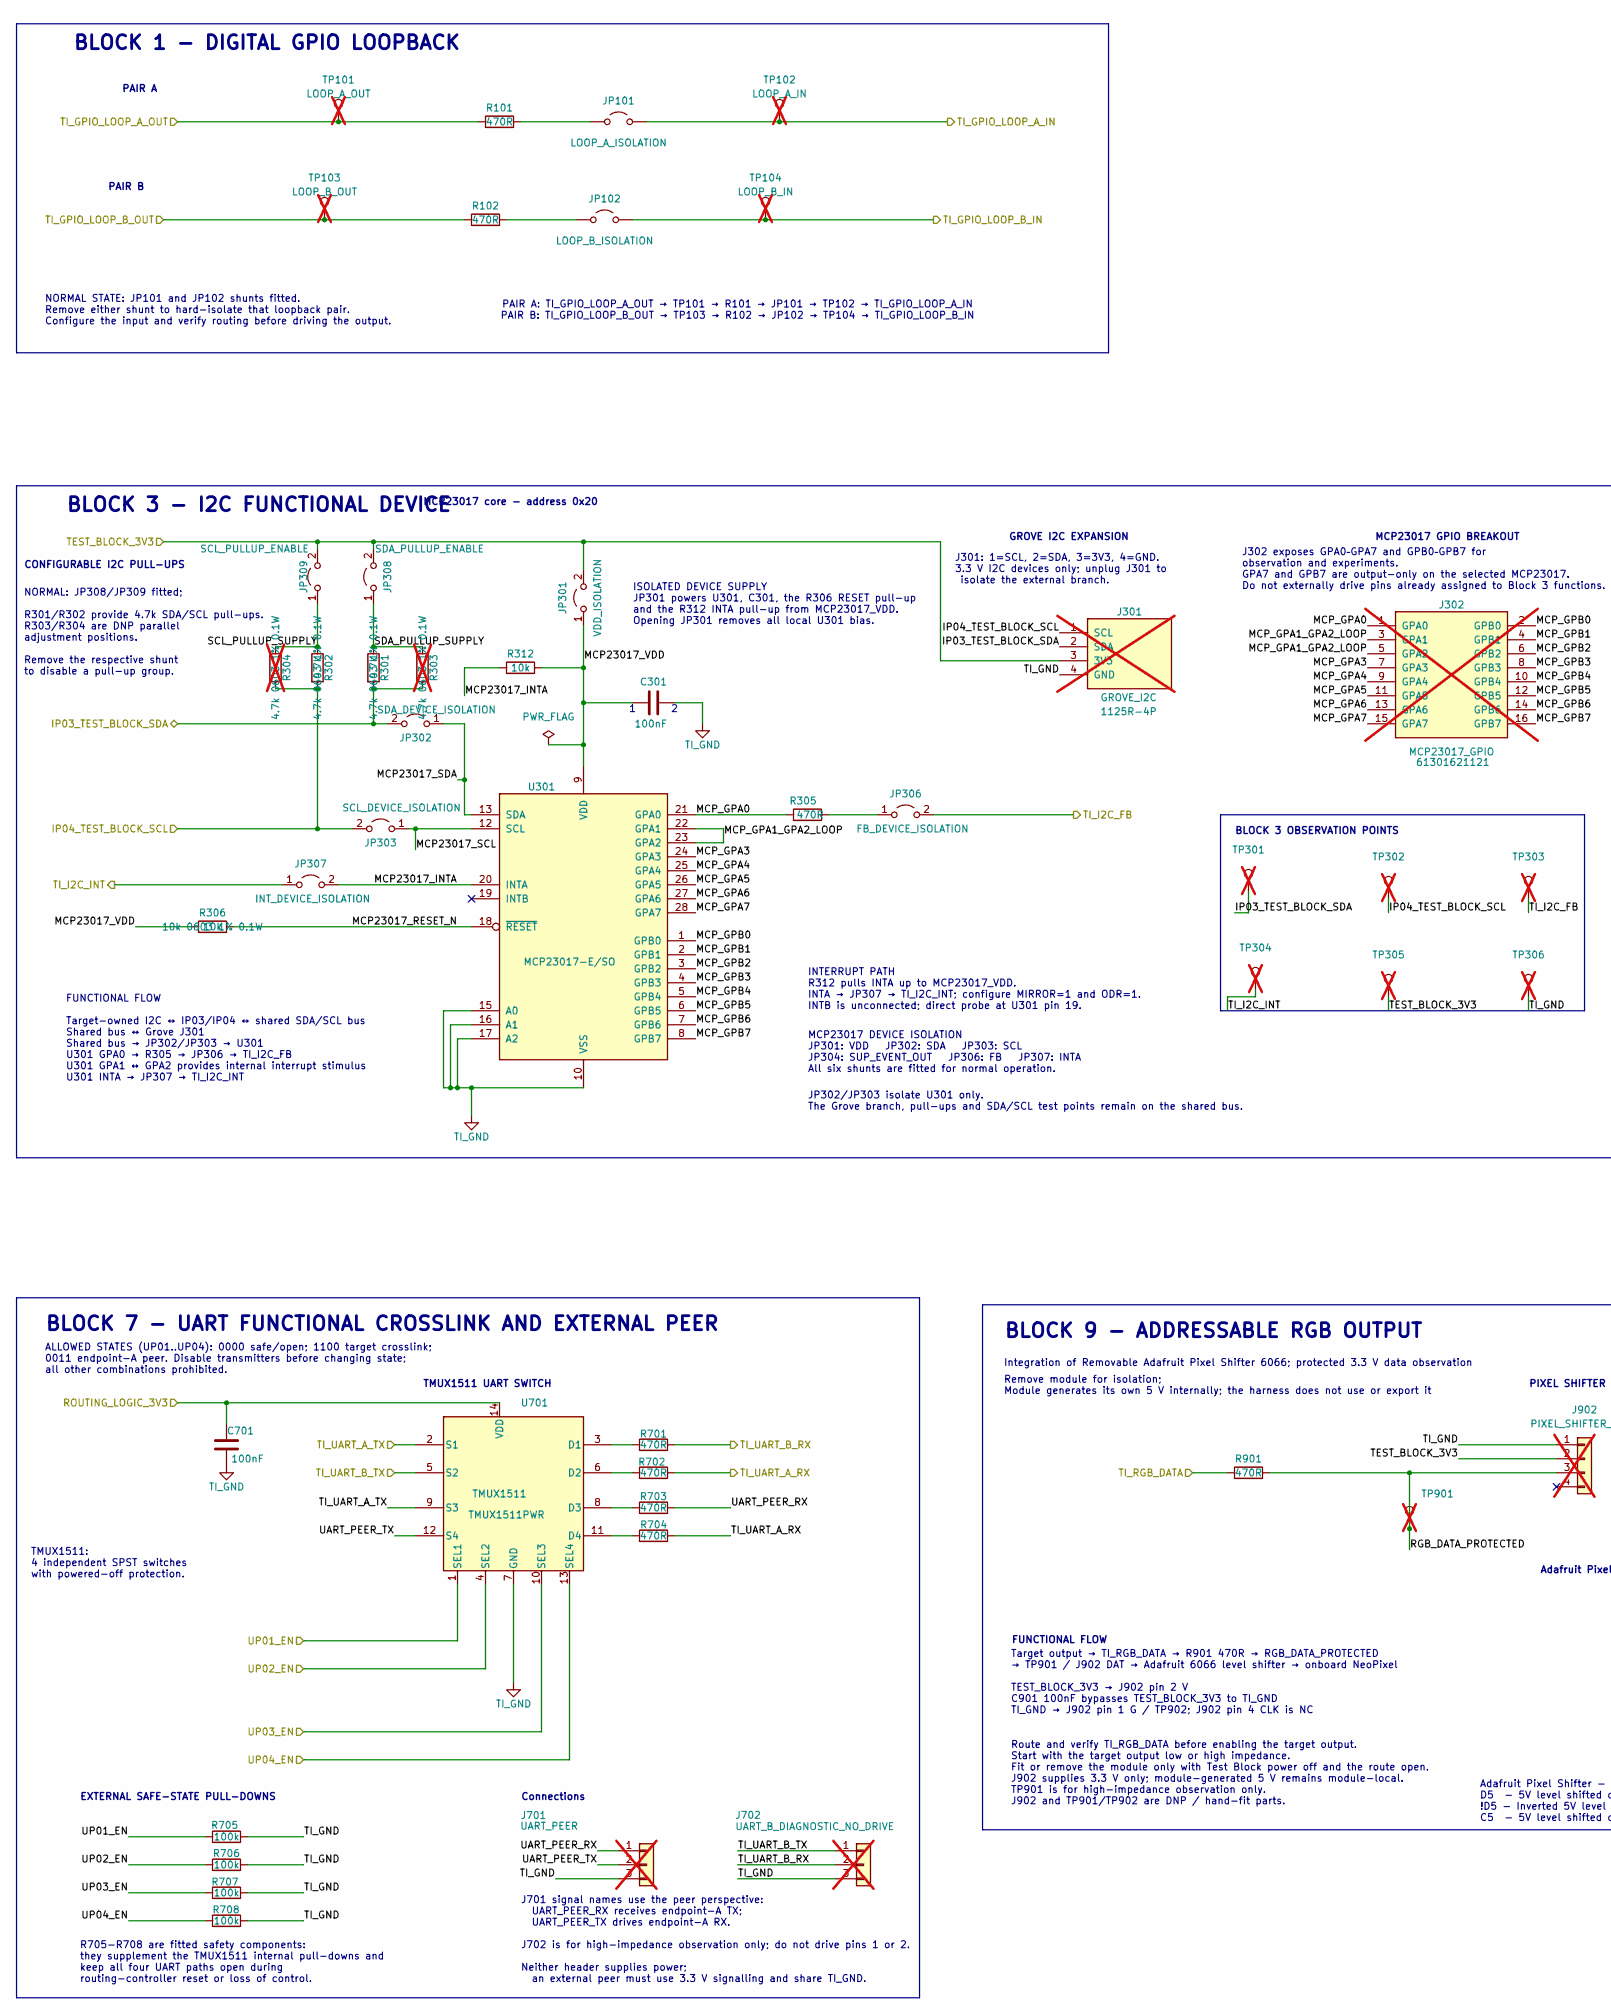
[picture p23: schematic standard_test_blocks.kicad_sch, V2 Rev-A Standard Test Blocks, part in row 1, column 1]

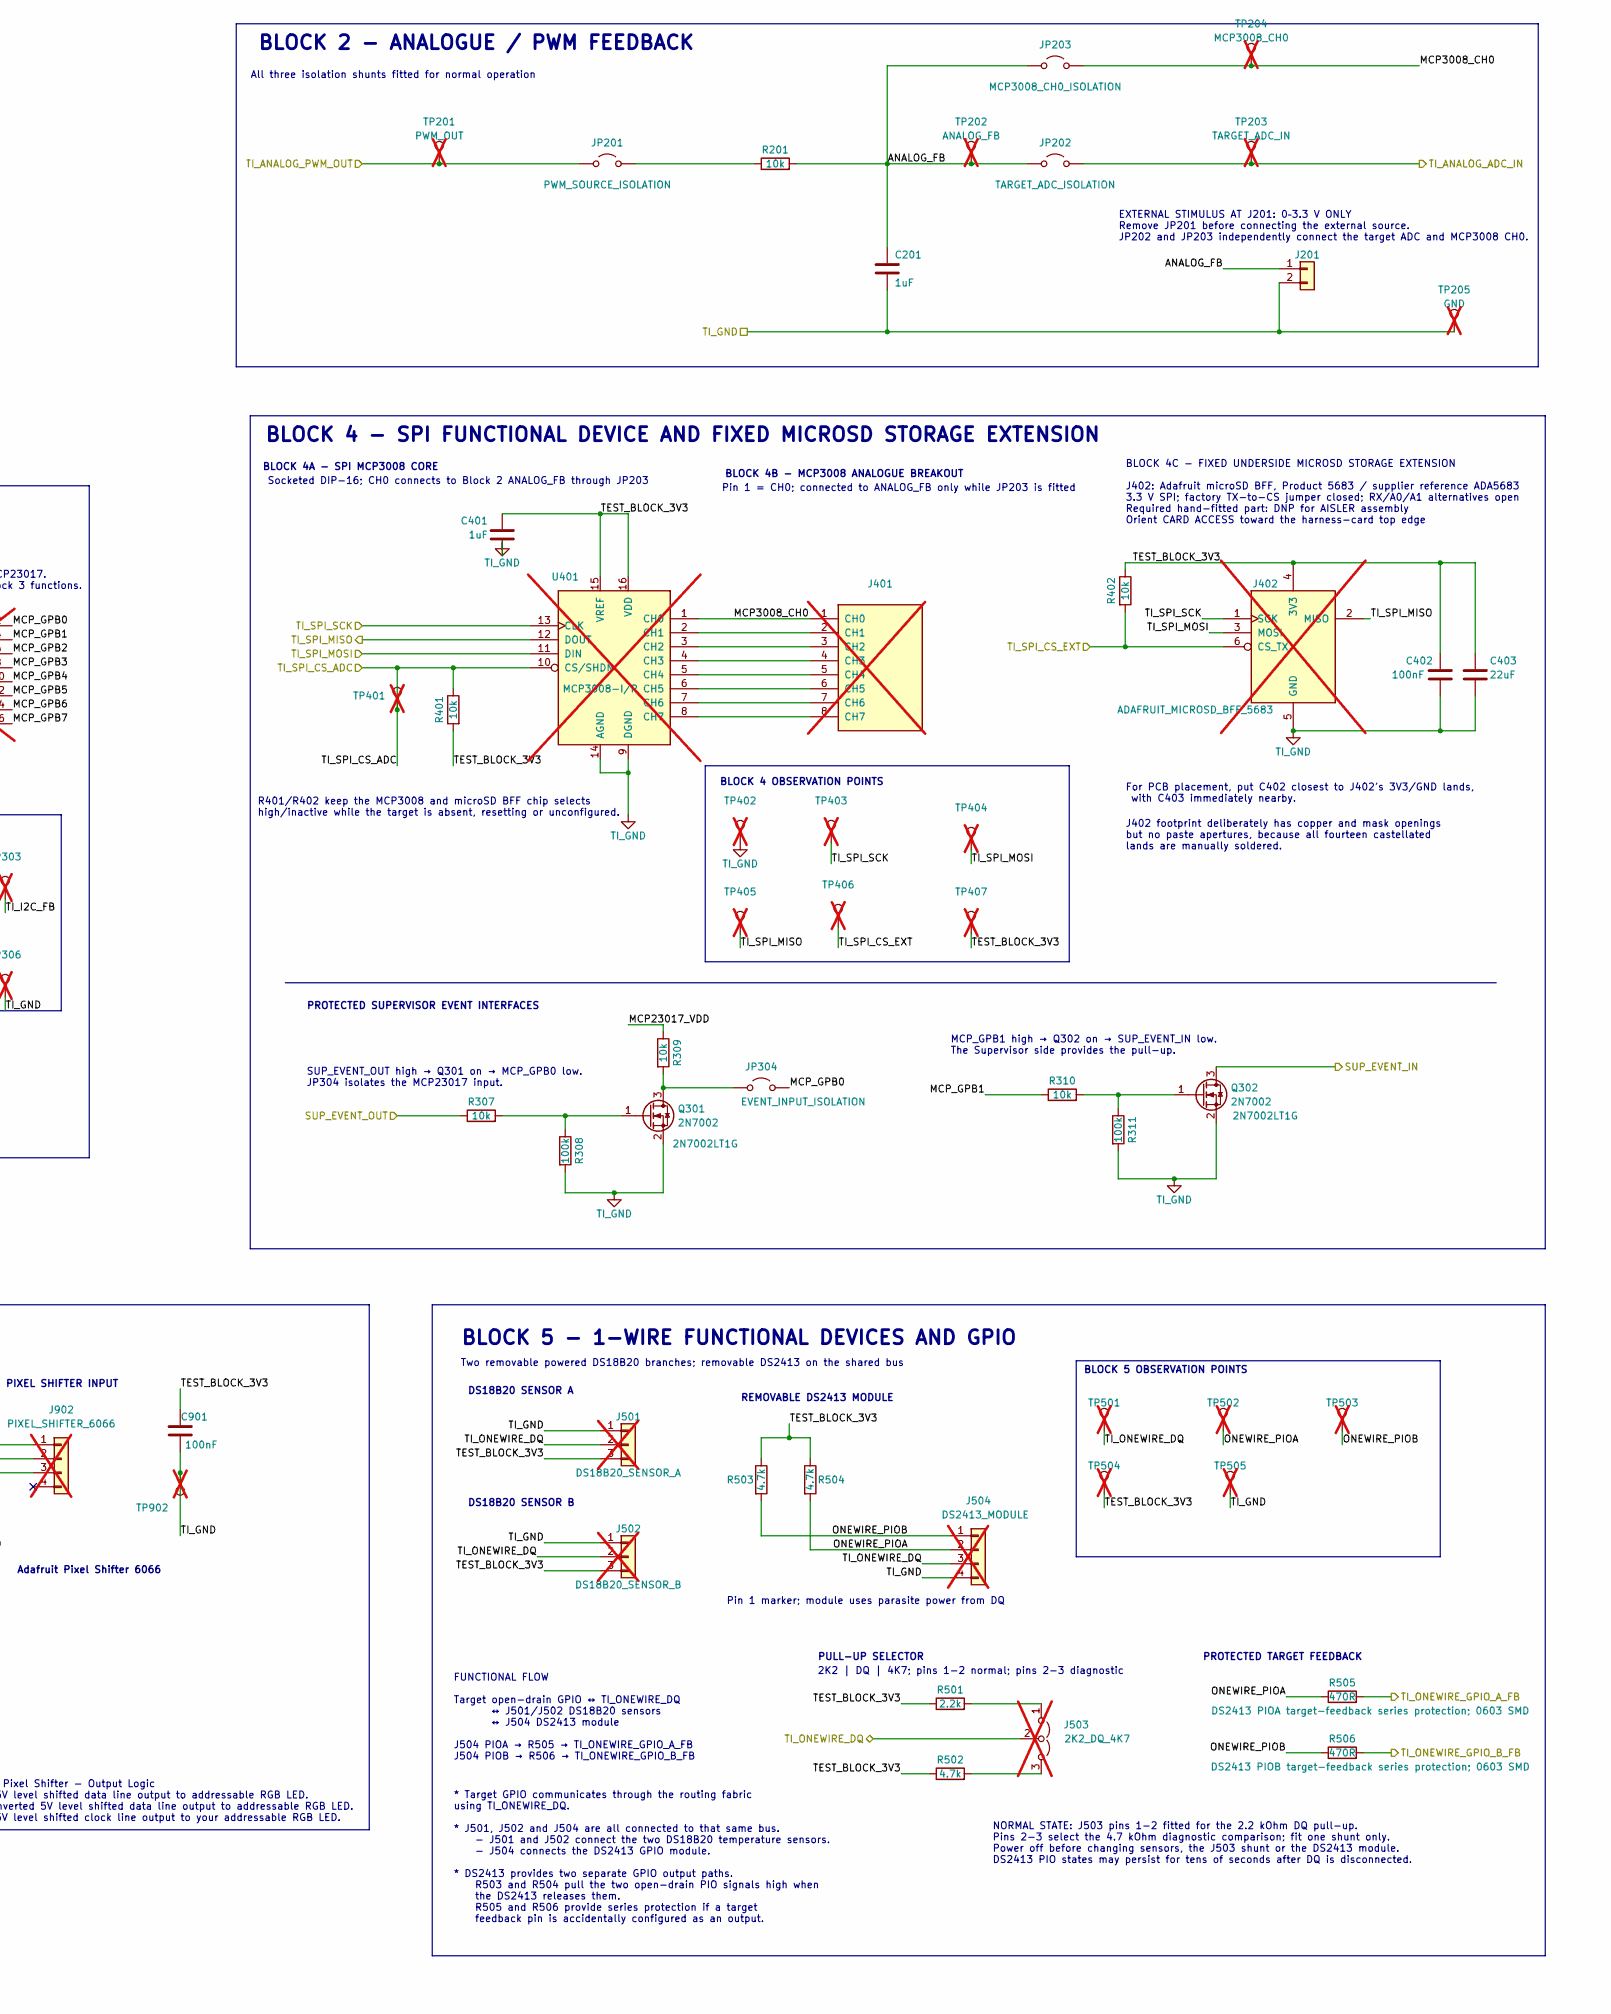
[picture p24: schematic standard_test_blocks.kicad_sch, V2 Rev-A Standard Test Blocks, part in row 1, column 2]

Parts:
C201: 1uF; C_0603_1608Metric; MPN C1608X7R1C105K080AC
C301, C402, C701, C901: 100nF; C_0603_1608Metric
C401: 1uF; C_0603_1608Metric
C403: 22uF; C_0805_2012Metric
J201: EXTERNAL_ANALOG_STIMULUS_0_TO_3V3; PinHeader_1x02_P2.54mm_Vertical; MPN 61300211121
J301: GROVE_I2C; Grove_1x04_P2mm_RightAngle_Seeed_320110034; MPN 1125R-4P; not fitted
J302: MCP23017_GPIO; PinHeader_2x08_P2.54mm_Vertical; MPN 61301621121; not fitted
J401: MCP3008_ANALOGUE_BREAKOUT; PinHeader_1x08_P2.54mm_Vertical; MPN 61300811121; not fitted
J402: ADAFRUIT_MICROSD_BFF_5683; Adafruit_MicroSD_BFF_5683_Underside; MPN 5683; not fitted
J501: DS18B20_SENSOR_A; TerminalBlock_Phoenix_MPT-0,5-3-2.54_1x03_P2.54mm_Horizontal; MPN 1725669; not fitted
J502: DS18B20_SENSOR_B; TerminalBlock_Phoenix_MPT-0,5-3-2.54_1x03_P2.54mm_Horizontal; MPN 1725669; not fitted
J503: 2K2_DQ_4K7; PinHeader_1x03_P2.54mm_Vertical; MPN 61300311121; not fitted
J504: DS2413_MODULE; PinHeader_1x04_P2.54mm_Vertical; MPN 61300411121; not fitted
J701: UART_PEER; PinHeader_1x03_P2.54mm_Vertical; MPN 61300311121; not fitted
J702: UART_B_DIAGNOSTIC_NO_DRIVE; PinHeader_1x03_P2.54mm_Vertical; MPN 61300311121; not fitted
J902: PIXEL_SHIFTER_6066; PinHeader_1x04_P2.54mm_Horizontal; MPN 61300411021; not fitted
JP101: LOOP_A_ISOLATION; PinHeader_1x02_P2.54mm_Vertical; MPN 61300211121
JP102: LOOP_B_ISOLATION; PinHeader_1x02_P2.54mm_Vertical; MPN 61300211121
JP201: PWM_SOURCE_ISOLATION; PinHeader_1x02_P2.54mm_Vertical; MPN 61300211121
JP202: TARGET_ADC_ISOLATION; PinHeader_1x02_P2.54mm_Vertical; MPN 61300211121
JP203: MCP3008_CH0_ISOLATION; PinHeader_1x02_P2.54mm_Vertical; MPN 61300211121
JP301: VDD_ISOLATION; PinHeader_1x02_P2.54mm_Vertical; MPN 61300211121
JP302: SDA_DEVICE_ISOLATION; PinHeader_1x02_P2.54mm_Vertical; MPN 61300211121
JP303: SCL_DEVICE_ISOLATION; PinHeader_1x02_P2.54mm_Vertical; MPN 61300211121
JP304: EVENT_INPUT_ISOLATION; PinHeader_1x02_P2.54mm_Vertical; MPN 61300211121
JP306: FB_DEVICE_ISOLATION; PinHeader_1x02_P2.54mm_Vertical; MPN 61300211121
JP307: INT_DEVICE_ISOLATION; PinHeader_1x02_P2.54mm_Vertical; MPN 61300211121
JP308: SDA_PULLUP_ENABLE; PinHeader_1x02_P2.54mm_Vertical; MPN 61300211121
JP309: SCL_PULLUP_ENABLE; PinHeader_1x02_P2.54mm_Vertical; MPN 61300211121
Q301, Q302: 2N7002; SOT-23; MPN 2N7002LT1G
R101, R102: 470R; R_0603_1608Metric; MPN RC0603FR-07470RL
R201: 10k; R_0603_1608Metric; MPN RC0603FR-0710KL
R301, R302, R502, R503, R504: 4.7k; R_0603_1608Metric
R303, R304: 4.7k DNP; R_0603_1608Metric; not fitted
R305, R505, R506, R701, R702, R703, R704, R901: 470R; R_0603_1608Metric
R306, R307, R309, R310, R312, R401, R402: 10k; R_0603_1608Metric
R308, R311, R705, R706, R707, R708: 100k; R_0603_1608Metric
R501: 2.2k; R_0603_1608Metric
TP101: LOOP_A_OUT; PinHeader_1x01_P2.54mm_Vertical; MPN 61300111121; not fitted
TP102: LOOP_A_IN; PinHeader_1x01_P2.54mm_Vertical; MPN 61300111121; not fitted
TP103: LOOP_B_OUT; PinHeader_1x01_P2.54mm_Vertical; MPN 61300111121; not fitted
TP104: LOOP_B_IN; PinHeader_1x01_P2.54mm_Vertical; MPN 61300111121; not fitted
TP201: PWM_OUT; PinHeader_1x01_P2.54mm_Vertical; MPN 61300111121; not fitted
TP202: ANALOG_FB; PinHeader_1x01_P2.54mm_Vertical; MPN 61300111121; not fitted
TP203: TARGET_ADC_IN; PinHeader_1x01_P2.54mm_Vertical; MPN 61300111121; not fitted
TP204: MCP3008_CH0; PinHeader_1x01_P2.54mm_Vertical; MPN 61300111121; not fitted
TP205, TP306, TP402, TP505: GND; PinHeader_1x01_P2.54mm_Vertical; MPN 61300111121; not fitted
TP301: SDA; PinHeader_1x01_P2.54mm_Vertical; MPN 61300111121; not fitted
TP302: SCL; PinHeader_1x01_P2.54mm_Vertical; MPN 61300111121; not fitted
TP303: TI_I2C_FB; PinHeader_1x01_P2.54mm_Vertical; MPN 61300111121; not fitted
TP304: TI_I2C_INT; PinHeader_1x01_P2.54mm_Vertical; MPN 61300111121; not fitted
TP305, TP504: 3V3; PinHeader_1x01_P2.54mm_Vertical; MPN 61300111121; not fitted
TP401: TI_SPI_CS_ADC; PinHeader_1x01_P2.54mm_Vertical; MPN 61300111121; not fitted
TP403: TI_SPI_SCK; PinHeader_1x01_P2.54mm_Vertical; MPN 61300111121; not fitted
TP404: TI_SPI_MOSI; PinHeader_1x01_P2.54mm_Vertical; MPN 61300111121; not fitted
TP405: TI_SPI_MISO; PinHeader_1x01_P2.54mm_Vertical; MPN 61300111121; not fitted
TP406: TI_SPI_CS_EXT; PinHeader_1x01_P2.54mm_Vertical; MPN 61300111121; not fitted
TP407: TEST_BLOCK_3V3; PinHeader_1x01_P2.54mm_Vertical; MPN 61300111121; not fitted
TP501: ONEWIRE_DQ; PinHeader_1x01_P2.54mm_Vertical; MPN 61300111121; not fitted
TP502: ONEWIRE_PIOA; PinHeader_1x01_P2.54mm_Vertical; MPN 61300111121; not fitted
TP503: ONEWIRE_PIOB; PinHeader_1x01_P2.54mm_Vertical; MPN 61300111121; not fitted
TP901: RGB_DATA_PROTECTED; PinHeader_1x01_P2.54mm_Vertical; MPN 61300111121; not fitted
TP902: RGB_GND; PinHeader_1x01_P2.54mm_Vertical; MPN 61300111121; not fitted
U301: MCP23017-E/SO; SOIC-28W_7.5x17.9mm_P1.27mm; MPN MCP23017-E/SO
U401: MCP3008; DIP-16_W7.62mm_LongPads; MPN MCP3008-I/P; not fitted
U701: TMUX1511; TSSOP-14_4.4x5mm_P0.65mm; MPN TMUX1511PWR

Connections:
/IP03_TEST_BLOCK_SDA: J301.2 (SDA), JP302.2 (B), R301.2, R303.2, TP301.1; also elsewhere on the board
/IP04_TEST_BLOCK_SCL: J301.1 (SCL), JP303.2 (B), R302.2, R304.2, TP302.1; also elsewhere on the board
/ROUTING_LOGIC_3V3: C701.1, U701.14 (VDD); also elsewhere on the board
/SUP_EVENT_IN: Q302.3 (D); also elsewhere on the board
/SUP_EVENT_OUT: R307.1; also elsewhere on the board
/Standard_Test_Blocks/ANALOG_FB: C201.1, J201.1, JP202.1 (A), JP203.1 (A), R201.2, TP202.1
/Standard_Test_Blocks/MCP3008_CH0: J401.1 (CH0), JP203.2 (B), TP204.1, U401.1 (CH0)
/Standard_Test_Blocks/MCP23017_INTA: JP307.2 (B), R312.1, U301.20 (INTA)
/Standard_Test_Blocks/MCP23017_RESET_N: R306.1, U301.18 (~RESET)
/Standard_Test_Blocks/MCP23017_SCL: JP303.1 (A), U301.12 (SCL)
/Standard_Test_Blocks/MCP23017_SDA: JP302.1 (A), U301.13 (SDA)
/Standard_Test_Blocks/MCP23017_VDD: C301.1, JP301.1 (A), R306.2, R309.1, R312.2, U301.9 (VDD)
/Standard_Test_Blocks/MCP_GPA0: J302.1 (GPA0), R305.1, U301.21 (GPA0)
/Standard_Test_Blocks/MCP_GPA1_GPA2_LOOP: J302.3 (GPA1), J302.5 (GPA2), U301.22 (GPA1), U301.23 (GPA2)
/Standard_Test_Blocks/MCP_GPA3: J302.7 (GPA3), U301.24 (GPA3)
/Standard_Test_Blocks/MCP_GPA4: J302.9 (GPA4), U301.25 (GPA4)
/Standard_Test_Blocks/MCP_GPA5: J302.11 (GPA5), U301.26 (GPA5)
/Standard_Test_Blocks/MCP_GPA6: J302.13 (GPA6), U301.27 (GPA6)
/Standard_Test_Blocks/MCP_GPA7: J302.15 (GPA7), U301.28 (GPA7)
/Standard_Test_Blocks/MCP_GPB0: J302.2 (GPB0), JP304.2 (B), U301.1 (GPB0)
/Standard_Test_Blocks/MCP_GPB1: J302.4 (GPB1), R310.1, U301.2 (GPB1)
/Standard_Test_Blocks/MCP_GPB2: J302.6 (GPB2), U301.3 (GPB2)
/Standard_Test_Blocks/MCP_GPB3: J302.8 (GPB3), U301.4 (GPB3)
/Standard_Test_Blocks/MCP_GPB4: J302.10 (GPB4), U301.5 (GPB4)
/Standard_Test_Blocks/MCP_GPB5: J302.12 (GPB5), U301.6 (GPB5)
/Standard_Test_Blocks/MCP_GPB6: J302.14 (GPB6), U301.7 (GPB6)
/Standard_Test_Blocks/MCP_GPB7: J302.16 (GPB7), U301.8 (GPB7)
/Standard_Test_Blocks/ONEWIRE_PIOA: J504.2, R504.2, R505.1, TP502.1
/Standard_Test_Blocks/ONEWIRE_PIOB: J504.1, R503.2, R506.1, TP503.1
/Standard_Test_Blocks/RGB_DATA_PROTECTED: J902.3, R901.2, TP901.1
/Standard_Test_Blocks/SCL_PULLUP_SUPPLY: JP309.1 (A), R302.1, R304.1
/Standard_Test_Blocks/SDA_PULLUP_SUPPLY: JP308.1 (A), R301.1, R303.1
/Standard_Test_Blocks/UART_PEER_RX: J701.1, R703.2
/Standard_Test_Blocks/UART_PEER_TX: J701.2, U701.12 (S4)
/TEST_BLOCK_3V3: C401.1, C402.1, C403.1, C901.1, J301.3 (3V3), J402.4 (3V3), J501.3, J502.3, J902.2, JP301.2 (B), JP308.2 (B), JP309.2 (B), R401.2, R402.1, R501.1, R502.1, R503.1, R504.1, TP305.1, TP407.1, TP504.1, U401.15 (VREF), U401.16 (VDD); also elsewhere on the board
/TI_ANALOG_ADC_IN: JP202.2 (B), TP203.1; also elsewhere on the board
/TI_ANALOG_PWM_OUT: JP201.1 (A), TP201.1; also elsewhere on the board
/TI_GPIO_LOOP_A_IN: JP101.2 (B), TP102.1; also elsewhere on the board
/TI_GPIO_LOOP_A_OUT: R101.1, TP101.1; also elsewhere on the board
/TI_GPIO_LOOP_B_IN: JP102.2 (B), TP104.1; also elsewhere on the board
/TI_GPIO_LOOP_B_OUT: R102.1, TP103.1; also elsewhere on the board
/TI_I2C_FB: JP306.2 (B), TP303.1; also elsewhere on the board
/TI_I2C_INT: JP307.1 (A), TP304.1; also elsewhere on the board
/TI_ONEWIRE_DQ: J501.2, J502.2, J503.2 (C), J504.3, TP501.1; also elsewhere on the board
/TI_ONEWIRE_GPIO_A_FB: R505.2; also elsewhere on the board
/TI_ONEWIRE_GPIO_B_FB: R506.2; also elsewhere on the board
/TI_RGB_DATA: R901.1; also elsewhere on the board
/TI_SPI_CS_ADC: R401.1, TP401.1, U401.10 (CS/SHDN); also elsewhere on the board
/TI_SPI_CS_EXT: J402.6 (CS_TX), R402.2, TP406.1; also elsewhere on the board
/TI_SPI_MISO: J402.2 (MISO), TP405.1, U401.12 (DOUT); also elsewhere on the board
/TI_SPI_MOSI: J402.3 (MOSI), TP404.1, U401.11 (DIN); also elsewhere on the board
/TI_SPI_SCK: J402.1 (SCK), TP403.1, U401.13 (CLK); also elsewhere on the board
/TI_UART_A_RX: R702.2, R704.2; also elsewhere on the board
/TI_UART_A_TX: U701.2 (S1), U701.9 (S3); also elsewhere on the board
/TI_UART_B_RX: J702.2, R701.2; also elsewhere on the board
/TI_UART_B_TX: J702.1, U701.5 (S2); also elsewhere on the board
/UP01_EN: R705.1, U701.1 (SEL1); also elsewhere on the board
/UP02_EN: R706.1, U701.4 (SEL2); also elsewhere on the board
/UP03_EN: R707.1, U701.10 (SEL3); also elsewhere on the board
/UP04_EN: R708.1, U701.13 (SEL4); also elsewhere on the board
unnamed: J401.2 (CH1), U401.2 (CH1)
unnamed: J401.3 (CH2), U401.3 (CH2)
unnamed: J401.4 (CH3), U401.4 (CH3)
unnamed: J401.5 (CH4), U401.5 (CH4)
unnamed: J401.6 (CH5), U401.6 (CH5)
unnamed: J401.7 (CH6), U401.7 (CH6)
unnamed: J401.8 (CH7), U401.8 (CH7)
unnamed: J503.1 (A), R501.2
unnamed: J503.3 (B), R502.2
unnamed: JP101.1 (A), R101.2
unnamed: JP102.1 (A), R102.2
unnamed: JP201.2 (B), R201.1
unnamed: JP304.1 (A), Q301.3 (D), R309.2
unnamed: JP306.1 (A), R305.2
unnamed: Q301.1 (G), R307.2, R308.1
unnamed: Q302.1 (G), R310.2, R311.1
unnamed: R701.1, U701.3 (D1)
unnamed: R702.1, U701.6 (D2)
unnamed: R703.1, U701.8 (D3)
unnamed: R704.1, U701.11 (D4)
TI_GND: C201.2, C301.2, C401.2, C402.2, C403.2, C701.2, C901.2, J201.2, J301.4 (GND), J402.5 (GND), J501.1, J502.1, J504.4, J701.3, J702.3, J902.1, Q301.2 (S), Q302.2 (S), R308.2, R311.2, R705.2, R706.2, R707.2, R708.2, TP205.1, TP306.1, TP402.1, TP505.1, TP902.1, U301.10 (VSS), U301.15 (A0), U301.16 (A1), U301.17 (A2), U401.9 (DGND), U401.14 (AGND), U701.7 (GND); also elsewhere on the board

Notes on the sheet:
Route and verify TI_RGB_DATA before enabling the target output. Start with the target output low or high impedance. Fit or remove the module only with Test Block power off and the route open. J902 supplies 3.3 V only; module-generated 5 V remains module-local. TP901 is for high-impedance observatio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
BLOCK 3 OBSERVATION POINTS
FUNCTIONAL FLOW Target open-drain GPIO ↔ TI_ONEWIRE_DQ ↔ J501/J502 DS18B20 sensors ↔ J504 DS2413 module J504 PIOA → R505 → TI_ONEWIRE_GPIO_A_FB J504 PIOB → R506 → TI_ONEWIRE_GPIO_B_FB
J302 exposes GPA0–GPA7 and GPB0–GPB7 for observation and experiments. GPA7 and GPB7 are output-only on the selected MCP23017. Do not externally drive pins already assigned to Block 3 functions.
PAIR A
BLOCK 4C - FIXED UNDERSIDE MICROSD STORAGE EXTENSION J402: Adafruit microSD BFF, Product 5683 / supplier reference ADA5683 3.3 V SPI; factory TX-to-CS jumper closed; RX/A0/A1 alternatives open Required hand-fitted part: DNP for AISLER assembly Orient CARD ACCESS toward the harness-card top edge
TMUX1511: 4 independent SPST switches with powered-off protection.
MCP23017 DEVICE ISOLATION JP301: VDD JP302: SDA JP303: SCL JP304: SUP_EVENT_OUT JP306: FB JP307: INTA All six shunts are fitted for normal operation.
NORMAL: JP308/JP309 fitted; R301/R302 provide 4.7k SDA/SCL pull-ups. R303/R304 are DNP parallel adjustment positions. Remove the respective shunt to disable a pull-up group.
All three isolation shunts fitted for normal operation
BLOCK 4 - SPI FUNCTIONAL DEVICE AND FIXED MICROSD STORAGE EXTENSION
BLOCK 4A - SPI MCP3008 CORE
MCP23017 GPIO BREAKOUT
FUNCTIONAL FLOW
* Target GPIO communicates through the routing fabric using TI_ONEWIRE_DQ. * J501, J502 and J504 are all connected to that same bus. - J501 and J502 connect the two DS18B20 temperature sensors. - J504 connects the DS2413 GPIO module. * DS2413 provides two separate GPIO output paths. R503 and R504 p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
EXTERNAL STIMULUS AT J201: 0–3.3 V ONLY Remove JP201 before connecting the external source. JP202 and JP203 independently connect the target ADC and MCP3008 CH0.
CONFIGURABLE I2C PULL-UPS
ISOLATED DEVICE SUPPLY JP301 powers U301, C301, the R306 RESET pull-up and the R312 INTA pull-up from MCP23017_VDD. Opening JP301 removes all local U301 bias.
BLOCK 2 - ANALOGUE / PWM FEEDBACK
BLOCK 4B - MCP3008 ANALOGUE BREAKOUT
SUP_EVENT_OUT high → Q301 on → MCP_GPB0 low. JP304 isolates the MCP23017 input.
PAIR B
JP302/JP303 isolate U301 only. The Grove branch, pull-ups and SDA/SCL test points remain on the shared bus.
FUNCTIONAL FLOW Target-owned I2C ↔ IP03/IP04 ↔ shared SDA/SCL bus Shared bus ↔ Grove J301 Shared bus → JP302/JP303 → U301 U301 GPA0 → R305 → JP306 → TI_I2C_FB U301 GPA1 ↔ GPA2 provides internal interrupt stimulus U301 INTA → JP307 → TI_I2C_INT
BLOCK 4 OBSERVATION POINTS
NORMAL STATE: JP101 and JP102 shunts fitted. Remove either shunt to hard-isolate that loopback pair. Configure the input and verify routing before driving the output.
Adafruit Pixel Shifter - Output Logic D5 - 5V level shifted data line output to addressable RGB LED. !D5 - Inverted 5V level shifted data line output to addressable RGB LED. C5 - 5V level shifted clock line output to your addressable RGB LED.
J402 footprint deliberately has copper and mask openings but no paste apertures, because all fourteen castellated lands are manually soldered.
Socketed DIP-16; CH0 connects to Block 2 ANALOG_FB through JP203
Pin 1 = CH0; connected to ANALOG_FB only while JP203 is fitted
GROVE I2C EXPANSION
Adafruit Pixel Shifter 6066
R401/R402 keep the MCP3008 and microSD BFF chip selects high/inactive while the target is absent, resetting or unconfigured.
BLOCK 5 - 1-WIRE FUNCTIONAL DEVICES AND GPIO
Two removable powered DS18B20 branches; removable DS2413 on the shared bus
DS18B20 SENSOR A
DS18B20 SENSOR B
PULL-UP SELECTOR
2K2 | DQ | 4K7; pins 1-2 normal; pins 2-3 diagnostic
REMOVABLE DS2413 MODULE

Board: 2 copper layers, 232 parts (1 on the bottom side), 162 nets, no tracks yet.

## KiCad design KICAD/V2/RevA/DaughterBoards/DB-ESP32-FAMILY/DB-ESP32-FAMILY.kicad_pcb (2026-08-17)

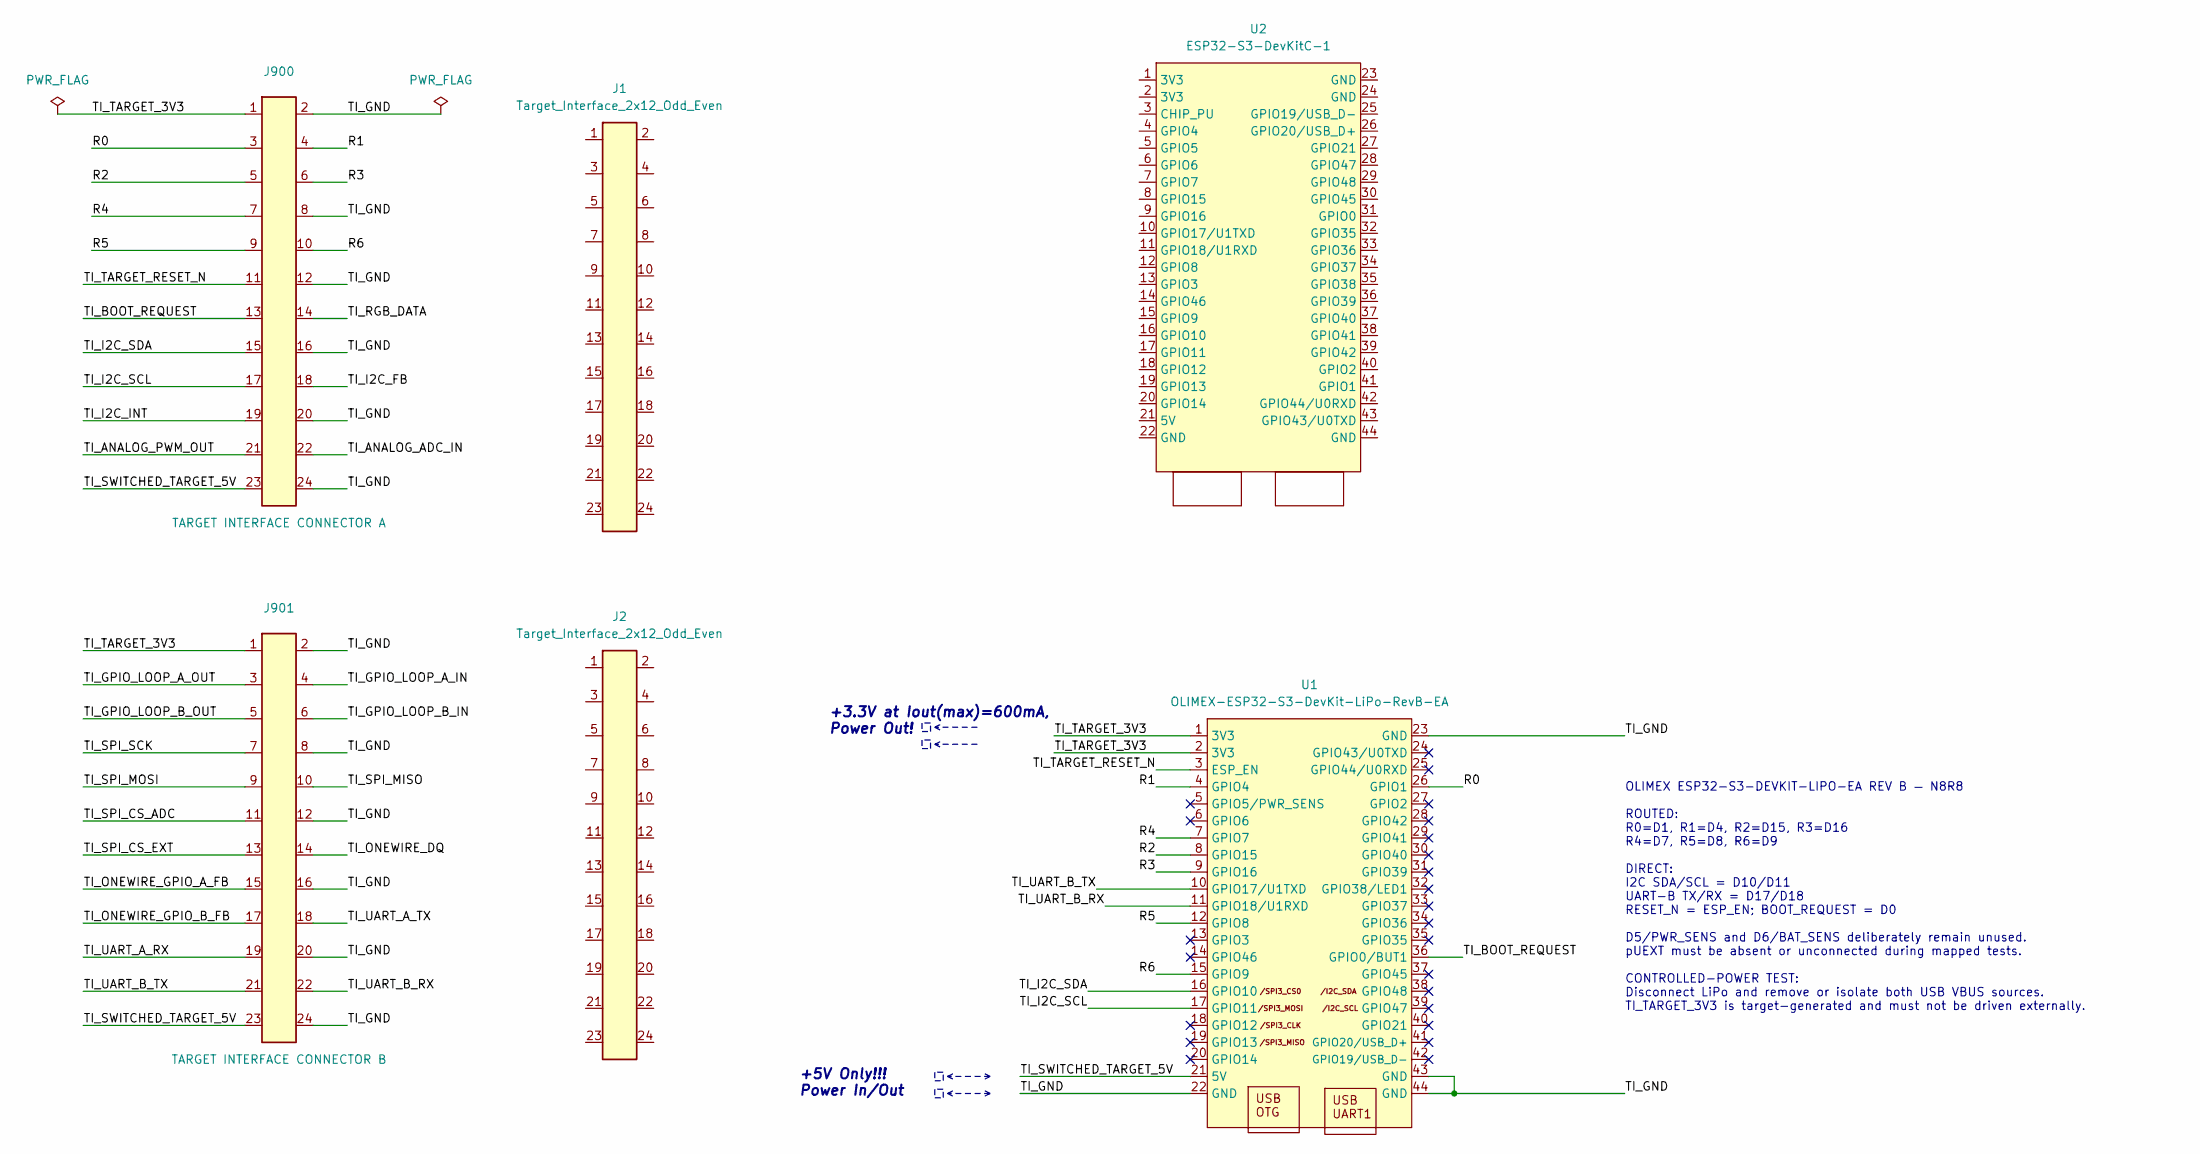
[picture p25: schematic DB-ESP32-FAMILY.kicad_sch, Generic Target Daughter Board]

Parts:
J1, J2: Target_Interface_2x12_Odd_Even; TargetInterface_2x12_P2.54mm_RA_Male_Adafruit1541_Daughter
J900: TARGET INTERFACE CONNECTOR A; TargetInterface_2x12_P2.54mm_RA_Male_Adafruit1541_Daughter
J901: TARGET INTERFACE CONNECTOR B; TargetInterface_2x12_P2.54mm_RA_Male_Adafruit1541_Daughter
U1: OLIMEX-ESP32-S3-DevKit-LiPo-RevB-EA; OLIMEX-ESP32-S3-DevKit-LiPo-EA
U2: ESP32-S3-DevKitC-1

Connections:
/R0: J900.3 (Contact_03), U1.26 (GPIO1)
/R1: J900.4 (Contact_04), U1.4 (GPIO4)
/R2: J900.5 (Contact_05), U1.8 (GPIO15)
/R3: J900.6 (Contact_06), U1.9 (GPIO16)
/R4: J900.7 (Contact_07), U1.7 (GPIO7)
/R5: J900.9 (Contact_09), U1.12 (GPIO8)
/R6: J900.10 (Contact_10), U1.15 (GPIO9)
/TI_ANALOG_ADC_IN: J900.22 (Contact_22)
/TI_ANALOG_PWM_OUT: J900.21 (Contact_21)
/TI_BOOT_REQUEST: J900.13 (Contact_13), U1.36 (GPIO0/BUT1)
/TI_GND: J900.2 (Contact_02), J900.8 (Contact_08), J900.12 (Contact_12), J900.16 (Contact_16), J900.20 (Contact_20), J900.24 (Contact_24), J901.2 (Contact_02), J901.8 (Contact_08), J901.12 (Contact_12), J901.16 (Contact_16), J901.20 (Contact_20), J901.24 (Contact_24), U1.22 (GND), U1.23 (GND), U1.43 (GND), U1.44 (GND)
/TI_GPIO_LOOP_A_IN: J901.4 (Contact_04)
/TI_GPIO_LOOP_A_OUT: J901.3 (Contact_03)
/TI_GPIO_LOOP_B_IN: J901.6 (Contact_06)
/TI_GPIO_LOOP_B_OUT: J901.5 (Contact_05)
/TI_I2C_FB: J900.18 (Contact_18)
/TI_I2C_INT: J900.19 (Contact_19)
/TI_I2C_SCL: J900.17 (Contact_17), U1.17 (GPIO11)
/TI_I2C_SDA: J900.15 (Contact_15), U1.16 (GPIO10)
/TI_ONEWIRE_DQ: J901.14 (Contact_14)
/TI_ONEWIRE_GPIO_A_FB: J901.15 (Contact_15)
/TI_ONEWIRE_GPIO_B_FB: J901.17 (Contact_17)
/TI_RGB_DATA: J900.14 (Contact_14)
/TI_SPI_CS_ADC: J901.11 (Contact_11)
/TI_SPI_CS_EXT: J901.13 (Contact_13)
/TI_SPI_MISO: J901.10 (Contact_10)
/TI_SPI_MOSI: J901.9 (Contact_09)
/TI_SPI_SCK: J901.7 (Contact_07)
/TI_SWITCHED_TARGET_5V: J900.23 (Contact_23), J901.23 (Contact_23), U1.21 (5V)
/TI_TARGET_3V3: J900.1 (Contact_01), J901.1 (Contact_01), U1.1 (3V3), U1.2 (3V3)
/TI_TARGET_RESET_N: J900.11 (Contact_11), U1.3 (ESP_EN)
/TI_UART_A_RX: J901.19 (Contact_19)
/TI_UART_A_TX: J901.18 (Contact_18)
/TI_UART_B_RX: J901.22 (Contact_22), U1.11 (GPIO18/U1RXD)
/TI_UART_B_TX: J901.21 (Contact_21), U1.10 (GPIO17/U1TXD)

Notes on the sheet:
+3.3V at Iout(max)=600mA, Power Out!
OLIMEX ESP32-S3-DEVKIT-LIPO-EA REV B — N8R8 ROUTED: R0=D1, R1=D4, R2=D15, R3=D16 R4=D7, R5=D8, R6=D9 DIRECT: I2C SDA/SCL = D10/D11 UART-B TX/RX = D17/D18 RESET_N = ESP_EN; BOOT_REQUEST = D0 D5/PWR_SENS and D6/BAT_SENS deliberately remain unused. pUEXT must be absent or unconnected during mapped tes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
+5V Only!!! Power In/Out

Board: 2 copper layers, 6 parts (0 on the bottom side), 16 nets, no tracks yet.

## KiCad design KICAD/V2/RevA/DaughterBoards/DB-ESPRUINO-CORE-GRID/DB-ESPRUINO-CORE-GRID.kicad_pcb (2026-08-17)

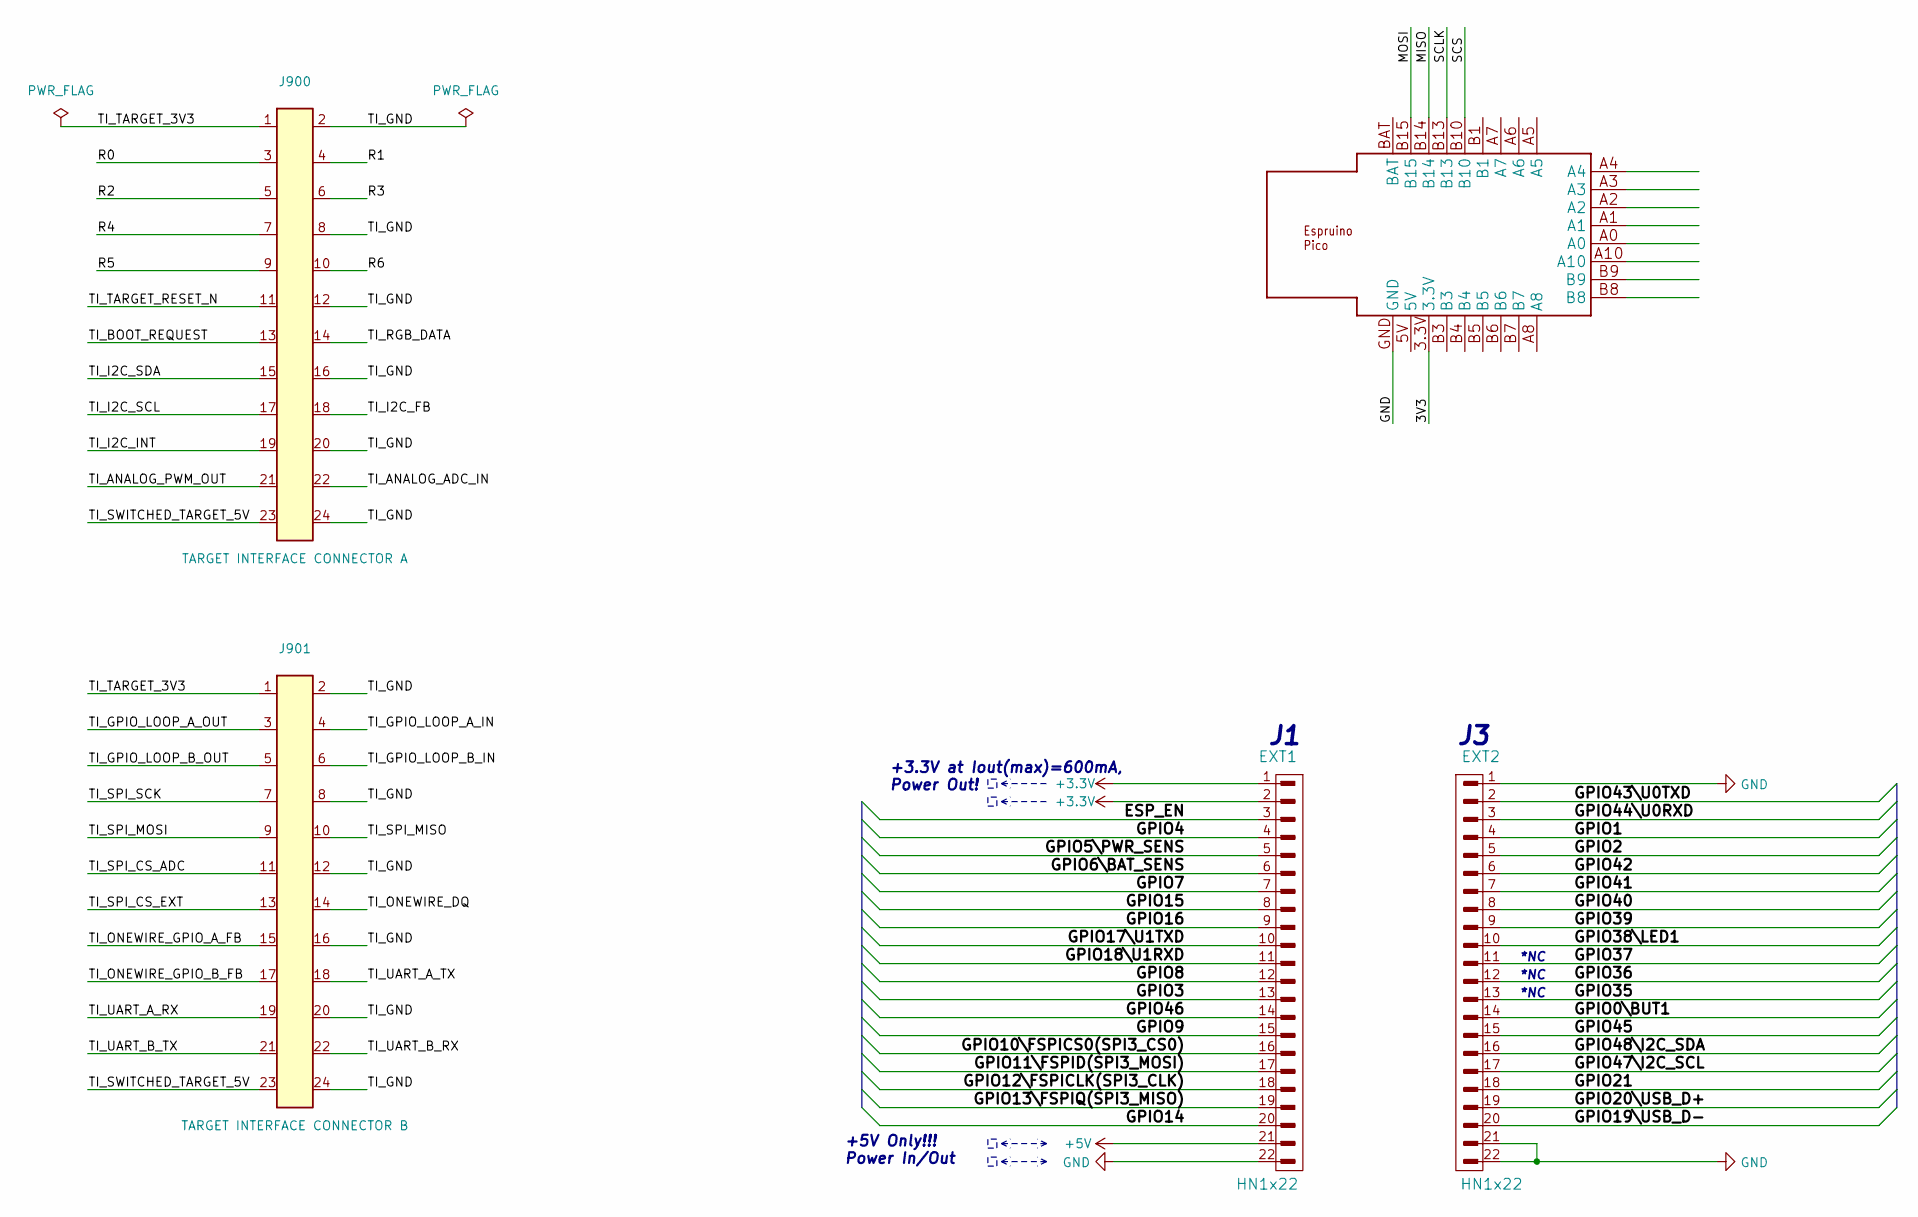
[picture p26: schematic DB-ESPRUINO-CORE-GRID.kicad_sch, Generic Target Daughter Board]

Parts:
EXT1, EXT2: HN1x22
J900: TARGET INTERFACE CONNECTOR A; TargetInterface_2x12_P2.54mm_RA_Male_Adafruit1541_Daughter
J901: TARGET INTERFACE CONNECTOR B; TargetInterface_2x12_P2.54mm_RA_Male_Adafruit1541_Daughter
U$1: ESPRUINO_PICO_SMD

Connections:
+3.3V: EXT1.1, EXT1.2
+5V: EXT1.21
/3V3: U$1.3.3V
/ESP_EN: EXT1.3
/GPIO0\BUT1: EXT2.14
/GPIO1: EXT2.4
/GPIO2: EXT2.5
/GPIO3: EXT1.13
/GPIO4: EXT1.4
/GPIO5\PWR_SENS: EXT1.5
/GPIO6\BAT_SENS: EXT1.6
/GPIO7: EXT1.7
/GPIO8: EXT1.12
/GPIO9: EXT1.15
/GPIO10\FSPICS0(SPI3_CS0): EXT1.16
/GPIO11\FSPID(SPI3_MOSI): EXT1.17
/GPIO12\FSPICLK(SPI3_CLK): EXT1.18
/GPIO13\FSPIQ(SPI3_MISO): EXT1.19
/GPIO14: EXT1.20
/GPIO15: EXT1.8
/GPIO16: EXT1.9
/GPIO17\U1TXD: EXT1.10
/GPIO18\U1RXD: EXT1.11
/GPIO19\USB_D-: EXT2.20
/GPIO20\USB_D+: EXT2.19
/GPIO21: EXT2.18
/GPIO35: EXT2.13
/GPIO36: EXT2.12
/GPIO37: EXT2.11
/GPIO38\LED1: EXT2.10
/GPIO39: EXT2.9
/GPIO40: EXT2.8
/GPIO41: EXT2.7
/GPIO42: EXT2.6
/GPIO43\U0TXD: EXT2.2
/GPIO44\U0RXD: EXT2.3
/GPIO45: EXT2.15
/GPIO46: EXT1.14
/GPIO47\I2C_SCL: EXT2.17
/GPIO48\I2C_SDA: EXT2.16
/MISO: U$1.B14
/MOSI: U$1.B15
/R0: J900.3 (Contact_03)
/R1: J900.4 (Contact_04)
/R2: J900.5 (Contact_05)
/R3: J900.6 (Contact_06)
/R4: J900.7 (Contact_07)
/R5: J900.9 (Contact_09)
/R6: J900.10 (Contact_10)
/SCLK: U$1.B13
/SCS: U$1.B10
/TI_ANALOG_ADC_IN: J900.22 (Contact_22)
/TI_ANALOG_PWM_OUT: J900.21 (Contact_21)
/TI_BOOT_REQUEST: J900.13 (Contact_13)
/TI_GND: J900.2 (Contact_02), J900.8 (Contact_08), J900.12 (Contact_12), J900.16 (Contact_16), J900.20 (Contact_20), J900.24 (Contact_24), J901.2 (Contact_02), J901.8 (Contact_08), J901.12 (Contact_12), J901.16 (Contact_16), J901.20 (Contact_20), J901.24 (Contact_24)
/TI_GPIO_LOOP_A_IN: J901.4 (Contact_04)
/TI_GPIO_LOOP_A_OUT: J901.3 (Contact_03)
/TI_GPIO_LOOP_B_IN: J901.6 (Contact_06)
/TI_GPIO_LOOP_B_OUT: J901.5 (Contact_05)
/TI_I2C_FB: J900.18 (Contact_18)
/TI_I2C_INT: J900.19 (Contact_19)
/TI_I2C_SCL: J900.17 (Contact_17)
/TI_I2C_SDA: J900.15 (Contact_15)
/TI_ONEWIRE_DQ: J901.14 (Contact_14)
/TI_ONEWIRE_GPIO_A_FB: J901.15 (Contact_15)
/TI_ONEWIRE_GPIO_B_FB: J901.17 (Contact_17)
/TI_RGB_DATA: J900.14 (Contact_14)
/TI_SPI_CS_ADC: J901.11 (Contact_11)
/TI_SPI_CS_EXT: J901.13 (Contact_13)
/TI_SPI_MISO: J901.10 (Contact_10)
/TI_SPI_MOSI: J901.9 (Contact_09)
/TI_SPI_SCK: J901.7 (Contact_07)
/TI_SWITCHED_TARGET_5V: J900.23 (Contact_23), J901.23 (Contact_23)
/TI_TARGET_3V3: J900.1 (Contact_01), J901.1 (Contact_01)
/TI_TARGET_RESET_N: J900.11 (Contact_11)
/TI_UART_A_RX: J901.19 (Contact_19)
/TI_UART_A_TX: J901.18 (Contact_18)
/TI_UART_B_RX: J901.22 (Contact_22)
/TI_UART_B_TX: J901.21 (Contact_21)
GND: EXT1.22, EXT2.1, EXT2.21, EXT2.22, U$1.GND

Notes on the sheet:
*NC
+3.3V at Iout(max)=600mA, Power Out!
+5V Only!!! Power In/Out

Board: 2 copper layers, 5 parts (0 on the bottom side), 5 nets, no tracks yet.

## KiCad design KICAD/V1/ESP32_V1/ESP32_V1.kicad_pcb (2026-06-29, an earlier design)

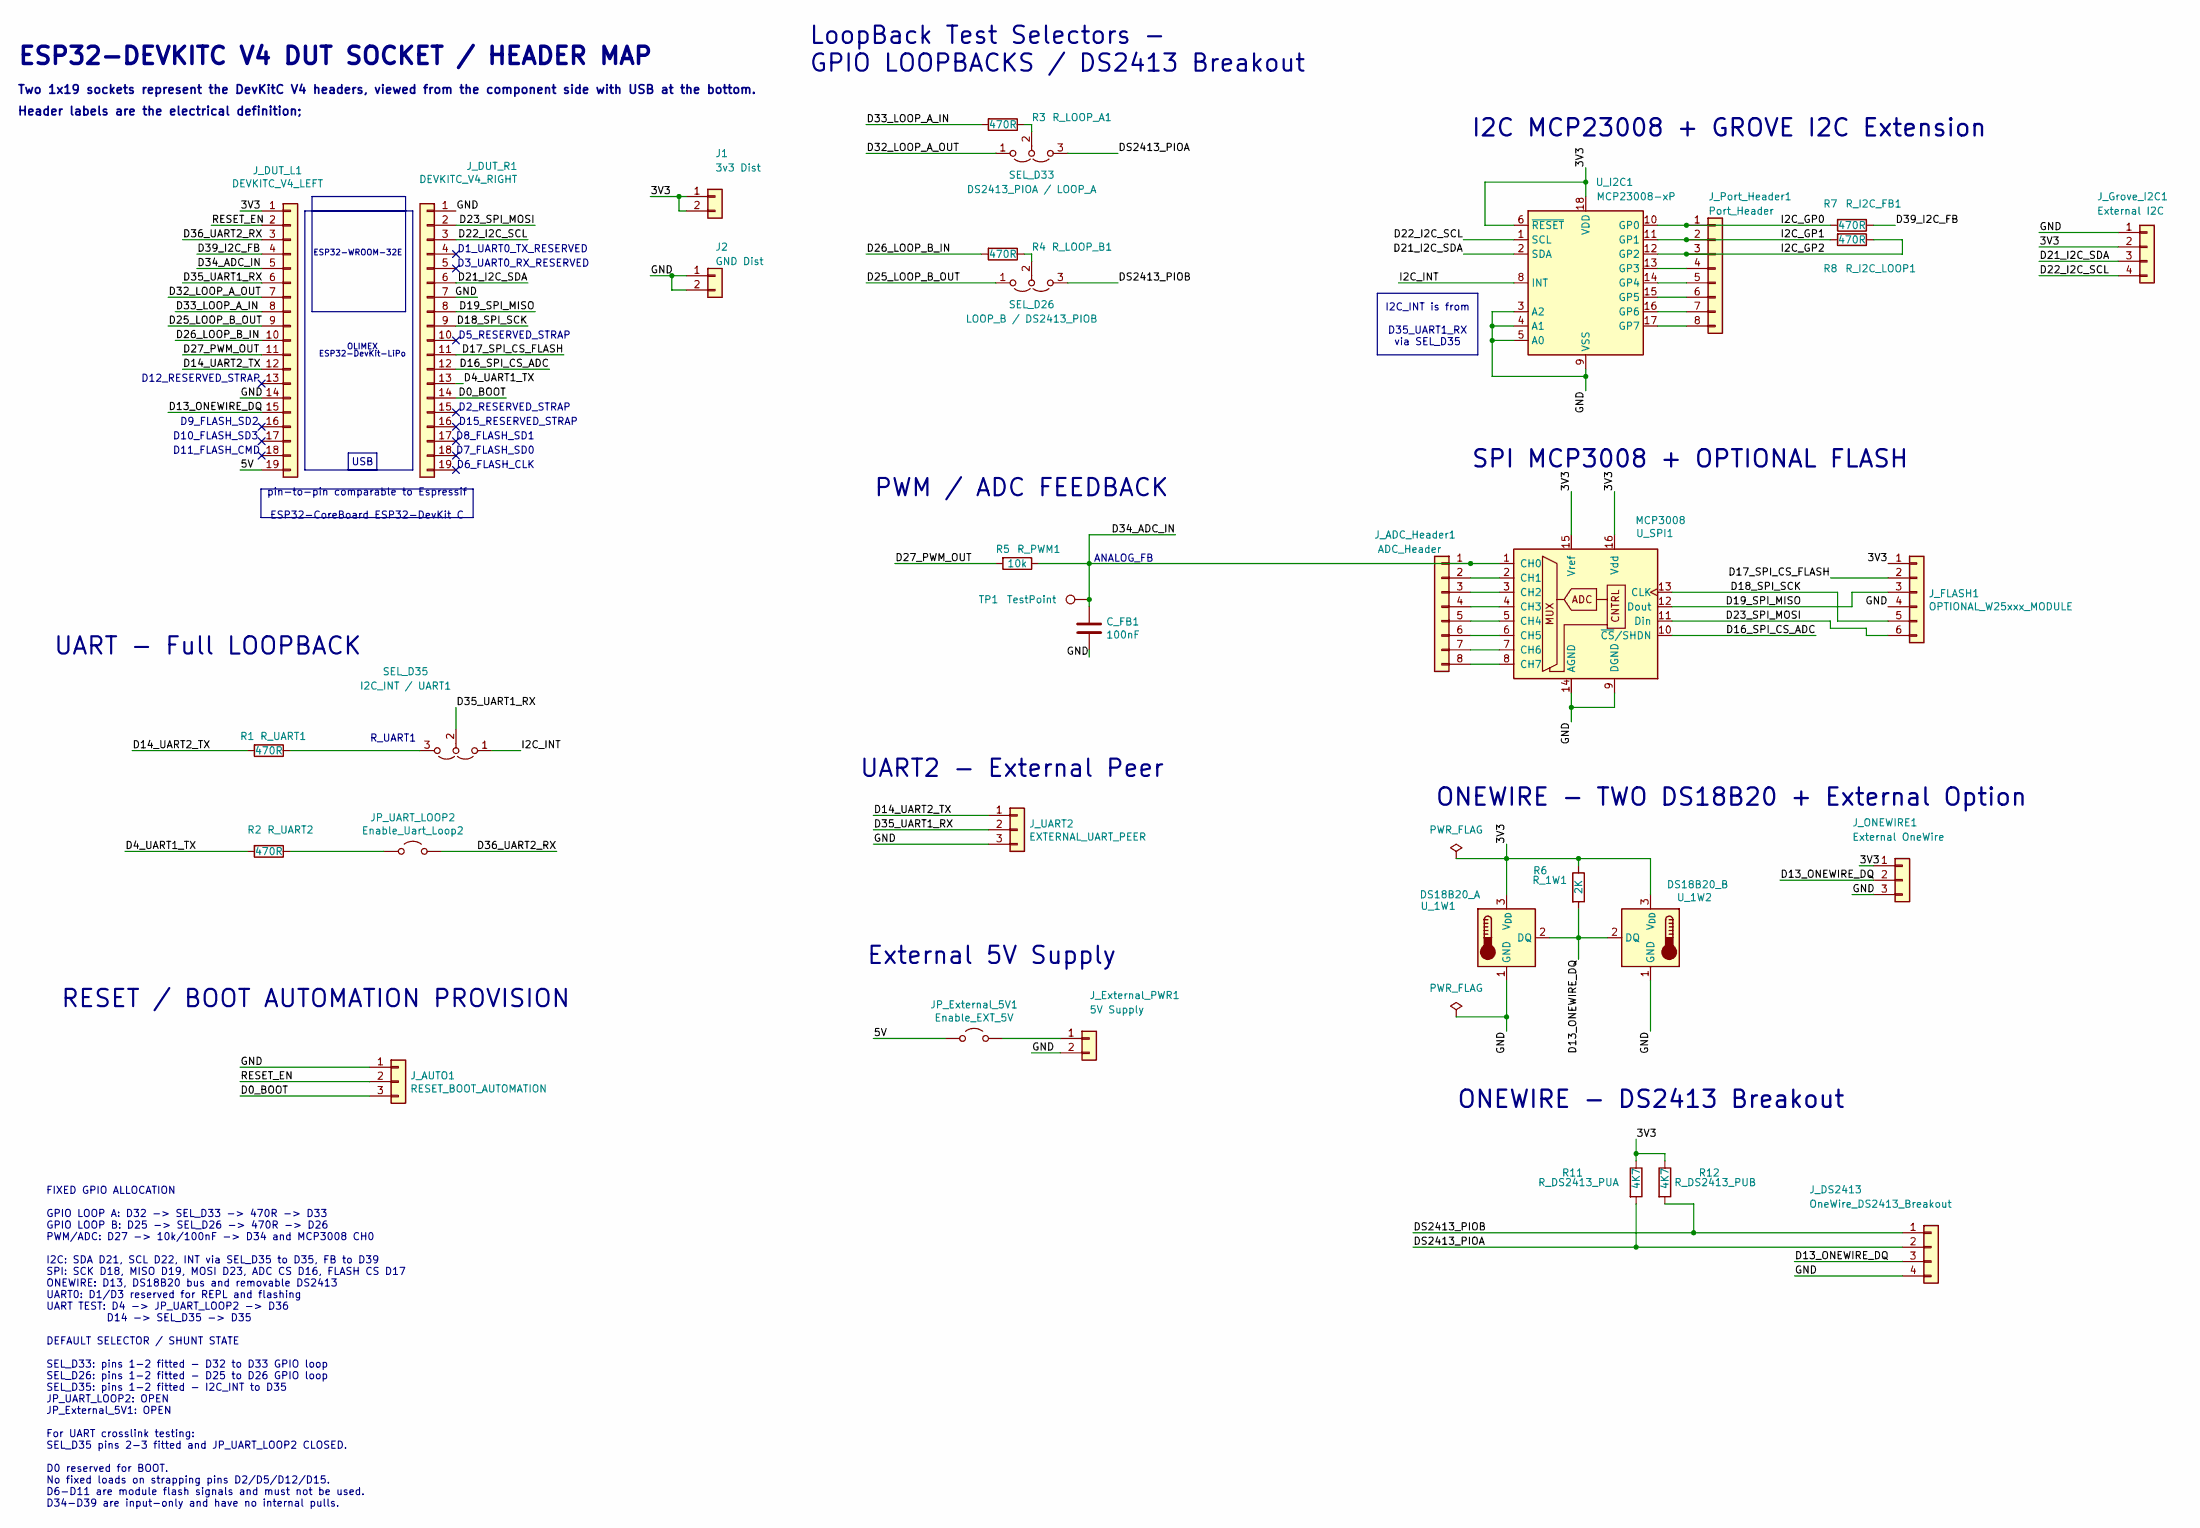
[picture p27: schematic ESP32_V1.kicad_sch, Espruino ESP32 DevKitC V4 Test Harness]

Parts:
C_FB1: 100nF; C_Disc_D4.7mm_W2.5mm_P5.00mm
J1: 3v3 Dist; PinHeader_1x02_P2.54mm_Vertical
J2: GND Dist; PinHeader_1x02_P2.54mm_Vertical
JP_External_5V1: Enable_EXT_5V; PinHeader_1x02_P2.54mm_Vertical
JP_UART_LOOP2: Enable_Uart_Loop2; PinHeader_1x02_P2.54mm_Vertical
J_ADC_Header1: ADC_Header; PinHeader_1x08_P2.54mm_Vertical
J_AUTO1: RESET_BOOT_AUTOMATION; TerminalBlock_Phoenix_MPT-0,5-3-2.54_1x03_P2.54mm_Horizontal
J_DS2413: OneWire_DS2413_Breakout; PinSocket_1x04_P2.54mm_Vertical
J_DUT_L1: DEVKITC_V4_LEFT; PinSocket_1x19_P2.54mm_Vertical
J_DUT_R1: DEVKITC_V4_RIGHT; PinSocket_1x19_P2.54mm_Vertical
J_External_PWR1: 5V Supply; TerminalBlock_Phoenix_MPT-0,5-2-2.54_1x02_P2.54mm_Horizontal
J_FLASH1: OPTIONAL_W25xxx_MODULE; PinSocket_1x06_P2.54mm_Vertical
J_Grove_I2C1: External I2C; Grove_1x04_P2mm(SEEED_110990030)
J_ONEWIRE1: External OneWire; TerminalBlock_Phoenix_MPT-0,5-3-2.54_1x03_P2.54mm_Horizontal
J_Port_Header1: Port_Header; PinHeader_1x08_P2.54mm_Vertical
J_UART2: EXTERNAL_UART_PEER; TerminalBlock_Phoenix_MPT-0,5-3-2.54_1x03_P2.54mm_Horizontal
R1, R2, R3, R4, R7, R8: 470R; R_Axial_DIN0204_L3.6mm_D1.6mm_P2.54mm_Vertical
R5: 10k; R_Axial_DIN0204_L3.6mm_D1.6mm_P2.54mm_Vertical
R6: 2K; R_Axial_DIN0204_L3.6mm_D1.6mm_P2.54mm_Vertical
R11, R12: 4K7; R_Axial_DIN0204_L3.6mm_D1.6mm_P2.54mm_Vertical
SEL_D26: LOOP_B / DS2413_PIOB; PinHeader_1x03_P2.54mm_Vertical
SEL_D33: DS2413_PIOA / LOOP_A; PinHeader_1x03_P2.54mm_Vertical
SEL_D35: I2C_INT / UART1; PinHeader_1x03_P2.54mm_Vertical
TP1: TestPoint; TestPoint_THTPad_D1.5mm_Drill0.7mm
U_1W1: DS18B20_A; TO-92_Inline
U_1W2: DS18B20_B; TO-92_Inline
U_I2C1: MCP23008-xP; DIP-18_W7.62mm_Socket
U_SPI1: MCP3008; DIP-16_W7.62mm_Socket

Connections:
/3V3: J1.1, J1.2, J_DUT_L1.1, J_FLASH1.1, J_Grove_I2C1.2, J_ONEWIRE1.1, R6.1, R11.1, R12.1, U_1W1.3 (V_{DD}), U_1W2.3 (V_{DD}), U_I2C1.6 (~RESET), U_I2C1.18 (VDD), U_SPI1.15 (Vref), U_SPI1.16 (Vdd)
/5V: JP_External_5V1.1 (A), J_DUT_L1.19
/D0_BOOT: J_AUTO1.3, J_DUT_R1.14
/D4_UART1_TX: J_DUT_R1.13, R2.2
/D13_ONEWIRE_DQ: J_DS2413.3, J_DUT_L1.15, J_ONEWIRE1.2, R6.2, U_1W1.2 (DQ), U_1W2.2 (DQ)
/D14_UART2_TX: J_DUT_L1.12, J_UART2.1, R1.2
/D16_SPI_CS_ADC: J_DUT_R1.12, U_SPI1.10 (~CS/SHDN)
/D17_SPI_CS_FLASH: J_DUT_R1.11, J_FLASH1.2
/D18_SPI_SCK: J_DUT_R1.9, J_FLASH1.5, U_SPI1.13 (CLK)
/D19_SPI_MISO: J_DUT_R1.8, J_FLASH1.3, U_SPI1.12 (Dout)
/D21_I2C_SDA: J_DUT_R1.6, J_Grove_I2C1.3, U_I2C1.2 (SDA)
/D22_I2C_SCL: J_DUT_R1.3, J_Grove_I2C1.4, U_I2C1.1 (SCL)
/D23_SPI_MOSI: J_DUT_R1.2, J_FLASH1.6, U_SPI1.11 (Din)
/D25_LOOP_B_OUT: J_DUT_L1.9, SEL_D26.1 (A)
/D26_LOOP_B_IN: J_DUT_L1.10, R4.2
/D27_PWM_OUT: J_DUT_L1.11, R5.2
/D32_LOOP_A_OUT: J_DUT_L1.7, SEL_D33.1 (A)
/D33_LOOP_A_IN: J_DUT_L1.8, R3.2
/D34_ADC_IN: C_FB1.1, J_ADC_Header1.1, J_DUT_L1.5, R5.1, TP1.1, U_SPI1.1 (CH0)
/D35_UART1_RX: J_DUT_L1.6, J_UART2.2, SEL_D35.2 (C)
/D36_UART2_RX: JP_UART_LOOP2.2 (B), J_DUT_L1.3
/D39_I2C_FB: J_DUT_L1.4, R7.1
/DS2413_PIOA: J_DS2413.2, R11.2, SEL_D33.3 (B)
/DS2413_PIOB: J_DS2413.1, R12.2, SEL_D26.3 (B)
/GND: C_FB1.2, J2.1, J2.2, J_AUTO1.1, J_DS2413.4, J_DUT_L1.14, J_DUT_R1.1, J_DUT_R1.7, J_External_PWR1.2, J_FLASH1.4, J_Grove_I2C1.1, J_ONEWIRE1.3, J_UART2.3, U_1W1.1 (GND), U_1W2.1 (GND), U_I2C1.3 (A2), U_I2C1.4 (A1), U_I2C1.5 (A0), U_I2C1.9 (VSS), U_SPI1.9 (DGND), U_SPI1.14 (AGND)
/I2C_GP0: J_Port_Header1.1, R7.2, U_I2C1.10 (GP0)
/I2C_GP1: J_Port_Header1.2, R8.2, U_I2C1.11 (GP1)
/I2C_GP2: J_Port_Header1.3, R8.1, U_I2C1.12 (GP2)
/I2C_INT: SEL_D35.1 (A), U_I2C1.8 (INT)
/RESET_EN: J_AUTO1.2, J_DUT_L1.2
unnamed: JP_External_5V1.2 (B), J_External_PWR1.1
unnamed: JP_UART_LOOP2.1 (A), R2.1
unnamed: J_ADC_Header1.2, U_SPI1.2 (CH1)
unnamed: J_ADC_Header1.3, U_SPI1.3 (CH2)
unnamed: J_ADC_Header1.4, U_SPI1.4 (CH3)
unnamed: J_ADC_Header1.5, U_SPI1.5 (CH4)
unnamed: J_ADC_Header1.6, U_SPI1.6 (CH5)
unnamed: J_ADC_Header1.7, U_SPI1.7 (CH6)
unnamed: J_ADC_Header1.8, U_SPI1.8 (CH7)
unnamed: J_Port_Header1.4, U_I2C1.13 (GP3)
unnamed: J_Port_Header1.5, U_I2C1.14 (GP4)
unnamed: J_Port_Header1.6, U_I2C1.15 (GP5)
unnamed: J_Port_Header1.7, U_I2C1.16 (GP6)
unnamed: J_Port_Header1.8, U_I2C1.17 (GP7)
unnamed: R4.1, SEL_D26.2 (C)
unnamed: R3.1, SEL_D33.2 (C)
unnamed: R1.1, SEL_D35.3 (B)

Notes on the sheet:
R_UART1
D12_RESERVED_STRAP
D5_RESERVED_STRAP
ONEWIRE - TWO DS18B20 + External Option
ESP32-DevKit-LiPo
D11_FLASH_CMD
ANALOG_FB
D1_UART0_TX_RESERVED
FIXED GPIO ALLOCATION GPIO LOOP A: D32 -> SEL_D33 -> 470R -> D33 GPIO LOOP B: D25 -> SEL_D26 -> 470R -> D26 PWM/ADC: D27 -> 10k/100nF -> D34 and MCP3008 CH0 I2C: SDA D21, SCL D22, INT via SEL_D35 to D35, FB to D39 SPI: SCK D18, MISO D19, MOSI D23, ADC CS D16, FLASH CS D17 ONEWIRE: D13, DS18B20 bus 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
D15_RESERVED_STRAP
D2_RESERVED_STRAP
ONEWIRE - DS2413 Breakout
ESP32-DEVKITC V4 DUT SOCKET / HEADER MAP
I2C MCP23008 + GROVE I2C Extension
D7_FLASH_SD0
OLIMEX
LoopBack Test Selectors - GPIO LOOPBACKS / DS2413 Breakout
UART2 - External Peer
D9_FLASH_SD2
Two 1x19 sockets represent the DevKitC V4 headers, viewed from the component side with USB at the bottom.
ESP32-WROOM-32E
SPI MCP3008 + OPTIONAL FLASH
RESET / BOOT AUTOMATION PROVISION
D3_UART0_RX_RESERVED
External 5V Supply
UART - Full LOOPBACK
D10_FLASH_SD3
D8_FLASH_SD1
D6_FLASH_CLK
Header labels are the electrical definition;
PWM / ADC FEEDBACK
pin-to-pin comparable to Espressif ESP32-CoreBoard ESP32-DevKit C
USB
I2C_INT is from D35_UART1_RX via SEL_D35

Board: 2 copper layers, 38 parts (0 on the bottom side), 47 nets, no tracks yet.

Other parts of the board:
MH1, MH2, MH3, MH4: MountingHole_1mm; MountingHole_1mm_NPTH

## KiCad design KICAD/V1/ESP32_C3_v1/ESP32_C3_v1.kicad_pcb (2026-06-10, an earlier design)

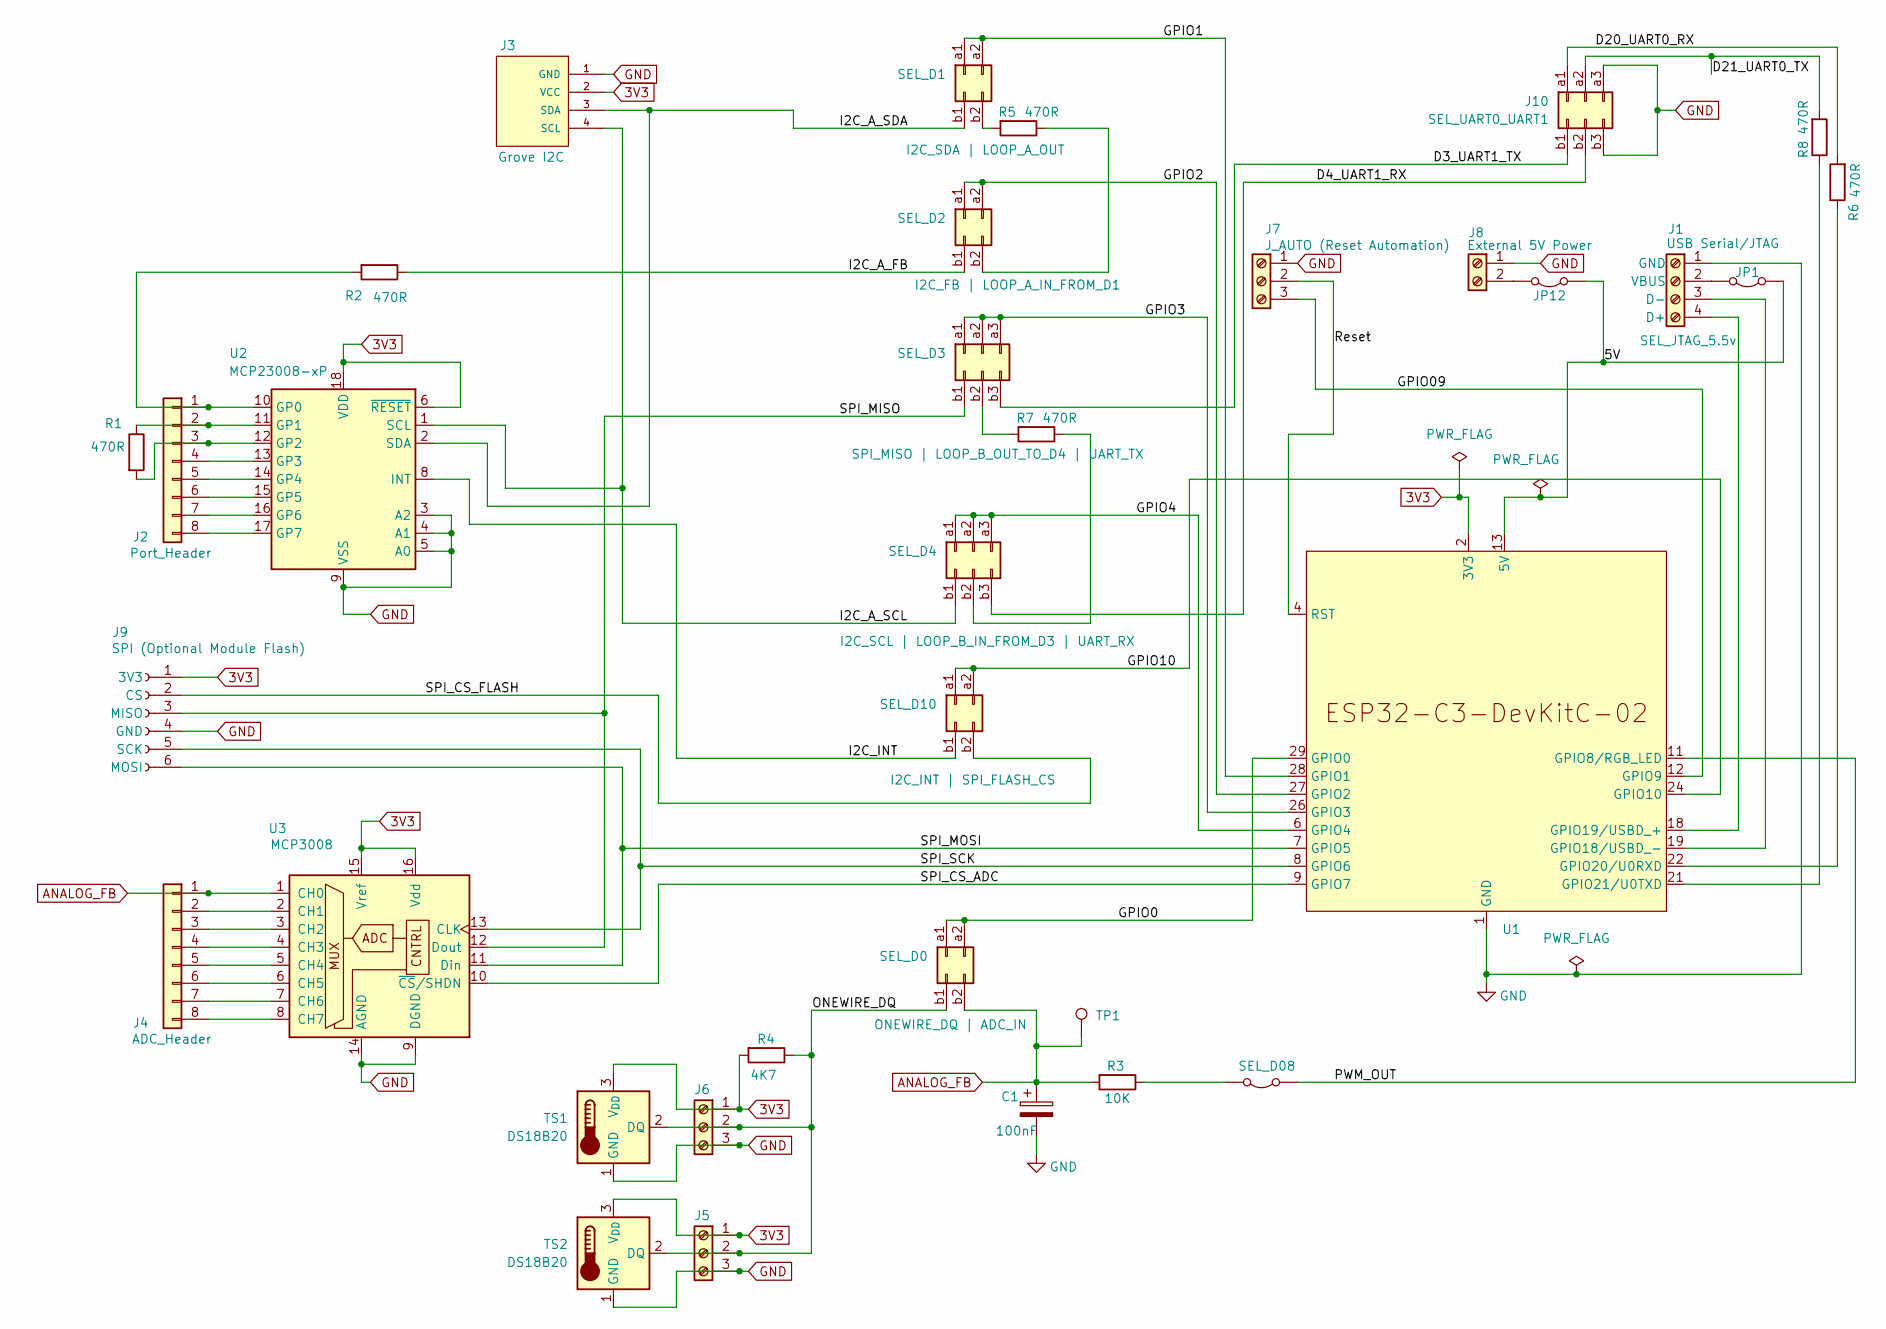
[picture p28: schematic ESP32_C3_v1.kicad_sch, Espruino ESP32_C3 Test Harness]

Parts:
C1: 100nF; C_Disc_D4.7mm_W2.5mm_P5.00mm
J1: USB Serial/JTAG; TerminalBlock_Phoenix_MPT-0,5-4-2.54_1x04_P2.54mm_Horizontal
J2: Port_Header; PinHeader_1x08_P2.54mm_Vertical
J3: Grove I2C; Grove_1x04_P2mm(SEEED_110990030)
J4: ADC_Header; PinHeader_1x08_P2.54mm_Vertical
J5, J6: Screw_Terminal_01x03; TerminalBlock_Phoenix_MPT-0,5-3-2.54_1x03_P2.54mm_Horizontal
J7: J_AUTO (Reset Automation); TerminalBlock_Phoenix_MPT-0,5-3-2.54_1x03_P2.54mm_Horizontal
J8: External 5V Power; TerminalBlock_Phoenix_MPT-0,5-2-2.54_1x02_P2.54mm_Horizontal
J9: SPI (Optional Module Flash); PinSocket_1x06_P2.54mm_Vertical
J10: SEL_UART0_UART1; PinHeader_2x03_RowLetter_P2.54mm_Vertical
JP1: SEL_JTAG_5.5v; PinHeader_1x02_P2.54mm_Vertical
JP12: EXT_5V; PinHeader_1x02_P2.54mm_Vertical
R1, R2, R5, R6, R7, R8: 470R; R_Axial_DIN0411_L9.9mm_D3.6mm_P5.08mm_Vertical
R3: 10K; R_Axial_DIN0411_L9.9mm_D3.6mm_P5.08mm_Vertical
R4: 4K7; R_Axial_DIN0411_L9.9mm_D3.6mm_P5.08mm_Vertical
SEL_D0: ONEWIRE_DQ | ADC_IN; PinHeader_2x02_RowLetter_P2.54mm_Vertical
SEL_D1: I2C_SDA | LOOP_A_OUT; PinHeader_2x02_RowLetter_P2.54mm_Vertical
SEL_D2: I2C_FB | LOOP_A_IN_FROM_D1; PinHeader_2x02_RowLetter_P2.54mm_Vertical
SEL_D3: SPI_MISO | LOOP_B_OUT_TO_D4 | UART_TX; PinHeader_2x03_RowLetter_P2.54mm_Vertical
SEL_D4: I2C_SCL | LOOP_B_IN_FROM_D3 | UART_RX; PinHeader_2x03_RowLetter_P2.54mm_Vertical
SEL_D08: PWM_OUT; PinHeader_1x02_P2.54mm_Vertical
SEL_D10: I2C_INT | SPI_FLASH_CS; PinHeader_2x02_RowLetter_P2.54mm_Vertical
TP1: ANALOG_FB; PinHeader_1x01_P2.54mm_Vertical
TS1, TS2: DS18B20; TO-92_Inline
U1: ESP32-C3-DevKitC-02
U2: MCP23008-xP; DIP-18_W7.62mm
U3: MCP3008; DIP-16_W7.62mm

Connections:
3V3: J3.2 (VCC), J5.1, J6.1, J9.1 (3V3), R4.2, TS1.3 (V_{DD}), TS2.3 (V_{DD}), U1.2 (3V3), U1.3 (3V3), U2.6 (~RESET), U2.18 (VDD), U3.15 (Vref), U3.16 (Vdd)
5V: JP1.1 (A), JP12.1 (A), U1.13 (5V), U1.14 (5V)
/D3_UART1_TX: J10.b1, SEL_D3.b3
/D4_UART1_RX: J10.b2, SEL_D4.b3
/D20_UART0_RX: J10.a1, R6.2
/D21_UART0_TX: J10.a2, R8.2
/GPIO0: SEL_D0.a1, SEL_D0.a2, U1.29 (GPIO0)
/GPIO1: SEL_D1.a1, SEL_D1.a2, U1.28 (GPIO1)
/GPIO2: SEL_D2.a1, SEL_D2.a2, U1.27 (GPIO2)
/GPIO3: SEL_D3.a1, SEL_D3.a2, SEL_D3.a3, U1.26 (GPIO3)
/GPIO4: SEL_D4.a1, SEL_D4.a2, SEL_D4.a3, U1.6 (GPIO4)
/GPIO09: J7.3, U1.12 (GPIO9)
/GPIO10: SEL_D10.a1, SEL_D10.a2, U1.24 (GPIO10)
/I2C_A_FB: R2.1, SEL_D2.b1
/I2C_A_SCL: J3.4 (SCL), SEL_D4.b1, U2.1 (SCL)
/I2C_A_SDA: J3.3 (SDA), SEL_D1.b1, U2.2 (SDA)
/I2C_INT: SEL_D10.b1, U2.8 (INT)
/ONEWIRE_DQ: J5.2, J6.2, R4.1, SEL_D0.b1, TS1.2 (DQ), TS2.2 (DQ)
/PWM_OUT: SEL_D08.1 (A), U1.11 (GPIO8/RGB_LED)
/Reset: J7.2, U1.4 (RST)
/SPI_CS_ADC: U1.9 (GPIO7), U3.10 (~CS/SHDN)
/SPI_CS_FLASH: J9.2 (CS), SEL_D10.b2
/SPI_MISO: J9.3 (MISO), SEL_D3.b1, U3.12 (Dout)
/SPI_MOSI: J9.6 (MOSI), U1.7 (GPIO5), U3.11 (Din)
/SPI_SCK: J9.5 (SCK), U1.8 (GPIO6), U3.13 (CLK)
ANALOG_FB: C1.1, J4.1, R3.2, SEL_D0.b2, TP1.1, U3.1 (CH0)
GND: C1.2, J1.1 (GND), J3.1 (GND), J5.3, J6.3, J7.1, J8.1, J9.4 (GND), J10.a3, J10.b3, TS1.1 (GND), TS2.1 (GND), U1.1 (GND), U1.5 (GND), U1.10 (GND), U1.15 (GND), U1.16 (GND), U1.17 (GND), U1.20 (GND), U1.23 (GND), U1.25 (GND), U1.30 (GND), U2.3 (A2), U2.4 (A1), U2.5 (A0), U2.9 (VSS), U3.9 (DGND), U3.14 (AGND)
unnamed: J1.4 (D+), U1.18 (GPIO19/USBD_+)
unnamed: J1.3 (D-), U1.19 (GPIO18/USBD_-)
unnamed: J1.2 (VBUS), JP1.2 (B)
unnamed: J2.1, R2.2, U2.10 (GP0)
unnamed: J2.2, R1.1, U2.11 (GP1)
unnamed: J2.3, R1.2, U2.12 (GP2)
unnamed: J2.4, U2.13 (GP3)
unnamed: J2.5, U2.14 (GP4)
unnamed: J2.6, U2.15 (GP5)
unnamed: J2.7, U2.16 (GP6)
unnamed: J2.8, U2.17 (GP7)
unnamed: J4.2, U3.2 (CH1)
unnamed: J4.3, U3.3 (CH2)
unnamed: J4.4, U3.4 (CH3)
unnamed: J4.5, U3.5 (CH4)
unnamed: J4.6, U3.6 (CH5)
unnamed: J4.7, U3.7 (CH6)
unnamed: J4.8, U3.8 (CH7)
unnamed: J8.2, JP12.2 (B)
unnamed: R5.2, SEL_D1.b2
unnamed: R5.1, SEL_D2.b2
unnamed: R7.2, SEL_D3.b2
unnamed: R7.1, SEL_D4.b2
unnamed: R3.1, SEL_D08.2 (B)
unnamed: R6.1, U1.22 (GPIO20/U0RXD)
unnamed: R8.1, U1.21 (GPIO21/U0TXD)

Board: 2 copper layers, 36 parts (0 on the bottom side), 53 nets, no tracks yet.

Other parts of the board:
MH1, MH2, MH3, MH3#2: MountingHole_1mm; MountingHole_1mm_NPTH

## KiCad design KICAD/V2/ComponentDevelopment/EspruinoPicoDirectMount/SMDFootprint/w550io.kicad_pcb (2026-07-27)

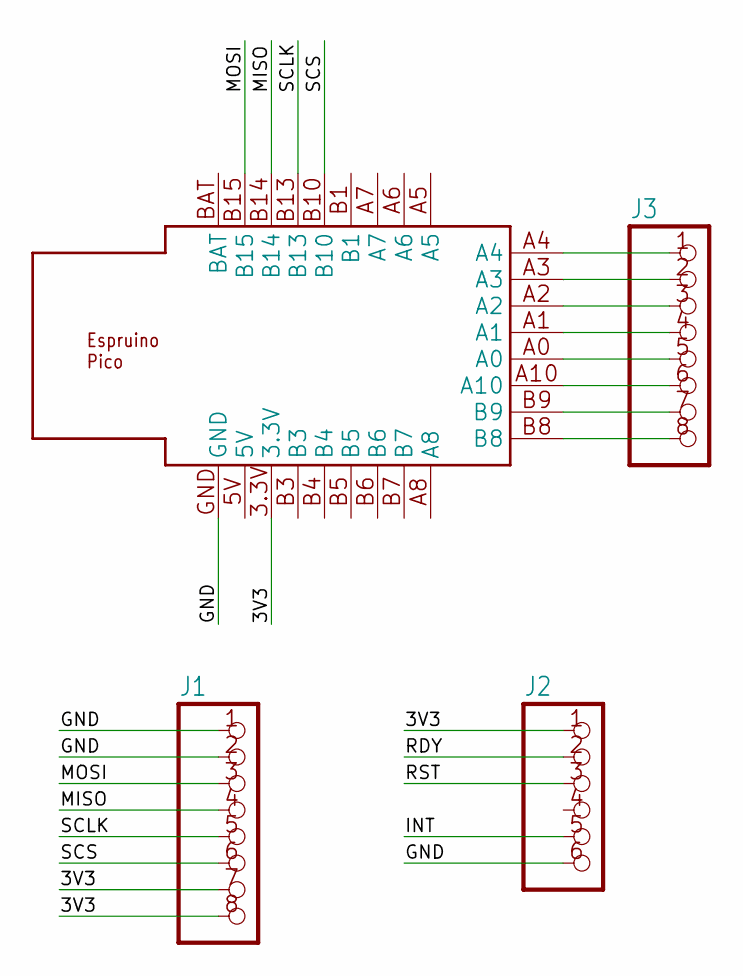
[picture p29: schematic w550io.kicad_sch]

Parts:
J1, J3: PINHD-1X8; 1X08
J2: PINHD-1X6; 1X06
U$1: ESPRUINO_PICO_SMD

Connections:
3V3: J1.7, J1.8, J2.1, U$1.3.3V
GND: J1.1, J1.2, J2.6, U$1.GND
INT: J2.5
MISO: J1.4, U$1.B14
MOSI: J1.3, U$1.B15
unnamed: J3.1, U$1.A4
unnamed: J3.2, U$1.A3
unnamed: J3.3, U$1.A2
unnamed: J3.4, U$1.A1
unnamed: J3.5, U$1.A0
unnamed: J3.6, U$1.A10
unnamed: J3.7, U$1.B9
unnamed: J3.8, U$1.B8
RDY: J2.2
RST: J2.3
SCLK: J1.5, U$1.B13
SCS: J1.6, U$1.B10


Board: 2 copper layers, 28.1 x 26.8 mm, 4 parts (0 on the bottom side), 14 nets.

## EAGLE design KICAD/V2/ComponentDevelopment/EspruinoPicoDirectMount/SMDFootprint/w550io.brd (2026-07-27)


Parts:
J1, J3: PINHD-1X8; 1X08
J2: PINHD-1X6; 1X06
U$1: ESPRUINO_PICO_SMD

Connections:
3V3: J1.7, J1.8, J2.1, U$1.3.3V
GND: J1.1, J1.2, J2.6, U$1.GND
INT: J2.5
MISO: J1.4, U$1.B14
MOSI: J1.3, U$1.B15
unnamed: J3.1, U$1.A4
unnamed: J3.2, U$1.A3
unnamed: J3.3, U$1.A2
unnamed: J3.4, U$1.A1
unnamed: J3.5, U$1.A0
unnamed: J3.6, U$1.A10
unnamed: J3.7, U$1.B9
unnamed: J3.8, U$1.B8
RDY: J2.2
RST: J2.3
SCLK: J1.5, U$1.B13
SCS: J1.6, U$1.B10


Board: 2 copper layers, 28.1 x 26.8 mm, 4 parts (0 on the bottom side), 14 nets.

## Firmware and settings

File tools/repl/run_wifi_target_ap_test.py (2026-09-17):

#!/usr/bin/env python3
"""Run a target-hosted AP test with the other configured board as station peer."""

from __future__ import annotations

import argparse
from datetime import datetime, timezone
import json
from pathlib import Path
import sys

import serial

from run_test import filter_structured_lines, read_available, send_and_capture, sync_repl
from run_wifi_peer_test import (
    clean_repl_line,
    collect_until,
    control_connection,
    count_output_marker,
    final_runtime_cleanup,
    get_position,
    hardware_reboot,
    marker_payload,
    runtime_cleanup,
    runtime_is_inactive,
    upload_role,
    verify_identity,
)
from verify_bench_config import load_config


TARGET_PAIRS = {
    "c3": ("esp32_c3_v1", "esp32_v1"),
    "esp32": ("esp32_v1", "esp32_c3_v1"),
}
CONFIG_PATH = Path("tests/WIFI_BLE/standalone_bench_config.json")
TARGET_SCRIPT = Path("tests/WIFI_BLE/wifi/wifi_target_ap_service.js")
STATION_SCRIPT = Path("tests/WIFI_BLE/wifi/wifi_station_peer_exchange.js")
STATIC_STATION_SCRIPT = Path("tests/WIFI_BLE/wifi/wifi_station_static_ip.js")


def main() -> int:
    parser = argparse.ArgumentParser()
    parser.add_argument(
        "--config",
        type=Path,
        default=CONFIG_PATH,
    )
    parser.add_argument(
        "--target-board",
        choices=tuple(TARGET_PAIRS),
        default="c3",
    )
    parser.add_argument(
        "--target-position",
        help="explicit target position_id from the bench configuration",
    )
    parser.add_argument(
        "--station-position",
        help="explicit station position_id from the bench configuration",
    )
    parser.add_argument(
        "--station-address",
        choices=("dhcp", "static"),
        default="dhcp",
    )
    parser.add_argument(
        "--focus-auth",
        action="store_true",
        help=(
            "isolate WPA2 AP authentication by using the reset-default AP "
            "subnet, connecting directly without a scan, and skipping ping"
        ),
    )
    args = parser.parse_args()

    config = load_config(args.config)
    if bool(args.target_position) != bool(args.station_position):
        parser.error(
            "--target-position and --station-position must be supplied together"
        )
    if args.target_position:
        target_position_id = args.target_position
        supervisor_position_id = args.station_position
    else:
        target_position_id, supervisor_position_id = TARGET_PAIRS[args.target_board]
    target_position = get_position(config, target_position_id)
    supervisor_position = get_position(config, supervisor_position_id)
    target_path, target_baud = control_connection(target_position)
    supervisor_path, supervisor_baud = control_connection(supervisor_position)

    run_id = datetime.now(timezone.utc).strftime("%Y%m%dT%H%M%SZ")
    static_station = args.station_address == "static"
    if args.focus_auth and static_station:
        parser.error("--focus-auth requires --station-address dhcp")
    role_config = {
        "runId": run_id,
        "ssid": "ESPRUINO_TARGET_AP_" + run_id[-7:-1],
        "password": "TargetAP_" + run_id[-7:-1],
        "channel": 6,
        "udpPort": 41235,
        "apIP": (
            "192.168.4.1"
            if static_station or args.focus_auth
            else "192.168.47.1"
        ),
        "netmask": "255.255.255.0",
        "configureAPIP": not (static_station or args.focus_auth),
    }
    if args.focus_auth:
        role_config.update({
            "skipScan": True,
            "skipPing": True,
            "requireStationLeave": False,
            "disableStationBLE": True,
        })
    if static_station:
        role_config.update({
            "stationIP": "192.168.4.77",
            "holdAfterExchangeMs": 2500,
        })

    print(
        "RUNNER test="
        + ("wifi_station_static_ip" if static_station else "wifi_target_ap_service")
    )
    print(f"RUNNER config={args.config}")
    print(f"RUNNER run_id={run_id}")
    print(
        "RUNNER target_board="
        + ("custom_positions" if args.target_position else args.target_board)
    )
    print(f"RUNNER station_address={args.station_address}")
    print(f"RUNNER focus_auth={args.focus_auth}")
    print(f"RUNNER target_position={target_position_id}")
    print(f"RUNNER target_path={target_path}")
    print(f"RUNNER supervisor_position={supervisor_position_id}")
    print(f"RUNNER supervisor_path={supervisor_path}")

    target_output = ""
    station_output = ""
    target_stop_output = ""
    result = 2

    try:
        with serial.Serial(target_path, target_baud, timeout=0.1) as target_repl, \
             serial.Serial(
                 supervisor_path,
                 supervisor_baud,
                 timeout=0.1,
             ) as supervisor_repl:
            sync_repl(target_repl)
            sync_repl(supervisor_repl)
            target_identity = verify_identity(target_repl, target_position)
            supervisor_identity = verify_identity(
                supervisor_repl,
                supervisor_position,
            )
            print(
                "RUNNER target_identity="
                + json.dumps(target_identity, sort_keys=True)
            )
            print(
                "RUNNER supervisor_identity="
                + json.dumps(supervisor_identity, sort_keys=True)
            )

            hardware_reboot(target_repl)
            hardware_reboot(supervisor_repl)
            runtime_cleanup(target_repl, "TARGET_AP_PRE")
            runtime_cleanup(supervisor_repl, "SUPERVISOR_STA_PRE")

            target_output = upload_role(
                target_repl,
                TARGET_SCRIPT,
                role_config,
                ("TARGET_AP_READY=", "TARGET_AP_ERROR="),
                15.0,
            )
            ready = marker_payload(target_output, "TARGET_AP_READY")
            if not ready:
                print("Target AP did not report ready.", file=sys.stderr)
                print("RUNNER target_startup_diagnostic_begin")
                print(target_output.rstrip())
                print("RUNNER target_startup_diagnostic_end")
                result = 2
            else:
                peer_ip = ready["apIP"]["ip"]
                station_config = dict(role_config)
                station_config["peerIP"] = peer_ip
                print(f"RUNNER target_ap_ip={peer_ip}")
                station_output = upload_role(
                    supervisor_repl,
                    STATIC_STATION_SCRIPT if static_station else STATION_SCRIPT,
                    station_config,
                    ("DONE=PASS", "DONE=FAIL"),
                    35.0,
                )
                if not (
                    count_output_marker(station_output, "DONE=PASS")
                    or count_output_marker(station_output, "DONE=FAIL")
                ):
                    print("RUNNER station_diagnostic_begin")
                    print(station_output.rstrip())
                    print("RUNNER station_diagnostic_end")
                # The station reports its own disconnect before the AP-side
                # sta_left event is necessarily delivered. Allow that
                # independent event to arrive before asking the target to
                # stop its AP and summarise the run.
                target_output = collect_until(
                    target_repl,
                    target_output,
                    ('INFO target_ap_event={"name":"sta_left"',),
                    3.0,
                )

                initial_stop = send_and_capture(
                    target_repl,
                    "wifiTargetAPStop();\n",
                    settle=0.2,
                )
                target_stop_output = collect_until(
                    target_repl,
                    initial_stop,
                    ("DONE=PASS", "DONE=FAIL"),
                    8.0,
                )

                station_pass = (
                    count_output_marker(station_output, "DONE=PASS") == 1
                    and count_output_marker(station_output, "DONE=FAIL") == 0
                )
                target_pass = (
                    count_output_marker(target_stop_output, "DONE=PASS") == 1
                    and count_output_marker(target_stop_output, "DONE=FAIL") == 0
                )
                summary = marker_payload(
                    target_output + target_stop_output,
                    "TARGET_AP_SUMMARY",
                )
                received = bool(
                    summary
                    and summary.get("received")
                    and summary["received"][0]["data"].startswith(run_id + "|")
                )
                received_from_static_ip = bool(
                    not static_station
                    or (
                        summary
                        and summary.get("received")
                        and summary["received"][0]["address"]
                        == role_config["stationIP"]
                    )
                )
                joined = bool(
                    summary
                    and any(
                        event.get("name") == "sta_joined"
                        for event in summary.get("events", [])
                    )
                )
                left = bool(
                    summary
                    and any(
                        event.get("name") == "sta_left"
                        for event in summary.get("events", [])
                    )
                )
                left_required = role_config.get("requireStationLeave", True)
                print(
                    "PASS wifi_target_ap_received_challenge"
                    if received
                    else "FAIL wifi_target_ap_received_challenge"
                )
                if static_station:
                    print(
                        "PASS wifi_target_ap_observed_static_station_ip"
                        if received_from_static_ip
                        else "FAIL wifi_target_ap_observed_static_station_ip"
                    )
                print(
                    "PASS wifi_target_ap_observed_station_join"
                    if joined
                    else "FAIL wifi_target_ap_observed_station_join"
                )
                if left:
                    print("PASS wifi_target_ap_observed_station_leave")
                elif left_required:
                    print("FAIL wifi_target_ap_observed_station_leave")
                else:
                    print(
                        "SKIP wifi_target_ap_observed_station_leave "
                        "reason=authentication_isolation"
                    )
                result = 0 if all(
                    (
                        station_pass,
                        target_pass,
                        received,
                        received_from_static_ip,
                        joined,
                        left or not left_required,
                    )
                ) else 1

            target_status, target_ip, target_recovered = final_runtime_cleanup(
                target_repl,
                "TARGET_AP",
            )
            supervisor_status, supervisor_ip, supervisor_recovered = (
                final_runtime_cleanup(supervisor_repl, "SUPERVISOR_STA")
            )
            print(f"RUNNER target_final_status={target_status}")
            print(f"RUNNER supervisor_final_status={supervisor_status}")
            print(f"RUNNER target_cleanup_runtime_reset={target_recovered}")
            print(
                "RUNNER supervisor_cleanup_runtime_reset="
                f"{supervisor_recovered}"
            )
            print(f"RUNNER target_final_ip={target_ip}")
            print(f"RUNNER supervisor_final_ip={supervisor_ip}")
            cleanup_ok = runtime_is_inactive(
                target_status,
                target_ip,
            ) and runtime_is_inactive(supervisor_status, supervisor_ip)
            if cleanup_ok:
                print("PASS wifi_runtime_cleanup")
            else:
                print("FAIL wifi_runtime_cleanup status_not_off")
                result = 1

    except (OSError, ValueError, serial.SerialException) as exc:
        print(f"Runner error: {exc}", file=sys.stderr)
        result = 2

    print("RUNNER station_output_begin")
    normalized_station = "\n".join(
        clean_repl_line(line) for line in station_output.splitlines()
    )
    for line in filter_structured_lines(normalized_station):
        print(line)
    print("RUNNER station_output_end")

    print("RUNNER target_output_begin")
    normalized_target = "\n".join(
        clean_repl_line(line)
        for line in (target_output + target_stop_output).splitlines()
    )
    for line in filter_structured_lines(normalized_target):
        print(line)
    for line in normalized_target.splitlines():
        if line.startswith("TARGET_AP_"):
            print(line)
    print("RUNNER target_output_end")
    print("RUNNER_RESULT=" + ("PASS" if result == 0 else "FAIL"))
    return result


if __name__ == "__main__":
    raise SystemExit(main())

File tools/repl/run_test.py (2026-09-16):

#!/usr/bin/env python3
"""Run one shared REPL functional test with direct or CLI transport."""

from __future__ import annotations

import argparse
import json
import os
from pathlib import Path
import subprocess
import sys
import time

import serial


STRUCTURED_PREFIXES = (
    "TEST=",
    "TARGET=",
    "INFO ",
    "PASS ",
    "FAIL ",
    "SKIP ",
    "METRIC ",
    "DONE=",
)


def read_available(ser: serial.Serial, duration: float) -> str:
    deadline = time.monotonic() + duration
    chunks: list[bytes] = []
    while time.monotonic() < deadline:
        waiting = ser.in_waiting
        if waiting:
            chunks.append(ser.read(waiting))
            deadline = time.monotonic() + 0.15
        else:
            time.sleep(0.02)
    return b"".join(chunks).decode("utf-8", "replace")


def send_and_capture(ser: serial.Serial, text: str, settle: float = 0.2) -> str:
    ser.write(text.encode("utf-8"))
    ser.flush()
    return read_available(ser, settle)


def send_script_paced(ser: serial.Serial, text: str) -> str:
    lines = text.splitlines()
    chunks: list[str] = []

    for idx, line in enumerate(lines):
        ser.write((line + "\n").encode("utf-8"))
        ser.flush()

        # Pace multi-line REPL uploads so larger tests do not overrun the console.
        if idx == len(lines) - 1 or idx % 8 == 7:
            chunks.append(read_available(ser, 0.04))
        else:
            time.sleep(0.005)

    return "".join(chunks)


def read_until_done(ser: serial.Serial, timeout: float) -> str:
    deadline = time.monotonic() + timeout
    chunks: list[bytes] = []
    while time.monotonic() < deadline:
        waiting = ser.in_waiting
        if waiting:
            chunks.append(ser.read(waiting))
            text = b"".join(chunks).decode("utf-8", "replace")
            if "DONE=" in text:
                return text + read_available(ser, 0.25)
        else:
            time.sleep(0.02)
    return b"".join(chunks).decode("utf-8", "replace")


def read_until_prompt(ser: serial.Serial, timeout: float) -> str:
    deadline = time.monotonic() + timeout
    chunks: list[bytes] = []
    while time.monotonic() < deadline:
        waiting = ser.in_waiting
        if waiting:
            chunks.append(ser.read(waiting))
            text = b"".join(chunks).decode("utf-8", "replace")
            if text.rstrip().endswith(">"):
                return text
        else:
            time.sleep(0.02)
    return b"".join(chunks).decode("utf-8", "replace")


def sync_repl(ser: serial.Serial) -> None:
    ser.reset_input_buffer()
    ser.reset_output_buffer()
    send_and_capture(ser, "\x03", settle=0.2)
    send_and_capture(ser, "\x03", settle=0.2)
    send_and_capture(ser, "\n", settle=0.2)
    send_and_capture(ser, "echo(true);\n", settle=0.15)


def query_value(ser: serial.Serial, expr: str, label: str) -> str:
    marker = f"__{label}__"
    output = send_and_capture(
        ser,
        f'print("{marker}="+JSON.stringify({expr}))\n',
        settle=0.45,
    )
    value = None
    for line in output.splitlines():
        line = line.strip()
        if line.startswith(marker + "="):
            value = line[len(marker) + 1 :]
    if value is None:
        return "UNKNOWN"
    try:
        parsed = json.loads(value)
    except json.JSONDecodeError:
        return value
    return str(parsed)


def collect_metadata(port: str, baud: int) -> dict[str, str]:
    with serial.Serial(port, baud, timeout=0.1) as ser:
        sync_repl(ser)
        return {
            "board": query_value(ser, "process.env.BOARD", "BOARD"),
            "version": query_value(ser, "process.version", "VERSION"),
            "git_commit": query_value(ser, "process.env.GIT_COMMIT", "GIT_COMMIT"),
        }


def run_direct(test_path: Path, port: str, baud: int, timeout: float) -> str:
    js_test = test_path.read_text()
    with serial.Serial(port, baud, timeout=0.1) as ser:
        sync_repl(ser)
        reset_output = send_and_capture(ser, "reset();\n", settle=0.2)
        if not reset_output.rstrip().endswith(">"):
            read_until_prompt(ser, min(timeout, 8.0))
        send_and_capture(ser, "echo(true);\n", settle=0.2)
        ser.reset_input_buffer()
        raw_output = send_script_paced(ser, js_test)
        if "DONE=" in raw_output:
            return raw_output + read_available(ser, 0.25)
        return raw_output + read_until_done(ser, timeout)


def validate_cli_path(cli_path: str) -> Path:
    path = Path(cli_path)
    if not path.is_file():
        raise FileNotFoundError(f"Espruino CLI not found: {path}")
    return path


def run_cli(
    test_path: Path,
    port: str,
    baud: int,
    timeout: float,
    cli_path: str,
    board_hint: str | None,
) -> tuple[str, list[str]]:
    cli = validate_cli_path(cli_path)
    cmd = [
        "node",
        str(cli),
        "-q",
        "--no-ble",
        "-b",
        str(baud),
        "-p",
        port,
    ]
    if board_hint:
        cmd.extend(["--board", board_hint])
    cmd.append(str(test_path))
    completed = subprocess.run(
        cmd,
        capture_output=True,
        text=True,
        timeout=timeout,
        check=False,
    )
    return completed.stdout + completed.stderr, cmd


def filter_structured_lines(raw_output: str) -> list[str]:
    lines: list[str] = []
    for line in raw_output.splitlines():
        stripped = line.strip()
        if stripped.startswith(STRUCTURED_PREFIXES):
            lines.append(stripped)
    return lines


def count_prefix(lines: list[str], prefix: str) -> int:
    return sum(1 for line in lines if line.startswith(prefix))


def print_runner_metadata(
    test_path: Path,
    port: str,
    baud: int,
    transport: str,
    metadata: dict[str, str],
    command: list[str] | None,
) -> None:
    print(f"RUNNER test={test_path}")
    print(f"RUNNER port={port}")
    print(f"RUNNER baud={baud}")
    print(f"RUNNER transport={transport}")
    print(f"RUNNER board={metadata.get('board', 'UNKNOWN')}")
    print(f"RUNNER version={metadata.get('version', 'UNKNOWN')}")
    print(f"RUNNER git_commit={metadata.get('git_commit', 'UNKNOWN')}")
    if command:
        print("RUNNER command=" + " ".join(command))
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

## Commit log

2026-05-18 Add ESP32-C3 KiCad harness template
    [ESP32_C3_v1.kicad_pcb, ESP32_C3_v1.kicad_sch]
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2026-05-26 Add cleaned ESP32-C3 harness KiCad project
    [ESP32_C3_v1.kicad_pcb, ESP32_C3_v1.kicad_sch]
2026-05-28 Add ESP32-C3 harness v1 PCB draft
    [ESP32_C3_v1.kicad_pcb, ESP32_C3_v1.kicad_sch]
2026-05-28 Add ESP32-C3 PCB wirewrap silkscreen guide
    [ESP32_C3_v1.kicad_pcb]
2026-06-04 Add ESP32-C3 schematic v1.1 UART crosslink
    [ESP32_C3_v1.kicad_pcb, ESP32_C3_v1.kicad_sch]
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2026-06-04 Refine ESP32-C3 v1.1 PCB layout
    [ESP32_C3_v1.kicad_pcb]
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2026-06-10 Refine ESP32-C3 v1.1 J10 UART schematic and PCB
    [ESP32_C3_v1.kicad_pcb, ESP32_C3_v1.kicad_sch]
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2026-06-17 docs(onewire): record investigation, trace analysis, and fix validation
    [Test_Pico_01.csv, Test_c3_01(One results).csv, Test_c3_01.csv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]
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2026-06-21 Add ESP32 DevKitC V4 harness schematic
    [ESP32_V1.kicad_sch, ESP32_V1.sch]
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2026-06-24 Progress ESP32 V1 KiCad PCB design
    [ESP32_V1.kicad_pcb, ESP32_V1.kicad_sch]
2026-06-24 Align ESP32 V1 PCB guide grid and placement
    [ESP32_V1.kicad_pcb]
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2026-06-25 Restructure harness docs and hardware outputs
    [Test_Pico_01.csv, Test_c3_01(One results).csv, Test_c3_01.csv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]
2026-06-29 Finalize ESP32_V1 v1.0 build documentation
    [ESP32_V1.kicad_pcb, ESP32_V1.kicad_sch]
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2026-07-06 docs: add uart candidate fix patch artifact
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2026-07-08 Add V2 C3 routing study and board resources
    [prototype_order_01.csv]
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2026-07-12 feat(kicad): scaffold V2 harness and add validated target libraries
    [Espruino_Harness_V2.kicad_pcb, Espruino_Harness_V2.kicad_sch, analog_pwm.kicad_sch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]
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2026-07-13 Add V2 routing logic library prototypes
    [Espruino_Harness_V2.kicad_pcb, routing_control.kicad_sch, target_interface.kicad_sch]
2026-07-13 Move local V2 parts records out of tracking
    [prototype_order_01.csv]
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2026-07-13 Add UART issue context to V2 notes
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2026-07-17 Add Espruino Pico castellated footprints
    [Espruino_Harness_V2.kicad_pcb, routing_switches.kicad_sch, target_interface.kicad_sch]
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2026-07-27 Consolidate KiCad projects under KICAD
    [ESP32_C3_v1.kicad_pcb, ESP32_C3_v1.kicad_sch, ESP32_V1.kicad_pcb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]
2026-07-27 Scaffold V2 Rev-A KiCad project
    [Espruino_Harness_RevA.kicad_pcb, Espruino_Harness_RevA.kicad_sch, draft_workbench.kicad_sch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]
2026-07-27 Implement Target Interface and GPIO loopback
    [Espruino_Harness_RevA.kicad_sch, draft_workbench.kicad_sch, prototype_daughter_board.kicad_sch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]
2026-07-27 Add analogue PWM feedback test block
    [Espruino_Harness_RevA.kicad_sch, standard_test_blocks.kicad_sch]
2026-07-27 Implement V2 I2C functional test block
    [Espruino_Harness_RevA.kicad_sch, standard_test_blocks.kicad_sch]
2026-07-28 Implement V2 SPI and 1-Wire test blocks
    [Espruino_Harness_RevA.kicad_sch, standard_test_blocks.kicad_sch]
2026-07-28 Complete V2 standard test block schematic
    [Espruino_Harness_RevA.kicad_sch, standard_test_blocks.kicad_sch]
2026-07-29 Implement V2 routing fabric and control
    [Espruino_Harness_RevA.kicad_sch, draft_workbench.kicad_sch, routing_control.kicad_sch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]
2026-07-29 Implement Rev-A power control service draft
    [draft_workbench.kicad_sch]
2026-07-30 Integrate Rev-A power control and rack supply requirements
    [Espruino_Harness_RevA.kicad_pcb, Espruino_Harness_RevA.kicad_sch, power_control.kicad_sch]
2026-08-04 Establish Rev-A schematic verification framework
    [Espruino_Harness_RevA.kicad_sch, power_control.kicad_sch, standard_test_blocks.kicad_sch]
2026-08-04 Add provisional Rev-A board outline
    [Espruino_Harness_RevA.kicad_pcb]
2026-08-05 Integrate Rev-A rack control endpoint
    [Espruino_Harness_RevA.kicad_sch, power_control.kicad_sch, rack_control.kicad_sch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]
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2026-08-06 Revise low-range power measurement path
    [power_control.kicad_sch]
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2026-08-06 Implement low-range power alert integration
    [Espruino_Harness_RevA.kicad_sch, power_control.kicad_sch, rack_control.kicad_sch]
2026-08-08 Refine Rev-A power control implementation
    [power_control.kicad_sch, rack_control.kicad_sch, standard_test_blocks.kicad_sch]
2026-08-08 Refresh provisional Rev-A PCB footprints
    [Espruino_Harness_RevA.kicad_pcb]
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2026-08-10 feat(v2): scaffold generic target daughter board
    [GenericDaughterBoardV1.kicad_pcb, GenericDaughterBoardV1.kicad_sch]
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2026-08-10 Verify Rev-A power control baseline
    [power_control.kicad_sch]
2026-08-11 Implement RC01 routing baseline metadata
    [Espruino_Harness_RevA.kicad_pcb, power_control.kicad_sch, rack_control.kicad_sch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]
2026-08-12 Verify RC02 routing control baseline
    Add the qualified fixed-I2C isolation and Hardware Clear implementation, exact component metadata, deterministic RC02 connectivity contract, accepted ERC/connectivity evidence, and visual review records. Synchronize the draft PCB and document the PCB-stage workflow while preserving the verified RC01 baseline.
    [Espruino_Harness_RevA.kicad_pcb, Espruino_Harness_RevA.kicad_sch, RC02-routing-controllers-and-fixed-i2c-isolation.yaml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]
2026-08-12 Verify TB01 digital GPIO loopback baseline
    Accept the two independent 470 ohm protected loopback paths using retained V1 functional evidence and Rev-A SMD component/package review.
    Add the project-local isolation-header symbol, exact resistor/header/shunt metadata, focused visual evidence, deterministic TB01 contract, clean hierarchy ERC, synchronized PCB metadata and recorded 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
    [Espruino_Harness_RevA.kicad_pcb, standard_test_blocks.kicad_sch]
2026-08-13 Verify TB02 analogue PWM feedback baseline
    [Espruino_Harness_RevA.kicad_pcb, standard_test_blocks.kicad_sch]
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2026-08-14 Verify TB04 SPI and fixed microSD baseline
    [Espruino_Harness_RevA.kicad_pcb, standard_test_blocks.kicad_sch]
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2026-08-24 Correct Rev-A operating-mode power architecture
    [Espruino_Harness_RevA.kicad_sch, power_control.kicad_sch]
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2026-09-04 Record classic ESP32 IDF5 corrective validation
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2026-09-07 Record corrected ESP32 UART investigation
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2026-09-08 Stabilise S3 cross-UART test setup order
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2026-09-08 Record merged ESP32 UART lifecycle fix
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2026-09-16 tools: wait for REPL prompt after reset
    [run_test.py]
2026-09-16 docs: record ESP32 Wi-Fi scan fix PR submission
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2026-09-17 docs: record ESP32 IP configuration fix validation
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2026-10-14 docs: record UART buffer fix merge
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2026-11-03 test: qualify ESP32 IDF4 basic ping correction
2026-11-04 docs: complete ESP32 ping hardening issue draft
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2026-11-10 docs: finalize ESP32 WiFi hardening issue draft
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
